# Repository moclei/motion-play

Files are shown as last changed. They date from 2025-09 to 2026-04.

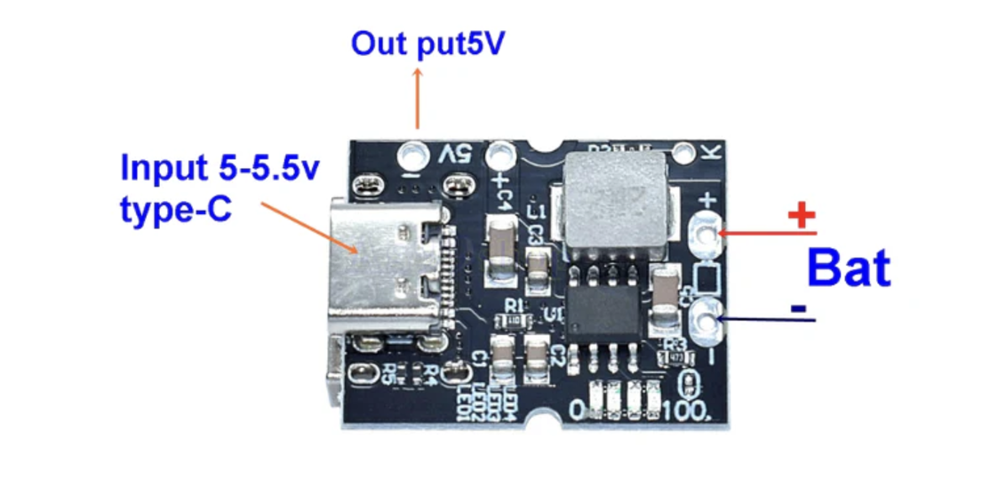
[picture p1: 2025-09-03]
hardware/components/dweii-power/product listing/Screenshot 2024-12-04 at 5.54.18 PM.png

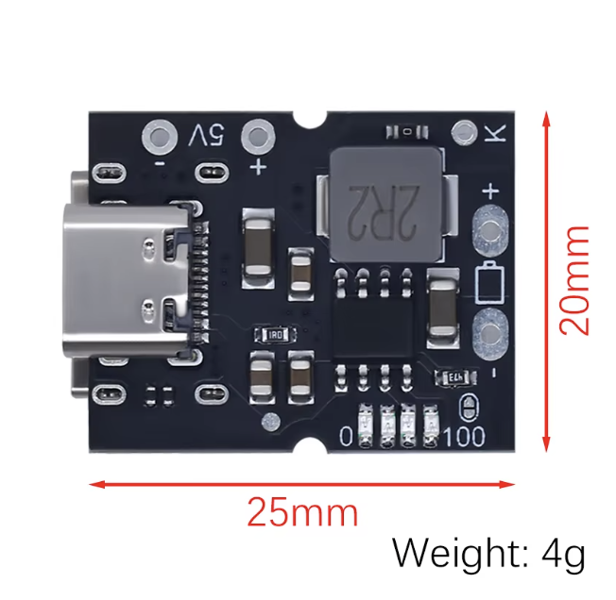
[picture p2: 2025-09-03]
hardware/components/dweii-power/product listing/Screenshot 2024-12-04 at 5.53.51 PM.png

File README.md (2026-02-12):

# Motion Play

ESP32-based sensor system for detecting and tracking fast-moving objects through a detection plane. Designed for games and sports performance training.

## Project Status

**Phase 4 - Integration & Polish** (77% complete)

- ✅ Custom PCBs with dual-MUX sensor architecture
- ✅ 1000 Hz data collection with PSRAM buffering
- ✅ AWS IoT Core + Lambda + DynamoDB backend
- ✅ React web interface with visualization and device control
- 🔄 Testing, optimization, documentation

## Repository Structure

```
motion-play/
├── .context/           # AI context documentation (start here)
│   ├── PROJECT.md      # Comprehensive project context
│   ├── manifest.yaml   # Structured metadata
│   └── IDEAS.md        # Feature backlog
├── firmware/           # ESP32-S3 firmware (PlatformIO/Arduino)
├── frontend/           # React web interface
├── lambda/             # AWS Lambda functions
├── infrastructure/     # AWS setup and deployment
├── hardware/           # KiCad PCB designs
│   ├── pcb-main/       # Main controller board
│   ├── sensor-rigid/   # Sensor rigid base (mux, connectors)
│   └── sensor-flex/    # Sensor flex strip (VCNL4040s)
└── docs/references/    # Hardware datasheets
```

## Quick Start

```bash
# Firmware
cd firmware && pio run -t upload

# Frontend
cd frontend/motion-play-ui && npm install && npm run dev
```

## Documentation

**For AI assistants and detailed context**: See [`.context/PROJECT.md`](.context/PROJECT.md)

**Hardware reference materials**: See [`docs/references/`](docs/references/)

## Hardware

- **MCU**: LilyGO T-Display-S3 (ESP32-S3)
- **Sensors**: 6× VCNL4040 proximity sensors (3 assemblies × 2 sensors)
- **Sensor Design**: Rigid+Flex hybrid PCBs (sensors on flex strip angle outward for better direction detection)
- **Architecture**: TCA9548A → PCA9546A → VCNL4040 (dual I2C multiplexing)

## License

[TBD]

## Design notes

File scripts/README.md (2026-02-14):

# Scripts

Utility scripts for the Motion Play project. Run all scripts from the project root.

## Device Provisioning

### `provision-device.sh`

Automates the full setup process for a new ESP32-S3 device. Walks you through each step interactively.

```bash
./scripts/provision-device.sh
```

**What it does:**
1. Creates an AWS IoT Thing for the device
2. Generates and activates X.509 certificates
3. Attaches the certificate to the Thing and the `MotionPlayDevicePolicy`
4. Downloads the Amazon Root CA (if not already present)
5. Fetches the IoT endpoint and generates `config.json` with your WiFi credentials
6. Backs up all secrets to AWS Secrets Manager
7. Uploads the filesystem (LittleFS) and firmware to the device

**Prerequisites:**
- AWS CLI configured (`aws configure`)
- PlatformIO CLI installed (`pio`)
- Device connected via USB for the flash step (DWEII power disconnected)

### `sync-secrets.sh`

Syncs device config and certificates to/from AWS Secrets Manager. Useful for backing up a new device's secrets or restoring them on a different machine.

```bash
./scripts/sync-secrets.sh up [device-number]     # Upload to Secrets Manager
./scripts/sync-secrets.sh down [device-number]    # Download from Secrets Manager
```

**Examples:**
```bash
./scripts/sync-secrets.sh up           # Back up device-001 (default)
./scripts/sync-secrets.sh up 002       # Back up device-002
./scripts/sync-secrets.sh down 002     # Restore device-002 secrets locally
```

Secrets are stored under the prefix `motion-play/device-{number}/` in AWS Secrets Manager.

## Monitoring & Debugging

### `monitor-mqtt.sh` / `monitor-mqtt.py`

Monitor MQTT messages to/from a device in real time. Useful for verifying device connectivity and inspecting data payloads.

### `add-iot-error-logging.sh`

Adds error logging rules to AWS IoT Core for debugging connection or message delivery issues.

## Data Analysis

### `analyze_session.py` / `analyze-session-data.sh`

Tools for analyzing sensor data from completed collection sessions. Used during development to inspect data quality and sensor behavior.

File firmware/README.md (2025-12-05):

# Motion Play Firmware

ESP32-S3 firmware for high-frequency sensor data collection and cloud transmission.

## Architecture Overview

### Dual-Core Design
- **Core 0:** Sensor data collection (1000 Hz) and buffering
- **Core 1:** MQTT communication, display updates, command processing

### Component Structure
```
firmware/src/
├── main.cpp                          # Application entry point, setup, loop
└── components/
    ├── data/                         # Data collection & transmission
    │   ├── DataTransmitter.h/cpp    # Batch MQTT transmission
    │   └── DataBuffer.h/cpp         # PSRAM-based ring buffer
    ├── sensor/                       # Sensor management
    │   ├── SensorManager.h/cpp      # Multi-sensor coordination
    │   ├── SensorConfiguration.h    # Sensor config structure
    │   └── VCNL4040Sensor.h/cpp     # VCNL4040 driver
    ├── mqtt/                         # Cloud communication
    │   └── MQTTManager.h/cpp        # AWS IoT Core client
    └── display/                      # Visual feedback
        └── DisplayManager.h/cpp     # T-Display-S3 interface
```

## Core Components

### `main.cpp`
**Purpose:** Application initialization and coordination

**Key Responsibilities:**
- WiFi connection setup
- MQTT client initialization
- Sensor manager setup
- Command routing (start_collection, stop_collection, set_mode, configure_sensors)
- Display updates

**Global State:**
- `SensorConfiguration currentConfig` - Current sensor settings
- `DataTransmitter* dataTransmitter` - Transmission handler
- `MQTTManager* mqttManager` - MQTT client
- `SensorManager* sensorManager` - Sensor coordinator

### `SensorManager` (sensor/)
**Purpose:** Coordinate multiple VCNL4040 sensors via dual-MUX architecture

**Architecture:**
```
T-Display-S3
    └── TCA9548A (Primary MUX, 0x70)
        ├── Channel 0 → PCA9546A (Secondary MUX, 0x71)
        │   ├── Channel 0 → VCNL4040 (0x60) - PCB 0, Side 1
        │   ├── Channel 1 → VCNL4040 (0x60) - PCB 1, Side 1
        │   └── Channel 2 → VCNL4040 (0x60) - PCB 2, Side 1
        └── Channel 1 → PCA9546A (Secondary MUX, 0x72)
            ├── Channel 0 → VCNL4040 (0x60) - PCB 0, Side 2
            ├── Channel 1 → VCNL4040 (0x60) - PCB 1, Side 2
            └── Channel 2 → VCNL4040 (0x60) - PCB 2, Side 2
```

**Key Methods:**
- `begin()` - Initialize all sensors
- `readAllSensors()` - Read all active sensors
- `calibrateSensors()` - Run calibration routine

**Data Structure:**
```cpp
struct SensorMetadata {
    uint8_t position;      // Sensor index (0-5)
    uint8_t pcb_id;        // PCB number (0-2)
    uint8_t side;          // Side (1 or 2)
    String name;           // Human-readable name
    bool active;           // Sensor active/present
};
```

### `DataTransmitter` (data/)
**Purpose:** Batch sensor readings and transmit via MQTT

**Key Features:**
- Batch transmission (100 readings per message)
- Session metadata included in first batch
- Sensor configuration tracking
- 16KB MQTT buffer support

**Key Methods:**
- `transmitSession()` - Send complete session with metadata
- `transmitBatch()` - Send batch of readings

**JSON Structure:**
```json
{
  "device_id": "motionplay-device-001",
  "session_id": "device-001_12345",
  "start_timestamp": "2025-11-14T10:30:00Z",
  "mode": "debug",
  "sample_rate": 1000,
  "active_sensors": [...],
  "vcnl4040_config": {
    "sample_rate_hz": 1000,
    "led_current": "200mA",
    "integration_time": "1T",
    "high_resolution": true
  },
  "readings": [...]
}
```

### `DataBuffer` (data/)
**Purpose:** PSRAM-based circular buffer for sensor readings

**Capacity:** 30,000+ samples
**Location:** PSRAM (external RAM on ESP32-S3)

**Key Methods:**
- `addReading()` - Add sensor reading
- `getReadings()` - Retrieve batch of readings
- `clear()` - Reset buffer

### `MQTTManager` (mqtt/)
**Purpose:** AWS IoT Core communication with TLS

**Key Features:**
- Certificate-based authentication
- LittleFS certificate storage
- Automatic reconnection
- Command subscription

**Topics:**
- Publish: `motionplay/data/{device_id}`
- Subscribe: `motionplay/commands/{device_id}`

**Key Methods:**
- `connect()` - Connect to AWS IoT Core
- `publish()` - Send message
- `setCallback()` - Register command handler
- `loop()` - Maintain connection

### `SensorConfiguration` (sensor/)
**Purpose:** Track sensor settings for ML training

**Structure:**
```cpp
struct SensorConfiguration {
    uint16_t sample_rate_hz;      // 100-1000 Hz
    String led_current;           // "50mA", "100mA", "200mA"
    String integration_time;      // "1T", "2T", "4T", "8T"
    bool high_resolution;         // 12-bit vs 16-bit
};
```

**Why This Exists:**
Different sensor configurations produce different data characteristics. For ML training, you need to know which settings were used for each dataset to properly normalize and group training data.

### `DisplayManager` (display/)
**Purpose:** T-Display-S3 TFT screen management

**Key Features:**
- Status display (WiFi, MQTT, collection state)
- Real-time sensor readings
- Mode indication (Debug/Play/Idle)

**Key Methods:**
- `showStatus()` - Display connection status
- `showSensorData()` - Display live readings
- `showMessage()` - Show temporary message

## Data Collection Flow

### Session Lifecycle

1. **Idle State**
   - Device connected to AWS IoT Core
   - Listening for commands
   - Display shows "Ready"

2. **Start Collection**
   - Command received: `start_collection`
   - Generate session ID: `{device_id}_{timestamp}`
   - Clear data buffer
   - Start high-frequency sampling (Core 0)
   - Display shows "Collecting..."

3. **Active Collection**
   - Core 0: Read all sensors at 1000 Hz
   - Store readings in PSRAM buffer
   - Core 1: Update display periodically
   - Continue until buffer full or stop command

4. **Stop Collection**
   - Command received: `stop_collection`
   - Stop sampling
   - Transmit all buffered data in batches
   - Include session metadata + sensor config
   - Clear buffer
   - Return to idle

### Command Processing

Commands are received via MQTT on `motionplay/commands/{device_id}`:

**`start_collection`**
```json
{
  "command": "start_collection"
}
```

**`stop_collection`**
```json
{
  "command": "stop_collection"
}
```

**`set_mode`**
```json
{
  "command": "set_mode",
  "mode": "debug"  // or "play", "idle"
}
```

**`configure_sensors`**
```json
{
  "command": "configure_sensors",
  "sensor_config": {
    "sample_rate_hz": 1000,
    "led_current": "200mA",
    "integration_time": "1T",
    "high_resolution": true
  }
}
```

## Configuration

### PlatformIO Configuration (`platformio.ini`)

```ini
[env:lilygo-t-display-s3]
platform = espressif32
board = lilygo-t-display-s3
framework = arduino

monitor_speed = 115200
upload_speed = 921600

board_build.arduino.memory_type = qio_opi
board_build.partitions = default_16MB.csv

lib_deps = 
    knolleary/PubSubClient @ ^2.8
    bblanchon/ArduinoJson @ ^6.21.3
    adafruit/Adafruit VCNL4040 @ ^2.0.3
```

### WiFi & Certificates

Certificates stored in LittleFS:
- `/ca.crt` - AWS IoT Root CA
- `/cert.crt` - Device certificate
- `/private.key` - Private key

**Note:** Certificates must be obtained from AWS IoT Core and uploaded to the device.

## Development Workflow

### Build & Upload
```bash
cd firmware/
pio run -t upload
```

### Monitor Serial Output
```bash
pio device monitor
```

### Clean Build
```bash
pio run -t clean
pio run -t upload
```

## Memory Management

### PSRAM Usage
- **Data Buffer:** ~30,000 samples in PSRAM
- **Benefit:** Offloads large buffers from internal SRAM
- **Access:** Slightly slower than SRAM but sufficient for buffering

### Task Priorities
- **Sensor Task (Core 0):** Priority 1 (highest)
- **MQTT Task (Core 1):** Priority 0 (normal)

## Adding New Components

### 1. Create Component Files
```bash
firmware/src/components/your_component/
├── YourComponent.h
└── YourComponent.cpp
```

### 2. Add to Build
PlatformIO automatically includes all `.cpp` files in `src/`.

### 3. Include in main.cpp
```cpp
#include "components/your_component/YourComponent.h"
```

### 4. Initialize in setup()
```cpp
void setup() {
    // ... existing setup ...
    yourComponent = new YourComponent();
    yourComponent->begin();
}
```

## Debugging Tips

### Check Serial Output
Most components log to Serial at 115200 baud. Look for:
- `[WiFi]` - Connection status
- `[MQTT]` - Cloud communication
- `[Sensor]` - Sensor readings
- `[Data]` - Transmission status

### Common Issues

**Sensors Not Found:**
- Check I2C connections
- Verify MUX addresses (0x70, 0x71, 0x72)
- Run I2C scanner

**MQTT Not Connecting:**
- Verify WiFi connection
- Check certificates in LittleFS
- Confirm AWS IoT endpoint in code

**Data Not Transmitting:**
- Check MQTT buffer size (16KB)
- Verify topic permissions in AWS IoT policy
- Monitor AWS IoT Core test client

**High Frequency Sampling Issues:**
- Ensure sensors on Core 0
- Check task priorities
- Verify PSRAM availability

## Key Constants

```cpp
#define SAMPLE_RATE_HZ 1000
#define BUFFER_SIZE 30000
#define MQTT_BUFFER_SIZE 16384
#define BATCH_SIZE 100
```

## Device Modes

- **Idle:** Minimal operation, ready for commands
- **Debug:** Full logging, 1000 Hz collection, detailed display
- **Play:** Optimized for game use, minimal logging, LED feedback

## Further Reading

- **Project Context:** [.context/PROJECT.md](../.context/PROJECT.md)
- **AWS Setup:** `infrastructure/aws-setup-guide.md`
- **Sensor Datasheets:** `docs/references/vcnl4040/`

---

*Last Updated: December 5, 2025*

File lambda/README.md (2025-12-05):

# Motion Play Lambda Functions

AWS Lambda functions for the Motion Play data collection system.

> **Project Context:** See [.context/PROJECT.md](../.context/PROJECT.md) for architecture overview.

## Functions Overview

1. **processData** - Process sensor data from ESP32 and store in DynamoDB
2. **processStatus** - Update device status information
3. **sendCommand** - Send commands to devices via IoT Core
4. **getSessions** - Retrieve list of sessions
5. **getSessionData** - Get detailed session data
6. **updateSession** - Update session metadata (labels, notes)
7. **deleteSession** - Delete sessions and associated data
8. **getDeviceConfig** - Get device sensor configuration
9. **updateDeviceConfig** - Update device sensor configuration

## Deployment

Each function should be deployed as a separate Lambda function with appropriate IAM permissions.

### Required IAM Permissions

- DynamoDB: PutItem, GetItem, Query, UpdateItem, DeleteItem
- IoT Core: Publish (for sendCommand function)
- CloudWatch Logs: CreateLogGroup, CreateLogStream, PutLogEvents

### Environment Variables

Each function may require:
- `SESSIONS_TABLE` - MotionPlaySessions table name
- `SENSOR_DATA_TABLE` - MotionPlaySensorData table name
- `DEVICES_TABLE` - MotionPlayDevices table name
- `REGION` - AWS region (e.g., us-west-2)

## Data Storage Architecture

### Composite Timestamp Key ⚠️ CRITICAL

**Problem Solved**: Multiple sensors reading simultaneously create duplicate DynamoDB keys.

**Solution**: Composite numeric key encoding both timestamp and sensor position.

#### Key Schema (MotionPlaySensorData table)
- **Partition Key**: `session_id` (String)
- **Sort Key**: `timestamp_offset` (Number) - **COMPOSITE KEY**

#### Composite Key Formula
```javascript
timestamp_offset = (timestamp_ms * 10) + position
```

**Example**:
- Sensor P1S1 (position=0) at 100ms: `1000` (100 × 10 + 0)
- Sensor P1S2 (position=1) at 100ms: `1001` (100 × 10 + 1)
- Sensor P2S1 (position=2) at 100ms: `1002` (100 × 10 + 2)

#### Decoding
```javascript
timestamp_ms = Math.floor(timestamp_offset / 10)
position = timestamp_offset % 10
```

**Why This Works**:
- All sensors can share the same timestamp (synchronized readings)
- Each reading still has a unique DynamoDB key
- Sort order is preserved (lower timestamps appear first)
- Position values 0-5 fit in the ones digit

**Where Implemented**:
- Encoding: `lambda/processData/index.js` (lines ~107-117)
- Decoding: `lambda/getSessionData/index.js` (lines ~63-78)

**⚠️ IMPORTANT**: If you ever need to query by timestamp, use the `timestamp_ms` attribute, NOT `timestamp_offset`!

## Development

Each function directory contains:
- `index.ts` or `index.js` - Main handler
- `package.json` - Dependencies
- `README.md` - Function-specific documentation

## Deployment Options

1. **Manual** - Zip and upload via AWS Console
2. **AWS CLI** - Use `aws lambda update-function-code`
3. **AWS CDK** - Infrastructure as code (recommended for Phase 2)
4. **Serverless Framework** - Alternative deployment tool

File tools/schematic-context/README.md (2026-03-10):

# Schematic Context Tools

Python scripts that extract circuit data from KiCad schematics and produce AI-optimized `circuit-context.json` files. These replace the old JSON netlist + YAML annotation system.

## Prerequisites

- **Python 3.7+** (tested on 3.7.3)
- **KiCad 9** — `kicad-cli` must be available (macOS default: `/Applications/KiCad/KiCad.app/Contents/MacOS/kicad-cli`)
- **Dependencies:** `pip install -r requirements.txt` (kiutils >= 1.4.8)

Override the kicad-cli path with the `KICAD_CLI` environment variable if needed.

## Scripts

### extract.py

Main extraction pipeline. Combines `kicad-cli` netlist export (for connectivity) with `kiutils` schematic parsing (for component properties and hierarchy) to produce `circuit-context.json`.

```bash
# Basic extraction — outputs circuit-context.json next to the schematic
python tools/schematic-context/extract.py hardware/pcb-main/kicad/motion-play-main.kicad_sch

# Custom output path
python tools/schematic-context/extract.py hardware/pcb-main/kicad/motion-play-main.kicad_sch \
  --output path/to/circuit-context.json

# Re-extract with annotation merge — carries forward net/block annotations from a previous run
python tools/schematic-context/extract.py hardware/pcb-main/kicad/motion-play-main.kicad_sch \
  --previous hardware/pcb-main/kicad/circuit-context.json
```

The `--previous` flag is important: component annotations live in the `.kicad_sch` files (as `ai_` properties) and come through automatically, but net annotations and block definitions only exist in `circuit-context.json`. The merge preserves them across re-extractions.

### annotate.py

Writes `ai_`-prefixed custom properties to component symbols in `.kicad_sch` files via kiutils. Properties are hidden in the schematic editor and survive schematic edits.

```bash
# Annotate a single component
python tools/schematic-context/annotate.py hardware/pcb-main/kicad/motion-play-main.kicad_sch \
  U1 function="3.3V LDO regulator" block=power role=voltage_regulator

# Annotate multiple components with the same properties (use -- separator)
python tools/schematic-context/annotate.py hardware/pcb-main/kicad/motion-play-main.kicad_sch \
  R28 R29 -- role=pull_up block=i2c_mux

# Clear all ai_ properties from a component
python tools/schematic-context/annotate.py hardware/pcb-main/kicad/motion-play-main.kicad_sch \
  C1 --clear
```

Valid annotation fields: `function`, `block`, `role`, `critical_specs`.

The script resolves which `.kicad_sch` file a component lives on (root or child sheet) automatically.

### show.py

Displays annotation coverage across all components. Useful during interactive annotation sessions to track progress.

```bash
# Show all components with annotation status
python tools/schematic-context/show.py hardware/pcb-main/kicad/motion-play-main.kicad_sch

# Show only unannotated components
python tools/schematic-context/show.py hardware/pcb-main/kicad/motion-play-main.kicad_sch --unannotated

# Filter to a specific sheet
python tools/schematic-context/show.py hardware/pcb-main/kicad/motion-play-main.kicad_sch \
  --sheet led_controller
```

## Typical Workflow

1. **Edit schematic** in KiCad
2. **Extract** — run `extract.py` with `--previous` to produce an updated `circuit-context.json`
3. **Check coverage** — run `show.py --unannotated` to find new components needing annotation
4. **Annotate** — interactive session: AI proposes annotations, human confirms, write via `annotate.py`
5. **Re-extract** — run `extract.py --previous` again to merge everything into the final context file

## Output Location

| PCB | Context File |
|-----|---|
| Main PCB | `hardware/pcb-main/kicad/circuit-context.json` |
| Sensor Rigid | `hardware/sensor-rigid/circuit-context.json` |
| Sensor Flex | `hardware/sensor-flex/circuit-context.json` |

## Design Details

See `docs/initiatives/schematic-context/PLAN.md` for the full design rationale, context file schema, and annotation storage decisions.

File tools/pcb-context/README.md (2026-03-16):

# PCB Context Tools

Scripts for extracting structured data from KiCad PCB files and automating component placement. Both tools use [kiutils](https://pypi.org/project/kiutils/) (v1.4.8+) to parse and write `.kicad_pcb` files.

## Workflow

```
User positions anchor components in KiCad, saves
    ↓
python extract.py <pcb> --pads       → pcb-layout-context.json (enriched)
    ↓
python place_power.py <pcb> --dry-run → review proposed positions
    ↓
python place_power.py <pcb>           → writes positions to .kicad_pcb
    ↓
User opens KiCad, reviews placement, runs DRC
```

KiCad must be closed before running `place_power.py` without `--dry-run` — both tools write to the same `.kicad_pcb` file.

## extract.py

Parses a `.kicad_pcb` file and produces `pcb-layout-context.json` — a structured snapshot of board outline, component positions, bounding boxes, and optionally per-component pad data. Used by `place_power.py` and by AI-assisted layout sessions.

```
python extract.py <file.kicad_pcb> [options]
```

| Flag | Description |
|---|---|
| `--pads` | Include per-component pad data: pad number, global x/y, size, net name, shape. Required before running `place_power.py`. |
| `--output PATH`, `-o` | Output path for the JSON file. Default: `pcb-layout-context.json` alongside the PCB. |
| `--schematic-context PATH` | Path to `circuit-context.json` for cross-referencing unplaced components. Auto-detected if present alongside the PCB. |

### Examples

```bash
# Basic extraction
python extract.py hardware/pcb-main/kicad/motion-play-main.kicad_pcb

# With pad data (needed for placement)
python extract.py hardware/pcb-main/kicad/motion-play-main.kicad_pcb --pads

# Custom output path
python extract.py hardware/pcb-main/kicad/motion-play-main.kicad_pcb --pads -o /tmp/context.json
```

### Output format

The JSON includes `board_outline`, `placed_components` (with optional `pads` array), `unplaced_components`, and a `summary` with component counts and board utilization percentage.

## place_power.py

Reads the enriched `pcb-layout-context.json` and `tools/schematic-gen/spec.json`, then computes collision-free positions for power section support components relative to manually-placed anchor ICs (U5, U6, J7, J8, L1, R44).

```
python place_power.py <file.kicad_pcb> [options]
```

| Flag | Description |
|---|---|
| `--dry-run` | Output proposed positions as JSON to stdout without modifying the PCB. Always run this first to review. |
| `--context PATH` | Path to `pcb-layout-context.json`. Default: alongside the PCB file. |
| `--spec PATH` | Path to `spec.json`. Default: `tools/schematic-gen/spec.json`. |

### Examples

```bash
# Preview placement without writing
python place_power.py hardware/pcb-main/kicad/motion-play-main.kicad_pcb --dry-run

# Apply placement (KiCad must be closed)
python place_power.py hardware/pcb-main/kicad/motion-play-main.kicad_pcb

# Custom input paths
python place_power.py hardware/pcb-main/kicad/motion-play-main.kicad_pcb \
    --context /tmp/context.json \
    --spec path/to/spec.json \
    --dry-run
```

### How placement works

**Anchors** (U5, U6, J7, J8, L1, R44) keep their manually-set positions. Everything else in the power section is repositioned.

Components are placed in four tiers based on electrical proximity requirements:

| Tier | Constraint | Purpose | Example components |
|---|---|---|---|
| 1 — Critical | <3mm from pins | Switching loop minimization | L2, C23, C32 |
| 2 — Important | <5–6mm from pins | Bulk decoupling | C20, C21, C34–C36, C25, C26 |
| 3 — Moderate | <10mm from pins | Signal integrity | R39, R40, R43, C24, C27, F2, U7 |
| 4 — Flexible | <15–20mm | Large passives, bias networks | C29, C22, R33, TH1, TP1–TP4 |

For each component, the script finds the target anchor pad via net name matching against `spec.json`, then searches in expanding rings for the closest collision-free position, preferring the direction away from the anchor IC center.

**U6 rotation fix:** U6 is rotated from -90° to +90° so its SW pins face the board interior, making room for L2.

**Test points** (TP1–TP4) are placed along the bottom board edge for probe access.

If a component can't be placed within its tier distance, the constraint is relaxed (doubled distance, full board width). Failures and relaxations are reported as warnings.

### Output

- **`--dry-run`**: prints a JSON report to stdout with `placements` (new and old positions), `warnings`, and `summary`.
- **Normal mode**: writes positions to the `.kicad_pcb` file and saves a `placement-report.json` alongside the PCB.

## Dependencies

- Python 3.7+
- kiutils ≥ 1.4.8 (`pip install kiutils`)

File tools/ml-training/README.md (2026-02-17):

# ML Training Pipeline

Training pipeline for the Motion Play ML-based direction detection model.

## Overview

This pipeline downloads labeled sensor data from the Motion Play cloud, preprocesses it into training tensors, trains a small 1D CNN, quantizes it to int8, and exports it as a C header file for embedding in the ESP32-S3 firmware.

## Setup

```bash
cd tools/ml-training
python -m venv venv
source venv/bin/activate
pip install -r requirements.txt
```

## Pipeline Steps

1. **Download data** — Fetch labeled `live_debug` sessions from the REST API
2. **Preprocess** — Extract fixed-size `(300, 6)` matrices (300ms window, 6 proximity channels), normalize, assign labels
3. **Train** — Train a 1D CNN model using TensorFlow/Keras
4. **Evaluate** — Accuracy, confusion matrix, per-scenario analysis
5. **Export** — Quantize to int8 TFLite, convert to C header for firmware

## Model Architecture

```
Input: (300, 6) — 300 timesteps at 1kHz, 6 sensor channels (proximity only)
  → Conv1D(16, kernel_size=5, ReLU)
  → MaxPool1D(2)
  → Conv1D(32, kernel_size=3, ReLU)
  → MaxPool1D(2)
  → Flatten
  → Dense(32, ReLU)
  → Dense(3, Softmax)   # A_TO_B, B_TO_A, NO_TRANSIT
```

## Output Classes

| Class | Label | Description |
|---|---|---|
| 0 | A_TO_B | Object passed from back to front of hoop |
| 1 | B_TO_A | Object passed from front to back of hoop |
| 2 | NO_TRANSIT | No valid transit (noise, partial, ambient) |

## Data Format

Each training sample is derived from a Live Debug session:
- **Input**: 300×6 matrix of uint16 proximity values, normalized to [0, 1]
- **Label**: Direction from session metadata + user labeling
- **Source**: DynamoDB via REST API (`GET /sessions/{id}/data`)

## Exporting for Firmware

After training and quantization:

```bash
# Convert .tflite to C header
xxd -i model.tflite > model_data.h
```

The header file goes into `firmware/src/components/detection/` and is included by `MLDetector`.

## See Also

- Initiative docs: `docs/initiatives/ml-direction-detection/`
- Current heuristic: `firmware/src/components/detection/DirectionDetector.cpp`
- Sensor data format: `SensorReading` struct in `firmware/src/components/sensor/SensorManager.h`

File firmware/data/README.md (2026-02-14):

# Firmware Data Directory

This directory contains configuration files and certificates for the ESP32-S3 device. These files are uploaded to the device's LittleFS filesystem partition and read by the firmware at runtime.

## Files

### Certificates (Not Committed)

AWS IoT Core certificates for TLS authentication:
- `certs/device-cert.pem` - Device certificate
- `certs/private-key.pem` - Private key
- `certs/root-ca.pem` - Amazon Root CA

### Configuration

- `config.json` - Device configuration (not committed, copy from `config.json.example`)
- `config.json.example` - Template showing the expected structure

## Setup — New Device

**Recommended:** Use the provisioning script, which handles everything automatically (AWS IoT Thing creation, certificates, config, filesystem upload, and firmware upload):

```bash
./scripts/provision-device.sh
```

See [`scripts/README.md`](../../scripts/README.md) for details.

### Manual Setup

If you prefer to set things up manually:

1. Copy `config.json.example` to `config.json`
2. Update `config.json` with your WiFi credentials, device ID, and AWS IoT endpoint
3. Place your AWS IoT certificates in the `certs/` directory
4. Upload filesystem to ESP32 using PlatformIO:
   ```bash
   pio run --target uploadfs
   ```
5. Upload firmware:
   ```bash
   pio run --target upload
   ```

## Restoring Secrets

If you need to restore a device's config and certs from AWS Secrets Manager:

```bash
./scripts/sync-secrets.sh down 002   # Downloads device-002's secrets
```

## Security Note

**NEVER commit certificate files or actual config.json to git!**
These files contain sensitive credentials and are automatically ignored by `.gitignore`.

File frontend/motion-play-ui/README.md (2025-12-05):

# Motion Play Web Interface

React-based web interface for device control, data visualization, and session management.

## Tech Stack

- **Framework:** React 18 with TypeScript
- **Build Tool:** Vite
- **Styling:** Tailwind CSS v3
- **Charts:** Recharts
- **HTTP Client:** Axios
- **Icons:** Lucide React
- **Date Formatting:** date-fns

## Architecture Overview

```
frontend/motion-play-ui/src/
├── App.tsx                    # Main application & routing
├── index.css                  # Global styles (Tailwind)
├── main.tsx                   # Application entry point
├── components/                # React components
│   ├── SessionList.tsx       # Session list with filtering
│   ├── SessionChart.tsx      # Data visualization
│   ├── DeviceControl.tsx     # Start/stop collection
│   ├── LabelEditor.tsx       # Session labels & notes
│   ├── ExportButton.tsx      # JSON/CSV export
│   ├── ModeSelector.tsx      # Device mode selection
│   ├── SensorConfig.tsx      # Live sensor configuration
│   └── SessionConfig.tsx     # Historical config display
└── services/
    └── api.ts                 # API client (Axios)
```

## Components

### Core Components (Phase 3)

#### `App.tsx`
**Purpose:** Main application container and state coordinator

**State Management:**
- `selectedSession` - Currently viewed session
- `sessionData` - Full session data with readings
- `sessionListRef` - Reference to SessionList for refresh

**Key Functions:**
- `handleSessionSelect()` - Load and display session details
- `handleDeleteSession()` - Delete session with confirmation
- `handleCollectionStopped()` - Refresh list after collection

**Layout:**
- Left column: Device control + session list
- Right column: Session detail + chart

#### `SessionList.tsx`
**Purpose:** Display and filter recorded sessions

**Props:**
```typescript
interface SessionListProps {
    onSessionSelect: (session: Session) => void;
    selectedId?: string;
}
```

**Features:**
- Real-time session loading
- Search by session ID, labels, notes
- Filter by mode (all/idle/debug/play)
- Visual selection highlighting
- Results counter
- Exposed `refresh()` method via `useImperativeHandle`

**Display:**
- Session ID (monospace)
- Duration, sample count, sample rate
- Labels (if present)
- Mode badge

#### `SessionChart.tsx`
**Purpose:** Interactive time-series visualization with statistics and data analysis tools

**Props:**
```typescript
interface SessionChartProps {
    readings: Reading[];
}
```

**Features:**
- Multi-sensor line chart with color coding:
  - Side 1: Dark green, Side 2: Dark blue
  - Line styles vary by PCB (solid/dashed/dotted)
- PCB and side filtering (show specific sensors or all)
- **Time window zooming** with interactive brush component
- **Data processing filters** for analysis and ML prep:
  - Moving average smoothing (3-21 sample window)
  - Baseline removal (subtract minimum value)
  - Peak threshold filter (0-20 range)
- Real-time statistics:
  - Average proximity (overall + per side + per sensor)
  - Max/Min proximity
  - Sample counts per side and per sensor
- Handles empty/invalid data gracefully

**Chart Details:**
- X-axis: Time offset (ms)
- Y-axis: Proximity value
- Tooltip: Shows exact values on hover
- Brush timeline: Drag handles to zoom into specific time windows
- `connectNulls` for smooth lines

**Data Analysis:**
The processing filters are designed for:
- Noise reduction (smoothing)
- Normalizing sensors with different baselines (baseline removal)
- Isolating detection events (threshold filter)
- Preparing data for ML model training

#### `DeviceControl.tsx`
**Purpose:** Start/stop data collection

**Props:**
```typescript
interface DeviceControlProps {
    onCollectionStopped?: () => void;
}
```

**Features:**
- Start/stop buttons with loading states
- Visual feedback on success/error
- Calls parent callback when collection stops

**Commands Sent:**
- `start_collection`
- `stop_collection`

### Enhancement Components (Phase 3-B)

#### `LabelEditor.tsx`
**Purpose:** Add labels and notes to sessions

**Props:**
```typescript
interface LabelEditorProps {
    session: Session;
    onUpdate: (session: Session) => void;
}
```

**Features:**
- Add/remove labels (tags)
- Predefined label suggestions:
  - `successful-shot`, `miss`, `practice`
  - `baseline`, `experiment`, `calibration`
  - `fast`, `slow`, `normal`
- Free-text notes field
- Save to backend (PUT request)

**UI Elements:**
- Tag chips with X to remove
- Input field for new labels
- Suggestion buttons
- Notes textarea

#### `ExportButton.tsx`
**Purpose:** Export session data for ML training

**Props:**
```typescript
interface ExportButtonProps {
    sessionData: SessionData;
}
```

**Features:**
- Export as JSON (complete data structure)
- Export as CSV (tabular format)
- Proper filename generation: `session_{id}.json`
- Download triggers automatically

**CSV Format:**
```csv
timestamp_offset,sensor_pcb,sensor_side,proximity,ambient,timestamp
0,0,1,1234,567,2025-11-14T10:30:00Z
1,0,2,1235,568,2025-11-14T10:30:00Z
...
```

#### `ModeSelector.tsx`
**Purpose:** Switch device operating mode

**Props:**
```typescript
interface ModeSelectorProps {
    deviceId?: string;
}
```

**Modes:**
- **Idle:** Minimal operation, ready for commands
- **Debug:** Full logging, detailed display
- **Play:** Game mode, LED feedback

**Features:**
- Visual indication of active mode
- Sends `set_mode` command
- Success/error feedback

#### `SensorConfig.tsx`
**Purpose:** Configure live sensor settings (control panel)

**Props:**
```typescript
interface SensorConfigProps {
    deviceId?: string;
}
```

**Configurable Settings:**
- Sample rate: 100/250/500/1000 Hz
- LED current: 50/75/100/150/200 mA
- Integration time: 1T/2T/4T/8T
- High resolution: true/false (12-bit vs 16-bit)

**Features:**
- Dropdown selectors
- Apply button sends `configure_sensors` command
- Visual feedback on success

**Important:** This configures FUTURE collections. Past sessions retain their original config.

#### `SessionConfig.tsx`
**Purpose:** Display historical sensor configuration (read-only)

**Props:**
```typescript
interface SessionConfigProps {
    sessionData: SessionData;
}
```

**Displays:**
- Sample rate used for this session
- LED current setting
- Integration time
- High resolution mode
- Number of active sensors

**Why This Matters:** For ML training, you need to know what settings were used for each dataset.

## Services

### `api.ts`
**Purpose:** Centralized API client for backend communication

**Base Configuration:**
```typescript
const API_ENDPOINT = import.meta.env.VITE_API_ENDPOINT;
const DEVICE_ID = import.meta.env.VITE_DEVICE_ID;
```

**Methods:**

#### Session Management
```typescript
getSessions(): Promise<Session[]>
getSessionData(sessionId: string): Promise<SessionData>
deleteSession(sessionId: string): Promise<any>
updateSession(sessionId: string, updates: UpdateData): Promise<void>
```

#### Device Control
```typescript
sendCommand(command: string, params?: Record<string, any>): Promise<void>
```

**Commands:**
- `start_collection`
- `stop_collection`
- `set_mode` (with `mode` param)
- `configure_sensors` (with `sensor_config` param)

#### API Endpoints Used:
- `GET /sessions` - List all sessions
- `GET /sessions/{session_id}` - Get session details
- `DELETE /sessions/{session_id}` - Delete session
- `PUT /sessions/{session_id}` - Update labels/notes
- `POST /device/command` - Send device command

## TypeScript Interfaces

### Core Types

```typescript
interface Session {
    session_id: string;
    device_id: string;
    start_timestamp: string;
    duration_ms: number;
    sample_count: number;
    sample_rate: number;
    mode: string;
    labels?: string[];
    notes?: string;
    created_at: number;
    active_sensors?: ActiveSensor[];
    vcnl4040_config?: VCNL4040Config;
}

interface SessionData {
    session: Session;
    readings: Reading[];
}

interface Reading {
    timestamp_offset: number;
    sensor_pcb: number;
    sensor_side: number;
    proximity: number;
    ambient: number;
    timestamp: string;
}

interface VCNL4040Config {
    sample_rate_hz: number;
    led_current: string;
    integration_time: string;
    high_resolution: boolean;
}

interface ActiveSensor {
    pos: number;
    pcb: number;
    side: number;
    name: string;
    active: boolean;
}
```

## Environment Variables

Create `.env` in the project root:

```env
VITE_API_ENDPOINT=https://your-api-gateway-id.execute-api.us-west-2.amazonaws.com/prod
VITE_AWS_REGION=us-west-2
VITE_DEVICE_ID=motionplay-device-001
```

**Access in code:**
```typescript
import.meta.env.VITE_API_ENDPOINT
```

## Development Workflow

### Install Dependencies
```bash
cd frontend/motion-play-ui/
npm install
```

### Start Dev Server
```bash
npm run dev
```
Opens at `http://localhost:5173`

### Build for Production
```bash
npm run build
```
Output in `dist/` directory

### Preview Production Build
```bash
npm run preview
```

### Lint Code
```bash
npm run lint
```

## Project Configuration

### `vite.config.ts`
```typescript
export default defineConfig({
  plugins: [react()],
  server: {
    port: 5173,
    open: true
  }
})
```

### `tailwind.config.js`
```javascript
export default {
  content: [
    "./index.html",
    "./src/**/*.{js,ts,jsx,tsx}",
  ],
  theme: {
    extend: {},
  },
  plugins: [],
}
```

### `tsconfig.json`
Standard React + TypeScript configuration with strict mode enabled.

## Styling Approach

### Tailwind CSS Classes
Most styling uses Tailwind utility classes:

```tsx
<div className="bg-white rounded-lg shadow p-4 mb-4">
  <h3 className="text-lg font-semibold text-gray-800 mb-2">
    Title
  </h3>
</div>
```

### Common Patterns

**Cards:**
```tsx
className="bg-white rounded-lg shadow p-4"
```

**Buttons:**
```tsx
className="bg-blue-500 text-white px-4 py-2 rounded hover:bg-blue-600"
```

**Input Fields:**
```tsx
className="border border-gray-300 rounded px-3 py-2 w-full"
```

**Badges:**
```tsx
className="inline-block bg-blue-100 text-blue-800 text-xs px-2 py-1 rounded"
```

## State Management

### Local State (useState)
Used for component-specific state:
- Form inputs
- Loading states
- Local UI toggles

### Refs (useRef)
Used for:
- Accessing child methods (`sessionListRef.current.refresh()`)
- Avoiding re-renders for non-visual state

### Props
Used for:
- Parent-child communication
- Callback functions
- Data passing

**No global state library** (Redux, Zustand, etc.) - Not needed for current complexity.

## Adding New Components

### 1. Create Component File
```bash
touch src/components/MyComponent.tsx
```

### 2. Component Template
```tsx
import { useState } from 'react';

interface MyComponentProps {
    data: string;
    onAction: () => void;
}

export const MyComponent: React.FC<MyComponentProps> = ({ data, onAction }) => {
    const [localState, setLocalState] = useState('');

    return (
        <div className="bg-white rounded-lg shadow p-4">
            <h3 className="text-lg font-semibold mb-2">My Component</h3>
            {/* Component content */}
        </div>
    );
};
```

### 3. Import in App.tsx
```tsx
import { MyComponent } from './components/MyComponent';
```

### 4. Use in App.tsx
```tsx
<MyComponent data="example" onAction={handleAction} />
```

## Common Tasks

### Refresh Session List After Action
```typescript
// In App.tsx
const sessionListRef = useRef<{ refresh: () => void }>(null);

// Call after action
sessionListRef.current?.refresh();
```

### Add New API Endpoint
```typescript
// In api.ts
async myNewEndpoint(): Promise<ResponseType> {
    const response = await axios.get(`${this.baseUrl}/my-endpoint`);
    return response.data;
}
```

### Handle Loading States
```typescript
const [loading, setLoading] = useState(false);

const handleAction = async () => {
    setLoading(true);
    try {
        await api.someAction();
        alert('Success!');
    } catch (error) {
        console.error('Error:', error);
        alert('Failed!');
    } finally {
        setLoading(false);
    }
};
```

## Debugging Tips

### Check Browser Console
- Network tab: See API requests/responses
- Console tab: See `console.log()` output and errors
- React DevTools: Inspect component state

### Common Issues

**API Requests Failing:**
- Check `.env` file exists and has correct API endpoint
- Verify CORS configuration on API Gateway
- Check browser network tab for exact error

**Environment Variables Not Loading:**
- Restart dev server after changing `.env`
- Variables must start with `VITE_`
- Access via `import.meta.env.VITE_*`

**Tailwind Classes Not Working:**
- Check `tailwind.config.js` includes your file
- Verify `@tailwind` directives in `index.css`
- Restart dev server

**TypeScript Errors:**
- Check interface definitions match API responses
- Use `any` temporarily, then narrow down types
- Run `npm run build` to see all type errors

## Performance Considerations

### Chart Rendering
- `SessionChart` filters data before rendering
- Recharts handles 1000+ points efficiently
- Use `connectNulls` for smoother lines

### Session List
- Only loads metadata initially
- Full readings loaded on-demand
- Filtering happens client-side (fast)

### API Calls
- No caching (always fresh data)
- Consider adding React Query for optimization later

## Testing

Currently no automated tests. For manual testing:

1. **Session List:**
   - Load sessions
   - Filter by mode
   - Search by ID/labels/notes
   - Select session

2. **Session Detail:**
   - View chart
   - Toggle side filtering
   - Check statistics
   - Add labels/notes

3. **Device Control:**
   - Start collection
   - Stop collection
   - Verify list refreshes

4. **Export:**
   - Download JSON
   - Download CSV
   - Verify file contents

5. **Configuration:**
   - Change sensor settings
   - Change mode
   - Verify commands sent

## Further Reading

- **Project Context:** [.context/PROJECT.md](../../../.context/PROJECT.md)
- **Vite Docs:** https://vitejs.dev/
- **React Docs:** https://react.dev/
- **Tailwind Docs:** https://tailwindcss.com/

---

*Last Updated: December 5, 2025*

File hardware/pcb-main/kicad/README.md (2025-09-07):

# motion-play-main
Main PCB for Motion Play project

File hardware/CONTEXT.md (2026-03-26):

# Hardware Context

Custom PCB designs for the Motion Play sensor system. Three PCB types make up the electronics: one main board and a two-part sensor assembly (rigid base + flex strip) replicated three times around the hoop.

## Physical Architecture

- **Hoop diameter:** 500mm (transparent polypropylene tubing, 19mm diameter)
- **Orientation:** Vertical plane (opening faces horizontally)
- **Main enclosure:** 85mm × 45mm × 15mm at 6 o'clock position

### Sensor Placement

3 sensor assemblies positioned at:
- Position 1 (M1): 6 o'clock (bottom, co-located with main enclosure)
- Position 2 (M2): 9 o'clock (left side)
- Position 3 (M3): 3 o'clock (right side)

Each assembly has dual sensors with ~2° angular offset:
- **Side A** (-2°): Faces the back of the hoop
- **Side B** (+2°): Faces the front of the hoop

The angle increases the detection time window for direction discrimination. Object passing through triggers sequential sensor activation — direction is determined by A→B vs B→A trigger sequence. 120° spacing provides full coverage.

See [`docs/detection-algorithm.md`](../docs/detection-algorithm.md) for the full algorithm design and transit scenario catalog.

## Custom PCBs

### 1. Main PCB (`hardware/pcb-main/`)

Houses the system controller and power management:

- **T-Display-S3** (ESP32-S3 development board) — The MCU with a built-in LCD screen. Long-term goal is to incorporate a bare ESP32-S3 directly into the main PCB.
- **TCA9548A** I2C multiplexer — Organizes I2C communication with sensor PCBs. 3 channels used. Speed is critical for high-frequency sensing.
- **AP2112K-3.3** voltage regulator — Provides 3.3V to sensors.
- **DWEII USB-C power module** — Development power module providing 5V @ ~2.4A with battery charging. Will be replaced with a custom solution eventually.
- **SN74AHCT125** logic level shifter — Between MCU (3.3V) and WS2818B LED strip (5V). 72 LEDs, 1.2m strip.
- **3× JST-SH 4-pin connectors** (SM04B-SRSS-TB) — One per sensor PCB (Pin 1 = 3.3V, Pin 2 = GND, Pin 3 = SDA, Pin 4 = SCL)

### 2. Sensor Rigid Base (`hardware/sensor-rigid/`)

The mounting board with local I2C multiplexing:

| Ref | Component | Function |
|-----|---|---|
| U1 | PCA9546A | Local I2C mux (controls two sensors) |
| J1 | JST-SH 4-pin (SM04B-SRSS-TB) | Connector to main board (3.3V, GND, SDA, SCL) |
| FPC1 | C132510 ZIF | Connection to flex sensor strip |
| R1, R2 | 4.7kΩ | Upstream I2C pull-ups |
| R6-R9 | 4.7kΩ | Per-sensor downstream I2C pull-ups |
| R3 | 10kΩ | Reset pull-up (keeps PCA9546A active) |
| R12 | 10kΩ | A2 address pull-up (permanently high) |
| R13, R14 | 10kΩ | A0, A1 address pull-downs (default low) |
| SW1 | EP-02KS DIP switch | I2C address select (A0, A1) |
| D1, R4 | LED + 1kΩ | Power indicator |
| C1, C2 | 2.2µF, 0.1µF | Power bypass caps |
| TP1-TP4 | Test pads | 3.3V, GND, SDA_UP, SCL_UP |

- **PCB Type**: Standard rigid FR4, 4 layers, 1.6mm thickness, HASL or ENIG finish.
- **I2C Addressing (PCA9546A):** A2 permanently high. Address set via SW1 DIP switch:
  - Board 1 (both OFF): 0x74
  - Board 2 (SW2 ON): 0x75
  - Board 3 (SW1 ON): 0x76

### 3. Flex Sensor Strip (`hardware/sensor-flex/`)

Polyimide flex PCB that bends to angle sensors outward:

- **PCB Type**: 2-layer polyimide flex, ~0.11mm core, ENIG finish
- ~25mm × 8mm, sensors 10mm apart center-to-center
- ~5mm center bend zone (unstiffened, flexible)
- **Stiffeners** (all on bottom side):
  - FPC tail: Polyimide (PI), 0.25mm (total ~0.3mm for ZIF connector grip)
  - IC1 area: Stainless Steel (SS), 0.2mm
  - IC2 area: Stainless Steel (SS), 0.2mm

| Ref | Component | Function |
|-----|---|---|
| IC1, IC2 | VCNL4040M3OE | Proximity sensors |
| C4, C8 | 2.2µF | LED anode capacitors |
| C6, C7 | 0.1µF | VDD bypass capacitors |
| R10, R11 | 22Ω | VDD series filter resistors (one per sensor) |
| FPC1 | FPC_Tail_10P | FPC tail connector (mates with ZIF on rigid base) |

Connected to rigid base via ZIF FPC connector (C132510, 1.0mm pitch, top contact, slide lock, 0.3mm FPC):

**ZIF Connector Pinout:**

| Pin | Signal | Purpose |
|-----|---|---|
| 1 | 3.3V | Power |
| 2 | GND | Ground |
| 3 | SCL1 | I2C clock sensor 1 |
| 4 | SDA1 | I2C data sensor 1 |
| 5 | GND | Ground (shield between sensor groups) |
| 6 | SCL2 | I2C clock sensor 2 |
| 7 | SDA2 | I2C data sensor 2 |
| 8 | GND | Ground |
| 9 | GND | Mechanical mounting |
| 10 | GND | Mechanical mounting |

**Why the split design?** The flex PCB allows sensors to be angled ~2° away from each other, increasing the time window between sequential sensor triggers and improving direction discrimination.

### Flex PCB Design Notes
1. Center ~5mm bend zone is unstiffened
2. 0.25mm traces in bend zone (wider than normal), curved paths, no vias
3. Traces perpendicular to bend axis for durability
4. Components only on stiffened areas

See `docs/initiatives/flex-sensor-pcb/DESIGN_PLAN.md` for detailed design rationale.
See `hardware/sensor-flex/FLEX_PCB_SETUP.md` for flex PCB manufacturing notes.

## Component Nicknames

| Component | Part Number | Function | Shorthand |
|---|---|---|---|
| Main Controller | LilyGO T-Display-S3 | ESP32-S3 with built-in display | `tdisplay` |
| I2C Multiplexer | TCA9548A | 8-channel I2C switch (main board) | `tca` |
| Local I2C Multiplexer | PCA9546A | I2C switch (sensor board) | `pca` |
| Sensors | VCNL4040 | Proximity & ambient light sensing | `sensors` |
| Voltage Regulator | AP2112K-3.3 | 3.3V regulator | `apk` |
| Power Module | DWEII USB-C | USB-C power input | `dweii` or `power module` |

## Schematic Context System

Raw KiCad schematic files are difficult for AI assistants to interpret. The **schematic context system** extracts circuit data and combines it with human-confirmed semantic annotations into a single `circuit-context.json` file per PCB project.

**Always use `circuit-context.json`** instead of `.kicad_sch` files when reasoning about hardware designs.

### File Locations

| PCB | Context File | Status |
|-----|---|---|
| Main PCB | `hardware/pcb-main/kicad/circuit-context.json` | Complete — 37 components, 26 nets, 5 functional blocks |
| Sensor Rigid Base | `hardware/sensor-rigid/circuit-context.json` | Complete — 22 components, 13 nets, 5 functional blocks |
| Sensor Flex Strip | `hardware/sensor-flex/circuit-context.json` | Complete — 9 components, 10 nets, 4 functional blocks |
| Power Supply | `hardware/pcb-power-supply/kicad/circuit-context.json` | Complete — 50 components, 29 nets, 4 functional blocks |

### What's in circuit-context.json

- **Components** — every part with value, footprint, LCSC number, pin-level connectivity, and AI annotations (function, block membership, role, critical specs)
- **Nets** — all named nets with type (power/signal/clock), protocol, direction, and description
- **Functional blocks** — logical groupings (power, mcu, i2c_mux, sensor_connectors, led_controller) with descriptions and design intent notes
- **Sheet interfaces** — hierarchical pin mappings showing signal flow between parent and child schematics
- **Source metadata** — schema version, source hash, and extraction timestamp for staleness detection

### Tooling

Scripts live in `tools/schematic-context/` (see that folder's README for full usage):

| Script | Purpose |
|---|---|
| `extract.py` | Runs kicad-cli + kiutils to produce `circuit-context.json` from a root `.kicad_sch` |
| `annotate.py` | Writes `ai_` properties to components in `.kicad_sch` files via kiutils |
| `show.py` | Displays annotation coverage — useful during interactive annotation sessions |

### Workflow

1. Edit schematic in KiCad
2. Run `extract.py` on the root `.kicad_sch` — uses `--previous` to merge forward existing net/block annotations
3. If new components appeared, run an interactive annotation session with AI (propose annotations → confirm → write via `annotate.py`)
4. Re-extract to produce the final context file with all annotations merged

Component annotations (`ai_function`, `ai_block`, `ai_role`, `ai_critical_specs`) are stored as custom properties in the `.kicad_sch` file — they survive schematic edits. Net and block annotations are stored in `circuit-context.json` and carried forward via the `--previous` merge.

### Deprecated: Old Netlist + Annotation System

The previous system used `convert_netlist_to_json.py` to produce JSON netlists with separate YAML annotation files. This has been fully replaced by the schematic context system. Old files in `hardware/pcb-main/kicad/netlists/` and `hardware/pcb-sensor/kicad/netlist/` are retained for reference but should not be used.

## VCNL4040 Sensor Capabilities

- **Proximity Detection**: IR LED emission and reflection measurement
- **Ambient Light Sensing**: Human eye response approximation
- **Programmable**: Integration time, interrupt thresholds, LED current control
- **Communication**: I2C up to 400kHz
- **Reference docs**: `docs/references/vcnl4040/`

## I2C Multiplexing Architecture

```
T-Display-S3
    └── TCA9548A (Primary MUX, 0x70)
        ├── Channel 0 → PCA9546A (0x74) → 2× VCNL4040 (Module 1)
        ├── Channel 1 → PCA9546A (0x75) → 2× VCNL4040 (Module 2)
        └── Channel 2 → PCA9546A (0x76) → 2× VCNL4040 (Module 3)
```

All VCNL4040 sensors share address 0x60. The TCA→PCA dual-MUX chain provides individual addressability.

---

*Last Updated: March 25, 2026*

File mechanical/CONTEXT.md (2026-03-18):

# Mechanical — Motion Play

Context for the `mechanical/` directory: 3D-printed parts designed with build123d and viewed in OCP CAD Viewer.

## What This Is

This folder contains parametric 3D models for the Motion Play project and related experiments. The primary focus is sensor enclosures for the hoop assembly, but the same tooling supports any 3D-printable part — replacement components, fixtures, test jigs, etc.

All parts are designed in Python using build123d (parametric B-rep CAD on OpenCASCADE) and viewed in OCP CAD Viewer.

## Structure

```
mechanical/
├── CONTEXT.md                 # This file
├── FDM_DESIGN_RULES.md        # 3D printing design standards and tolerances
├── specs/                     # Problem definition and constraints
│   └── assembly-v0.1.yaml    # Hoop assembly dimensions and requirements
├── models/                    # CAD models, one folder per project
│   ├── enclosures/            # Sensor enclosure designs (option-a, interior-channel, etc.)
│   │   └── option-X/          # Each option explores a different solution
│   │       ├── *.py           # build123d scripts (self-documenting)
│   │       ├── *.step         # Exported STEP files
│   │       └── *.stl          # Exported STL files (for slicing/printing)
│   └── door-latch-spring/     # Replacement spring for a mortise latch (experiment)
├── view.sh                    # Interactive launcher: model selector + OCP viewer auto-start
└── .venv/                     # Python venv (build123d, ocp_vscode)
```

## Design Process

1. **Spec first**: For project-related parts, `specs/assembly-v0.1.yaml` defines the physical constraints. For standalone p1s, the script docstring describes the problem and measurements.
2. **Explore options**: `docs/explorations/sensor-enclosure.md` evaluates design approaches before committing to CAD work (for enclosures specifically).
3. **Parametric CAD**: Each project folder contains build123d Python scripts. Dimensions trace back to the spec file or to `FDM_DESIGN_RULES.md`. Scripts are self-documenting — the docstring at the top of each `.py` file explains what the part is, how it prints, and its coordinate system.
4. **Visual evaluation**: Run `./mechanical/view.sh` to select a project and model, then view in OCP CAD Viewer. The launcher auto-starts the viewer if it isn't running.
5. **Print and test**: Export STL, slice in PrusaSlicer, print on Prusa Core One. PLA for test-fitting, PETG for final parts.

## Coordinate Conventions

Enclosure scripts use consistent axis definitions (see individual script docstrings for project-specific conventions):

- **X** = across bar width (25.25mm)
- **Y** = along hoop circumference
- **Z** = radial — meaning depends on which face:
  - Outer shell: +Z = away from bar (outward from hoop)
  - Inner shell: +Z = into hoop interior (away from bar)
- **Origin** = center of the part's bar-contact surface

The outer and inner shells have opposite Z directions because they sit on opposite faces of the bar. Assembly scripts handle the 180° rotation around X.

## Tooling

- **CAD**: build123d — Python parametric B-rep modeling on OpenCASCADE
- **Viewer**: OCP CAD Viewer standalone server, port 3939
- **Launcher**: `./mechanical/view.sh` from project root (auto-starts viewer if needed)
- **Environment**: Python 3.13 venv at `mechanical/.venv`
- **Printer**: Prusa Core One, PrusaSlicer
- **Materials**: PLA (test fitting), PETG (final parts)

## Related

- **PCB dimensions**: `hardware/sensor-rigid/`, `hardware/sensor-flex/`
- **Flex PCB rationale**: `docs/initiatives/flex-sensor-pcb/DESIGN_PLAN.md`
- **Design exploration**: `docs/explorations/sensor-enclosure.md`
- **Project overview**: `.context/PROJECT.md`

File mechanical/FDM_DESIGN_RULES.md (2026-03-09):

# FDM 3D Printing Design Rules

Standard minimums and tolerances for FDM-printed parts in this project. Referenced by build123d scripts when setting wall thicknesses, clearances, boss sizes, and other print-sensitive dimensions.

**Printer:** Prusa Core One (0.4mm nozzle)
**Build plate:** 250 × 220mm
**Slicer:** PrusaSlicer
**Materials:** PLA (prototyping), PETG (final)

## Wall Thickness

| Rule | Minimum | Preferred |
|---|---|---|
| Perimeter wall | 1.2mm (3 perimeters) | 1.6mm (4 perimeters) |
| Structural wall (load-bearing) | 1.6mm | 2.0mm |
| Thin feature / rib | 0.8mm (2 perimeters) | 1.2mm |

## Hole and Boss Design

| Rule | Value | Notes |
|---|---|---|
| Hole-to-edge minimum | 2.0mm | Material between hole wall and nearest edge |
| Screw boss OD | ≥ 2× insert hole diameter | e.g., M2.5 insert (3.6mm hole) → boss ≥ 7.2mm |
| Heat-set insert hole depth | insert length + 0.5mm | Extra depth for melt overflow |
| Vertical holes | print 0.1–0.2mm undersized | Drill or ream to final size if needed |

## Clearances and Tolerances

| Fit Type | Clearance per side | Use case |
|---|---|---|
| Press fit | 0.05–0.10mm | Inserts, pins |
| Snug / sliding fit | 0.15–0.25mm | Lids, mating shells |
| Loose / assembly fit | 0.30–0.50mm | Parts that need to slide freely |

## Overhangs and Bridging

| Rule | Limit | Notes |
|---|---|---|
| Unsupported overhang angle | ≤ 45° from vertical | Beyond 45° needs support |
| Unsupported bridge span | ≤ 10mm | Beyond 10mm may sag |
| Bridging for screw holes | Support or print vertically | Horizontal holes > 3mm need support |

## Layer and Feature Limits

| Rule | Value |
|---|---|
| Minimum Z-axis feature | 0.2mm (1 layer at standard height) |
| Minimum XY feature | 0.4mm (nozzle diameter) |
| Minimum slot width | 0.5mm |
| Minimum emboss/deboss depth | 0.4mm |

## Fastener Reference

| Screw | Clearance Hole | Heat-Set Insert Hole | Boss OD (min) |
|---|---|---|---|
| M2 | 2.4mm | 3.2mm | 6.4mm |
| M2.5 | 2.9mm | 3.6mm | 7.2mm |
| M3 | 3.4mm | 4.0mm | 8.0mm |

## General Principles

- **Weakest axis is Z**: Layer adhesion is the weakest direction. Orient parts so critical loads are in-plane (XY), not across layers.
- **Fillets at stress points**: ≥ 0.5mm radius at inside corners to reduce delamination risk.
- **Round external corners**: Reduces stress concentration and improves print quality.
- **Hole compensation**: FDM holes print ~0.1–0.2mm undersized. Add compensation in the model or plan to drill.
- **Test fit with PLA first**: Cheap and fast iteration before committing to PETG.

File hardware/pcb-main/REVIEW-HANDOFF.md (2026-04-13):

I need a thorough final review of my main PCB design before sending it to JLCPCB for manufacture and assembly. The goal is to catch any errors that would result in a non-functional board, wasted money, or a board that needs rework.

### Context

Read these files first (in this order):

1. `/Users/marcocleirigh/Workspace/motion-play/.context/PROJECT.md` — project overview
2. `/Users/marcocleirigh/Workspace/motion-play/hardware/CONTEXT.md` — hardware architecture
3. `/Users/marcocleirigh/Workspace/motion-play/hardware/pcb-main/kicad/circuit-context.json` — freshly extracted schematic data (all components, nets, pins, functional blocks)
4. `/Users/marcocleirigh/Workspace/motion-play/hardware/pcb-main/kicad/pcb-layout-context.json` — freshly extracted PCB layout data (component positions, board outline, pad locations)

### Recent changes since last preflight review (2026-03-16)

These changes have NOT been reviewed yet:

1. **Removed T-Display-S3 dev board**, replaced with custom ESP32-S3-WROOM-1 implementation (U3) on a new `esp32_s3.kicad_sch` sub-sheet. Includes boot/reset buttons (SW2, SW3), USB data resistors (R52, R53), EN pull-up (R50), bootstrap cap/decoupling (C50-C55), status LED (D5 WS2812B-MINI), and GPIO strapping.
2. **Removed DWEII USB-C power module**, replaced with custom power circuitry: BQ24195 battery charger/PMIC (U5), TPS61088 5V boost converter (U6), INA219 current monitor (U7), and supporting components.
3. **Reverse polarity protection fix**: R34 was rewired from BAT_RAW to GND. Previously R33 (VBAT→GATE) and R34 (GATE→BAT_RAW) formed a non-functional divider. Now R34 (GATE→GND) creates a proper divider giving Vgs ≈ -VBAT/2.
4. **Added power indicator LED**: D1 (green LED) + R1 (1kΩ) on the 3.3V rail.
5. **Replaced JST-PH battery connector (J8) with Keystone 1042 battery holder (BT1)**: SMD 18650 holder on the back of the PCB. Footprint modified — one NPTH mechanical hole deleted (conflicted with front-side power components), another deleted (couldn't relocate). Two solder pads + one remaining peg retained.
6. **Added AMS1117-3.3 LDO (U8)**: Additional 3.3V regulator (check if this is redundant with AP2112K).
7. **Added USBLC6-2SC6 (U9)**: USB ESD protection.
8. **Added power switch SW1** (SS-12D10L5): Physical on/off switch.
9. **Board width changed**: Was 88mm, narrowed, then re-widened to ~88mm to fit the battery holder.

### What to review

#### 1. Schematic correctness (use circuit-context.json)
- Verify all power rails connect correctly: VBUS_RAW → protected VBUS → BQ24195 → VSYS → TPS61088 → +5V; VSYS → AP2112K/AMS1117 → +3.3V
- Check the reverse polarity protection circuit: Q2 (PMOS), R33 (VBAT→GATE), R34 (GATE→GND). Verify this topology is correct for a high-side PMOS reverse polarity protection.
- Check for redundant voltage regulators (AP2112K + AMS1117 both outputting 3.3V?)
- Verify BQ24195 support components match the datasheet (ILIM, NTC, BTST cap, REGN cap, PMID caps, inductor)
- Verify TPS61088 support components
- Verify ESP32-S3 WROOM connections: power, EN, boot strapping (GPIO0), USB D+/D-, I2C, GPIOs
- Check all I2C buses: upstream (MCU → TCA9548A), downstream (TCA channels to JST-SH connectors)
- Verify LED strip path: data line through SN74AHCT125 level shifter, power through fuse + current sense
- Check for missing pull-ups/pull-downs on critical signals
- Verify no floating inputs on ICs
- Check decoupling capacitors on all ICs

#### 2. ERC analysis (use reports/ERC.json)
- 60 violations (all warnings, 0 errors)
- Previous review found 30 warnings, all benign. 30 new warnings appeared — likely from the new ESP32 and power components. Categorize each and determine if any indicate real issues.
- 2 `lib_symbol_issues` (known: USB-C and BQ24195 imported symbol libraries not in config)
- 58 `pin_to_pin` warnings — the previous review found these were mostly from EasyEDA-imported symbols with "Unspecified" pin types. Verify the new ones follow the same pattern.
- This ERC.json file is generated by our 'kiutils' script. There is also a ERC.rpt which I generate through the Kicad PCB editor UI, which sometimes contains different information and is worth checking also. See it here: "hardware/pcb-main/kicad/ERC.rpt"

#### 3. DRC analysis (use reports/DRC.json)
- 36 violations (29 errors, 7 warnings), 0 unconnected nets
- Previous review had 33 violations, all within JLCPCB manufacturing tolerances. Categorize the current 36:
  - 25 clearance violations — determine if these are within JLCPCB capabilities (min 0.09mm clearance, 0.127mm trace, 0.2mm drill)
  - 3 silk overlap — cosmetic only
  - 2 annular width — likely from component footprints (known for TPS61088 thermal vias and USB-C)
  - 2 hole clearance — likely USB-C mounting holes (known)
  - 2 padstack — investigate, these may be new
  - 1 track_dangling — investigate, may indicate a leftover trace from J8 removal
  - 1 connection_width — investigate
- The modified Keystone 1042 footprint (2 NPTH holes deleted) should be checked for any DRC issues
- This DRC.json file is generated by our 'kiutils' script. There is also a DRC.rpt which I generate through the Kicad PCB editor UI, which sometimes contains different information and is worth checking also. See it here: "hardware/pcb-main/kicad/DRC.rpt"

#### 4. BOM / assembly readiness
- Read `hardware/pcb-main/kicad/production/bom.csv` and verify all LCSC part numbers are present
- BT1 (Keystone 1042) is NOT on LCSC — must be hand-soldered. Verify it's excluded from or marked in the JLCPCB BOM.
- D1, R1 (new power LED) need LCSC part numbers
- All new ESP32 sub-sheet components need LCSC part numbers
- Check the previous preflight review (`hardware/pcb-main/kicad/reports/preflight-review.md`) for any substitutions that were made — verify those are still in the schematic

#### 5. PCB layout checks (use pcb-layout-context.json)
- Verify the Keystone 1042 (BT1) is on the back side and within board outline
- Check that BT1 pads don't overlap with any through-hole pads on B.Cu (especially USB-C J7 mounting pins)
- Verify ESP32 antenna keepout zone (X: 121-140.5, Y: 100.9-107.6) has no copper on any layer
- Verify the 18650 cell body (65mm × 18.3mm diameter) won't physically overlap the antenna area in 3D
- Check that all 92 components are placed (extract reported 92 placed, 0 unplaced)
- Look for any components placed outside the board outline

#### 6. New components annotation
22 components lack AI annotations (run `python3 tools/schematic-context/show.py hardware/pcb-main/kicad/motion-play-main.kicad_sch --unannotated` to see the list). These should be annotated for future sessions. The unannotated components are:
- BT1, D1, R1, SW1, U8, U9 (power management sheet — new)
- U3, C50-C55, D5, R50-R53, SW2, SW3 (ESP32 sheet — all new)

DO NOT Use `tools/schematic-context/annotate.py` to write annotations after reviewing. Using that script causes issues with the kicad files, creating a headache for me, so we want to be careful about using it. Propose annotations, but do not try to annotate. Do not edit any of the kicad files directly either. 

### Output format

Produce a structured report similar to `hardware/pcb-main/kicad/reports/preflight-review.md` with:
- Overall verdict (PASS / CONDITIONAL PASS / FAIL)
- Section-by-section findings with severity (blocker / warning / advisory / info)
- Specific action items for anything that needs fixing before ordering
- A clear list of what's safe to ignore vs. what must be fixed

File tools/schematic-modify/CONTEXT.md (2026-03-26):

# Schematic Modify Toolkit Context

Programmatic helpers for editing existing KiCad schematics in place.

## Purpose

`schematic-modify` fills the gap between:

- `tools/schematic-gen/` (generates full new sheets from a structured spec)
- `tools/schematic-context/` (extracts + annotates context data from schematic files)

Use `schematic-modify` when you need to append/remove components or sheet links in an existing `.kicad_sch` without rewriting the whole file.

## Relationship to Other Tools

- **`schematic-gen`** is source-of-truth for generated sheets.
- **`schematic-modify`** performs surgical updates on existing sheets.
- **`schematic-context/annotate.py`** remains the single place that writes `ai_*` properties.

Design rule: this toolkit sets electrical properties (nets, footprint, LCSC fields) and delegates annotation to `annotate.py` after placement.

## Current Files

- `modify.py`: reusable helpers (`add_component`, `remove_component`, `add_hierarchical_label`, `add_sheet_reference`, `annotate_components`)
- `esp32_integration.py`: initiative-specific modifications for ESP32-S3 direct integration

## Typical Workflow

1. Run `esp32_integration.py --apply` (or custom script using `modify.py`) to place components/sheet refs off to one side.
2. Script calls `tools/schematic-context/annotate.py` for `ai_*` properties.
3. Open KiCad and do manual placement/wiring cleanup.
4. Run `tools/schematic-context/extract.py --previous` to refresh `circuit-context.json`.

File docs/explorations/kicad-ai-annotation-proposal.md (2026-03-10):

# Proposal: AI-Assisted Schematic Annotation for KiCad

**Decision: Decided** — Proceeding as initiative `docs/initiatives/schematic-context/`. Approach validated via spike test (kiutils 1.4.8 + kicad-cli). Key refinements from spike: kiutils handles property read/write but not connectivity; kicad-cli fills the gap with authoritative netlist export. Net annotations stored in output file (not schematic) since kiutils labels lack property support.

## Background

This project uses KiCad 9 for PCB design, JLCPCB for fabrication and assembly, and LCSC for component sourcing. An existing KiCad plugin exports a JSON netlist to provide AI assistants with schematic context.

The current export is limited — it captures topology (what connects to what) but loses semantic information (what things *mean*). This causes AI to miss things that are obvious when reading the schematic visually: signal direction, functional groupings, power topology, design intent.

## Problem Statement

AI-assisted schematic reasoning is only as good as the data it receives. Structured netlist data has several known blind spots:

- **Auto-named nets** (`Net-(U1-Pin7)`) are opaque — no signal type, protocol, or direction is implied
- **Pin names are dropped** — knowing U1 pin 7 is `GPIO21/SDA` is far more useful than just the pin number
- **Pin electrical types are lost** — whether a pin is input, output, bidirectional, or passive is key to reasoning about signal flow
- **Passive component roles are ambiguous** — a resistor between a signal and a power rail could be a pull-up, current limiter, or something else entirely
- **Functional groupings are absent** — nothing marks a cluster of components as "the power supply block" or "the I2C interface"
- **Design intent is invisible** — structured data can represent what a circuit *is*, but not what the designer *meant*

Schematic files can also be large (114kb+ observed), making it impractical to read the raw file into an AI context window directly.

## Proposed Solution

An interactive AI-assisted annotation workflow, run via Claude Code, that:

1. Uses a small set of Python tool scripts (built on `kiutils`) to read and write `.kicad_sch` files
2. Extracts a compact JSON summary of components, nets, and existing properties — not the raw schematic
3. Interviews the designer via natural language chat to capture semantic context
4. Writes annotations back into the schematic as KiCad custom properties, in-session
5. Produces richer AI context automatically on all subsequent exports, with no further manual input

The schematic file itself is the only state. No session persistence is needed — if a session is interrupted, the next session picks up from whatever has already been annotated.

## Key Design Principles

- **Propose, don't ask open questions** — Claude should offer candidate answers ("is this your 3.3V regulator?") rather than asking "what does this do?"
- **Batch related questions** — group questions by apparent functional block, not component-by-component
- **Light-touch inference** — use footprint data, existing values, and net name patterns to form candidate answers, but always ask for confirmation. No complex inference rules; the annotation session is a one-time effort and the overhead of just answering questions is low.
- **Non-destructive** — annotations are additive custom properties; no existing KiCad data is modified or removed
- **Git-friendly** — each annotation session produces a clean diff; the history is auditable

## Technical Approach

### Why Not the KiCad Python API?

KiCad has two Python surfaces. `pcbnew` (layout) can be imported as a standalone library. The schematic module (`eeschema`) cannot — it is only accessible from inside KiCad's scripting console. A command-line script cannot call it.

### `kiutils` as the Foundation

[`kiutils`](https://github.com/mvnmgrx/kiutils) is a pure Python library that parses and writes KiCad 6–9 file formats, including `.kicad_sch`, with no KiCad installation required. It provides a full object model for symbols, properties, pins, and net labels, and supports round-trip write-back.

```python
from kiutils.schematic import Schematic

sch = Schematic.from_file("project.kicad_sch")

for symbol in sch.schematicSymbols:
    print(symbol.libraryNickname, symbol.entryName)
    for prop in symbol.properties:
        print(f"  {prop.key}: {prop.value}")
    for pin in symbol.pins:
        print(f"  pin {pin.number} ({pin.name}) → net: {pin.netName}")
```

Writing a custom property back:

```python
from kiutils.items.common import Property

new_prop = Property(key="ai_function", value="power_supply")
symbol.properties.append(new_prop)
sch.to_file()
```

This solves the context window problem: the script extracts only what is needed (refs, values, footprints, pin names, net names, existing properties) and produces a compact JSON payload — typically a few kilobytes regardless of schematic size.

### Net Label Annotations

In KiCad 7+ (including KiCad 9), net labels support custom properties. `kiutils` exposes these. Net-level metadata (signal type, protocol, direction) can therefore be stored directly on net labels in the schematic — no sidecar file needed.

### Tool Scripts

The workflow is implemented as a small set of Python scripts that Claude Code calls as tools:

| Script | Purpose |
|---|---|
| `read_schematic.py` | Parses schematic, returns compact JSON summary of all components and nets |
| `get_component.py <ref>` | Returns full detail for a single component including all pins and existing properties |
| `list_unannotated.py` | Returns components and nets that have no `ai_` properties yet |
| `annotate_component.py <ref> <key=value ...>` | Writes one or more custom properties to a component in-file |
| `annotate_net.py <net_name> <key=value ...>` | Writes one or more custom properties to a net label in-file |

All scripts operate directly on the `.kicad_sch` file. The schematic is modified in place; KiCad will reformat on next open, which is expected and fine.

### Integration Model

The designer opens a Claude Code session and converses naturally. Claude calls the tool scripts to read context, reason about what it sees, ask batched confirmatory questions, and write annotations as answers are confirmed. No special invocation is needed beyond starting the session.

Example exchange:

```
You: Let's annotate the schematic

Claude: [calls list_unannotated, read_schematic]
        Found 14 components without annotations. Starting with what looks
        like a power block — U1 (AMS1117-3.3), C3 (100µF), C4 (100nF).

        Is U1 your 3.3V linear regulator? Proposing:
          U1 → ai_function=power_supply, ai_input_rail=5V, ai_output_rail=3V3
          C3, C4 → ai_function=decoupling, ai_block=power_supply

You: Yes, but use 3V3 as the rail name not 3V3_OUT

Claude: [calls annotate_component for U1, C3, C4]
        Done. I can also see Net-(U1-Pin2) and Net-(U1-Pin3) —
        proposing to rename those to 5V and 3V3 and tag them as power rails. OK?

You: Yes
...
```

## Annotation Schema

Custom properties written to components:

| Property | Example values |
|---|---|
| `ai_function` | `power_supply`, `decoupling`, `pull_up`, `current_limit`, `mcu`, `sensor`, `connector` |
| `ai_description` | Free text, designer-confirmed |
| `ai_block` | Functional group label, e.g. `power_supply`, `sensor_interface`, `usb` |
| `ai_input_rail` | e.g. `5V` — for power components |
| `ai_output_rail` | e.g. `3V3` — for power components |

Custom properties written to net labels:

| Property | Example values |
|---|---|
| `ai_signal_type` | `power`, `signal`, `analog` |
| `ai_protocol` | `I2C`, `SPI`, `UART`, `USB` |
| `ai_direction` | `input`, `output`, `bidirectional` |

The schema is intentionally minimal. New keys can be added ad hoc during annotation sessions — the export plugin reads all `ai_` prefixed properties dynamically.

## Export Plugin Update

The existing JSON export plugin is updated to include all `ai_` prefixed properties in its output for both components and nets. The plugin interface (how it's invoked, what files it produces) does not change — only the richness of the data it emits.

The annotation tooling and export plugin can be developed independently once the property schema is agreed.

## Open Questions

- [ ] **Hierarchical schematics** — if the project uses multiple `.kicad_sch` files (sheets), do the tool scripts need to handle cross-sheet net resolution, or is annotating each sheet independently sufficient?
- [ ] **Footprint-to-function inference** — agree on a short list of footprint/value patterns worth auto-detecting (e.g. C in decoupling position, R between signal and power net). Keep this list small and confirmed by testing.
- [ ] **Export plugin changes** — review the existing plugin to confirm it reads component properties from the parsed schematic (not a compiled netlist), so `ai_` properties will be picked up without further changes.

## Next Steps

- [ ] Install `kiutils`, confirm it reads a sample `.kicad_sch` cleanly and can write a custom property back without corrupting the file
- [ ] Write and test the five tool scripts against a real schematic
- [ ] Run a first annotation session end-to-end on a small schematic
- [ ] Update the export plugin to include `ai_` properties in its JSON output
- [ ] Document the schema in the repo for future reference

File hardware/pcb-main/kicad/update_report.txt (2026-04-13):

Info: Total warnings: 12, errors: 0.
Info: Processing symbol 'C7:Capacitor_SMD:C_0603_1608Metric'.
Info: Processing symbol 'TPIO44:TestPoint:TestPoint_Pad_D2.0mm'.
Info: Processing symbol 'C9:Capacitor_SMD:C_0603_1608Metric'.
Info: Processing symbol 'C10:Capacitor_SMD:C_0603_1608Metric'.
Info: Processing symbol 'C20:Capacitor_SMD:C_0603_1608Metric'.
Info: Processing symbol 'C21:Capacitor_SMD:C_0603_1608Metric'.
Info: Processing symbol 'C22:Capacitor_SMD:C_Elec_6.3x5.4'.
Info: Processing symbol 'C23:Capacitor_SMD:C_0603_1608Metric'.
Info: Processing symbol 'C24:Capacitor_SMD:C_0603_1608Metric'.
Info: Processing symbol 'C25:Capacitor_SMD:C_0603_1608Metric'.
Info: Processing symbol 'C26:Capacitor_SMD:C_0603_1608Metric'.
Info: Processing symbol 'C27:Capacitor_SMD:C_0603_1608Metric'.
Info: Processing symbol 'C28:Capacitor_SMD:C_0603_1608Metric'.
Info: Processing symbol 'C29:Capacitor_SMD:CP_Elec_6.3x7.7'.
Info: Processing symbol 'C30:Capacitor_SMD:C_Elec_6.3x5.4'.
Info: Processing symbol 'C31:Capacitor_SMD:C_0603_1608Metric'.
Info: Processing symbol 'C32:Capacitor_SMD:C_0603_1608Metric'.
Info: Processing symbol 'C33:Capacitor_SMD:C_0603_1608Metric'.
Info: Processing symbol 'C34:Capacitor_SMD:C_0805_2012Metric'.
Info: Processing symbol 'C35:Capacitor_SMD:C_0805_2012Metric'.
Info: Processing symbol 'C36:Capacitor_SMD:C_0805_2012Metric'.
Info: Processing symbol 'C37:Capacitor_SMD:C_0603_1608Metric'.
Info: Processing symbol 'C38:Capacitor_SMD:C_0603_1608Metric'.
Info: Processing symbol 'C39:Capacitor_SMD:C_0603_1608Metric'.
Info: Processing symbol 'C40:Capacitor_SMD:C_0603_1608Metric'.
Info: Processing symbol 'C41:Capacitor_SMD:C_0805_2012Metric'.
Info: Processing symbol 'C42:JLC-MCP:C0805'.
Info: Processing symbol 'C43:JLC-MCP:CASE-A_3216'.
Info: Processing symbol 'C50:Capacitor_SMD:C_0603_1608Metric'.
Info: Processing symbol 'C51:Capacitor_SMD:C_0603_1608Metric'.
Info: Processing symbol 'C52:Capacitor_SMD:C_0603_1608Metric'.
Info: Processing symbol 'C53:Capacitor_SMD:C_0603_1608Metric'.
Info: Processing symbol 'C54:Capacitor_SMD:C_0603_1608Metric'.
Info: Processing symbol 'C55:Capacitor_SMD:C_0603_1608Metric'.
Info: Processing symbol 'D1:LED_SMD:LED_0603_1608Metric'.
Info: Processing symbol 'D5:JLC-MCP:LED-SMD_4P-L3.5-W3.5-TL_WS2812B-1'.
Info: Processing symbol 'F1:Fuse:Fuse_1206_3216Metric'.
Info: Processing symbol 'F2:Fuse:Fuse_1206_3216Metric'.
Info: Processing symbol 'IC1:motion-play-footprints:SOP65P640X120-14N'.
Info: Processing symbol 'J3:Connector_JST:JST_PH_S3B-PH-SM4-TB_1x03-1MP_P2.00mm_Horizontal'.
Info: Processing symbol 'J4:Connector_JST:JST_SH_SM04B-SRSS-TB_1x04-1MP_P1.00mm_Horizontal'.
Info: Processing symbol 'J5:Connector_JST:JST_SH_SM04B-SRSS-TB_1x04-1MP_P1.00mm_Horizontal'.
Info: Processing symbol 'J6:Connector_JST:JST_SH_SM04B-SRSS-TB_1x04-1MP_P1.00mm_Horizontal'.
Info: Processing symbol 'J7:TYPE-C-31-M-12:USB-C_SMD-TYPE-C-31-M-12_1'.
Info: Processing symbol 'BT1:Battery:BatteryHolder_Keystone_1042_1x18650'.
Info: Processing symbol 'L1:Inductor_SMD:L_Changjiang_FNR6028S'.
Info: Processing symbol 'L2:FXL0630-2R2-M:IND-SMD_L7.0-W6.6'.
Info: Processing symbol 'Q2:Package_TO_SOT_SMD:SOT-23'.
Info: Processing symbol 'R1:Resistor_SMD:R_0603_1608Metric'.
Info: Processing symbol 'R6:Resistor_SMD:R_0603_1608Metric'.
Info: Processing symbol 'R27:Resistor_SMD:R_2512_6332Metric'.
Info: Processing symbol 'C8:Capacitor_SMD:C_0603_1608Metric'.
Info: Processing symbol 'U9:JLC-MCP:SOT-23-6_L2.9-W1.6-P0.95-LS2.8-BL'.
Info: Processing symbol 'U8:JLC-MCP:SOT-223-3_L6.5-W3.4-P2.30-LS7.0-BR'.
Info: Processing symbol 'U7:INA219AIDCNR:SOT-23-8_L3.0-W1.7-P0.65-LS2.8-BR'.
Info: Processing symbol 'U6:TPS61088RHLR:VQFN-20_L4.6-W3.6-P0.50-BL'.
Info: Processing symbol 'U5:BQ24195RGET:VQFN-24_L4.0-W4.0-P0.50-TL-EP2.8'.
Info: Processing symbol 'U4:motion-play-footprints:SOP65P640X120-24N'.
Info: Processing symbol 'U3:JLC-MCP:WIRELM-SMD_ESP32-S3-WROOM-1'.
Info: Processing symbol 'R28:Resistor_SMD:R_0603_1608Metric'.
Info: Processing symbol 'R29:Resistor_SMD:R_0603_1608Metric'.
Info: Processing symbol 'R30:Resistor_SMD:R_0603_1608Metric'.
Info: Processing symbol 'R31:Resistor_SMD:R_0603_1608Metric'.
Info: Processing symbol 'R32:Resistor_SMD:R_0603_1608Metric'.
Info: Processing symbol 'R33:Resistor_SMD:R_0603_1608Metric'.
Info: Processing symbol 'R34:Resistor_SMD:R_0603_1608Metric'.
Info: Processing symbol 'R35:Resistor_SMD:R_0603_1608Metric'.
Info: Processing symbol 'R36:Resistor_SMD:R_0603_1608Metric'.
Info: Processing symbol 'R37:Resistor_SMD:R_0603_1608Metric'.
Info: Processing symbol 'R38:Resistor_SMD:R_0603_1608Metric'.
Info: Processing symbol 'R39:Resistor_SMD:R_0603_1608Metric'.
Info: Processing symbol 'R40:Resistor_SMD:R_0603_1608Metric'.
Info: Processing symbol 'R41:Resistor_SMD:R_0603_1608Metric'.
Info: Processing symbol 'R42:Resistor_SMD:R_0603_1608Metric'.
Info: Processing symbol 'R43:Resistor_SMD:R_0603_1608Metric'.
Info: Processing symbol 'R44:Resistor_SMD:R_2512_6332Metric'.
Info: Processing symbol 'R50:Resistor_SMD:R_0603_1608Metric'.
Info: Processing symbol 'R51:Resistor_SMD:R_0603_1608Metric'.
Info: Processing symbol 'R52:Resistor_SMD:R_0603_1608Metric'.
Info: Processing symbol 'R53:Resistor_SMD:R_0603_1608Metric'.
Info: Processing symbol 'SW1:JLC-MCP:SW-TH_SS-12D10L5'.
Info: Processing symbol 'SW2:JLC-MCP:KEY-SMD_L4.0-W3.0-LS4.9-1'.
Info: Processing symbol 'SW3:JLC-MCP:KEY-SMD_L4.0-W3.0-LS4.9-1'.
Info: Processing symbol 'TH1:Resistor_SMD:R_0603_1608Metric'.
Info: Processing symbol 'TP1:TestPoint:TestPoint_Pad_D1.5mm'.
Info: Processing symbol 'TP2:TestPoint:TestPoint_Pad_D1.5mm'.
Info: Processing symbol 'TP3:TestPoint:TestPoint_Pad_D1.5mm'.
Info: Processing symbol 'TP4:TestPoint:TestPoint_Pad_D1.5mm'.
Info: Processing symbol 'TPIO10:TestPoint:TestPoint_Pad_D2.0mm'.
Info: Processing symbol 'TPIO16:TestPoint:TestPoint_Pad_D2.0mm'.
Info: Processing symbol 'TPIO21:TestPoint:TestPoint_Pad_D2.0mm'.
Info: Processing symbol 'TPIO43:TestPoint:TestPoint_Pad_D2.0mm'.
Update D1 fields.

Reconnect U9 pin 5 from GND to /Power Management/Protected_VBUS.
Update TP2 fields.
Warning: No net found for component J4 pad MP (no pin MP in symbol).
Warning: No net found for component J7 pad 4 (no pin 4 in symbol).
Warning: No net found for component J7 pad 1 (no pin 1 in symbol).
Warning: No net found for component J7 pad 3 (no pin 3 in symbol).
Warning: No net found for component J6 pad MP (no pin MP in symbol).
Warning: No net found for component J6 pad MP (no pin MP in symbol).
Warning: No net found for component J5 pad MP (no pin MP in symbol).
Warning: No net found for component J5 pad MP (no pin MP in symbol).
Warning: No net found for component J4 pad MP (no pin MP in symbol).
Warning: No net found for component J3 pad MP (no pin MP in symbol).
Warning: No net found for component J3 pad MP (no pin MP in symbol).
Warning: No net found for component J7 pad 2 (no pin 2 in symbol).

Info: Total warnings: 12, errors: 0.

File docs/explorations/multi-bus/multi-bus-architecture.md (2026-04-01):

 # Multi-Bus I2C Architecture — Exploration

**Date:** March 22, 2026
**Status:** Decided
**Branch:** `esp32-integration-schematic`
**Decision:** Option A (Dual I2C Bus, No TCA) selected. See [`docs/initiatives/dual-bus-i2c/`](../../initiatives/dual-bus-i2c/BRIEF.md) for implementation.

---

## Problem Statement

The current single-bus I2C architecture polls 6 VCNL4040 sensors through a TCA9548A → PCA9546A mux chain at a measured 357 Hz. With the sensor configured at 2T/x8/1/40 (100Hz measurement rate), only ~75 of ~268 polls per sensor per 0.75s window contain unique data. We want to explore whether splitting the I2C traffic across multiple buses can improve timing precision, reduce poll cycle time, and prepare for future sensor upgrades — without adding complexity.

## Constraints

- ESP32-S3 MCU (2 hardware I2C controllers, GPIO-flexible)
- Sensor pairs required for directionality (Side A / Side B per module)
- Sensor angular offset limited to ~3-4° max (further tilt compromises center-of-hoop detection range)
- Willing to redesign PCBs and rewrite firmware
- INT lines abandoned (simplifies JST-SH from 5-pin to 4-pin, removes D2/D3/R5 from rigid board)
- Three sensor modules at 120° positions: M1 (6 o'clock, ~305mm cable), M2 (9 o'clock, ~305mm), M3 (3 o'clock, ~825mm)

## Current Architecture (Baseline)

```
ESP32-S3 I2C0 (GPIO43 SDA, GPIO44 SCL, 400kHz)
  ├── BQ24195 (0x6B) — charger PMIC
  ├── INA219 (0x40) — power monitor
  └── TCA9548A (0x70) — 8-ch I2C switch
       ├── Ch 0 → [305mm cable] → PCA9546A #1 (addr set by JP3/JP4) → 2× VCNL4040
       ├── Ch 1 → [305mm cable] → PCA9546A #2 (addr set by JP3/JP4) → 2× VCNL4040
       └── Ch 2 → [825mm cable] → PCA9546A #3 (addr set by JP3/JP4) → 2× VCNL4040
```

### Measured Performance

| Metric | Value | Source |
|---|---|---|
| Sensor config | 2T, x8 multi-pulse, 1/40 duty | Tested, landed config |
| Sensor measurement rate | ~100 Hz (unique readings) | Calculated from 2T/1/40 |
| Total polls in 0.75s session | 1,608 (all 6 sensors) | Measured from session data |
| Polls per sensor per session | 268 | 1608 / 6 |
| Poll rate | **357 Hz** | 268 / 0.75s |
| Unique readings per sensor per session | **~75** | 100Hz × 0.75s |
| Stale read ratio | ~72% | (268-75)/268 |
| Theoretical poll rate (prox only) | 549 Hz | From timing analysis |
| Poll rate gap | 357 vs 549 Hz | Likely: ALS reads, BQ/INA I2C, firmware overhead |

### Transit Detection at 30mph (13.4 m/s)

Ball: 190mm (size 3). Hoop: 500mm. Detection window: ~30-40ms.

| At 2T/x8/1/40 (100Hz) | Per sensor | All 6 sensors |
|---|---|---|
| Unique readings during transit | **3-4** | **18-24** |
| Poll samples during transit | ~11-14 | ~66-84 |

3-4 unique readings per sensor is tight for wave characterization and direction detection.

### Key Insight: TCA9548A Is Redundant

The three PCA9546A boards have **unique I2C addresses** (configured via solder jumper bridges JP3/JP4 on each rigid board). The PCA9546A isolates its downstream VCNL4040s when no channel is selected — this is its core function. With unique addresses, the ESP32 can address each PCA directly and only enable one channel at a time, ensuring only one VCNL4040 (0x60) is ever visible on the bus.

The TCA9548A provided an extra layer of isolation, but with addressable PCAs it is electrically unnecessary. Removing it saves:
- One TSSOP-24 IC (U4), two decoupling caps (C9, C10), one pull-up (R6)
- 3 TCA mux-select I2C transactions per read cycle (~150μs)
- The entire cleanup phase (~650μs): TCA channel selects, PCA disable sweeps, stabilization delays

**What we lose:** fault isolation (a bus-locked sensor board can't be isolated by software) and per-channel capacitance isolation (all cables load the bus simultaneously). Neither is a blocking concern at 400kHz with these cable lengths.

---

## Option A: Dual I2C Bus, No TCA (Recommended)

### Architecture

```
ESP32-S3 I2C0 (GPIO43 SDA, GPIO44 SCL, 400kHz)
  ├── BQ24195 (0x6B) — charger PMIC
  ├── INA219 (0x40) — power monitor
  ├── [305mm cable] → PCA9546A #1 (unique addr) → 2× VCNL4040 (M1)
  └── [305mm cable] → PCA9546A #2 (unique addr) → 2× VCNL4040 (M2)

ESP32-S3 I2C1 (GPIOxx SDA, GPIOyy SCL, 400kHz)
  └── [825mm cable] → PCA9546A #3 (unique addr) → 2× VCNL4040 (M3)
```

JST-SH connectors reduced to 4-pin: 3.3V, GND, SDA, SCL (INT removed).

### Bus Timing

**Bus 0 (M1 + M2, 4 sensors):**

| Operation | Time |
|---|---|
| PCA#2 select ch1 (sensor 3) | ~50 μs |
| Read 0x60 PS_DATA | ~120 μs |
| PCA#2 select ch0 (sensor 2) | ~50 μs |
| Read 0x60 PS_DATA | ~120 μs |
| PCA#2 disable | ~50 μs |
| PCA#1 select ch1 (sensor 1) | ~50 μs |
| Read 0x60 PS_DATA | ~120 μs |
| PCA#1 select ch0 (sensor 0) | ~50 μs |
| Read 0x60 PS_DATA | ~120 μs |
| PCA#1 disable | ~50 μs |
| **Subtotal (sensors)** | **~780 μs** |
| BQ24195/INA219 reads (estimate) | ~200-400 μs |
| **Total** | **~980-1,180 μs** |

**Bus 1 (M3, 2 sensors):**

| Operation | Time |
|---|---|
| PCA#3 select ch1 (sensor 5) | ~50 μs |
| Read 0x60 PS_DATA | ~120 μs |
| PCA#3 select ch0 (sensor 4) | ~50 μs |
| Read 0x60 PS_DATA | ~120 μs |
| PCA#3 disable | ~50 μs |
| **Total** | **~390 μs** |

**Synchronous mode:** Both buses start simultaneously. All 6 readings get the same cycle timestamp. Cycle time = slower bus.

### Projected Performance

| Metric | Current | Option A (sync) |
|---|---|---|
| Cycle time (sensor reads only) | ~2,800 μs (measured) | ~980 μs |
| Cycle time (with BQ/INA) | ~2,800 μs | ~1,180 μs |
| Poll rate | 357 Hz | ~850-1,020 Hz |
| Oversampling (at 100Hz sensor) | 3.6× | 8.5-10.2× |
| Max timestamp jitter | 2.8 ms | ~1.0-1.2 ms |
| All sensors symmetric? | Yes | Yes |
| Unique reads per transit (30mph) | 3-4 | 3-4 (unchanged) |
| Firmware changes | — | Moderate (2nd I2C init, remove TCA driver, adjust read loop) |
| Hardware changes | — | Remove TCA + passives, assign 2 GPIOs for I2C1, route to J6 |

**Note:** Unique reads per transit don't change because the VCNL4040 sensor measurement rate (100Hz at 2T/1/40) is the bottleneck, not the bus. The improvement is in timing precision and headroom.

### Signal Integrity (825mm on Bus 1)

- Cable capacitance: ~62 pF
- Plus IC pins, connectors, traces: ~90-120 pF total
- Pull-ups: R28/R29 = 2.2kΩ on main board (or new dedicated pull-ups for Bus 1)
- Rise time: τ = 2.2kΩ × 120pF = 264ns → 20-80% rise ≈ 191ns
- I2C 400kHz spec: <300ns → **passes with ~100ns margin**

### Signal Integrity (Bus 0 with 2 cables)

- M1 cable (~23 pF) + M2 cable (~23 pF) + IC pins + traces: ~100-130 pF
- Pull-ups: R28 (2.2kΩ) || M1 R1 (4.7kΩ) || M2 R1 (4.7kΩ) ≈ 1.1kΩ effective
- Rise time: τ = 1.1kΩ × 130pF = 143ns → 20-80% ≈ 103ns → **well within spec**
- Sink current at logic low: 3.3V / 1.1kΩ = 3.0mA → within PCA9546A's 6mA capability
- Consideration: could depopulate R1/R2 on sensor boards if pull-up is too strong

---

## Option B: Triple I2C Bus (2 Native + 1 Additional)

### Architecture

```
ESP32-S3 I2C0 (400kHz)
  ├── BQ24195, INA219
  └── [305mm] → PCA#1 → 2× VCNL4040 (M1)

ESP32-S3 I2C1 (400kHz)
  └── [305mm] → PCA#2 → 2× VCNL4040 (M2)

3rd Bus (see variants below)
  └── [825mm] → PCA#3 → 2× VCNL4040 (M3)
```

### 3rd Bus Variants

| Variant | Method | Speed | Cycle time (M3) | Extra components | Reliability |
|---|---|---|---|---|---|
| B1 | SPI-to-I2C bridge (e.g., SC18IS600) | 400kHz on I2C side | ~530 μs | 1 IC + passives | High |
| B2 | Software bitbang at 100kHz | 100kHz | ~1,560 μs | None | Medium |
| B3 | Software bitbang at 200kHz | 200kHz | ~780 μs | None | Medium-Low |

### Projected Performance (Synchronous)

| Metric | B1 (SPI bridge) | B2 (bitbang 100k) | B3 (bitbang 200k) |
|---|---|---|---|
| Cycle time (sync, slowest bus) | ~530 μs | ~1,560 μs | ~780 μs |
| Poll rate | ~1,890 Hz | ~640 Hz | ~1,280 Hz |
| Oversampling (at 100Hz) | 18.9× | 6.4× | 12.8× |
| All sensors symmetric? | Yes | Yes | Yes |
| Extra hardware? | Bridge IC | None | None |
| Firmware complexity | High (SPI-I2C driver) | Medium (bitbang lib) | Medium-High |
| Risk | Low | Low | Medium (timing jitter) |

### Trade-offs vs Option A

Each module gets its own dedicated bus — true 3-way symmetry, maximum fault isolation. But:

- BQ24195 and INA219 share Bus 0 with M1, adding ~200-400μs of non-sensor I2C traffic to that bus. In sync mode, this becomes the bottleneck unless those reads are moved out of the sensor cycle (e.g., read power devices less frequently or on a separate timer).
- The 3rd bus introduces either a new IC (bridge) or firmware fragility (bitbang).
- At 100Hz sensor rate, 10-19× oversampling provides diminishing returns over Option A's 8.5-10×.

---

## Comparison Summary

| | Current | Option A (2 bus, no TCA) | Option B1 (3 bus, bridge) |
|---|---|---|---|
| Components | TCA + 3 PCA | **3 PCA only** | Bridge + 3 PCA |
| Net component change | — | **-1 IC, -3 passives** | +1 IC (swap TCA for bridge) |
| Poll rate | 357 Hz | **850-1,020 Hz** | ~1,890 Hz |
| Oversampling (100Hz) | 3.6× | **8.5-10.2×** | 18.9× |
| Timestamp jitter | 2.8 ms | **~1.0-1.2 ms** | ~0.5 ms |
| Symmetric? | Yes | **Yes (sync)** | Yes (sync) |
| Fault isolation | Best (TCA) | Partial (per-bus) | Best (per-bus) |
| Firmware effort | Baseline | **Moderate** | High |
| Unique transit reads (30mph) | 3-4/sensor | 3-4/sensor | 3-4/sensor |

**The unique reading count is identical across all options** because the VCNL4040 sensor rate (100Hz at 2T/1/40) is the bottleneck. Bus speed improvements increase timestamp precision and oversampling ratio, not unique data density.

---

## Understanding Poll Rate vs Sensor Rate

These two rates are independent processes. Confusing them is easy, so this section clarifies.

### Process 1: Sensor Measurement (autonomous, parallel)

Each VCNL4040 has an internal clock. At 2T/1/40, it fires an IR pulse, measures the reflection, and writes the result to its `PS_DATA` register every ~10ms (100Hz). Then it does it again, forever, **independently of the I2C bus**. All 6 sensors do this **simultaneously in parallel** — no bus involvement.

### Process 2: ESP32 Polling (sequential, over I2C)

The ESP32 walks through each sensor one at a time: select PCA channel → read `PS_DATA` register → next sensor → ... → done → repeat. Each complete walk = one "poll cycle." The cycle time determines the poll rate.

### These Processes Are Decoupled

Reading a sensor's register is like glancing at a clock on a wall. Looking at it doesn't slow it down. Looking at it twice between ticks just shows the same time. The sensor updates its register at its own rate; the ESP32 reads it at a different rate.

### Timeline Visualization

A ~20ms window for one sensor. Sensor measurement ticks every 10ms. Poll ticks every 2.8ms (current) or ~1.0ms (dual bus):

**Current (single bus, 357 Hz poll rate):**

```
Time (ms):   0     2.8    5.6    8.4    10     12.8   15.6   18.4   20
Sensor:      ■──────────────────────────■──────────────────────────■───
             V1 (new measurement)       V2 (new measurement)       V3

ESP32 poll:  ●      ●      ●      ●      ●      ●      ●      ●
Value read:  V1     V1     V1     V1     V2     V2     V2     V2
             new!   stale  stale  stale  new!   stale  stale  stale
             └─── caught within 2.8ms ──┘
```

**Dual bus (no TCA, ~1,000 Hz poll rate):**

```
Time (ms):   0  1  2  3  4  5  6  7  8  9  10 11 12 13 14 15 16 17 18 19 20
Sensor:      ■─────────────────────────────■──────────────────────────────■
             V1                            V2                             V3

ESP32 poll:  ●  ●  ●  ●  ●  ●  ●  ●  ●  ●  ●  ●  ●  ●  ●  ●  ●  ●  ●  ●
Value read:  V1 V1 V1 V1 V1 V1 V1 V1 V1 V1 V2 V2 V2 V2 V2 V2 V2 V2 V2 V2
             new!                          new!
             └─── caught within 1.0ms ─────┘
```

**Same 2 unique readings (V1, V2) in both cases.** But the dual bus catches each one within ~1ms of it appearing, vs ~2.8ms. More polls = more stale reads, but each new reading is timestamped more precisely.

### What Each Rate Controls

| | Sensor rate (100Hz) | Poll rate (357→1000 Hz) |
|---|---|---|
| Determined by | VCNL4040 internal config (IT, duty cycle) | I2C bus speed, mux overhead, firmware |
| Controls | How many **unique** readings per second | How **quickly** each new reading is captured |
| For a 30mph transit | 3-4 unique data points per sensor | Doesn't change data point count |
| Improvement lever | Change sensor IC, or switch 2T→1T | Add I2C buses, remove TCA, optimize firmware |
| Analogy | How fast the clock ticks | How often you glance at the clock |

### Why the Dual Bus Still Matters

Even though it doesn't increase unique readings, faster polling improves:

1. **Timestamp precision**: Each unique reading is captured within ~1ms of its actual measurement, vs ~2.8ms. For direction detection (A vs B peak timing), this 3× improvement directly helps.
2. **Zero missed readings**: At 10× oversampling, it's impossible to miss a sensor update. At 3.6× oversampling, unlucky clock alignment could occasionally skip one.
3. **Firmware headroom**: Shorter cycles mean more CPU time for processing, ML inference, or future sensor upgrades with higher measurement rates.

---

## The Sensor Rate Bottleneck

This is the fundamental limit. Some paths to more unique readings per transit:

| Approach | Unique reads/sensor at 30mph | Effort | Notes |
|---|---|---|---|
| Current (2T/x8/1/40, 100Hz) | 3-4 | — | Baseline |
| Switch to 1T/x8/1/40 (200Hz) | 6-7 | Firmware config | Trades signal strength for rate; needs testing |
| Sub-sample interpolation | 3-4 raw, but ~0.5ms peak timing | Firmware algorithm | "Free" timing improvement on existing data |
| Different sensor IC (>200Hz) | Depends on sensor | New sensor boards | No I2C prox sensor >200Hz found on market |
| Analog IR sensing (LED+photodiode) | 50+ (at 1-5kHz ADC) | Major sensor redesign | Eliminates I2C bottleneck entirely |
| Local MCU per sensor board | 50+ (at kHz local ADC) | Major redesign | "Dream" architecture, digital over cables |

### 1T vs 2T Trade-off (Needs Investigation)

At 2T/x8/1/40 the sensor produces ~100Hz unique data. At 1T/x8/1/40 it would produce ~200Hz, doubling transit samples from 3-4 to 6-7. The user observed "1T→2T didn't affect sample rate" — this is the poll rate staying constant, not the unique data rate. The unique data rate did halve, but without deduplication in the firmware the change is invisible in raw counts.

**Question to test:** At 1T/x8/1/40, does the reduced signal strength (half of 2T) still provide adequate detection range at the hoop center (~250mm)? If yes, 1T doubles effective transit samples. The x8 multi-pulse provides 8× signal boost which may compensate for the shorter integration time.

---

## Other Changes Bundled with This Architecture Shift

### JST-SH 5-pin → 4-pin

With INT lines abandoned, connector becomes: 1=3.3V, 2=GND, 3=SDA, 4=SCL. Saves one wire per cable, removes D2/D3/R5 from rigid board, frees up 3 ESP32 GPIO pins (INT1/INT2/INT3).

### PCA Address Selection on Rigid Board

Current: solder bridge jumper pads (JP3/JP4). User wants a small switch for easier reconfiguration. Options:
- 2-position DIP switch (e.g., CTS 219-2): ~2.5mm height, LCSC available
- SMD slide switch per address bit: more board area but lower profile
- Keep solder jumpers but add silkscreen truth table for clarity

With the TCA removed, correct PCA addressing becomes critical (shared bus = address collision = bus failure). A switch makes field changes safer than jumper bridges.

---

## Open Questions

1. **What causes the 357 Hz vs 549 Hz poll rate gap?** Profile the firmware sensor loop to identify: ALS reads? BQ24195/INA219 reads? Task switching overhead? This affects projected performance of all options.
2. **Can BQ24195/INA219 be read outside the sensor loop?** Moving them to a separate, slower timer (e.g., 10Hz) would free ~200-400μs from the sensor cycle.
3. **1T vs 2T at center-of-hoop distance?** Test 1T/x8/1/40 for center detection range. If adequate, 2× improvement in unique transit samples.
4. **GPIO availability for I2C1?** Need to identify 2 free GPIOs for the second I2C bus that don't conflict with existing assignments (USB, boot strapping, etc.).
5. **PCA9546A address truth table?** Confirm the actual 7-bit addresses for each JP3/JP4 configuration to verify no conflicts with BQ24195 (0x6B) or INA219 (0x40) on Bus 0.

## Recommendation

**Option A (Dual I2C, No TCA)** is the clear winner for the next board revision:

- Removes a component instead of adding one
- 2.4-2.9× faster poll rate with better timestamp precision
- Zero sensor asymmetry in synchronous mode
- Moderate firmware effort (well-understood I2C APIs)
- Leaves the door open for a 3rd bus later if needed

Option B (Triple Bus) is a reasonable future step but offers diminishing returns at the current 100Hz sensor rate. Worth revisiting if sensor technology changes.

---

*Last Updated: March 22, 2026*

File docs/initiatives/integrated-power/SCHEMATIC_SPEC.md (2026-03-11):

# Integrated Power Management — Schematic Change Specification (Phase 2)

This document specifies every component, pin connection, net, and value needed to implement the integrated power management system on the main PCB. Implement in KiCad by following each section in order.

**Conventions:**
- All resistors are 0603 unless noted otherwise
- All ceramic capacitors are 0603 unless noted otherwise
- All capacitor voltage ratings ≥2× operating voltage unless noted
- Net names in `monospace` are exact KiCad net labels
- Pin numbers match datasheet/LCSC footprint conventions
- "→" denotes a direct electrical connection (same net)

---

## 1. Root Sheet Changes
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

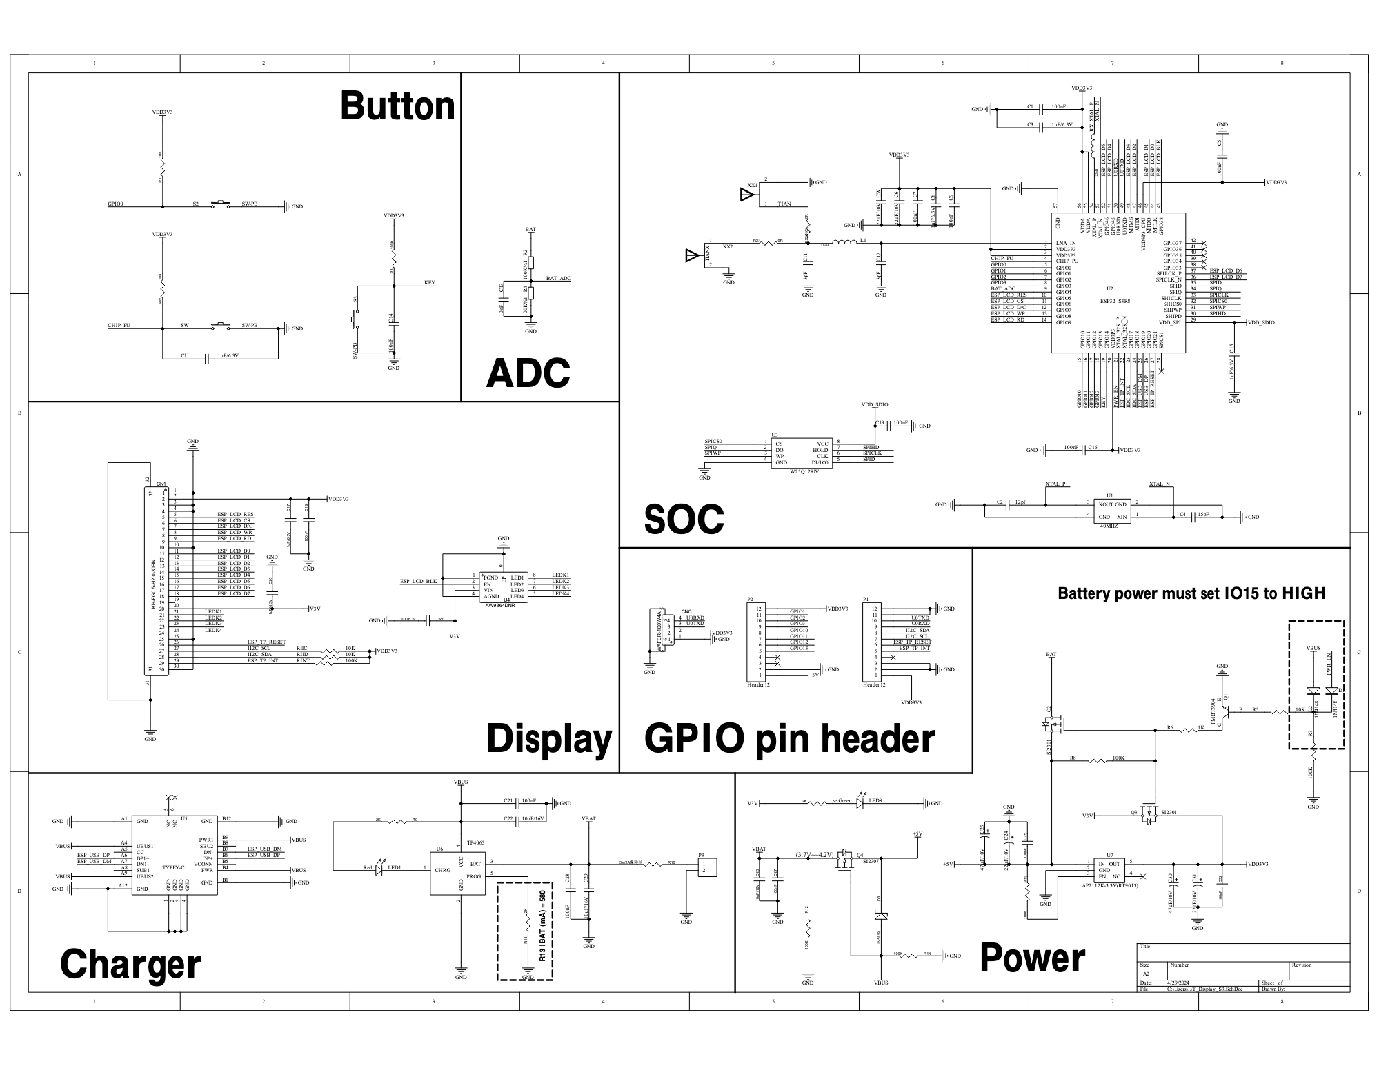
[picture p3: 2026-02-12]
hardware/sensor-alt-pt/components/t-display/t-display-s3-schematic.png

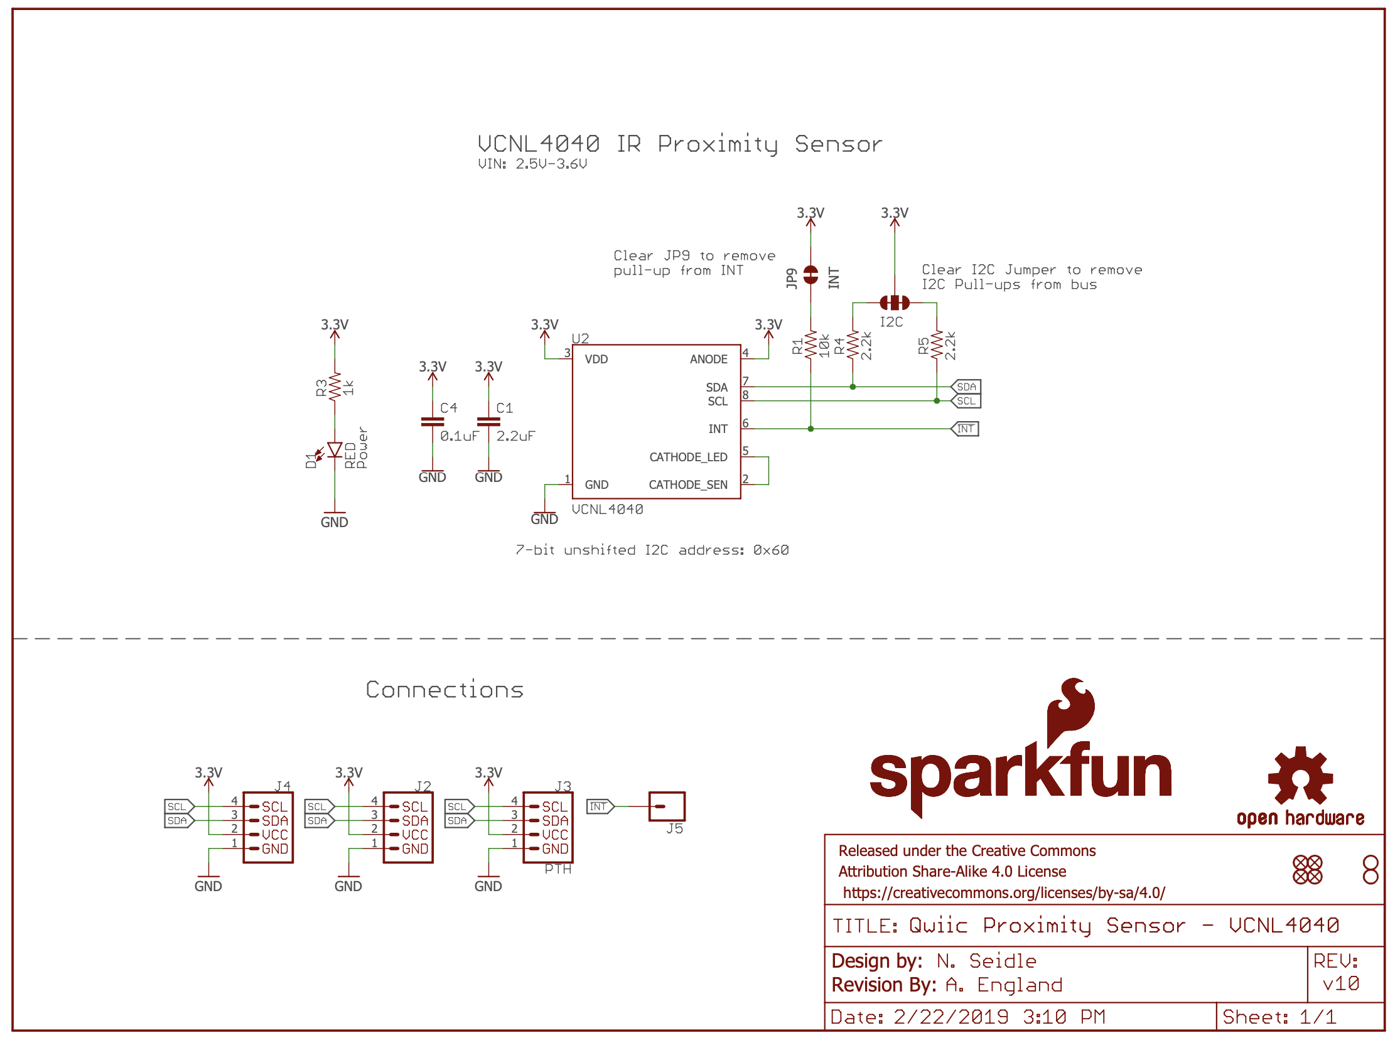
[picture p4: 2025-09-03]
hardware/components/vcnl4040/reference schematic/sparkfun/VCNL4040 Sparkfun reference schematic.png

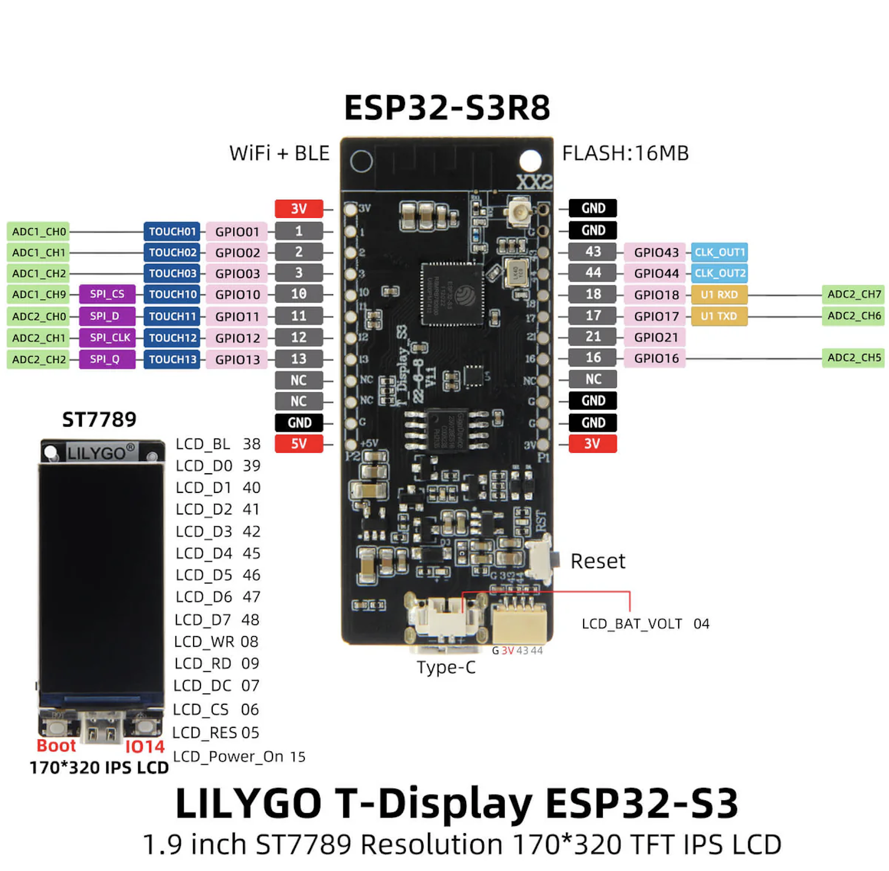
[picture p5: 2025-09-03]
hardware/components/t-display-s3/t-display-s3-pinout.png

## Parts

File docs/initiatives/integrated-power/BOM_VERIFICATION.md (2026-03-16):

# Integrated Power Management — BOM Verification & Assembly Review (Phase 5)

> Generated from `spec.json` and verified against LCSC/JLCPCB on March 11, 2026

## Summary

- **47 physical components** across 4 functional blocks + 4 test points (bare pads)
- **30 unique LCSC part numbers** (after deduplication)
- **3 BOM issues found** — all resolved with drop-in swaps (see §1)
- **5 cost optimization swaps** — extended → basic parts, saves ~$15 per assembly order
- **13 extended parts, 17 basic parts** after optimization
- **Estimated power section component cost:** ~$7.50 per board (at qty 5)

---

## 1. Critical Issues & Required Changes

### 1.1 ⚠️ PMOS Q2: Out of Stock — SWAP REQUIRED

| | Original | Replacement |
|---|---|---|
| **Ref** | Q2 | Q2 |
| **LCSC** | C3040193 (VBZ3401) | **C15127 (AO3401A)** |
| **Stock** | **3** (effectively OOS) | **904,777** |
| **Price** | $0.11 | $0.057 |
| **Library** | Extended | **Basic** (saves $3) |
| **Package** | SOT-23 | SOT-23 (drop-in) |
| **Specs** | 30V, 5.6A, 46mΩ | 30V, 4A, 47mΩ |

**Impact:** AO3401A has 4A continuous drain vs 5.6A for VBZ3401. This PMOS carries battery charge current (max configurable 4.5A on BQ24195, but we'll set 2-3A for Samsung 30Q). 4A rating is adequate for our use case. The lower RDS(on) difference is negligible (47mΩ vs 46mΩ).

### 1.2 ⚠️ 22µF Output Caps C34-C36: Footprint Mismatch — SWAP REQUIRED

| | Original | Replacement |
|---|---|---|
| **LCSC** | C59461 (CL10A226MQ8NRNC) | **C45783 (CL21A226MAQNNNE)** |
| **Package** | **0603** (mismatch with 0805 footprint!) | **0805** (correct) |
| **Voltage** | 6.3V | **25V** (5x improvement) |
| **Stock** | 19.7M | **4.4M** |
| **Price** | $0.0095 | $0.031 |
| **Library** | Basic | **Basic** |

**Impact:** The original C59461 is physically a 0603 cap but `spec.json` specifies `C_0805_2012Metric` footprint — these are incompatible sizes. C45783 is a proper 0805 part. The 25V rating (vs 6.3V) also provides much better voltage margin for the 5V boost output and improves capacitance stability under DC bias.

### 1.3 ⚠️ BQ24195RGER C90862: Low Stock Warning

| Detail | Value |
|---|---|
| **Current stock** | **24 units** |
| **Needed per board** | 1 |
| **For 5-board order** | 5 units (OK, but tight) |

Stock is sufficient for a small order but leaves no margin for reorders. The fallback part BQ25896RTWR (C181475, 113 units, $1.71) is pin-incompatible and would require schematic changes. **Recommendation:** Order promptly. If stock drops to zero, the RGET variant or a different lot may restock.

---

## 2. Cost Optimization — Extended → Basic Swaps

These swaps maintain identical electrical specs while saving $3/each in JLCPCB extended part surcharges:

| Refs | Value | Original LCSC | → Optimized LCSC | Savings |
|---|---|---|---|---|
| R33, R34, R41, R42 | 100kΩ 0603 | C14675 (extended) | **C25803** (basic) | $3 |
| C23, C37 | 47nF 0603 | C107093 (extended) | **C1622** (basic) | $3 |
| C38 | 4.7nF 0603 | C1621 (extended) | **C53987** (basic) | $3 |
| C34, C35, C36 | 22µF 0805 | C59461 (wrong pkg) | **C45783** (basic) | $3 |
| Q2 | PMOS SOT-23 | C3040193 (extended) | **C15127** (basic) | $3 |

**Total extended part surcharge savings: ~$15 per order**

---

## 3. Complete BOM — Power Management Section

### 3.1 ICs (3 unique parts — all Extended)

| Ref | Value | LCSC | Package | Stock | Price | Type |
|-----|---|---|---|---|---|---|
| U5 | BQ24195RGER | C90862 | VQFN-24-EP (4×4mm) | 24 | $2.31 | Extended |
| U6 | TPS61088RHLR | C87357 | VQFN-20-EP (3.6×4.6mm) | 4,959 | $1.08 | Extended |
| U7 | INA219AIDCNR | C87469 | SOT-23-8 | 7,253 | $0.58 | Extended |

### 3.2 Discrete Semiconductor (1 unique part — Basic)

| Ref | Value | LCSC | Package | Stock | Price | Type |
|-----|---|---|---|---|---|---|
| Q2 | AO3401A PMOS | **C15127** | SOT-23 | 904,777 | $0.057 | Basic |

### 3.3 Connectors (2 unique parts — Extended)

| Ref | Value | LCSC | Package | Stock | Price | Type |
|-----|---|---|---|---|---|---|
| J7 | TYPE-C-31-M-12 | C165948 | SMD 16P | 191,906 | $0.18 | Extended |
| J8 | JST PH 2-pin | C18221575 | SMD P=2mm | 830 | $0.03 | Extended |

### 3.4 Inductors (2 unique parts — Extended)

| Ref | Value | LCSC | Package | Stock | Price | Type |
|-----|---|---|---|---|---|---|
| L1 | 2.2µH (BQ24195 switching) | C266426 | SMD 6×6mm | 737 | $0.09 | Extended |
| L2 | 2.2µH 10A (TPS61088 boost) | C167218 | SMD 7×6.6mm | 109,622 | $0.10 | Extended |

### 3.5 Resistors (11 unique values, 15 instances)

| Ref(s) | Value | LCSC | Qty | Stock | Price | Type |
|---|---|---|-----|---|---|---|
| R30, R31 | 5.1kΩ | C23186 | 2 | 4.1M | $0.0014 | Basic |
| R32 | 330Ω | C23138 | 1 | 2.4M | $0.0015 | Basic |
| R33, R34, R41, R42 | 100kΩ | **C25803** | 4 | 5.1M | $0.0014 | Basic |
| R35, R38 | 10kΩ | C25804 | 2 | 29.4M | $0.0013 | Basic |
| R36 | 5.6kΩ | C23189 | 1 | 1.2M | $0.0012 | Basic |
| R37 | 30kΩ | C22984 | 1 | 721K | $0.0014 | Basic |
| R39 | 180kΩ | C22827 | 1 | 96K | $0.0015 | Extended |
| R40 | 56kΩ | C23206 | 1 | 1.3M | $0.0013 | Basic |
| R43 | 22kΩ | C31850 | 1 | 1.6M | $0.0016 | Basic |
| R44 | 10mΩ 2512 | C1322424 | 1 | 4,470 | $0.078 | Extended |
| TH1 | 10kΩ NTC | C13564 | 1 | 466K | $0.038 | Extended |

### 3.6 Capacitors (10 unique values, 21 instances)

| Ref(s) | Value | LCSC | Qty | Pkg | Stock | Price | Type |
|---|---|---|-----|-----|---|---|---|
| C20 | 1µF | C15849 | 1 | 0603 | 7.5M | $0.0072 | Basic |
| C21, C24 | 4.7µF | C19666 | 2 | 0603 | 6.6M | $0.010 | Basic |
| C25, C26, C27, C28 | 10µF 25V | C96446 | 4 | 0603 | 13.8M | $0.018 | Basic |
| C31, C32, C40 | 100nF | C14663 | 3 | 0603 | 47.1M | $0.0027 | Basic |
| C33 | 2.2µF | C23630 | 1 | 0603 | 5.9M | $0.0062 | Basic |
| C23, C37 | 47nF | **C1622** | 2 | 0603 | 2.6M | $0.0053 | Basic |
| C38 | 4.7nF | **C53987** | 1 | 0603 | 276K | $0.0034 | Basic |
| C39 | 100pF | C14858 | 1 | 0603 | 7.3M | $0.0041 | Basic |
| C34, C35, C36 | 22µF 25V | **C45783** | 3 | 0805 | 4.4M | $0.031 | Basic |
| C41 | 10µF 25V | C15850 | 1 | 0805 | 3.9M | $0.020 | Basic |

### 3.7 Electrolytic Capacitors (2 unique parts — Extended)

| Ref(s) | Value | LCSC | Qty | Package | Stock | Price | Type |
|---|---|---|-----|---|---|---|---|
| C22, C30 | 47µF 35V | C2836440 | 2 | D6.3×L5.4mm | 209K | $0.032 | Extended |
| C29 | 220µF 16V | C3342 | 1 | D6.3×L7.7mm | 87K | $0.035 | Extended |

### 3.8 Fuse (1 unique part — Extended)

| Ref | Value | LCSC | Package | Stock | Price | Type |
|-----|---|---|---|---|---|---|
| F2 | 3A PTC | C2897466 | 1206 | 20K | $0.088 | Extended |

### 3.9 Test Points (not assembled — bare copper pads)

| Ref | Net | Footprint |
|-----|-----|---|
| TP1 | VSYS | TestPoint_Pad_D1.5mm |
| TP2 | VBAT | TestPoint_Pad_D1.5mm |
| TP3 | Protected_VBUS | TestPoint_Pad_D1.5mm |
| TP4 | GND | TestPoint_Pad_D1.5mm |

### 3.10 Non-physical (ERC only — not in BOM)

#FLG05, #FLG06, #FLG07, #FLG08 — PWR_FLAG symbols (no footprint, schematic-only)

---

## 4. JLCPCB Assembly Capability Review

### 4.1 Package Compatibility

All packages are standard SMT that JLCPCB assembles routinely:

| Package | Components | JLCPCB Status |
|---|---|---|
| VQFN-24-EP (4×4mm, 0.5mm pitch) | U5 (BQ24195) | ✅ Standard — requires paste stencil for exposed pad |
| VQFN-20-EP (3.6×4.6mm, 0.5mm pitch) | U6 (TPS61088) | ✅ Standard — requires paste stencil for exposed pad |
| SOT-23-8 | U7 (INA219) | ✅ Standard |
| SOT-23 | Q2 (PMOS) | ✅ Standard |
| 0603 passives | 28 components | ✅ Standard |
| 0805 passives | 4 components | ✅ Standard |
| 2512 resistor | R44 (shunt) | ✅ Standard |
| 1206 fuse | F2 | ✅ Standard |
| SMD electrolytic (6.3mm dia) | C22, C29, C30 | ✅ Standard |
| SMD inductor (6×6mm) | L1 | ✅ Standard |
| SMD inductor (7×6.6mm) | L2 | ✅ Standard |
| USB-C SMD connector | J7 | ✅ Standard (16-pin, may need manual orientation check) |
| JST PH SMD | J8 | ✅ Standard |

**No BGA, through-hole, or fine-pitch (<0.4mm) packages.** All components are single-side SMT compatible.

### 4.2 Extended vs Basic Part Count

| Category | Count | Surcharge |
|---|---|---|
| Basic parts | 17 unique | $0 |
| Extended parts | 13 unique | $3 × 13 = **$39** |
| **Total unique LCSC parts** | **30** | **$39 extended surcharge** |

**Extended parts breakdown:**
1. C90862 — BQ24195RGER (IC)
2. C87357 — TPS61088RHLR (IC)
3. C87469 — INA219AIDCNR (IC)
4. C165948 — USB-C connector
5. C18221575 — JST PH connector
6. C266426 — 2.2µH inductor (BQ24195)
7. C167218 — 2.2µH 10A inductor (TPS61088)
8. C2836440 — 47µF electrolytic
9. C3342 — 220µF electrolytic
10. C1322424 — 10mΩ shunt resistor
11. C13564 — 10kΩ NTC thermistor
12. C22827 — 180kΩ resistor (FB divider)
13. C2897466 — 3A resettable fuse

### 4.3 Thermal Pad Notes

U5 (BQ24195) and U6 (TPS61088) have exposed thermal pads (EP). JLCPCB handles these via solder paste stencil openings. Ensure the KiCad footprint has proper paste mask definition for the EP. The easyeda2kicad-installed footprints should include this.

---

## 5. Estimated Per-Board Cost (Power Section Only)

| Line Item | Cost |
|---|---|
| ICs (U5 + U6 + U7) | $3.97 |
| PMOS (Q2) | $0.06 |
| Connectors (J7 + J8) | $0.21 |
| Inductors (L1 + L2) | $0.19 |
| Resistors (15 pcs) | $0.11 |
| Capacitors (21 pcs ceramic) | $0.30 |
| Electrolytic caps (3 pcs) | $0.10 |
| Fuse (F2) | $0.09 |
| **Component total** | **~$5.03** |
| Extended part surcharge (13 × $3, amortized over 5 boards) | ~$7.80 |
| **Per-board total (components + surcharge)** | **~$12.83** |

*Assembly labor, PCB fabrication, and shipping are additional.*

---

## 6. Changes Required in spec.json

Before generating the final assembly BOM, update these LCSC numbers in `spec.json`:

| Ref(s) | Field | Old Value | New Value | Reason |
|---|---|---|---|---|
| Q2 | lcsc | C3040193 | **C15127** | OOS → AO3401A (basic, in stock) |
| C34, C35, C36 | lcsc | C59461 | **C45783** | Footprint mismatch fix (0603→0805) |
| R33, R34, R41, R42 | lcsc | C14675 | **C25803** | Extended → basic optimization |
| C23, C37 | lcsc | C107093 | **C1622** | Extended → basic optimization |
| C38 | lcsc | C1621 | **C53987** | Extended → basic optimization |

---

## 7. Pre-Order Checklist

- [ ] Apply spec.json LCSC changes from §6
- [ ] Regenerate `power_management.kicad_sch` (if LCSC field is embedded in schematic)
- [ ] Complete PCB layout (boost converter proximity, thermal pours, trace widths)
- [ ] Export Gerbers + drill files from KiCad
- [ ] Export BOM CSV (Ref, Value, Footprint, LCSC) and CPL (component placement) from KiCad
- [ ] Upload to JLCPCB: Gerbers → BOM → CPL
- [ ] Verify component orientation in JLCPCB preview (especially J7 USB-C, U5, U6)
- [ ] Confirm BQ24195 (C90862) is still in stock at order time
- [ ] Select assembly options: single-side SMT, economic assembly
- [ ] Order qty 5 (minimum for JLCPCB SMT assembly)

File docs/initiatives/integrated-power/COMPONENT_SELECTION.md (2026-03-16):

# Integrated Power Management — Component Selection (Phase 1)

## Active ICs — Confirmed via JLCPCB MCP

| Component | Part Number | LCSC | Stock | Price | Package | Library |
|---|---|---|---|---|---|---|
| Boost Converter | TPS61088RHLR | C87357 | 4,972 | $1.08 | VQFN-20-EP (3.6×4.6mm) | Extended |
| Battery Charger | BQ24195RGER | C90862 | 24 | $2.30 | VQFN-24-EP (4×4mm) | Extended |
| Power Monitor | INA219AIDCNR | C87469 | 7,586 | $0.58 | SOT-23-8 | Extended |

**Fallback charger:** BQ25896RTWR (C181475) — 113 units, $1.71, QFN-24-EP (4×4mm). Pin-incompatible with BQ24195 but similar I2C register set. Only needed if BQ24195RGER stock drops to zero.

**Note on BQ24195 variants:** The RGET variant (C2876710) used in the reference power PCB is out of stock (0 units). RGER is identical silicon, different packaging tape — no design changes needed.

## Critical Design Finding: Boot-Time Input Current Limit

The PLAN.md assumed ~1-1.5A boot-time input current from the 2.7kΩ ILIM resistor. **This is incorrect.** Datasheet analysis reveals:

1. **ILIM with 2.7kΩ:** Formula gives ~180mA, clamped at internal 500mA floor
2. **D+/D- grounded + OTG LOW:** Detects as USB SDP → I2C default = 100mA
3. **Effective boot limit = min(ILIM, I2C) = 100mA** — far too low for system boot

At 100mA from VBUS, available power at the +5V rail is ~400mW (after BQ24195 and boost losses). The ESP32-S3 alone needs ~600mW+ to boot. **The system cannot boot on USB-only with these settings.**

### Resolution

Change two components from the reference design:

| Change | Reference Design | New Design | Rationale |
|---|---|---|---|
| **ILIM resistor** | 2.7kΩ (R6) | **330Ω** | Sets hardware ceiling at ~1.5A (KILIM/RILIM = 485/330 = 1.47A) |
| **OTG pin** | Tied to GND | **Tied to VCC (3.3V) via 10kΩ** | SDP detection with OTG HIGH → 500mA boot current |

Post-fix boot sequence:
- Boot: 500mA from VBUS (~2.1W at +5V rail) — sufficient for ESP32 + boost converter startup
- Firmware writes REG00[2:0] = 101 (1.5A) → clamped by ILIM hardware limit at 1.5A
- Full system operational on USB-only at 1.5A input (7.5W available at VBUS)

**Safety note:** OTG HIGH in default charge mode (CHG_CONFIG=01) only affects SDP current selection. It does NOT enable boost output — that requires CHG_CONFIG=10, which is never set in our firmware.

## Boost Converter: TPS61088 — Passive Values

### Feedback Divider (sets VOUT = 5.07V)

| Ref | Value | LCSC | Stock | Price | Part | Notes |
|-----|---|---|---|---|---|---|
| R_FB_TOP | 180kΩ 1% 0603 | C22827 | 114,474 | $0.002 | 0603WAF1803T5E | Extended |
| R_FB_BOT | 56kΩ 1% 0603 | C23206 | 1,263,866 | $0.001 | 0603WAF5602T5E | Basic |

Formula: VOUT = VREF × (1 + R_TOP/R_BOT) = 1.204 × (1 + 180/56) = 1.204 × 4.214 = **5.07V**

Acceptable — 1.4% above nominal 5.0V. Within WS2812B operating range (4.5-5.5V) and AP2112K input range.

### Inductor

| Ref | Value | LCSC | Stock | Price | Part | Package |
|-----|---|---|---|---|---|---|
| L_BOOST | 2.2µH, 10A Isat, 15mΩ DCR | C167218 | 110,139 | $0.10 | FXL0630-2R2-M | 7.0×6.6mm |

Peak inductor current at worst case (VIN=3.0V, VOUT=5V, IOUT=3A, η=85%): ~5.9A DC + ~0.25A ripple = **6.15A peak**. The 10A Isat provides 63% margin. The TPS61088 datasheet recommends ≥12A for the 9V/3A reference design, but for 5V/3A the input current is 40% lower — 10A Isat is adequate.

### Capacitors

| Ref | Value | LCSC | Notes |
|-----|---|---|---|
| C_VIN | 10µF ceramic 0805 X5R 10V | C15850 | Input power stage decoupling (from reference BQ24195 circuitry) |
| C_VIN_BYP | 0.1µF ceramic 0603 X7R | C14663 | VIN pin bypass, close to IC |
| C_BOOT | 0.1µF ceramic 0603 X7R | C14663 | BOOT to SW bootstrap |
| C_VCC | 2.2µF ceramic 0603 X5R | C23630 | Internal LDO decoupling |
| C_OUT (×3) | 22µF ceramic 0805 X5R 10V | C59461 | Output filtering (66µF total nominal) |
| C_SS | 47nF ceramic 0603 | — | Soft-start (~11ms ramp) |

### Other Passives

| Ref | Value | LCSC | Notes |
|-----|---|---|---|
| R_FREQ | 100kΩ 1% 0603 | C14675 | FSW→SW, sets ~2.2MHz switching frequency |
| R_ILIM_BOOST | 100kΩ 1% 0603 | C14675 | ILIM→AGND, sets 11.9A peak current limit |
| R_COMP | TBD | — | Loop compensation — value depends on load; use TPS61088 EVM values initially |
| C_COMP1 | TBD | — | Loop compensation |
| C_COMP2 | TBD | — | Loop compensation |

**Note:** Compensation network values (R_COMP, C_COMP1, C_COMP2) will be taken from the TPS61088 EVM reference design for 5V output during Phase 2 schematic spec. The TI WEBENCH tool can also calculate these.

## Battery Charger: BQ24195 — Passive Values

Carried forward from the reference power supply PCB (`hardware/pcb-power-supply/kicad/circuit-context.json`) with one change (ILIM resistor).

| Ref | Value | LCSC | Function | Changed? |
|-----|---|---|---|---|
| C_BTST | 47nF (0.047µF) | — | Bootstrap cap, BTST→SW | Same (was 100nF in ref — datasheet says 47nF) |
| C_REGN | 4.7µF ceramic 0603 | C19666 | REGN internal LDO bypass | Same |
| C_PMID | 10µF ceramic 0603 | C96446 | PMID bypass (min 20µF recommended — may need 2×) | Review |
| C_VSYS (×2) | 10µF ceramic 0603 | C96446 | VSYS output decoupling | Same |
| C_VSYS_BULK | 220µF electrolytic | C3342 | VSYS bulk output | Same |
| C_VBUS | 1µF ceramic 0603 | C15849 | VBUS input bypass | Same |
| C_BAT | 47µF electrolytic | C2836440 | Battery terminal bulk | Same |
| L_BQ | 2.2µH (FNR6028S) | C266426 | BQ24195 switching inductor | Same |
| **R_ILIM** | **330Ω 1% 0603** | **C23138** | **ILIM resistor (~1.5A)** | **CHANGED from 2.7kΩ** |
| R_PMOS1 | 100kΩ 0603 | C14675 | PMOS gate bias (VBAT side) | Same |
| R_PMOS2 | 100kΩ 0603 | C14675 | PMOS gate bias (raw battery side) | Same |
| Q_PMOS | AO3401A SOT-23 PMOS | **C15127** | Battery reverse polarity protection | **CHANGED — C3040193 OOS (3 units), swapped to AO3401A (904K stock, basic)** |
| TH_NTC | 10kΩ NTC 0603 | C13564 | Battery temperature monitoring | Same |

### Bootstrap Cap Discrepancy

The reference design uses 100nF for C_BTST (C3 in circuit-context.json: "100nF"). The BQ24195 datasheet specifies **47nF**. The reference design value works (larger bootstrap cap is generally fine), but we should use the datasheet-recommended 47nF for the new design.

### PMID Capacitance

The reference design has only one 10µF on PMID (C4). The BQ24195 datasheet recommends **20µF minimum** (60µF for full load support). We should increase to 2× 10µF (20µF total) or add a 22µF ceramic.

## Power Monitor: INA219 — Passive Values

| Ref | Value | LCSC | Function |
|-----|---|---|---|
| R_SHUNT | 10mΩ 1% 2512 1W | C1322424 | Current sense resistor on VSYS rail |
| C_VS | 0.1µF ceramic 0603 | C14663 | VS power supply bypass |

**Shunt resistor selection:** FH MFJ12HR010FT (C1322424) — 10mΩ, 1W, ±1%, ±50ppm/°C, 2512 package. 6,477 in stock at $0.08.

- PGA setting: /2 (±80mV range)
- Max measurable current: 80mV / 10mΩ = 8A (33% headroom over 6A max)
- Power dissipation at 6A: 0.36W (within 1W rating)
- Voltage drop at 6A: 60mV (2% of 3.0V minimum VSYS)
- Current resolution: 1 mA/LSB
- Calibration register: 0x1000 (4096)
- I2C address: 0x40 (A0=GND, A1=GND — no conflicts with TCA9548A at 0x70 or BQ24195 at 0x6B)

## USB-C Input — Passive Values

Carried from reference design, minus STUSB4500 and USBLC6-2SC6.

| Ref | Value | LCSC | Function |
|-----|---|---|---|
| USBC1 | TYPE-C-31-M-12 | C165948 | USB-C connector |
| F_VBUS | 3A 1206 fuse | C2897466 | VBUS overcurrent protection |
| R_CC1 | 5.1kΩ 0603 | C23186 | CC1 pull-down (UFP sink) |
| R_CC2 | 5.1kΩ 0603 | C23186 | CC2 pull-down (UFP sink) |
| C_PVBUS_CERAMIC | 4.7µF ceramic 0603 | C19666 | Protected_VBUS decoupling |
| C_PVBUS_BULK | 47µF electrolytic 6.3×5.4 | C2836440 | Protected_VBUS bulk decoupling |

## Board Area Estimate

### New Components (not on current main PCB)

| Block | Components | Footprint Area | Notes |
|---|---|---|---|
| USB-C connector | 1 IC | ~9.0 × 7.3mm = 65mm² | TYPE-C-31-M-12 |
| BQ24195 + support | 1 IC + ~15 passives | ~4×4mm IC + ~25mm² passives = 41mm² | Includes inductor, caps, NTC, PMOS, resistors |
| BQ24195 inductor | L_BQ (FNR6028S) | 6.4 × 2.8mm = 18mm² | Separate from IC area |
| TPS61088 + support | 1 IC + ~12 passives | ~4.5×3.5mm IC + ~20mm² passives = 36mm² | Includes comp network |
| Boost inductor | L_BOOST (FXL0630) | 7.0 × 6.6mm = 46mm² | Largest single component |
| Boost output caps (×3) | 3× 22µF 0805 | 3 × 3.2mm² = 10mm² | |
| INA219 + shunt | 1 IC + 2 passives | SOT-23-8 + 2512 = 20mm² | |
| VSYS bulk cap | 220µF electrolytic | 6.3 × 7.7mm = 49mm² | Tallest component |
| Battery connector | JST PH 2-pin | ~7 × 5mm = 35mm² | |
| Test points (×4-6) | 1.5mm pads | ~12mm² | VSYS, VBAT, VBUS, GND |
| **Total new footprint area** | | **~332mm²** | |

### Clearance and Routing Overhead

Component-only area: ~332mm². With clearance, routing channels, and thermal copper pours, multiply by ~2.5×:

**Estimated power block area: ~830mm² ≈ 8.3cm²**

### Current Main PCB

Board size: 85mm × 45mm = 3,825mm² total. Usable area (after edge clearance): ~3,400mm². Current component density leaves approximately 30-40% open area for routing/expansion.

**Available area for power block: ~1,000-1,400mm²**

The estimated 830mm² power block fits within available area, but it will be tight — the power block consumes roughly 60-80% of the available expansion space. The DWEII module removal (~12×12mm = 144mm²) and Schottky D1 removal (~5mm²) free about 150mm² additional space.

**Verdict: The power block fits on the current 85mm × 45mm board**, but leaves minimal room for future expansion. If layout proves too cramped (especially for thermal copper pours under the boost converter and BQ24195), consider growing the board to **90mm × 50mm** (4,500mm²), which would provide comfortable margins. Flag this during Phase 3 layout.

## GPIO Allocation: BQ24195 INT

### Available GPIOs on T-Display-S3 (from main PCB circuit-context)

| GPIO | Current Assignment | Net Name | Test Point |
|---|---|---|---|
| 1 | Unused breakout | Net-(U2-1) | TPIO1 |
| 2 | Unused breakout | Net-(U2-2) | TPIO2 |
| 3 | Unused breakout | Net-(U2-3) | TPIO3 |
| 17 | Unused breakout | Net-(U2-17) | TPIO17 |
| 18 | Unused breakout | Net-(U2-18) | TPIO18 |
| 21 | Unused breakout | Net-(U2-21) | TPIO21 |

### Selection Criteria

- BQ24195 INT is active-low, open-drain, 256µs pulse on status/fault events
- Needs internal pull-up or external pull-up to 3.3V
- Should support GPIO interrupt (falling edge) on ESP32-S3
- No conflict with existing signals
- Physical proximity on T-Display-S3 header to the power block area of the PCB

### Recommendation: **GPIO 21**

- Pin 19 on T-Display-S3 header (close to other I2C pins 43/44 at pins 15/16)
- No known ESP32-S3 special functions on GPIO 21 that would conflict
- All candidate GPIOs support edge interrupts, so any would work electrically
- GPIO 21 is at the end of the header, adjacent to GPIO 16 (LED data) — routing to the power block (near the USB-C end of the board) should be straightforward
- Preserves GPIO 1-3 as a contiguous group for future use (e.g., SPI, UART, or additional sensors)
- Preserves GPIO 17-18 as a pair for future use

**Allocated: GPIO 21 → BQ24195 INT (active-low, 10kΩ pull-up to 3.3V)**

## Battery-Absent Operation — Datasheet Validation

### BQ24195 Behavior Without Battery

The BQ24195 **explicitly supports battery-absent operation** ("Instant-on Works with No Battery or Deeply Discharged Battery"):

1. **VSYS regulation:** VSYS is regulated from VBUS at VSYS_MIN + 150mV. With default VSYS_MIN = 3.5V → **VSYS ≈ 3.65V** (range 3.55–3.65V).

2. **Load current capability:** Limited by the input current limit (min of ILIM hardware and I2C register). With our revised ILIM (330Ω → 1.5A) and OTG HIGH (500mA SDP boot), the system gets:
   - Boot: 500mA input → ~2.1W at +5V (after losses) → sufficient for ESP32 startup
   - Post-firmware: 1.5A input → ~6.3W at +5V → sufficient for full operation minus LEDs at high brightness

3. **Recommended firmware configuration:** Set REG07[5] = 1 (BATFET_Disable) when no battery is detected. This prevents the charger from trying to charge a non-existent battery.

4. **Startup sequence:** During initial startup (VSYS < 2.2V), input current is forced to 100mA regardless of ILIM/register settings. Once VSYS rises above 2.2V, the configured limit applies. This 100mA phase is brief (~ms) as VSYS capacitors charge.

5. **VSYS_STAT bit:** REG08[0] goes high when the system is in minimum system voltage regulation (battery-absent or deeply depleted) — firmware can detect this.

### Current Budget on USB-Only (Battery-Absent)

| Parameter | Value |
|---|---|
| VBUS input | 5V |
| Input current limit (after firmware config) | 1.5A |
| Input power | 7.5W |
| BQ24195 efficiency (buck to VSYS) | ~92% |
| VSYS power | ~6.9W |
| Boost efficiency (VSYS → +5V) | ~90% |
| Available at +5V | ~6.2W = **1.24A at 5V** |

| Load | Current at 5V |
|---|---|
| ESP32-S3 + LCD (active WiFi) | ~200mA |
| 3.3V rail (sensors, muxes) | ~5mA |
| LEDs (moderate, 30% duty) | ~500mA |
| Level shifter | ~1mA |
| **Total** | **~706mA** |

**1.24A available > 706mA required → USB-only operation is viable** with moderate LED brightness. Full LED brightness (1.8A) would exceed the budget — firmware should limit LED duty when on USB-only power.

### Validation Result

**Battery-absent operation is confirmed viable.** The BQ24195 natively supports it, VSYS stays regulated, and our revised ILIM/OTG configuration provides sufficient input current for the system to boot and operate at moderate loads. Firmware must:
1. Detect battery-absent via REG08[0] (VSYS_STAT)
2. Set BATFET_Disable (REG07[5] = 1)
3. Limit LED brightness to stay within input current budget

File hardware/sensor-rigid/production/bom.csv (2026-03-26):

Designator | Footprint | Quantity | Value | LCSC Part #
C1 | 0603 | 1 | 2.2µF | C23630
C2 | 0603 | 1 | 0.1µF | C14663
D1 | 0603 | 1 | LED | C19171301
FPC1 | FPC-SMD_8P-P1.00_FPC1.0-8P-SJ | 1 | FPC1.0-8P | C132510
J1 | JST_SH_SM04B-SRSS-TB_1x04-1MP_P1.00mm_Horizontal | 1 | Conn_01x04 | C160404
R1, R2, R6, R7, R8, R9 | 0603 | 6 | 4.7kΩ | C99782
R12, R13, R14, R3 | 0603 | 4 | 10kΩ | C25804
R4 | 0603 | 1 | 1kΩ | C22548
SW1 | SW-SMD_EP-02KS | 1 | EP-02KS | C129087
TP1 | TestPoint_Pad_D1.5mm | 1 | 3V3
TP2 | TestPoint_Pad_D1.5mm | 1 | GND
TP3 | TestPoint_Pad_D1.5mm | 1 | SDA_UP
TP4 | TestPoint_Pad_D1.5mm | 1 | SCL_UP
U1 | SOP65P640X120-16N | 1 | PCA9546APWR | C400705

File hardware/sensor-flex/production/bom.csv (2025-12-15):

Designator | Footprint | Quantity | Value | LCSC Part #
C4, C8 | 0603 | 2 | 2.2µF | C23630
C6, C7 | 0603 | 2 | 0.1µF | C14663
IC1, IC2 | VCNL4040M3OE | 2 | VCNL4040M3OE | C142526
R10, R11 | 0603 | 2 | 22Ω | C23345

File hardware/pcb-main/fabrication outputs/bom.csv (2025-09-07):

Designator | Footprint | Quantity | Value | LCSC Part #
1, 10, 11, 12, 13, 16, 17, 18, 2, 21, 3, 43, 44, SCL, SDA | TestPoint_Pad_D2.0mm | 15 | TestPoint
C1 | 603 | 1 | 10µF | C76614
C2 | 603 | 1 | 22µF | C22367828
C3, C4 | 603 | 2 | 0.1µF | C14663
D1 | D_SMA | 1 | D_Schottky | C2480
J10 | JST_SH_SM02B-SRSS-TB_1x02-1MP_P1.00mm_Horizontal | 1 | Conn_01x02 | C160402
J2 | USBC_Power_Module | 1 | ~
J3 | JST_PH_S3B-PH-SM4-TB_1x03-1MP_P2.00mm_Horizontal | 1 | LED_Strip | C265101
J4, J5, J6, J7, J8, J9 | JST_SH_SM03B-SRSS-TB_1x03-1MP_P1.00mm_Horizontal | 6 | Conn_01x03 | C2845362
R10, R11, R12, R13, R14, R15, R16, R17, R18, R19, R20, R21 | 603 | 12 | 100Ω | C105588
R3, R4, R5, R7, R8, R9 | 603 | 6 | 10kΩ | C25804
R6 | 603 | 1 | 10kΩ
U3 | SOP65P640X120-24N | 1 | TCA9548APWR | C130026
U4 | SOT229P700X180-4N | 1 | AMS1117-3.3 | C6186

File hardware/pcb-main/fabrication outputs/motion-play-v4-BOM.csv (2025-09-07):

motion-play-v3-BOM
Comment | Designator | Footprint | LCSC Part Number
10µF Unpolarized capacitor | C1 | C_0603_1608Metric | C76614
22µF Unpolarized capacitor | C2 | C_0603_1608Metric | C22367828
0.1µF Unpolarized capacitor | C3,C4 | C_0603_1608Metric | C14663
D_Schottky Schottky diode | D1 | D_SMA | C2480
PH 2mm 3-pin connector horizontal | J3 | JST_PH_S3B-PH-SM4-TB_1x03-1MP_P2.00mm_Horizontal | C265101
SH 1mm 3-pin connector horizontal | J4,J5,J6,J7,J8,J9 | JST_SH_SM03B-SRSS-TB_1x03-1MP_P1.00mm_Horizontal | C160403
SH 1mm 2-pin connector horizontal | J10 | JST_SH_SM02B-SRSS-TB_1x02-1MP_P1.00mm_Horizontal | C2845362
4.7kΩ Resistor | R1,R2 | R_0603_1608Metric | C23162
10kΩ Resistor | R3,R4,R5,R6,R7,R8,R9 | R_0603_1608Metric | C25804
100Ω Resistor | R10,R11,R12,R13,R14,R15,R16,R17,R18,R19,R20,R21 | R_0603_1608Metric | C22775
TCA9548APWR | U3 | SOP65P640X120-24N | C130026
AMS1117-3.3 | U4 | SOT229P700X180-4N | C6186

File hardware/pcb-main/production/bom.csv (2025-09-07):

Designator | Footprint | Quantity | Value | LCSC Part #
C1 | C_0805_2012Metric | 1 | 22µF 25V ceramic | C45783
C1A | C_0603_1608Metric | 1 | 0.1µF ceramic | C14663
C2, C2A, C2B | C_0805_2012Metric | 3 | 22µF 10V ceramic | C159204
C3 | C_0603_1608Metric | 1 | 1µF ceramic | C15849
C4 | C_0603_1608Metric | 1 | 6.8nF ceramic | C1631
C5 | C_0603_1608Metric | 1 | 10pF ceramic | C32949
C6 | C_0603_1608Metric | 1 | 1nF ceramic | C1588
D1 | D_SMA | 1 | D_Schottky | C2480
J10 | JST_SH_SM02B-SRSS-TB_1x02-1MP_P1.00mm_Horizontal | 1 | Conn_01x02 | C160402
J3 | JST_PH_S3B-PH-SM4-TB_1x03-1MP_P2.00mm_Horizontal | 1 | LED_Strip | C265101
J4, J5, J6, J7, J8, J9 | JST_SH_SM03B-SRSS-TB_1x03-1MP_P1.00mm_Horizontal | 6 | Conn_01x03 | C2845362
R10, R11, R12, R13, R14, R15, R16, R17, R18, R19, R20, R21 | C_0603_1608Metric | 12 | 100Ω | C105588
R3, R4, R5, R7, R8, R9 | C_0603_1608Metric | 6 | 10kΩ | C25804
R6 | C_0603_1608Metric | 1 | 10kΩ | C98220
R22 | R_0603_1608Metric | 1 | 40.2kΩ 1% | C23046
R23 | R_0603_1608Metric | 1 | 13kΩ 1% | C23073
R24 | R_0603_1608Metric | 1 | 20kΩ | C4184
R25 | R_0603_1608Metric | 1 | 20Ω | C4189
R26 | R_0603_1608Metric | 1 | 604kΩ | C23207
U3 | SOP65P640X120-24N | 1 | TCA9548APWR | C130026
U4 | SOT583 | 1 | MP2393 Synchronous Buck | C2827643
L1 | IND_5040 | 1 | 3.3µH Power Inductor | C2043119

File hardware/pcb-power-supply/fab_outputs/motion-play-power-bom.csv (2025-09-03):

Comment | Designator | Footprint | LCSC Part Number
100nF Unpolarized capacitor | C1, C3 | C_0603_1608Metric | C14663
10µF Unpolarized capacitor | C4,C6,C7 | C_0603_1608Metric | C96446
4.7µF Unpolarized capacitor | C2, C5 | C_0603_1608Metric | C19666
220µF Unpolarized capacitor | C8 | CP_Elec_6.3x7.7 | C3342
22µF Unpolarized capacitor | C9,C10 | C_0603_1608Metric | C59461
2.2µF Unpolarized capacitor | C11,C12 | C_0603_1608Metric | C23630
47µF Polarized Capacitor | C13,C14 | C_Elec_6.3x5.4 | C2836440
40V Independent Type 550mV@5A 5A SMA(DO-214AC) Schottky Diodes ROHS Diode, small symbol | D1 | D_SMA | C22452
Fuse Fuse | F1 | Fuse_1206_3216Metric | C2897466
X3025WRS-03D-LPSW | CN1 | CONN-SMD_3P-H-P3.00-R_X3025WRS-03D-LPSW | C405941
PH 2mm 2-pin connector horizontal | J1 | JST_PH_S2B-PH-SM4-TB_1x02-1MP_P2.00mm_Horizontal | C18221575
SH 1mm 2-pin connector horizontal | J3 | JST_SH_SM02B-SRSS-TB_1x02-1MP_P1.00mm_Horizontal | C160402
SH 1mm 5-pin connector horizontal | J4 | JST_SH_SM05B-SRSS-TB_1x05-1MP_P1.00mm_Horizontal | C136657
2.2uH Inductor | L1 | L_Changjiang_FNR6028S | C266426
4.7uH Inductor | L2 | L_Changjiang_FNR6028S | C307880
PMOS P-MOSFET transistor, drain/source/gate | Q1 | SOT-23 | C3040193
5.1kΩ Resistor | R1,R2 | R_0603_1608Metric | C23186
10kΩ Resistor | R3,R4,R5,R9,R11 | R_0603_1608Metric | C25804
2.7k Resistor | R6 | R_0603_1608Metric | C13167
100kΩ Resistor | R7,R8 | R_0603_1608Metric | C14675
47kΩ Resistor | R10 | R_0603_1608Metric | C25819
Thermistor_NTC Temperature dependent resistor, negative temperature coefficient | TH1 | R_0603_1608Metric | C13564
STUSB4500LQTR | U1 | QFN50P400X400X100-25N | C506650
USBLC6-2SC6 Very low capacitance ESD protection diode, 2 data-line, SOT-23-6 | U2 | SOT-23-6 | C7519
BQ24195RGET | U3 | QFN50P400X400X100-25N | C2876710
MT3608 | U4 | SOT95P280X145-6N | C84817
LR1801G-33-SH2-R | U5 | HSOP-8_L5.0-W4.0-P1.27-LS6.2-BL-EP | C410479
TYPE-C-31-M-12 | USBC1 | USB-C_SMD-TYPE-C-31-M-12 | C165948

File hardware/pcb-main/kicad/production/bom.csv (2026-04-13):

Designator | Footprint | Quantity | Value | LCSC Part #
C10, C8 | 0603 | 2 | 10uF | C19702
C20, C50, C55 | 0603 | 3 | 1µF | C15849
C21, C24 | 0603 | 2 | 4.7µF | C19666
C22 | C_Elec_6.3x5.4 | 1 | 47µF 16V | C7469958
C23, C37 | 0603 | 2 | 47nF | C107093
C25, C26, C27, C28, C51 | 0603 | 5 | 10µF | C96446
C29 | CP_Elec_6.3x7.7 | 1 | 220µF 10V | C3342
C30 | C_Elec_6.3x5.4 | 1 | 47µF 10V | C7469958
C31, C32, C40 | 0603 | 3 | 0.1µF | C14663
C33 | 0603 | 1 | 2.2µF | C23630
C34, C35, C36 | 0805 | 3 | 22µF | C109314
C38 | 0603 | 1 | 4.7nF | C1621
C39 | 0603 | 1 | 100pF | C14858
C41 | 0805 | 1 | 10µF | C15850
C42 | C0805 | 1 | 22uF | C109314
C43 | CASE-A_3216 | 1 | 22uF 6.3V Tant | C129288
C52, C53, C54, C7, C9 | 0603 | 5 | 100nF | C14663
D1 | 0603 | 1 | LED | C19171301
D5 | LED-SMD_4P-L3.5-W3.5-TL_WS2812B-1 | 1 | WS2812B-MINI | C4154873
F1 | 1206 | 1 | 3A | C354897
F2 | 1206 | 1 | 3A | C2897466
IC1 | SOP65P640X120-14N | 1 | SN74AHCT125PWR | C36365
J3 | JST_PH_S3B-PH-SM4-TB_1x03-1MP_P2.00mm_Horizontal | 1 | LED_Strip | C265101
J4, J5, J6 | JST_SH_SM04B-SRSS-TB_1x04-1MP_P1.00mm_Horizontal | 3 | Conn_01x04 | C160404
J7 | USB-C_SMD-TYPE-C-31-M-12_1 | 1 | TYPE-C-31-M-12 | C165948
L1 | L_Changjiang_FNR6028S | 1 | 2.2µH | C266426
L2 | IND-SMD_L7.0-W6.6 | 1 | 2.2µH 10A | C167218
Q2 | SOT-23 | 1 | PMOS | C15127
R1 | 0603 | 1 | 1kΩ | C22548
R2, R33, R34, R41, R42 | 0603 | 5 | 100kΩ | C14675
R27 | 2512 | 1 | 0.1R | C2903476
R28, R29 | 0603 | 2 | 2.2kΩ | C114662
R30, R31 | 0603 | 2 | 5.1kΩ | C23186
R32 | 0603 | 1 | 330Ω | C23138
R35, R38, R50, R51, R6 | 0603 | 5 | 10kΩ | C25804
R36 | 0603 | 1 | 5.6kΩ | C23189
R37 | 0603 | 1 | 30kΩ | C22984
R39 | 0603 | 1 | 180kΩ | C22827
R40 | 0603 | 1 | 56kΩ | C23206
R43 | 0603 | 1 | 22kΩ | C31850
R44 | 2512 | 1 | 10mΩ | C1322424
R52, R53 | 0603 | 2 | 22Ω | C23345
SW1 | MK-12C02-G020_GSW | 1 | SW_SPDT | C431540
SW2 | KEY-SMD_L4.0-W3.0-LS4.9-1 | 1 | RESET | C49234124
SW3 | KEY-SMD_L4.0-W3.0-LS4.9-1 | 1 | BOOT | C49234124
TH1 | 0603 | 1 | 10kΩ NTC | C13564
TP1 | TestPoint_Pad_D1.5mm | 1 | VSYS
TP2 | TestPoint_Pad_D1.5mm | 1 | VBAT
TP3 | TestPoint_Pad_D1.5mm | 1 | PVBUS
TP4 | TestPoint_Pad_D1.5mm | 1 | PGND
TPIO10, TPIO16, TPIO21, TPIO43, TPIO44 | TestPoint_Pad_D2.0mm | 5 | TestPoint
U3 | WIRELM-SMD_ESP32-S3-WROOM-1 | 1 | ESP32-S3-WROOM-1-N16R8 | C2913202
U4 | SOP65P640X120-24N | 1 | TCA9548APWR | C130026
U5 | VQFN-24_L4.0-W4.0-P0.50-TL-EP2.8 | 1 | BQ24195RGER | C90862
U6 | VQFN-20_L4.6-W3.6-P0.50-BL | 1 | TPS61088RHLR | C87357
U7 | SOT-23-8_L3.0-W1.7-P0.65-LS2.8-BR | 1 | INA219AIDCNR | C87469
U8 | SOT-223-3_L6.5-W3.4-P2.30-LS7.0-BR | 1 | AMS1117-3.3 | C6186
U9 | SOT-23-6_L2.9-W1.6-P0.95-LS2.8-BL | 1 | USBLC6-2SC6 | C7519

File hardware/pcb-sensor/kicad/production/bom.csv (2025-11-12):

Designator | Footprint | Quantity | Value | LCSC Part #
C1, C4, C8 | 0603 | 3 | 2.2µF | C23630
C2, C6, C7 | 0603 | 3 | 0.1µF | C14663
D1 | 0603 | 1 | LED | C19171301
D2, D3 | SOT-23 | 2 | BAT54S | C727126
IC1, IC2 | VCNL4040M3OE | 2 | VCNL4040M3OE | C142526
J1 | JST_SH_SM05B-SRSS-TB_1x05-1MP_P1.00mm_Horizontal | 1 | Conn_01x05 | C136657
R1, R2, R6, R7, R8, R9 | 0603 | 6 | 4.7kΩ | C99782
R10, R11 | 0603 | 2 | 22Ω | C23345
R12, R13, R14, R3 | 0603 | 4 | 10kΩ | C25804
R4 | 0603 | 1 | 1kΩ | C22548
R5 | 0603 | 1 | 8.2kΩ | C25981
TP1, TP2, TP3, TP4, TP5 | TestPoint_Pad_D1.5mm | 5 | TestPoint_Small
U1 | SOP65P640X120-16N | 1 | PCA9546APWR | C400705

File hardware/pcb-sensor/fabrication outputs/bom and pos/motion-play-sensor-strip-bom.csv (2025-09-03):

Comment | Designator | Footprint | JLCPCB Part #
100nF Unpolarized capacitor | C1 | C_0603_1608Metric | C1590
2.2μF Unpolarized capacitor | C2 | C_0603_1608Metric | C1607
Power connector | J1 | JST_SH_SM02B-SRSS-TB_1x02-1MP_P1.00mm_Horizontal | C18337480
Power connector | J2 | JST_SH_SM02B-SRSS-TB_1x02-1MP_P1.00mm_Horizontal | C18337480
Comm connector | J3 | JST_SH_SM03B-SRSS-TB_1x03-1MP_P1.00mm_Horizontal | C160403
2.2kΩ Resistor | R1,R2 | R_0603_1608Metric | C4190
8.2kΩ Resistor | R3 | R_0603_1608Metric | C25981
VCNL4040M3OE-H3 | U1 | VISHAY_VCNL4040 | C142526

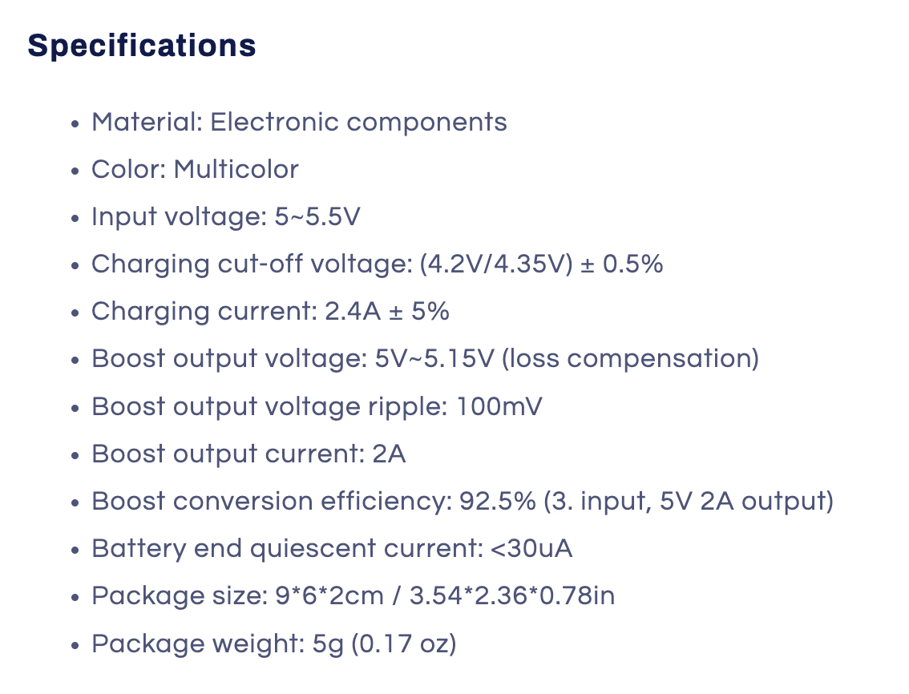
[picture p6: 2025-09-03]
hardware/components/dweii-power/product listing/Screenshot 2024-12-04 at 5.54.33 PM.png

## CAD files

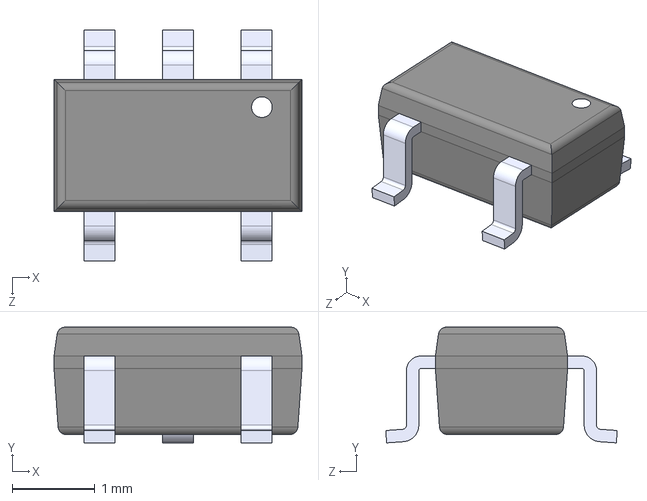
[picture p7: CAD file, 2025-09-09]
hardware/components/AP2112-3-3/AP2112K-3.3TRG1.step
3.00 x 1.40 x 2.80 mm

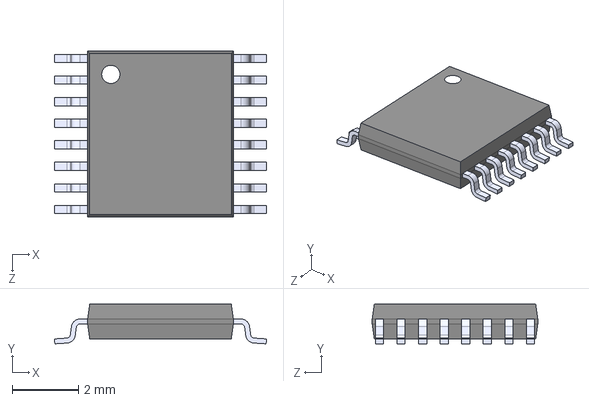
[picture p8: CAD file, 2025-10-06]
hardware/components/PCA9546A/PCA9546APWR.step
6.40 x 1.20 x 5.00 mm

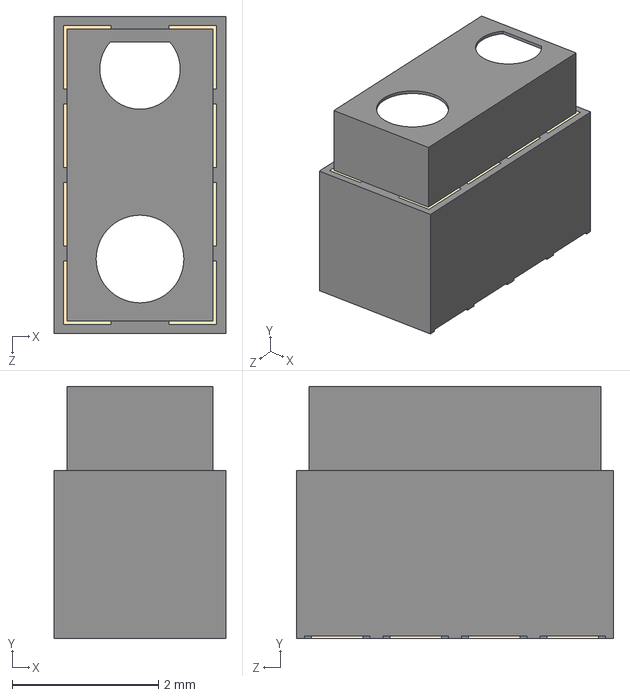
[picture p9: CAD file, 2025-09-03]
hardware/components/vcnl4040/model/VCNL4040M3OE-H3.step
2.35 x 3.45 x 4.34 mm

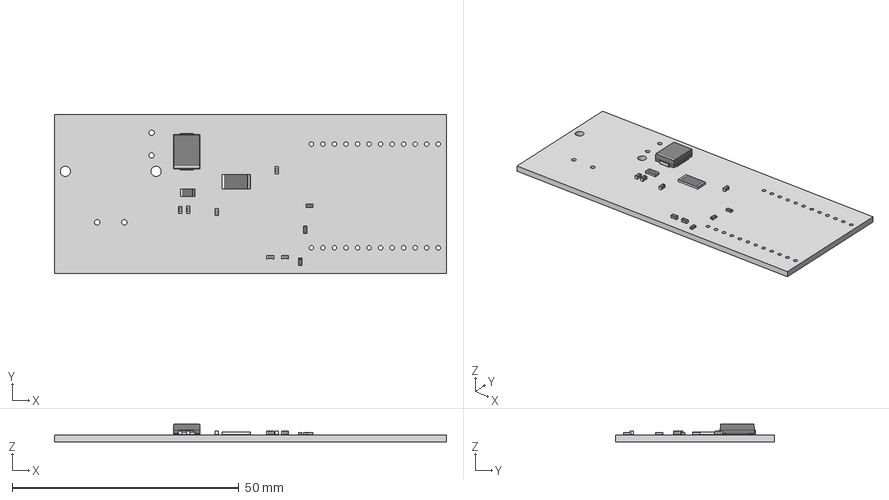
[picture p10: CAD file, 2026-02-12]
hardware/pcb-main/kicad/motion-play-v3.step
86.4 x 35.0 x 3.91 mm
R_0603_1608Metric x 3
C_0603_1608Metric x 6
D_SMC
Fuse_1206_3216Metric
R_2512_6332Metric
motion-play-main_PCB

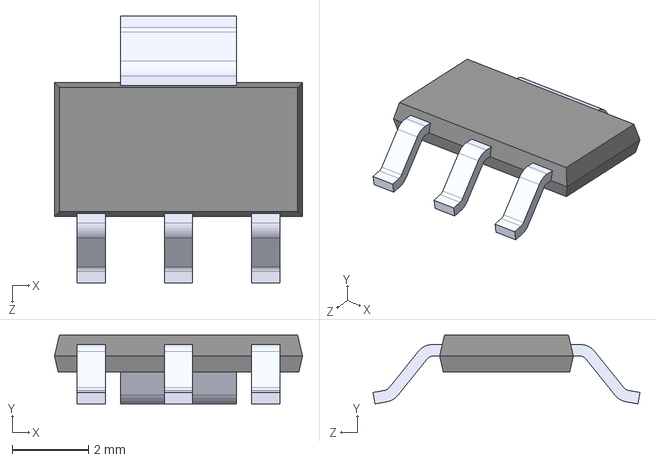
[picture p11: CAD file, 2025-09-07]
hardware/pcb-main/resources/AMS1117-3.3/AMS1117-3.3.step
6.50 x 1.80 x 7.00 mm

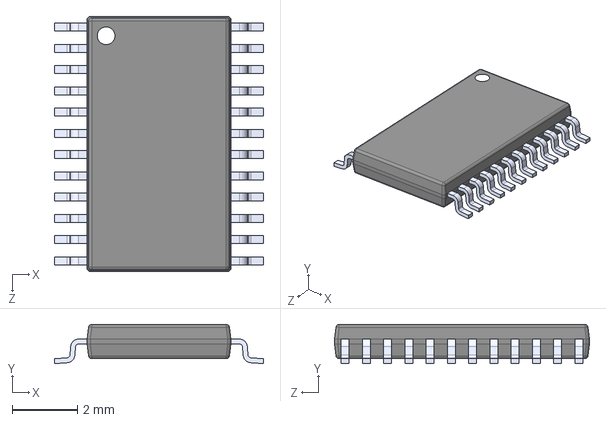
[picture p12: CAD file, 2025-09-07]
hardware/pcb-main/resources/TCA9548APWR/TCA9548APWR.step
6.40 x 1.20 x 7.80 mm

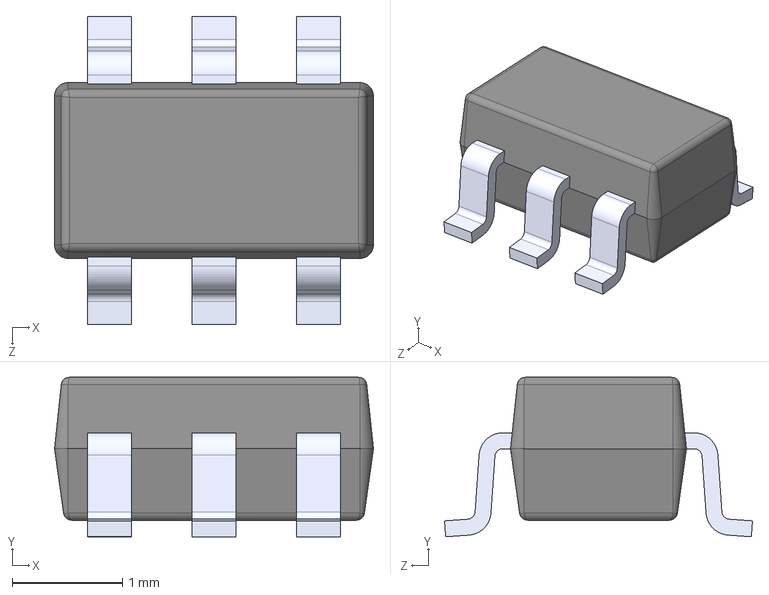
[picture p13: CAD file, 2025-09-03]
hardware/pcb-power-supply/resources/MT3608/MT3608.step
2.90 x 1.45 x 2.80 mm

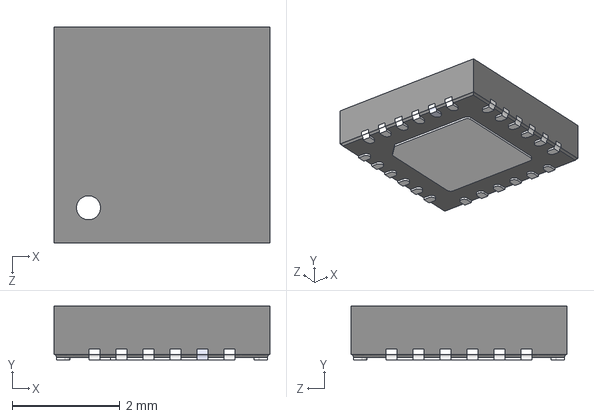
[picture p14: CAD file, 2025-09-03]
hardware/pcb-power-supply/resources/STUSB4500LQTR/STUSB4500LQTR.step
4.00 x 1 x 4.00 mm

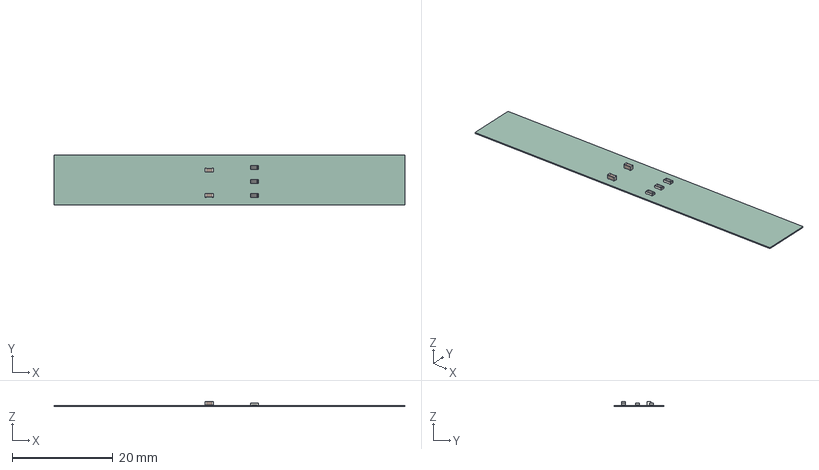
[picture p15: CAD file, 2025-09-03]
hardware/pcb-sensor/kicad/motion-play-sensor-strip.step
69.8 x 10.0 x 1.07 mm
R_0603_1608Metric x 3
C_0603_1608Metric x 2
motion-play-sensor-strip_PCB

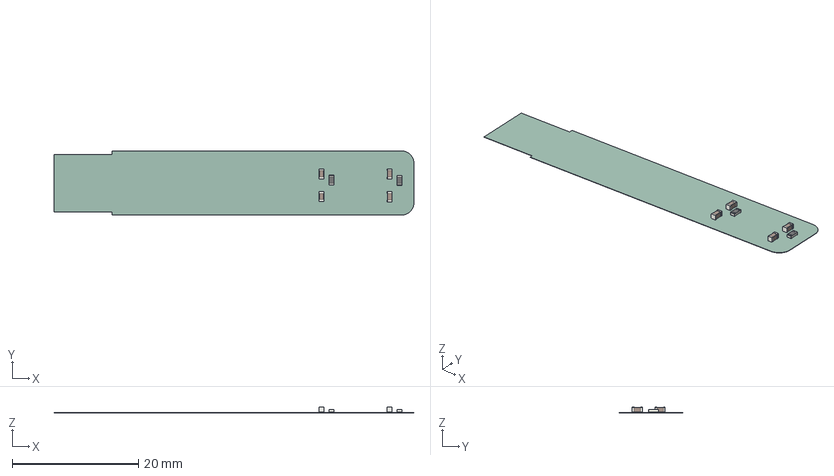
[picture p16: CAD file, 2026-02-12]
hardware/sensor-flex/sensor-flex.step
57.1 x 10.2 x 0.917 mm
R_0603_1608Metric x 2
C_0603_1608Metric x 4
sensor-flex_PCB

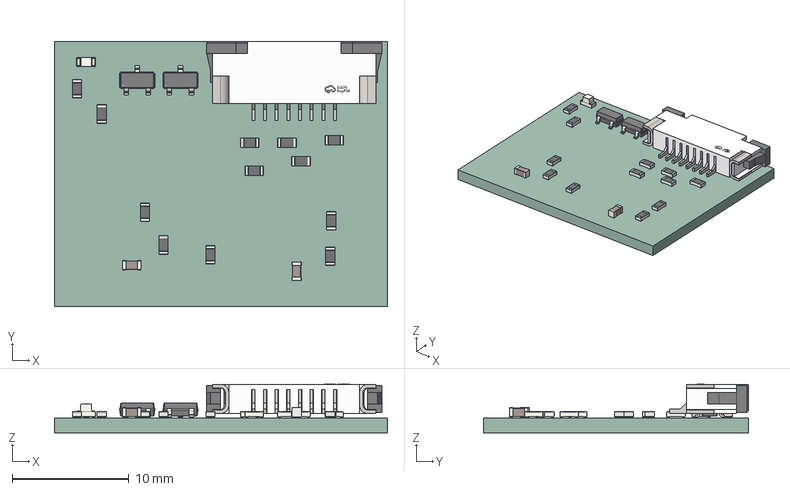
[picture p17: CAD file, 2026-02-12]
hardware/sensor-rigid/sensor-rigid.step
28.5 x 22.7 x 4.17 mm
C_0603_1608Metric x 2
R_0603_1608Metric x 12
SOT-23 x 2
FPC-SMD_8P-P1.00_FPC1.0-8P-SJ
LED_0603_1608Metric
sensor-rigid_PCB

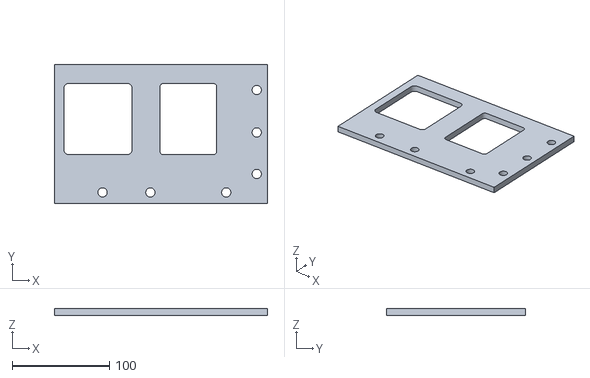
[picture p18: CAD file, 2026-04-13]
mechanical/models/projector-box-templates/pb4 side1.dxf
219.0 x 143.4 x 6.98

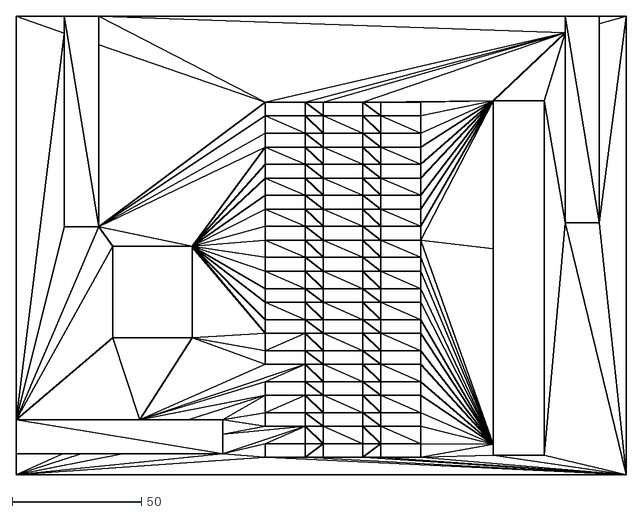
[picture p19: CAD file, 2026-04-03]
mechanical/models/router-template/pb_back_router_template.dxf
235.8 x 177.1

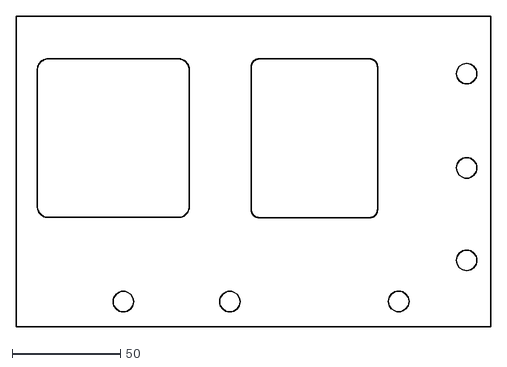
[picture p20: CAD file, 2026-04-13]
mechanical/models/projector-box-templates/pb4_side1_clean.dxf
219.0 x 143.4

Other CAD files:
mechanical/models/router-template/pb_back_router_template_clean.dxf
hardware/components/TPS54331/TPS54331DR.step
hardware/pcb-power-supply/resources/BQ24195RGET/BQ24195RGET.step

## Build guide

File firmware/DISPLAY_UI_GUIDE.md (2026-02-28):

# T-Display S3 UI Guide

## Overview

The Motion Play device now features a professional, two-stage UI with clear visual feedback for initialization and session recording.

## Display Modes

### 1. Initialization Screen

**Layout:**
```
┌──────────────────────────────────────────────────┐
│ MOTION PLAY                                      │
│                                                  │
│ ┌────┬────┬────┬────┬────┐                     │
│ │BOOT│WIFI│MQTT│SENS│DONE│  ← Progress Bar     │
│ │ ✓  │ ✓  │ ✓  │ ✓  │ ✓  │                     │
│ └────┴────┴────┴────┴────┘                     │
│                                                  │
│ Connecting to AWS IoT...   ← Status Message     │
│                                                  │
└──────────────────────────────────────────────────┘
```

**Progress Stages:**
1. **BOOT** (Green) - System booting up
2. **WIFI** (Yellow → Green) - Connecting to WiFi → Connected
3. **MQTT** (Yellow → Green) - Connecting to AWS IoT → Connected  
4. **SENS** (Yellow → Green) - Initializing sensors
5. **DONE** (Green) - Ready!

**Colors:**
- Gray: Not started
- Yellow: In progress
- Green: Complete with checkmark ✓
- Red: Error state

**Duration:** ~5-10 seconds (auto-progresses)

---

### 2. Session Screen

**Layout:**
```
┌──────────────────────────────────────────────────┐
│ MOTION PLAY                                      │
│ Status:                                          │
│                                                  │
│              ┌───────┐                           │
│              │       │                           │
│              │  REC  │  ← Status Indicator       │
│              │       │                           │
│              └───────┘                           │
│                                                  │
│            2500 samples  ← Sample Counter        │
│                                                  │
│ Recording in progress...  ← Message Area         │
└──────────────────────────────────────────────────┘
```

**Session States:**

#### STATE_IDLE (Gray Circle)
- **Display:** "IDLE" in gray circle
- **Message:** "Ready to record"
- **Meaning:** Device ready, waiting for start command

#### STATE_RECORDING (Red Circle, Filled)
- **Display:** "REC" in red filled circle
- **Message:** "Recording in progress..."
- **Live Counter:** Shows sample count (updates every second)
- **Meaning:** Actively collecting sensor data

#### STATE_UPLOADING (Yellow Circle)
- **Display:** "UP" in yellow circle  
- **Message:** "Uploading to cloud..."
- **Meaning:** Transmitting data to AWS

#### STATE_SUCCESS (Green Circle with Checkmark)
- **Display:** "OK" in green circle with ✓
- **Message:** "Upload complete!"
- **Duration:** Shows for 3 seconds, then returns to IDLE
- **Meaning:** Data successfully uploaded

#### STATE_ERROR (Red Circle)
- **Display:** "ERR" in red circle
- **Message:** Error description
- **Duration:** Shows for 3 seconds, then returns to IDLE
- **Meaning:** Operation failed

---

## Auto-Initialization

**Boot Sequence:**
1. Power on device
2. Serial + display initialize
3. WiFi → MQTT → cloud config fetch
4. Sensors initialize (once, with cloud config)
5. Progress bar fills as each stage completes
6. Switches to Session Screen when complete

**No More Button Press Required!**
- System automatically initializes on boot
- Right button (GPIO 14) can restart device anytime
- Left button (GPIO 0 / BOOT) is unused in normal operation

---

## User Experience Flow

### Recording a Session

**From Web UI:**
1. Click "Start Collection" → Device shows `STATE_RECORDING`
2. Red filled circle appears with "REC"
3. Sample count updates every second
4. Click "Stop Collection" → Device shows `STATE_UPLOADING`
5. Yellow "UP" indicator while transmitting
6. Green "OK" with checkmark → `STATE_SUCCESS`
7. After 3 seconds → Returns to `STATE_IDLE`

**Visual Timeline:**
```
IDLE (gray) 
   ↓ start_collection
RECORDING (red, filled) → [live sample count]
   ↓ stop_collection
UPLOADING (yellow) → [transmitting batches]
   ↓ success
SUCCESS (green, ✓) → [3 second pause]
   ↓
IDLE (gray)
```

---

## Benefits

### For Users
- **Clear status** - Always know what the device is doing
- **No confusion** - Visual states match system behavior
- **Professional look** - Progress bars, indicators, clean layout
- **No button hassle** - Auto-starts on power-up

### For Development
- **No text overlap** - Proper screen clearing and layout management
- **State-driven** - DisplayManager tracks current state
- **Easy updates** - Call `setSessionState()` to change display
- **Consistent** - All status changes go through display methods

---

## Implementation Details

### Display Manager Methods

**Initialization:**
```cpp
display.showInitScreen();                     // Show progress bar
display.updateInitStage(INIT_WIFI_CONNECTING, "Connecting..."); 
display.updateInitStage(INIT_WIFI_CONNECTED, "WiFi OK");
display.setInitError("Connection failed!");   // Show error
```

**Session:**
```cpp
display.showSessionScreen();           // Switch to session mode
display.setSessionState(STATE_IDLE);   // Ready
display.setSessionState(STATE_RECORDING); // Start recording
display.updateSampleCount(1500);       // Update counter
display.setSessionState(STATE_UPLOADING); // Uploading
display.setSessionState(STATE_SUCCESS);   // Done!
display.showMessage("Custom message", TFT_YELLOW); // Temp message
```

### Screen Layout Constants

```cpp
SCREEN_WIDTH = 320
SCREEN_HEIGHT = 170
PROGRESS_BAR_Y = 20
PROGRESS_BAR_HEIGHT = 40
STATUS_INDICATOR_Y = 80
STATUS_INDICATOR_SIZE = 60
MESSAGE_Y = 150
```

---

## Testing the New UI

### 1. Upload Firmware
```bash
cd firmware
pio run --target upload
pio device monitor
```

### 2. Observe Boot Sequence
- Device powers on
- "MOTION PLAY" appears
- Progress bar segments fill: BOOT → WIFI → MQTT → SENS → DONE
- Each segment turns green with checkmark as it completes
- Status messages appear below progress bar
- After DONE, switches to Session Screen

### 3. Test Recording
From web UI:
- Start collection → Watch red "REC" appear
- Sample count updates every second
- Stop collection → "UP" (yellow) → "OK" (green with ✓)
- Returns to gray "IDLE" after 3 seconds

### 4. Test Error Handling
- Disconnect WiFi during initialization → See error screen
- Start collection twice → See STATE_ERROR

---

## Troubleshooting

**Display stays black:**
- Check PIN_POWER_ON and PIN_LCD_BL are HIGH
- Verify TFT_eSPI library is installed
- Check User_Setup.h in `include/` directory

**Text overlaps:**
- Should be fixed! Each state clears its area before drawing
- If persists, check `tft.fillRect()` calls in DisplayManager.cpp

**Wrong colors:**
- Check TFT_eSPI color constants (TFT_RED, TFT_GREEN, etc.)
- Verify color definitions in DisplayManager.cpp

**Progress bar doesn't update:**
- Check `display.updateInitStage()` is called in sequence
- Verify stages are in order (BOOT → WIFI → MQTT → SENS → COMPLETE)

---

## Future Enhancements

### Possible Additions:
1. **WiFi signal strength indicator** - Show bars in corner
2. **Battery level indicator** - If using battery power
3. **Sensor status indicators** - Show which sensors are active
4. **QR code for web UI** - Display URL to connect
5. **Touchscreen support** - If upgrading to touch display
6. **Animated transitions** - Smooth state changes
7. **Color themes** - Dark/light mode toggle

### Display Upgrade Path:
Current: T-Display S3 (320x170 LCD)
→ T-Display S3 Touch (same size, capacitive touch)
→ T-Display AMOLED (240x536, vibrant colors)

---

## Technical Notes

- **Frame rate:** Updates as needed (event-driven)
- **Memory:** ~2KB for display buffer
- **Processor:** Runs on Core 1 (same as networking)
- **Render time:** <10ms per full screen update
- **Text rendering:** TFT_eSPI built-in fonts
- **Graphics:** Lines, circles, rectangles (no complex shapes)

---

## Change Summary

### Before (Old UI)
- ❌ Text overlapped and scrolled off screen
- ❌ No clear initialization feedback
- ❌ Required button press to start
- ❌ Unclear session state
- ❌ Status messages got buried

### After (New UI)
- ✅ Clean, segmented progress bar
- ✅ Clear visual state indicators
- ✅ Auto-initialization on boot
- ✅ Professional status displays
- ✅ No text overlap
- ✅ Live sample counter during recording
- ✅ Color-coded states (red=recording, yellow=uploading, green=success)

---

*Last Updated: November 14, 2025*

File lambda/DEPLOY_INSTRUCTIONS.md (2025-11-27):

# Lambda Deployment Instructions
## Deploying Duty Cycle Updates

**Date:** November 26, 2025  
**Changes:** Added `duty_cycle` field support to all Lambda functions

---

## What Changed

### Lambda Functions Updated
1. **getDeviceConfig** - Returns duty_cycle in default config
2. **updateDeviceConfig** - Validates and stores duty_cycle, sends to device via MQTT
3. **processData** - Stores duty_cycle in session metadata

---

## Prerequisites

Before deploying, ensure you have:
- ✅ AWS CLI configured with appropriate credentials
- ✅ Permissions to update Lambda functions in your AWS account
- ✅ Node.js installed (for dependency bundling)

Check your AWS configuration:
```bash
aws sts get-caller-identity
```

---

## Deployment Steps

### Option 1: Use Deployment Script (Recommended)

The deployment script handles both Lambda functions and API Gateway routes:

```bash
cd lambda
chmod +x deploy-config-endpoints.sh
./deploy-config-endpoints.sh
```

This script will:
1. Package the Lambda functions with dependencies
2. Create/update Lambda functions in AWS
3. Configure API Gateway routes
4. Set up environment variables
5. Display test endpoints

### Option 2: Manual Deployment

If you prefer manual control:

#### 1. Package Lambda Functions

For each Lambda function:

```bash
# getDeviceConfig
cd lambda/getDeviceConfig
npm install
zip -r ../getDeviceConfig.zip index.js node_modules/

# updateDeviceConfig
cd ../updateDeviceConfig
npm install
zip -r ../updateDeviceConfig.zip index.js node_modules/

# processData
cd ../processData
npm install
zip -r ../processData.zip index.js node_modules/

cd ..
```

#### 2. Update Lambda Functions

```bash
# Update getDeviceConfig
aws lambda update-function-code \
  --function-name getDeviceConfig \
  --zip-file fileb://getDeviceConfig.zip \
  --region us-west-2

# Update updateDeviceConfig
aws lambda update-function-code \
  --function-name updateDeviceConfig \
  --zip-file fileb://updateDeviceConfig.zip \
  --region us-west-2

# Update processData
aws lambda update-function-code \
  --function-name processData \
  --zip-file fileb://processData.zip \
  --region us-west-2
```

#### 3. Wait for Deployment

Lambda updates take a few seconds:

```bash
aws lambda wait function-updated \
  --function-name getDeviceConfig \
  --region us-west-2

aws lambda wait function-updated \
  --function-name updateDeviceConfig \
  --region us-west-2

aws lambda wait function-updated \
  --function-name processData \
  --region us-west-2
```

---

## Verify Deployment

### 1. Check Lambda Function Status

```bash
aws lambda get-function \
  --function-name updateDeviceConfig \
  --region us-west-2 \
  --query 'Configuration.[FunctionName,LastModified,State]'
```

Expected output shows recent `LastModified` timestamp and `State: Active`

### 2. Test getDeviceConfig

Get your API Gateway endpoint:
```bash
export API_ENDPOINT=$(aws apigatewayv2 get-apis \
  --region us-west-2 \
  --query 'Items[?Name==`MotionPlayAPI`].ApiEndpoint' \
  --output text)

echo $API_ENDPOINT
```

Test getting config:
```bash
curl ${API_ENDPOINT}/device/motionplay-device-001/config | jq
```

Expected response should include `duty_cycle`:
```json
{
  "device_id": "motionplay-device-001",
  "sensor_config": {
    "sample_rate_hz": 1000,
    "led_current": "200mA",
    "integration_time": "2T",
    "duty_cycle": "1/40",
    "high_resolution": true,
    "read_ambient": true,
    "i2c_clock_khz": 400
  },
  "config_updated_at": null
}
```

### 3. Test updateDeviceConfig

```bash
curl -X PUT \
  ${API_ENDPOINT}/device/motionplay-device-001/config \
  -H 'Content-Type: application/json' \
  -d '{
    "sensor_config": {
      "sample_rate_hz": 1000,
      "led_current": "200mA",
      "integration_time": "2T",
      "duty_cycle": "1/40",
      "high_resolution": true,
      "read_ambient": true,
      "i2c_clock_khz": 400
    }
  }' | jq
```

Expected response:
```json
{
  "device_id": "motionplay-device-001",
  "sensor_config": {
    "sample_rate_hz": 1000,
    "led_current": "200mA",
    "integration_time": "2T",
    "duty_cycle": "1/40",
    "high_resolution": true,
    "read_ambient": true,
    "i2c_clock_khz": 400
  },
  "config_updated_at": 1732635600000,
  "message": "Config updated and command sent to device"
}
```

### 4. Check CloudWatch Logs

View recent Lambda executions:

```bash
# updateDeviceConfig logs
aws logs tail /aws/lambda/updateDeviceConfig \
  --region us-west-2 \
  --follow

# Look for: "New config:" with duty_cycle included
```

---

## Test MQTT Command Delivery

If you have a device connected:

1. **Deploy the Lambda updates** (above)
2. **Monitor device serial output**
3. **Send config update from frontend** (or curl command above)
4. **Check device logs** for:
   ```
   Received MQTT command: configure_sensors
   sensor_config: { ..., "duty_cycle": "1/40" }
   Applying duty cycle: 1/40
   ```

---

## Rollback (If Needed)

If something goes wrong, you can rollback to a previous version:

```bash
# List function versions
aws lambda list-versions-by-function \
  --function-name updateDeviceConfig \
  --region us-west-2

# Rollback to specific version (replace VERSION_NUMBER)
aws lambda update-function-configuration \
  --function-name updateDeviceConfig \
  --region us-west-2 \
  --publish \
  --revision-id VERSION_NUMBER
```

Or redeploy from a previous commit:
```bash
git checkout <previous-commit>
cd lambda
./deploy-config-endpoints.sh
```

---

## Common Issues

### Issue: "Function not found"
**Solution:** Ensure Lambda functions exist. Run deployment script with `--create` flag if needed.

### Issue: "Permission denied"
**Solution:** Check IAM permissions. Your user needs:
- `lambda:UpdateFunctionCode`
- `lambda:UpdateFunctionConfiguration`
- `lambda:GetFunction`

### Issue: "Package size too large"
**Solution:** Ensure you're only including necessary node_modules:
```bash
npm install --production
```

### Issue: Config update doesn't reach device
**Solution:** 
1. Check device is connected to MQTT (check CloudWatch IoT logs)
2. Verify MQTT topic is correct: `motionplay/{device_id}/commands`
3. Check device subscription in firmware

---

## Post-Deployment Testing

After deploying, test the full flow:

1. **Frontend → Lambda → DynamoDB:**
   - Open frontend settings
   - Change duty cycle to "1/40"
   - Click "Apply Configuration"
   - Verify no errors

2. **Lambda → MQTT → Device:**
   - Monitor device serial output
   - Should see: "Received MQTT command"
   - Should see: "Applied config: ... Duty=1/40"

3. **Device → Data Collection → Lambda → DynamoDB:**
   - Start a data collection session
   - Stop collection
   - Check frontend session list
   - View session details
   - Verify `duty_cycle` appears in configuration

4. **DynamoDB → Frontend:**
   - Load session data
   - Check SessionConfig component shows duty cycle

---

## Monitoring

After deployment, monitor for issues:

```bash
# Watch Lambda errors
aws cloudwatch get-metric-statistics \
  --namespace AWS/Lambda \
  --metric-name Errors \
  --dimensions Name=FunctionName,Value=updateDeviceConfig \
  --start-time $(date -u -d '1 hour ago' +%Y-%m-%dT%H:%M:%S) \
  --end-time $(date -u +%Y-%m-%dT%H:%M:%S) \
  --period 300 \
  --statistics Sum \
  --region us-west-2

# Watch Lambda duration
aws cloudwatch get-metric-statistics \
  --namespace AWS/Lambda \
  --metric-name Duration \
  --dimensions Name=FunctionName,Value=updateDeviceConfig \
  --start-time $(date -u -d '1 hour ago' +%Y-%m-%dT%H:%M:%S) \
  --end-time $(date -u +%Y-%m-%dT%H:%M:%S) \
  --period 300 \
  --statistics Average \
  --region us-west-2
```

---

## Summary

✅ Updated 3 Lambda functions to support duty_cycle  
✅ Deployment script ready  
✅ Testing procedures documented  
✅ Rollback procedure available  

**Next:** Deploy and test!

---

*See also: `docs/references/vcnl4040/DUTY_CYCLE_IMPLEMENTATION.md` for the full implementation details*

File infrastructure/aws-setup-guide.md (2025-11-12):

# AWS Setup Guide for Motion Play

This guide walks you through setting up the AWS infrastructure manually.

## Prerequisites

- AWS Account
- AWS CLI configured (`aws configure`)
- Appropriate IAM permissions

## Step 1: Configure AWS CLI

```bash
aws configure
# Enter AWS Access Key ID
# Enter AWS Secret Access Key
# Enter region: us-west-2
# Enter output format: json
```

Test configuration:
```bash
aws sts get-caller-identity
```

## Step 2: Set Up Billing Alert

1. Go to AWS Console → Billing → Budgets
2. Click "Create budget"
3. Choose "Cost budget"
4. Set amount: $20
5. Configure email alert
6. Create budget

## Step 3: Create DynamoDB Tables

### MotionPlaySessions Table

```bash
aws dynamodb create-table \
    --table-name MotionPlaySessions \
    --attribute-definitions \
        AttributeName=session_id,AttributeType=S \
        AttributeName=device_id,AttributeType=S \
        AttributeName=start_timestamp,AttributeType=S \
    --key-schema \
        AttributeName=session_id,KeyType=HASH \
    --billing-mode PAY_PER_REQUEST \
    --global-secondary-indexes \
        "IndexName=DeviceTimeIndex,KeySchema=[{AttributeName=device_id,KeyType=HASH},{AttributeName=start_timestamp,KeyType=RANGE}],Projection={ProjectionType=ALL}"
```

### MotionPlaySensorData Table

```bash
aws dynamodb create-table \
    --table-name MotionPlaySensorData \
    --attribute-definitions \
        AttributeName=session_id,AttributeType=S \
        AttributeName=timestamp_offset,AttributeType=N \
    --key-schema \
        AttributeName=session_id,KeyType=HASH \
        AttributeName=timestamp_offset,KeyType=RANGE \
    --billing-mode PAY_PER_REQUEST
```

### MotionPlayDevices Table

```bash
aws dynamodb create-table \
    --table-name MotionPlayDevices \
    --attribute-definitions \
        AttributeName=device_id,AttributeType=S \
    --key-schema \
        AttributeName=device_id,KeyType=HASH \
    --billing-mode PAY_PER_REQUEST
```

## Step 4: Create IoT Thing

```bash
# Create thing
aws iot create-thing --thing-name motionplay-device-001

# Create certificates
aws iot create-keys-and-certificate \
    --set-as-active \
    --certificate-pem-outfile device-cert.pem \
    --public-key-outfile public-key.pem \
    --private-key-outfile private-key.pem \
    > certificate-output.json

# Extract certificate ARN
CERT_ARN=$(cat certificate-output.json | jq -r '.certificateArn')

# Attach certificate to thing
aws iot attach-thing-principal \
    --thing-name motionplay-device-001 \
    --principal $CERT_ARN
```

## Step 5: Create IoT Policy

Save this as `iot-policy.json`:

```json
{
  "Version": "2012-10-17",
  "Statement": [
    {
      "Effect": "Allow",
      "Action": "iot:Connect",
      "Resource": "arn:aws:iot:REGION:ACCOUNT:client/motionplay-*"
    },
    {
      "Effect": "Allow",
      "Action": "iot:Publish",
      "Resource": [
        "arn:aws:iot:REGION:ACCOUNT:topic/motionplay/*/data",
        "arn:aws:iot:REGION:ACCOUNT:topic/motionplay/*/status"
      ]
    },
    {
      "Effect": "Allow",
      "Action": "iot:Subscribe",
      "Resource": "arn:aws:iot:REGION:ACCOUNT:topicfilter/motionplay/*/commands"
    },
    {
      "Effect": "Allow",
      "Action": "iot:Receive",
      "Resource": "arn:aws:iot:REGION:ACCOUNT:topic/motionplay/*/commands"
    }
  ]
}
```

Replace REGION and ACCOUNT with your values, then:

```bash
# Get your account ID
ACCOUNT_ID=$(aws sts get-caller-identity --query Account --output text)
REGION="us-west-2"

# Update policy file with account ID and region
sed -i '' "s/REGION/$REGION/g" iot-policy.json
sed -i '' "s/ACCOUNT/$ACCOUNT_ID/g" iot-policy.json

# Create policy
aws iot create-policy \
    --policy-name MotionPlayDevicePolicy \
    --policy-document file://iot-policy.json

# Attach policy to certificate
aws iot attach-policy \
    --policy-name MotionPlayDevicePolicy \
    --target $CERT_ARN
```

## Step 6: Get IoT Endpoint

```bash
aws iot describe-endpoint --endpoint-type iot:Data-ATS
```

Save this endpoint URL - you'll need it for the ESP32 configuration.

## Step 7: Download Root CA Certificate

```bash
curl -o root-ca.pem https://www.amazontrust.com/repository/AmazonRootCA1.pem
```

## Step 8: Move Certificates to ESP32 Project

```bash
# Copy certificates to firmware data directory
cp device-cert.pem ../firmware/data/certs/
cp private-key.pem ../firmware/data/certs/
cp root-ca.pem ../firmware/data/certs/

# Remove from current directory for security
rm device-cert.pem private-key.pem public-key.pem root-ca.pem certificate-output.json
```

## Step 9: Create config.json for ESP32

In `firmware/data/config.json`:

```json
{
  "device_id": "motionplay-device-001",
  "wifi": {
    "ssid": "YOUR_WIFI_SSID",
    "password": "YOUR_WIFI_PASSWORD"
  },
  "mqtt": {
    "broker": "YOUR_IOT_ENDPOINT.iot.us-west-2.amazonaws.com",
    "port": 8883,
    "client_id": "motionplay-device-001"
  },
  "sampling": {
    "rate_hz": 1000,
    "max_duration_seconds": 30
  }
}
```

## Verification

### Test DynamoDB Tables

```bash
aws dynamodb list-tables
```

You should see:
- MotionPlaySessions
- MotionPlaySensorData
- MotionPlayDevices

### Test IoT Thing

```bash
aws iot describe-thing --thing-name motionplay-device-001
```

### Test MQTT Connection (from AWS Console)

1. Go to AWS IoT Core → Test
2. Subscribe to topic: `motionplay/+/status`
3. You'll test publishing from ESP32 later

## Next Steps

1. Complete Phase 1: ESP32 WiFi and MQTT implementation
2. Create Lambda functions for data processing
3. Set up API Gateway for web interface

## Troubleshooting

**Certificate Issues:**
- Ensure certificate is activated
- Verify policy is attached
- Check policy permissions match topic structure

**DynamoDB Issues:**
- Verify tables are created in correct region
- Check billing mode is set correctly

**IoT Core Issues:**
- Ensure endpoint is correct (use iot:Data-ATS type)
- Verify thing name matches exactly

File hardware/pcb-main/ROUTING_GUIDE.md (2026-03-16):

# PCB Routing Guide — Power Section + Full Board

Ephemeral reference doc. Delete after use.

> **L2 bbox fix (re-placement run):** L2's bounding box was corrected from 8.4×3.2mm
> (pad-only) to 8.4×6.6mm (body size from footprint name). This pushed C32, R41,
> R42, R43, and TP4 out of L2's footprint. R41/R42/R43 are now 9-11mm from U6
> (were ~2-3mm). C32 moved above L2 to ~(72.6, 131.9). See `placement-report.json`
> for all current positions.

---

## Step 0: Before You Start Routing

1. **Fill all zones** (`B`). This shows GND planes on In1.Cu/B.Cu and +5V/3.3V zones on In2.Cu.
2. **Turn on ratsnest** — the thin lines are your to-do list.
3. **Lock anchor components.** Right-click U5, U6, J7, J8, L1, L2, R44 → Properties → "Locked". Prevents accidental nudging.

---

## Step 1: Thermal Via Arrays Under U5 and U6

### U5 (BQ24195) — exposed pad 25 at (82.75, 122.25), 2.8×2.8mm, GND

Place a 3×2 grid of vias (0.6mm dia / 0.3mm drill) centered on the pad:
- x = {81.85, 82.75, 83.65}
- y = {121.65, 122.85}

These connect the exposed pad to the In1.Cu GND plane for heat dissipation.

### U6 (TPS61088) — exposed pad at (69.77, 135.95), GND

The footprint has 8 built-in thermal vias (0.4mm circles, no net assigned). Options:
- If they already connect to GND on inner layers → you're set
- If not → add a small GND copper pour on F.Cu over the exposed pad area, which will connect through the existing vias
- Or place your own 0.6mm/0.3mm vias on GND net in the same area

**Verify:** refill zones (`B`), check ratsnest confirms U5 pad 25 and U6 pad 21 are connected to GND.

---

## Step 2: TPS61088 Boost Switching Loop (HIGHEST PRIORITY)

The most EMI-sensitive loop. Switching current at 2.2MHz flows:

```
VSYS_SENSE → L2 pad 2 → L2 pad 1 → BOOST_SW → U6 pins 4-7 → GND (plane return)
```

### 2a. BOOST_SW: U6 pins 4-7 → L2 pad 1

| From | To | Distance |
|---|----|---|
| U6 pins 4-7 at x=71.5, y=135.2–136.7 | L2 pad 1 at (73.474, 136.456) | ~2mm |

**Use a copper pour, not a trace.** Draw a small filled zone on F.Cu assigned to BOOST_SW that covers U6 SW pins and extends to L2 pad 1. Keep it compact — only the area between U6 right side and L2 left pad. ~2-3mm wide.

### 2b. BOOST_BOOT: U6 pin 8 → C32

| From | To | Width |
|---|----|---|
| U6 pin 8 at (71.5, 134.7) | C32 pad 1 (BOOST_BOOT) at ~(72.6, 131.9) | 0.25mm (Default) |

Low-current bootstrap charge. ~3mm trace from U6 pin 8 to C32 (moved above L2 due to bbox fix).

Then connect **C32 pad 2 (BOOST_SW)** to the BOOST_SW pour — extend the pour or run a short 1.0mm trace.

### 2c. VSYS_SENSE: L2 pad 2 → U6 pins 2/9

| From | To | Width |
|---|----|---|
| L2 pad 2 at (79.474, 136.456) | U6 pin 2 at (71.5, 137.7) and pin 9 at (71.5, 134.2) | 1.0mm (Power_Med) |

Carries full boost input current (~3A). Route from L2 pad 2 leftward to U6 pin 2, then down to pin 9 along U6's right edge.

**Input caps C31 and C41** must tap off this trace close to U6 — not at the far end of a long stub.

### 2d. GND return

No explicit trace — In1.Cu GND plane handles this. **Verify** the plane is unbroken under U6 and L2 (no signal traces cutting through on In1.Cu).

---

## Step 3: BQ24195 Switching Loop (SECOND PRIORITY)

Switching path:

```
Protected_VBUS → U5 pins 1/24 → BQ_SW pins 19-20 → L1 pad 1 → (L1) → VSYS
                                       ↑
                         C23 bridges BTST (pin 21) to SW
```

### 3a. BQ_SW: U5 pins 19-20 → L1 pad 1

| From | To | Width |
|---|----|---|
| U5 pins 19-20 at (83.5, 120.2) and (84.0, 120.2) | L1 pad 1 (BQ_SW) at (83.1, 116.6) | 1.0mm (Power_Med) |

~3.6mm vertical. Route straight up from pins 19-20 to L1 pad 1. Keep as short and direct as possible.

### 3b. BQ_BTST: U5 pin 21 → C23 → BQ_SW

| From | To | Width |
|---|----|---|
| U5 pin 21 (BTST) at (83.0, 120.2) | C23 pad 1 (BTST) at ~(86.4, 118.7) | 0.25mm (Default) |
| C23 pad 2 (BQ_SW) at ~(84.8, 118.7) | BQ_SW trace above | 0.25mm (Default) |

Bootstrap charging current — not high power. Connect C23 pad 2 to the BQ_SW trace between U5 and L1.

### 3c. VSYS: L1 pad 2 → R44 pad 1

| From | To | Width |
|---|----|---|
| L1 pad 2 (VSYS) at (83.1, 112.1) | R44 pad 1 (VSYS) at (78.775, 130.9) | 1.0mm (Power_Med) |

Main VSYS power path, ~3A, ~19mm route. Go from L1 pad 2 downward, around the left side of U5, then down to R44. Stay in the power section (x < 90).

**C27/C28/C29 (VSYS bulk caps)** should tap off this trace near U5 VSYS pins (15-16, at x=84.79) — not at the far end.

---

## Step 4: INA219 Kelvin Sense Traces

**Precision measurement — routing accuracy matters here.**

R44 at (81.737, 130.9):
- Pad 1 (VSYS) at (78.775, 130.9)
- Pad 2 (VSYS_SENSE) at (84.7, 130.9)

U7 (INA219) at (88.2, 130.9):
- Pin 1 (VIN+ = VSYS) at (86.97, 129.92)
- Pin 2 (VIN- = VSYS_SENSE) at (86.97, 130.57)

### Rules:
1. Run a **thin 0.25mm dedicated trace** from R44 pad 1 → U7 pin 1
2. Run a **thin 0.25mm dedicated trace** from R44 pad 2 → U7 pin 2
3. These traces **must NOT merge with or tap off the fat power traces**
4. They connect **directly and only** to R44 pads and U7 pins
5. The fat 1.0mm VSYS and VSYS_SENSE power traces also connect to R44 pads — but separately, carrying load current to the rest of the power path

---

## Step 5: Protected_VBUS Path (USB-C → BQ24195)

```
J7 (USB-C) → VBUS_RAW → F2 → Protected_VBUS → C20/C21/C22 → U5 pins 1/24
```

### 5a. VBUS_RAW: J7 → F2 pad 1

| Width | Notes |
|---|---|
| 1.0mm (Power_Med) | Short run from USB-C connector to fuse |

### 5b. Protected_VBUS: F2 pad 2 → U5 pins 1/24

| From | To | Width |
|---|----|---|
| F2 pad 2 at (83.807, 110.859) | U5 pin 1 at (80.71, 121.0) and pin 24 at (81.5, 120.2) | 1.0mm (Power_Med) |

Route southward from F2 to U5. Connect C20 and C21 (input decoupling, near U5 at ~x=78) with short stubs off this trace. C22 (47µF at ~x=91-93) gets a longer stub — fine for bulk cap.

### 5c. CC1/CC2: J7 → R30/R31

0.25mm (Default). USB-C sink pull-downs to GND. Short, non-critical.

---

## Step 6: Battery Path

```
J8 pin 1 (BAT_RAW) → Q2 drain (pin 1) → Q2 source (pin 3, VBAT) → U5 pins 13-14
```

| Segment | Width |
|---|---|
| BAT_RAW (J8 → Q2) | 0.75mm (Power_Low) |
| VBAT (Q2 → U5 pins 13-14) | 0.75mm (Power_Low) |

Key positions:
- J8 pad 1 (BAT_RAW) at (70.0, 118.0)
- Q2 at (74.7, 114.3): pin 1 = BAT_RAW, pin 3 = VBAT
- U5 pins 13-14 (VBAT) at (84.79, 123.0/123.5)

R33 (VBAT → PMOS_GATE) and R34 (PMOS_GATE → BAT_RAW): 0.25mm signal traces, close to Q2.

C30 (47µF BAT_RAW bulk cap at ~68.7, 109.6): connects to BAT_RAW trace near J8.

---

## Step 7: +5V Output Distribution

U6 outputs +5V on pins 14-16 (left side, x=68.04, y=135.2–136.2).

### Output caps (C34/C35/C36)

Clustered at ~x=65. Connect with 1.5mm traces or a small +5V copper pour on F.Cu covering U6 output pins and the three caps.

**Each cap's GND pad needs a 0.6mm/0.3mm via to In1.Cu GND plane within 0.5mm of the pad.**

### +5V to the rest of the board

From the output cap cluster, reach:
- U1 (AP2112K) pins 1/3 (+5V) at ~(105, 124-126)
- F1 (LED fuse) pad 1 (+5V) at (105.55, 118.25)

**Use the In2.Cu +5V zone for long runs.** Drop a via from F.Cu to In2.Cu near U6's output, and a via from In2.Cu back to F.Cu near U1/F1. Avoids routing fat traces across the top layer.

---

## Step 8: VSYS_SENSE → U6 Input

| From | To | Width |
|---|----|---|
| R44 pad 2 (VSYS_SENSE) at (84.7, 130.9) | L2 pad 2 at (79.474, 136.456) and U6 pins 2/9 | 1.0mm (Power_Med) |

Full boost input current (~3A). Route from R44 pad 2 leftward and downward toward L2/U6. C31 and C41 (input caps) should connect to this trace close to U6.

---

## Step 9: U5 Support Passives

All 0.25mm (Default) traces unless noted. Short connections from U5 pins to nearby 0603 components.

| Net | U5 Pin(s) | Pin Location | Connect To |
|-----|---|---|---|
| BQ_REGN | 22 | (82.5, 120.2) | C24 |
| BQ_PMID | 23 | (82.0, 120.2) | C25, C26 |
| BQ_ILIM | 10 | (83.0, 124.3) | R32 |
| BQ_TS | 11-12 | (83.5–84.0, 124.3) | R36, R37, TH1 |
| CHRG_INT | 7 | (81.5, 124.3) | R38 (pull-up), also routes to sheet connector |
| OTG_BIAS | 8 | (82.0, 124.3) | R35 (pull-up to 3.3V) |
| I2C_SCL | 5 | (80.71, 123.0) | I2C bus — keep away from SW traces |
| I2C_SDA | 6 | (80.71, 123.5) | I2C bus — keep away from SW traces |

**Every cap's GND pad: drop a 0.6mm/0.3mm via to In1.Cu GND plane within 0.5mm of the pad.**

---

## Step 10: U6 Support Passives

| Net | U6 Pin | Pin Location | Connect To | Width |
|-----|---|---|---|---|
| BOOST_VCC | 1 | (70.52, 138.13) | C33 | 0.25mm |
| BOOST_SS | 10 | (70.52, 133.77) | C37 | 0.25mm |
| BOOST_FSW | 3 | (71.5, 137.2) | R41 | 0.25mm |
| BOOST_ILIM | 19 | (68.04, 137.7) | R42 | 0.25mm |
| **BOOST_FB** | **17** | **(68.04, 136.7)** | **R39 → R40 divider** | **0.2mm (Sensitive)** |
| **BOOST_COMP** | **18** | **(68.04, 137.2)** | **R43 → C38/C39** | **0.2mm (Sensitive)** |

### CRITICAL: FB and COMP routing

- Route on U6's **LEFT** side (toward board edge)
- SW and L2 are on U6's **RIGHT** side
- **Never cross FB/COMP traces with SW traces or route them near the inductor**
- Keep FB and COMP traces short and direct

---

## Step 11: Right-Side Connections (Existing Board)

The sensor connectors (J3-J6), TCA9548A, level shifter, and T-Display-S3 had some traces deleted during board resize. Re-route:

| Connection | Width | Notes |
|---|---|---|
| TCA I2C channels (CH0-CH2 SCL/SDA) → sensor connectors | 0.25mm | Signal traces |
| Main I2C bus (SCL/SDA): T-Display → TCA → U5 → U7 | 0.25mm | Keep away from power section SW nodes |
| LED data: DATA_IN → IC1 → DATA_TO_LEDS → J3 | 0.25mm | Signal |
| LED power: +5V → F1 → R27 → +5V_TO_LEDS | 1.0mm | Use Power_Med or +5V zone on In2.Cu for input side |
| INT lines (INT1-INT3) | 0.25mm | Signal |

---

## Step 12: Copper Pours and Zone Fills

After all traces are routed:

### 12a. Fill all zones (`B`) and verify:

- [ ] In1.Cu GND plane is continuous under U5, U6, L1, L2 (no trace cuts)
- [ ] In2.Cu +5V zone covers U6 output area through to U1/F1 area
- [ ] In2.Cu 3.3V zone covers right-side logic area
- [ ] B.Cu GND fill is solid

### 12b. Local GND pours on F.Cu

If there's unused space around U5 and U6, draw small copper zones on F.Cu assigned to GND extending ~5mm beyond each IC footprint. These improve thermal performance by connecting to GND plane through thermal vias.

### 12c. GND stitching vias

Place 0.6mm/0.3mm vias on GND every ~5-10mm:
- Around the board perimeter
- In any open areas between component clusters
- These tie top and bottom GND pours together and reduce EMI

---

## Step 13: Final DRC and Check

1. Run DRC (Inspect → Design Rules Check)
2. Target: zero clearance violations, zero unconnected items
3. **Expected remaining violations** (not routing issues):
   - J7 footprint-level: annular width, padstack, hole clearance (easyeda2kicad import)
   - Silkscreen overlaps (cosmetic)
4. Check 3D viewer (View → 3D Viewer) for physical sanity

---

## General Tips

- **`W` while routing** — cycle through pre-defined track widths
- **`V` while routing** — drop a via and switch layers
- **Route from the IC outward** to passives, not the other way around. Control the critical end of the trace.
- **Don't route signal traces under L1 or L2** on any layer. Inductor magnetic field couples into traces underneath.
- **When you hit a dead end** — note it, finish other traces, then revisit placement. This is normal.
- **Check ratsnest often** — hidden unconnected nets are easy to miss on a busy board.
- **Save frequently.** KiCad doesn't auto-save during routing.

---

## Quick Net Reference

| Net Class | Width | Clearance | Nets |
|---|---|---|---|
| **Power_5V** | 1.5mm | 0.3mm | `+5V`, `BOOST_SW` |
| **Power_Med** | 1.0mm | 0.3mm | `VSYS`, `VSYS_SENSE`, `Protected_VBUS`, `VBUS_RAW`, `BQ_SW`, `BQ_PMID`, `+5V_TO_LEDS`, `Net-(C7-Pad2)` |
| **Power_Low** | 0.75mm | 0.25mm | `VBAT`, `BAT_RAW`, `BQ_REGN` |
| **Power_3V3** | 0.5mm | 0.2mm | `+3.3V` |
| **Sensitive** | 0.2mm | 0.25mm | `BOOST_FB`, `BOOST_COMP`, `COMP_MID` |
| **Default** | 0.25mm | 0.2mm | Everything else |

## Component Position Reference

| Ref | Part | Position (x, y) | Key Pins |
|-----|---|---|---|
| U5 | BQ24195 | (82.75, 122.25) | Top: SW/BTST/REGN/PMID/PVBUS. Left: PVBUS/GND/I2C. Bottom: INT/OTG/ILIM/TS. Right: VBAT/VSYS/GND |
| U6 | TPS61088 | (69.77, 135.95) rot 90° | Right: VSYS_SENSE/FSW/SW×4/BOOT/VSYS_SENSE. Left: GND/MODE/+5V×3/FB/COMP/ILIM. Top: VCC/GND. Bottom: SS/GND |
| L1 | 2.2µH | (83.1, 114.35) rot 90° | Pad 1 (BQ_SW) at y=116.6, Pad 2 (VSYS) at y=112.1 |
| L2 | 2.2µH 10A | (76.474, 136.456) | Pad 1 (BOOST_SW) at x=73.5, Pad 2 (VSYS_SENSE) at x=79.5 |
| R44 | 10mΩ | (81.737, 130.9) | Pad 1 (VSYS) at x=78.8, Pad 2 (VSYS_SENSE) at x=84.7 |
| U7 | INA219 | (88.2, 130.9) rot 180° | Pin 1 (VSYS) at (87.0, 129.9), Pin 2 (VSYS_SENSE) at (87.0, 130.6) |
| J7 | USB-C | (80.67, 106.17) | VBUS pads at y≈108-109 area |
| J8 | JST PH | (67.15, 119) rot -90° | Pad 1 (BAT_RAW) at (70, 118), Pad 2 (GND) at (70, 120) |
| U1 | AP2112K | (106.535, 125.55) | Pin 1/3 (+5V input), Pin 5 (+3.3V output) |
| F1 | 3A fuse | (106.95, 118.25) | Pad 1 (+5V), Pad 2 (to R27) |
| F2 | 3A fuse | (82.407, 110.859) | Pad 1 (VBUS_RAW), Pad 2 (Protected_VBUS) |

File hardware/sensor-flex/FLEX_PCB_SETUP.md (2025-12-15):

# Flex PCB Setup Guide for sensor-flex

This guide covers setting up the sensor-flex PCB in KiCad for JLCPCB flex manufacturing.

## 1. Layer Stackup Configuration

### JLCPCB 2-Layer Flex PCB Standard Stackup

### With Stiffener (for 0.3mm FPC connector)

The C132510 ZIF connector requires 0.3mm FPC thickness. JLCPCB adds polyimide stiffener to achieve this:

- Flex core: ~0.11mm

- PI Stiffener: ~0.19mm

- **Total with stiffener: 0.3mm**

### KiCad Board Setup (File → Board Setup → Board Stackup)

- **Set Layer Count**: Click "Layer" on the left, set to **2 layers**

- **Edit Stackup**: Click "Physical Stackup" and configure:

```
Layers:
- F.SilkS: Top Silk Screen
- F.Paste: Top Solder Paste  
- F.Mask: Top Solder Mask (thickness: 0)  ← No coverlay opening in KiCad, handled by manufacturer
- F.Cu: copper (thickness: 0.012mm)
- dielectric 1: core
    - Material: Polyimide
    - Thickness: 0.05mm (accounts for PI + adhesive layers)
    - Epsilon_r: 3.4
    - Loss tangent: 0.002
- B.Cu: copper (thickness: 0.012mm)
- B.Mask: Bottom Solder Mask (thickness: 0)
- B.Paste: Bottom Solder Paste
- B.SilkS: Bottom Silk Screen

Board thickness: 0.11mm (KiCad calculates automatically)
Copper finish: ENIG (recommended for connector pads)
```

**Important**: The "User.1" layer is already renamed to "Stiffener" - use this for stiffener outlines.

---

## 2. Design Rules for Flex PCB

### Minimum Specifications (JLCPCB Flex Capabilities)

### Bend Zone Rules (Critical!)

- **Trace width in bend zone**: Increase to **0.2-0.3mm** (wider = more durable)

- **Trace angles**: Use **curved traces** (no 90° angles in bend area)

- **No vias in bend zone**: Vias are stress concentration points

- **Trace orientation**: Route traces **perpendicular** to bend axis

- **Component clearance**: Keep components **1.5mm minimum** from bend line

### KiCad Design Rules Setup

Go to **File → Board Setup → Design Rules**:

```
Constraints:
- Minimum clearance: 0.15mm
- Minimum track width: 0.15mm
- Minimum via diameter: 0.4mm (but avoid using vias)
- Minimum via drill: 0.2mm
- Minimum hole diameter: 0.2mm
- Minimum annular ring: 0.15mm

Pre-defined Sizes:
- Track widths: 0.15, 0.2, 0.25, 0.3mm
- Via size: 0.4/0.2mm (diameter/drill)

Net Classes:
- Default: 0.15mm track, 0.15mm clearance
- Power: 0.25mm track, 0.15mm clearance
- BendZone: 0.25mm track, 0.2mm clearance (custom class for bend area traces)
```

---

## 3. Stiffener Zones

### Purpose of Stiffeners

- **Connector tail**: Makes flex rigid enough to insert into ZIF connector (required for 0.3mm thickness)

- **Sensor areas**: Keeps VCNL4040 sensors flat and stable (component mounting)

- **Leave center flexible**: The bend zone (~5mm) remains unstiffened

### Stiffener Layout

```
┌─────────────────────────────────────────────────────────────┐
│                        FLEX PCB TOP VIEW                     │
│                                                               │
│  ┌─────────┐    ┌──────────────────┐    ┌─────────┐         │
│  │ SENSOR  │    │                  │    │ SENSOR  │         │
│  │  AREA   │    │    BEND ZONE     │    │  AREA   │         │
│  │ (stiff) │    │  (NO STIFFENER)  │    │ (stiff) │         │
│  │         │    │      ~5mm        │    │         │         │
│  │  IC1    │    │                  │    │  IC2    │         │
│  │  C4,C6  │    │    ↑ traces ↓    │    │  C8,C7  │         │
│  └─────────┘    └──────────────────┘    └─────────┘         │
│                                                               │
│  ┌───────────────────────────────────────────────────────┐  │
│  │              CONNECTOR TAIL AREA (stiff)               │  │
│  │   [10] [9] [8] [7] [6] [5] [4] [3] [2] [1]           │  │
│  │   GND GND SCL2 SDA2 INT2 GND SCL1 SDA1 INT1 3.3V     │  │
│  └───────────────────────────────────────────────────────┘  │
│                           ↓ BOARD EDGE                       │
└─────────────────────────────────────────────────────────────┘
```

### Drawing Stiffener Zones in KiCad

- Select the **"Stiffener" (User.1)** layer

- Use **Draw Rectangle** or **Draw Polygon** tools

- Draw closed shapes around:

- **Sensor area 1**: Around IC1 and its capacitors (C4, C6)

- **Sensor area 2**: Around IC2 and its capacitors (C8, C7)

- **Connector tail**: The entire FPC tail section (~4mm deep)

### Stiffener Dimensions

**Note**: When ordering, specify stiffener zones in the order notes or use a separate gerber layer.

---

## 4. Connector Tail Footprint

The custom footprint `FPC_Tail_10P_1.0mm_TopContact` is located at:

```
hardware/libraries/motion-play-footprints.pretty/FPC_Tail_10P_1.0mm_TopContact.kicad_mod
```

### Footprint Details

- **10 pads** (8 signal + 2 mechanical)

- **1.0mm pitch** for signal pads

- **Pads on TOP copper layer** (top-contact connector)

- **Signal pads**: 0.5mm × 2.5mm

- **Mechanical pads**: 1.5mm × 2.5mm

- **Board edge**: At Y=0 (pads extend from edge into board)

- **Stiffener zone indicator** on User.1 layer

### Pin Assignment

---

## 5. Routing Guidelines

### General Flex Routing

- **Minimize layer changes**: Use single-layer routing where possible

- **Curve all corners**: Use 45° or arc traces, never 90° angles

- **Match I2C lengths**: Keep SDA and SCL traces within 2mm of each other

- **Ground pour**: Add copper pour on unused areas (helps EMI and mechanical strength)

### Bend Zone Routing

```
GOOD (perpendicular to bend):        BAD (parallel to bend):
     
     ↓ bend axis                          ↓ bend axis
━━━━━━━━━━━━━━━━━━━━                 │ │ │ │ │ │ │ │
     │ │ │ │ │ │                     │ │ │ │ │ │ │ │
     │ │ │ │ │ │                     ↓ ↓ ↓ ↓ ↓ ↓ ↓ ↓
━━━━━━━━━━━━━━━━━━━━                 
```

### Trace Width Transitions

When transitioning from normal area to bend zone:

- Use **gradual taper** (45° angle)

- Don't create stress concentration points

```
Normal area → [taper] → Bend zone → [taper] → Normal area
   0.15mm      45°       0.25mm      45°       0.15mm
```

---

## 6. JLCPCB Ordering Specifications

### Flex PCB Order Parameters

### Order Notes to Include

When placing the order, add these notes:

```
FLEX PCB ORDER NOTES:
1. 2-layer polyimide flex PCB
2. Stiffener zones marked on User.1 layer (Stiffener layer in gerber)
3. Connector tail area requires 0.2mm PI stiffener (total 0.3mm for FPC connector)
4. Sensor areas require 0.1mm PI stiffener
5. Center bend zone (~5mm) - NO STIFFENER
6. ENIG finish on connector tail pads
7. FPC connector mating part: C132510 (1.0mm pitch, 8-pin, top contact)
```

### Gerber Files to Export

- F.Cu (Top copper)

- B.Cu (Bottom copper) - if used

- F.Mask (Top solder mask openings)

- B.Mask (Bottom solder mask openings)

- F.Paste (Top paste stencil)

- Edge.Cuts (Board outline)

- **User.1 / Stiffener** (Stiffener zones - export as separate layer)

- F.SilkS (Optional silkscreen)

### Cost Estimate

For a small flex PCB (~25mm × 15mm), qty 5:

- Base flex PCB: $15-25

- Stiffener: +$5-10

- ENIG: Included in flex pricing

- Setup fee (first order): ~$20

Total first prototype run: ~$40-60 for 5 pcs

---

## 7. Assembly Notes

### Component Placement

- **VCNL4040 sensors** (IC1, IC2):

- Place on stiffened areas only

- Position at least 1.5mm from bend line

- Ensure IR LED/sensor window faces outward (away from PCB center)

- **Bypass capacitors** (C4, C6, C7, C8):

- Place as close to sensor VDD pins as possible

- All on stiffened areas

- C4, C8: 2.2µF (LED anode capacitors)

- C6, C7: 0.1µF (VDD bypass)

### Hand Assembly

Flex PCBs require careful handling:

- Support the flex during soldering (use a flat surface)

- Lower soldering iron temperature if possible (~300°C)

- Avoid excessive force on components

- Don't bend the PCB until fully assembled and inspected

### Testing Before Bending

- Check continuity of all traces

- Verify I2C communication with both sensors (flat configuration)

- Check for shorts (especially on FPC connector pads)

- Then carefully bend to final angle

---

## 8. Checklist Before Manufacturing

- Layer count set to 2

- Stackup configured for polyimide

- Board thickness ~0.11mm

- Design rules set for flex (0.15mm min trace/space)

- No vias in bend zone

- Wider traces (0.25mm) in bend zone

- Curved traces only (no 90° angles)

- Components placed on stiffened areas only

- Stiffener zones drawn on User.1 layer

- FPC tail footprint at board edge

- Pads on correct layer (TOP for top-contact connector)

- ENIG surface finish specified

- Ground pour added (optional but recommended)

- DRC passes with no errors

---

*Last updated: December 11, 2025*

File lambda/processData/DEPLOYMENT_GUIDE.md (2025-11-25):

# processData Lambda Deployment Guide

## Bug Fix: Session Overwrite Issue

**Date**: November 21, 2025  
**Issue**: Sessions were losing labels, notes, and sample counts  
**Root Cause**: `PutCommand` was overwriting entire session when receiving duplicate `batch_offset=0` events

---

## The Problem

When the device sent data with `batch_offset=0` multiple times (due to retries, reconnections, or firmware bugs), the Lambda used `PutCommand` which **completely overwrites** the session record in DynamoDB, causing:

- ✗ User-added labels to disappear
- ✗ User-added notes to disappear  
- ✗ Sample count to reset to the new batch size (often "66")
- ✗ `created_at` timestamp to update, causing session list re-ordering

---

## The Fix

The updated `processData` Lambda now:

1. ✓ **Checks if session exists** before attempting to create it
2. ✓ **Uses UpdateCommand** (not PutCommand) when session exists
3. ✓ **Preserves user-editable fields**: `labels`, `notes`, `created_at`
4. ✓ **Updates system fields only**: `duration_ms`, `sample_count`, `end_timestamp`

### Code Changes

```javascript
// BEFORE (Buggy)
if (data.batch_offset === 0) {
    await docClient.send(new PutCommand({  // Overwrites everything!
        TableName: SESSIONS_TABLE,
        Item: sessionItem
    }));
}

// AFTER (Fixed)
if (data.batch_offset === 0) {
    const existing = await docClient.send(new GetCommand({
        TableName: SESSIONS_TABLE,
        Key: { session_id: data.session_id }
    }));
    
    if (existing.Item) {
        // Session exists - update only, preserve labels/notes
        await docClient.send(new UpdateCommand({
            TableName: SESSIONS_TABLE,
            Key: { session_id: data.session_id },
            UpdateExpression: 'SET #duration = :duration, #count = :count, ...',
            // ... (excludes labels, notes, created_at)
        }));
    } else {
        // Session doesn't exist - create new
        await docClient.send(new PutCommand({ ... }));
    }
}
```

---

## Deployment Steps

### 1. Test Locally

```bash
cd /Users/marcocleirigh/Workspace/motion-play/lambda
node test-fix-verification.js
```

Expected output:
```
🎉 SUCCESS! The fix works - user data is preserved!
```

### 2. Package the Lambda

```bash
cd processData
zip -r function.zip index.js package.json node_modules/
```

### 3. Deploy via AWS Console

1. Go to AWS Lambda Console
2. Select `motionplay-processData` function
3. Click "Upload from" → ".zip file"
4. Upload `function.zip`
5. Click "Save"

### 4. Deploy via AWS CLI

```bash
aws lambda update-function-code \
    --function-name motionplay-processData \
    --zip-file fileb://function.zip \
    --region us-east-1
```

### 5. Verify Deployment

Check CloudWatch Logs for:
```
Session already exists, updating (preserving labels/notes): device-001_XXXXX
```

---

## Testing in Production

### Scenario 1: New Session (Expected Behavior)
1. Device sends new session data with `batch_offset=0`
2. Lambda creates session with `PutCommand`
3. Session appears in UI with correct sample count

**Log Output**:
```
Creating new session: device-001_12345678
New session metadata stored
```

### Scenario 2: Duplicate batch_offset=0 (Bug Fix)
1. Device sends data with `batch_offset=0`
2. User adds labels/notes in UI
3. Device sends same session with `batch_offset=0` again (retry/bug)
4. Lambda detects existing session
5. Lambda updates using `UpdateCommand`
6. **Labels and notes are preserved!**

**Log Output**:
```
Session already exists, updating (preserving labels/notes): device-001_12345678
Session metadata updated (labels/notes preserved)
```

### Scenario 3: Subsequent Batch (Normal Operation)
1. Device sends data with `batch_offset=1`
2. Lambda increments `sample_count`
3. Labels/notes remain unchanged

**Log Output**:
```
Updated sample count for batch 1 (+50 readings)
```

---

## Rollback Plan

If the fix causes issues:

1. **Quick Rollback** (AWS Console):
   - Go to Lambda → Versions
   - Select previous version
   - Create alias pointing to old version

2. **CLI Rollback**:
```bash
aws lambda update-function-code \
    --function-name motionplay-processData \
    --zip-file fileb://function-backup.zip \
    --region us-east-1
```

3. **Re-deploy from git**:
```bash
git checkout <previous-commit>
cd lambda/processData
zip -r function.zip index.js package.json node_modules/
# Deploy as above
```

---

## Monitoring

### CloudWatch Metrics to Watch

1. **Lambda Duration**: Should increase slightly due to GetCommand check
   - **Before**: ~50ms average
   - **After**: ~75ms average (acceptable)

2. **Error Rate**: Should remain at 0%

3. **Invocation Count**: Should remain unchanged

### CloudWatch Logs - Important Patterns

**Good Signs** ✓:
```
Creating new session: device-001_XXXXX
Session already exists, updating (preserving labels/notes): device-001_XXXXX
```

**Red Flags** ✗:
```
Error retrieving session
ConditionalCheckFailedException
```

### CloudWatch Log Insights Query

To find sessions that were updated (not created):

```sql
fields @timestamp, @message
| filter @message like /Session already exists/
| stats count() by bin(5m)
```

To find potential duplicate batch_offset=0 events:

```sql
fields @timestamp, session_id
| filter @message like /batch_offset/ and batch_offset = 0
| stats count() by session_id
| filter count > 1
```

---

## Performance Impact

- **Additional DynamoDB Read**: +1 GetCommand per session
- **Cost Impact**: Negligible (~$0.0000025 per read)
- **Latency Impact**: +5-10ms per invocation
- **Benefit**: Prevents data loss and user frustration

---

## Future Improvements

1. **Add idempotency tokens** to device messages
2. **Track batch_offset sequence** to detect missing batches
3. **Add DynamoDB condition expressions** to prevent race conditions
4. **Implement batch deduplication** at IoT Rule level

---

## Questions?

- Check CloudWatch Logs: `/aws/lambda/motionplay-processData`
- Review test scripts: `test-overwrite-bug.js` and `test-fix-verification.js`
- See database schema: `infrastructure/DATABASE_SCHEMA.md`

---

**Last Updated**: November 21, 2025  
**Author**: Marc  
**Tested**: ✓ Local simulation passed

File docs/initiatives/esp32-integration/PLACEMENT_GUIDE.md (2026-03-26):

# ESP32 Integration — PCB Placement Guide

Component placement guide for the 20 new ESP32 integration components. Organized as a staged placement process — each stage is a logical group. Higher stages depend on lower ones being positioned first.

## Current Board Layout Reference

Board outline: 88mm × 40mm (x: 76–164, y: 101–141, Y-down)

Key anchors already positioned:
- **J7** (USB-C): (80.8, 119.6) rot -90° — left edge, data pads at x≈83.3
- **U5** (BQ24195): (96.9, 117.6) — power section
- **U4** (TCA9548A): (151.9, 114.0) — right half
- **J4/J5/J6** (sensor connectors): x≈161.3 — right edge
- **IC1** (level shifter): (148.8, 135.5)

## U3 Pin Map (at rotation 0°)

Understanding which pins are on which side is critical for support component placement.

```
                    ┌─────── ANTENNA (top, ~y=105) ───────┐
                    │         no pads, keepout zone        │
    LEFT (x≈120.8)  │                                      │  RIGHT (x≈138.3)
    ────────────────│──────────────────────────────────────│────────────────
    Pin 1   GND     │                                      │  Pin 40  GND
    Pin 2   +3.3V ★ │          GND pad (pin 41)            │  Pin 39  IO1
    Pin 3   EN ★    │          3×3 via array               │  Pin 38  IO2
    Pin 4   IO4     │          center of module             │  Pin 37  I2C_SDA ★
    Pin 5   IO5     │                                      │  Pin 36  I2C_SCL ★
    Pin 6   IO6     │                                      │  Pin 35  IO42
    Pin 7   IO7     │                                      │  Pin 34  IO41
    Pin 8   IO15    │                                      │  Pin 33  IO40
    Pin 9   LED_DATA★│                                      │  Pin 32  IO39
    Pin 10  IO17    │                                      │  Pin 31  IO38
    Pin 11  IO18    │                                      │  Pin 30  IO37
    Pin 12  IO8     │                                      │  Pin 29  IO36
    Pin 13  USB_DN ★│                                      │  Pin 28  IO35
    Pin 14  USB_DP ★│                                      │  Pin 27  GPIO0_BOOT ★
    ────────────────│──────────────────────────────────────│────────────────
                    │               BOTTOM (y≈127.4)       │
                    │  15  16  17  18  19  20  21  22  23  24  25  26
                    │  IO3 IO46 IO9 TCA INT3 INT2 INT1 IO14 CHRG IO47 IO48 IO45
                    │              RST★  (NC) (NC) (NC)     INT★
                    └──────────────────────────────────────┘
```

★ = active signal requiring a trace or support component nearby.

**Key takeaway:** Power/USB/LED signals exit the **left side**. I2C/boot exit the **right side**. TCA_RESET and CHRG_INT exit the **bottom**.

---

## Stage 1: U3 — WROOM-1 Module

**Priority: Highest — everything else positions relative to U3.**

### Constraints
1. **Antenna at board edge.** The antenna is the top of the module (at rot 0°). Position U3 so the antenna end is flush with or protruding past a board edge. The top edge (y=101) works well with the current rotation.
2. **Antenna keepout zone.** No copper pour, no traces, no ground plane, and no components in the antenna region. This covers the top ~5–8mm of the module body (roughly y < 110 at current position) plus 10–15mm past the antenna tip. If the antenna is at the board edge, the keepout extends into air — ideal.
3. **Ground plane under module body.** Solid unbroken ground plane under everything *except* the antenna section. Critical for RF performance.
4. **GND pad (pin 41) vias.** The center ground pad needs multiple vias (at least 9, matching the 3×3 sub-pad grid) connecting to the ground plane on the back layer. This is the primary thermal and electrical ground return.
5. **No high-frequency digital traces** routed under or near the antenna section.

### Position Recommendation

At the current position (129.6, 118.5) rot 0°, the antenna top is at approximately y≈105.2 — about 4mm inside the top edge. **Moving U3 up ~4mm** (to roughly y≈114.5) would put the antenna flush with the top edge, pushing the entire keepout zone off-board. This is the cleanest approach.

Alternatively, keep the current position and define an on-board keepout rectangle from x=120 to x=139, y=101 to y=110 (no fill, no traces).

### Orientation Check

At rot 0°:
- Left side → faces power section / J7 → good (USB, power, LED signals)
- Right side → faces U4 / sensor connectors → good (I2C, boot)
- Bottom → faces power switch area → acceptable (TCA_RESET, CHRG_INT)
- Top → antenna toward board edge → correct

This orientation routes signals toward their destinations with minimal crossing. No rotation change needed.

---

## Stage 2: U8 — AMS1117-3.3 + Caps

**Priority: High — thermal and power integrity.**

### Components
| Ref | Value | Net connections | Placement rule |
|-----|---|---|---|
| U8 | AMS1117-3.3 | VIN=+5V, VOUT=+3.3V, GND | Needs thermal copper pour on tab |
| C42 | 22µF ceramic (0805) | +5V → GND | Within 3mm of U8 pin 3 (VIN) |
| C43 | 22µF tantalum (Case-A) | +3.3V → GND | Within 3mm of U8 pin 2/4 (VOUT) |

### U8 Pad Map (at rot 0°)
```
    Pin 4 (VOUT/tab)          Pin 3 (VIN, +5V)     ← x≈116.7, y≈103.0
    large heatsink pad        Pin 2 (VOUT, +3.3V)   ← y≈105.3
    at x≈110.8                Pin 1 (GND)            ← y≈107.6
```

### Constraints
1. **Heatsink tab (pin 4):** Connect to +3.3V copper pour — this is the primary heat dissipation path. The bigger the pour, the better. The AMS1117 dissipates ~(5V−3.3V) × I_load as heat. At 500mA that's 850mW.
2. **C42 (input cap):** Place between pin 3 (+5V) and pin 1 (GND). As close as possible — this cap provides the instantaneous current during load transients.
3. **C43 (output cap, tantalum):** Place between pin 2/4 (+3.3V) and pin 1 (GND). This cap is **critical for AMS1117 stability** — the AMS1117 requires output capacitance with ESR in a specific range. Tantalum provides this. Keep the loop area small.
4. **Thermal vias** under the tab pad connecting to inner/back copper ground or power pour.

### Position Note
Current position (113.8, 105.3) places U8 between the power section and U3. The +5V rail (from TPS61088 output) and +3.3V rail (to U3 and the rest of the board) both route through this area — good location.

---

## Stage 3: U9 — USBLC6-2SC6 (USB ESD)

**Priority: High — must be the first thing USB data hits after J7.**

### Constraints
1. **As close to J7 as possible.** ESD protection effectiveness degrades with distance from the connector. Target: within 5mm of J7's D+/D- pads.
2. **Signal path order:** J7 → U9 → R52/R53 → U3. Never put the series resistors between J7 and U9.
3. J7's D+/D- pads are at (83.3, 119–120). U9 should go at approximately (86–90, 119–120) — just to the right of J7.

### U9 Pad Map (SOT-23-6)
```
Pin 1 (USB_DP)   Pin 6 (USB_DP)
Pin 2 (GND)      Pin 5 (GND)  
Pin 3 (USB_DN)   Pin 4 (USB_DN)
```
Symmetric — D+ goes in one side, out the other. Same for D−. Place it inline with the USB data path from J7.

---

## Stage 4: R52 + R53 — USB Series Resistors

**Priority: High — USB signal integrity.**

| Ref | Value | Net (pin 1 → pin 2) |
|-----|---|---|
| R52 | 22Ω | /USB_DN → /ESP32_S3/USB_DN_MCU |
| R53 | 22Ω | /USB_DP → /ESP32_S3/USB_DP_MCU |

### Constraints
1. **Between U9 and U3** in the signal path. Closer to U3 is preferred per Espressif guidelines.
2. **Maintain differential pair spacing.** Keep R52 and R53 at the same distance from U3's USB pins (13, 14 on the left side at x≈120.8, y≈124–126).
3. These are small 0603 parts — easy to tuck near U3's left side.

---

## Stage 5: ESP32 Decoupling + Pull-ups

**Priority: Medium — close to U3 but exact position is flexible.**

### Left Side Group (near pins 2, 3)
| Ref | Value | Purpose | Target pin |
|-----|---|---|---|
| C51 | 10µF | Bulk bypass | Pin 2 (+3.3V), x≈120.8, y≈110.8 |
| C52 | 100nF | CPU bypass | Pin 2 |
| C53 | 100nF | RTC bypass | Pin 2 |
| C54 | 100nF | SPI bypass | Pin 2 |
| C55 | 1µF | VDD_SPI bypass | Pin 2 |
| R50 | 10kΩ | EN pull-up | Pin 3 (EN), x≈120.8, y≈112.1 |
| C50 | 1µF | EN reset cap | Pin 3 (EN) |

**Placement:** Cluster these to the left of U3, just outside the pin row. All connect to +3.3V and GND, so they share power rails. Place C51 (largest value) closest to pin 2, then the 100nF caps in a row. R50 and C50 should be near pin 3 (EN).

### Right Side (near pin 27)
| Ref | Value | Purpose | Target pin |
|-----|---|---|---|
| R51 | 10kΩ | BOOT pull-up | Pin 27 (GPIO0), x≈138.3, y≈126.1 |

**Placement:** To the right of U3, near pin 27. Connects between +3.3V and GPIO0.

### Constraint
All bypass caps: keep within 5mm of the 3V3 pin (pin 2). Shorter traces = lower inductance = better high-frequency decoupling.

---

## Stage 6: SW2 + SW3 — Reset and Boot Buttons

**Priority: Medium — functional requirement, position is flexible.**

| Ref | Function | Connects to | U3 pin side |
|-----|---|---|---|
| SW2 | RESET | EN → GND | Left (pin 3) |
| SW3 | BOOT | GPIO0 → GND | Right (pin 27) |

### Constraints
1. **Accessible from board edge or enclosure.** These are user-facing buttons (first flash requires manual boot+reset sequence).
2. **Short traces to U3** — especially SW2 to EN, since long EN traces can pick up noise and cause resets.
3. SW2 naturally goes near the left/bottom of U3 (near pin 3). SW3 near the right/bottom (near pin 27).
4. Consider placing both along the same board edge for ergonomics.

---

## Stage 7: D5 — WS2812B Status LED

**Priority: Low — placement is flexible.**

| Net | Pin |
|-----|-----|
| LED_DATA (DIN) | Pin 1 |
| +5V (VDD) | Pin 2 |
| GND | Pin 4 |
| DOUT — NC | Pin 3 |

### Constraints
1. **Visible from outside the enclosure.** Top edge or near an enclosure opening.
2. Powered from +5V, data from LED_DATA (U3 pin 9, left side at x≈120.8, y≈119.7).
3. Keep the data line reasonably short (WS2812B protocol is timing-sensitive).
4. No strict electrical proximity requirement — it's a single addressable LED.

---

## Stage 8: SW1 — Power Slide Switch

**Priority: Low — already roughly positioned.**

Current position: (122.8, 133.4) near the bottom edge. Through-hole, 13.2mm wide.

### Constraints
1. **Board edge, accessible from enclosure.** Slider must protrude past the enclosure wall.
2. In the VSYS power path — connects VSYS to VSYS_SW. Trace width should handle system current (1A+). Use wide traces or copper pour.
3. No strict electrical proximity to other components — it's just a switch in a DC power path.

---

## Stage 9: TPIO21 — Test Point

**Priority: Lowest.** Place wherever convenient and accessible for probing. Connects to /CHRG_INT.

---

## USB D+/D- Routing Notes

After placement, the USB data path needs controlled-impedance routing:

1. **Differential impedance target: 90Ω.** Check your stackup — for standard JLCPCB 4-layer 1.6mm, typical differential pair geometry is ~0.2mm trace width with ~0.15mm gap on an outer layer over a ground plane.
2. **Route as a differential pair** from J7 → U9 → R52/R53 → U3 pins 13/14.
3. **Match trace lengths** within the pair — keep the length difference under 0.5mm.
4. **Avoid vias** in the USB data path if possible. If a via is unavoidable, use matched vias (both lines via together).
5. **Keep away from high-speed switching signals** (boost converter area, clock lines).
6. The series resistors (R52/R53) break the differential pair — route as a pair on both sides of the resistors.

## Antenna Keepout Zone

After U3 is in its final position, create a keepout zone in KiCad:

1. **Place → Keepout Area** (or draw a Rule Area on the copper layers).
2. Cover the antenna section of the module: the top ~8mm of the footprint body.
3. Extend the keepout 10–15mm past the antenna tip (if this is on-board; if antenna is at the board edge, it extends into air and no on-board keepout is needed past the edge).
4. The keepout should prohibit: copper fill, tracks, and vias.
5. Ground plane is fine *under the module body* but must stop before the antenna section begins.

---

*Generated from pcb-layout-context.json extracted on the current board state.*

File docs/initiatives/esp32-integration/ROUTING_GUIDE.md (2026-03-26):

# ESP32 Integration — Routing Priority Guide

Route in this order. Higher priority nets have stricter constraints.

## Priority 1 — USB Differential Pair

Route first — needs clear space and impedance control.

**Signal path:** J7 → U9 → R52/R53 → U3

| Segment | From | To | Net |
|---|---|----|-----|
| 1a | J7 pad A6/B6 | U9 pin 1/6 | /USB_DP |
| 1b | J7 pad A7/B7 | U9 pin 3/4 | /USB_DN |
| 2a | U9 pin 6 | R53 pin 1 | /USB_DP |
| 2b | U9 pin 4 | R52 pin 1 | /USB_DN |
| 3a | R53 pin 2 | U3 pin 14 (122.0, 125.4) | /USB_DP_MCU |
| 3b | R52 pin 2 | U3 pin 13 (122.0, 124.1) | /USB_DN_MCU |

**Rules:**
- Route as a differential pair — maintain consistent spacing between the two traces
- 90Ω differential impedance target (check trace geometry against your stackup)
- Match trace lengths within 0.5mm (D+ and D- should be the same length)
- Avoid vias; if unavoidable, via both traces together at the same point
- Keep clear of boost converter area (U6/L2 switching noise)
- Segments 1a/1b route south through J7's footprint area to U9
- Segments 2a/2b route east across the board to R52/R53
- Segments 3a/3b are short, R52/R53 to U3 left side

## Priority 2 — Power Rails

Wide traces for current handling. Use 0.5mm minimum width, wider where space allows.

| From | To | Net | Notes |
|---|----|-----|---|
| +5V rail (from TPS61088 output area) | U8 pin 3 (111.0, 105.8) | +5V | Short, direct |
| U8 pin 2/4 pour | U3 pin 2 (122.0, 110.2) | +3.3V | Via the +3.3V copper pour |
| U8 pin 2/4 pour | Existing +3.3V distribution | +3.3V | To caps, U4, sensors |
| VSYS source | SW1 pin 1 (101.4, 139.2) | VSYS | Carries full system current |
| SW1 pin 2 (96.7, 139.2) | R44, U7 | VSYS_SW | Wide trace or pour |
| +5V | D5 pin 2 (VDD) | +5V | 0.25mm OK |
| GND | All new component GND pins | GND | Via to ground plane |

## Priority 3 — ESP32 Support Circuits

Standard signal traces, 0.2–0.25mm width.

| From | To | Net | Notes |
|---|----|-----|---|
| +3.3V | R50 pin 1 | +3.3V | Short, near U3 |
| R50 pin 2 | U3 pin 3 (EN) | /ESP32_S3/EN | Keep short |
| C50 pin 1 | U3 pin 3 (EN) | /ESP32_S3/EN | Keep short |
| C50 pin 2 | GND | GND | Via nearby |
| SW2 pin 1 | U3 pin 3 (EN) | /ESP32_S3/EN | 19mm trace OK (R50+C50 filter noise) |
| SW2 pin 2 | GND | GND | Via nearby |
| +3.3V | R51 pin 1 | +3.3V | Short, near U3 |
| R51 pin 2 | U3 pin 27 (GPIO0) | /ESP32_S3/GPIO0_BOOT | Keep short |
| SW3 pin 1 | U3 pin 27 (GPIO0) | /ESP32_S3/GPIO0_BOOT | Short |
| SW3 pin 2 | GND | GND | Via nearby |
| C51–C55 | Between +3.3V and GND | +3.3V / GND | As short as possible to pin 2 |

## Priority 4 — Board Signal Connections

Connect U3 to existing board circuitry. Standard trace width.

| From | To | Net | Notes |
|---|----|-----|---|
| U3 pin 37 (139.5, 112.7) | U4 (TCA9548A) | /I2C_SDA | Route right from U3 |
| U3 pin 36 (139.5, 114.0) | U4 | /I2C_SCL | Keep near SDA |
| U3 pin 18 (127.6, 126.7) | U4 pin 3, R6 | /TCA_RESET | Bottom of U3 toward right |
| U3 pin 9 (122.0, 119.1) | D5 pin 1, IC1 | /LED_DATA | Left side of U3 |
| U3 pin 23 (133.9, 126.7) | R38, U5 pin 7 | /CHRG_INT | Bottom of U3 toward left |

## Priority 5 — Finishing

| Item | Notes |
|---|---|
| TPIO21 | Connect to /CHRG_INT net |
| Other test points | Verify existing connections still valid |
| U3 GND pad | Place 9 vias in the 3×3 sub-pad grid |
| U8 thermal vias | Place 4–6 vias in the +3.3V pour |
| Ground pour | Fill on all open areas after routing complete |

## Copper Pour Summary

| Component | Net | Purpose | Minimum size |
|---|-----|---|---|
| U8 heatsink tab | +3.3V | Thermal dissipation | Cover pins 2+4 area (~8×6mm) |
| U3 module body | GND | RF ground plane + thermal | Continuous under body, stop at antenna keepout |

## Trace Width Reference

| Category | Width | Where |
|---|---|---|
| USB differential pair | Per impedance calc | J7 → U9 → R52/R53 → U3 |
| Power rails (+5V, +3.3V, VSYS) | 0.5mm+ | All power connections |
| Standard signals | 0.2–0.25mm | I2C, LED_DATA, EN, BOOT, CHRG_INT |
| GND connections | Via to plane | Don't route GND as traces; use vias to ground pour |

---

*Reference: pad positions from pcb-layout-context.json extracted at current board state.*

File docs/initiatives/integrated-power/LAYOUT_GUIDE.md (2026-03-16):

# Integrated Power Management — PCB Layout Guide (Phase 5)

This document captures layout constraints, trace sizing, thermal management, and placement priorities for the power management section of the main PCB. Use when placing components in KiCad PCB editor.

---

## 1. Board Area & Placement Strategy

### Current Board: 85mm × 45mm

Power block estimated at ~830mm² (components + clearance + routing). This fits within the ~1,000-1,400mm² of available area, but is tight. Removing the DWEII module (J2) and Schottky (D1) frees ~150mm² additional space.

**Decision point:** If component placement or thermal pour requirements feel cramped, grow board to **90mm × 50mm**. This adds ~675mm² of usable area — a comfortable buffer.

### Placement Zones

Organize the power section into 4 zones, placed in rough order from USB-C input to output:

```
                    ┌─────────────────────────────────────────┐
                    │           EXISTING COMPONENTS            │
                    │  T-Display-S3, TCA9548A, AP2112K, etc.  │
                    │                                          │
                    ├─────────────────────────────────────────┤
                    │                                          │
  ┌──────────┐      │  ┌────────────┐   ┌────────────┐        │
  │  USB-C   │      │  │  BQ24195   │   │  TPS61088  │        │
  │  + Fuse  │──────│──│  + L1, Q2  │──→│  + L2      │──→ +5V │
  │  J7, F2  │      │  │  + caps    │   │  + caps    │        │
  └──────────┘      │  └────────────┘   └────────────┘        │
   CC pulldowns,    │                                          │
   decoupling       │  ┌─────────┐  ┌────────────┐            │
                    │  │  J8 BAT │  │  INA219    │            │
                    │  │  + Q2   │  │  + R_SHUNT │            │
                    │  └─────────┘  └────────────┘            │
                    │  Test Points: TP1-TP4 along board edge   │
                    └─────────────────────────────────────────┘
```

**USB-C connector (J7):** Place at board edge. The connector has a fixed orientation — the receptacle opening must face outward.

**Battery connector (J8):** Place at board edge, accessible for JST PH plug.

---

## 2. Critical Placement Rules

### 2.1 TPS61088 Boost Converter — Tightest Layout

The TPS61088 is a 2.2MHz switching converter. Loop inductance is the primary layout concern.

1. **L2 (2.2µH 10A inductor) must be as close as possible to U6 pins 4-7 (SW)**. Minimize the trace length between L2 pad 1 and U6 SW pins. Ideally <5mm trace length, <3mm preferred.

2. **Output caps (C34, C35, C36 — 22µF 0805) must be close to U6 pins 14-16 (+5V)**. Place within 5mm of the IC output pins.

3. **Input cap (C41 — 10µF 0805, C31 — 100nF) must be close to U6 pins 2/9 (VIN/EN)**. The 100nF cap (C31) should be the closest to the IC pins.

4. **Bootstrap cap (C32 — 100nF) connects BOOT (pin 8) to SW (pins 4-7)**. Keep this trace short and direct.

5. **Feedback divider (R39/R40):** Place close to U6 pin 17 (FB). Route the FB trace away from the SW node and inductor. Keep FB trace short and away from noisy nodes.

6. **Compensation network (R43, C38, C39):** Place close to U6 pin 18 (COMP). These are small-signal — keep away from power traces.

### 2.2 BQ24195 — Moderate Layout Sensitivity

1. **L1 (2.2µH) connects to U5 pins 19-20 (SW) and feeds VSYS**. Place L1 close to the BQ24195.

2. **Bootstrap cap (C23 — 47nF) connects BTST (pin 21) to SW (pins 19-20)**. Short trace.

3. **PMID caps (C25, C26 — 10µF each) connect to pin 23**. Place close.

4. **VSYS bulk capacitors (C27, C28 — 10µF, C29 — 220µF):** Place near U5 pins 15-16 (VSYS). The electrolytic (C29) can be slightly further away but should still be within 10-15mm.

5. **Input caps on Protected_VBUS (C20, C21, C22):** Place between the fuse (F2) and U5 pins 1/24 (IN).

### 2.3 INA219 + Shunt Resistor

1. **R44 (10mΩ 2512) is in-line on the VSYS rail**. The current path from BQ24195 VSYS output to TPS61088 VIN flows through this shunt.

2. **U7 Kelvin connections:** INA219 pins 1 (VIN+) and 2 (VIN-) should connect to opposite sides of R44 with separate traces (4-wire Kelvin sense). Do NOT tap the sense lines from the main current path — run dedicated thin traces from the R44 pads directly to U7 pins 1 and 2.

3. **C40 (100nF) bypass:** Place on U7 pin 4 (VS), close to IC.

### 2.4 PMOS Reverse Polarity Protection (Q2)

Place Q2 near J8 (battery connector). R33 and R34 (gate bias) should be close to Q2.

---

## 3. Trace Width Calculations

For 1 oz copper (35µm thickness), outer layer, 10°C temperature rise:

| Current | Min Width (1oz) | Recommended | Traces |
|---|---|---|---|
| 3A | 0.76mm | **≥1.0mm** | +5V output, VSYS power, Protected_VBUS |
| 2A | 0.45mm | **≥0.75mm** | VBAT, BAT_RAW |
| 1.5A | 0.30mm | **≥0.5mm** | VBUS_RAW (USB input to fuse) |
| <0.5A | 0.15mm | **≥0.25mm** | I2C_SDA, I2C_SCL, CHRG_INT, all signal traces |

### Specific Trace Recommendations

| Net | Expected Current | Width | Notes |
|-----|---|---|---|
| **+5V** (boost output to rest of board) | up to 3A+ | **1.5mm** or polygon fill | Main power distribution — widest trace on the board |
| **VSYS** (BQ24195 to shunt to TPS61088) | up to 3A | **1.0-1.5mm** | Carries full system current |
| **VSYS_SENSE** (post-shunt to TPS61088 VIN) | up to 3A | **1.0-1.5mm** | Same current as VSYS |
| **Protected_VBUS** (fuse to BQ24195 IN) | up to 3A | **1.0mm** | USB input current |
| **VBUS_RAW** (USB-C to fuse) | up to 3A | **1.0mm** | Short run from connector |
| **BQ_SW** (switching node) | pulsed 4.5A | **1.0mm** | Keep short, minimize loop area |
| **BOOST_SW** (TPS61088 switching node) | pulsed 6A+ | **1.5mm** | CRITICAL: keep short, minimize loop area with GND return |
| **VBAT / BAT_RAW** | up to 2A charge | **0.75mm** | Battery charge current |
| **GND** | — | **Ground plane** | Unbroken ground plane under entire power section |

### Switching Node Traces (BQ_SW, BOOST_SW)

These carry high-frequency pulsed current. Rules:
- Keep as short as possible (minimize loop area)
- Route on the same layer as the IC and inductor (avoid vias in the power path)
- The GND return path should be directly underneath on the adjacent layer (ground plane)
- Do NOT route sensitive signal traces (FB, COMP, I2C) near switching nodes

---

## 4. Thermal Management

### 4.1 TPS61088 Thermal Pad

The TPS61088 (VQFN-20-EP) has an exposed thermal pad on the bottom. At 3A output from ~3.5V VSYS:
- **Estimated dissipation:** ~1.5W (at ~85% efficiency)
- **RθJA with good layout:** 29.7°C/W → Tj = Tambient + 44.5°C → ~85°C at 40°C ambient

**Requirements:**
- Connect exposed pad to GND plane via **multiple thermal vias** (array of 4-6 vias, 0.3mm drill, within the EP footprint)
- **Copper pour on top layer** under U6 connected to GND — at least 5mm beyond IC footprint in all directions
- Bottom layer GND plane should be solid under U6

### 4.2 BQ24195 Thermal Pad

The BQ24195 (VQFN-24-EP) also has an exposed thermal pad. Dissipation depends on operating mode:
- **Charging at 2A:** ~1-2W typical
- **Buck mode (VBUS→VSYS):** ~0.5W
- **Supplementing mode (VBUS + BAT → VSYS):** ~0.3W

**Requirements:**
- Connect exposed pad to GND plane via **multiple thermal vias** (array of 4-6 vias, 0.3mm drill)
- **Copper pour on top layer** under U5 connected to GND — at least 3-5mm beyond IC footprint
- Bottom layer GND plane should be solid under U5

### 4.3 Shunt Resistor (R44)

10mΩ 2512 dissipates up to 0.36W at 6A. The 2512 package (6.3×3.2mm) handles this easily. No special thermal relief needed, but ensure adequate copper on both pads for current carrying capacity.

### 4.4 Inductor Thermal

L2 (FXL0630-2R2-M, 7×6.6mm) dissipates ~0.5W at 3A DC (15mΩ DCR × 3A²). Acceptable without additional thermal relief.

L1 (SMNR6028-2R2MT, 6×6mm) dissipates ~0.1W at 2A DC (26mΩ DCR). Negligible.

---

## 5. Ground Plane Strategy

**An unbroken ground plane is the single most important layout decision for this power section.**

1. **Dedicate one full inner layer (or the bottom layer on a 2-layer board) as ground.** No signal routing should split the ground plane under the power section.

2. **Ground vias near every bypass cap:** Every decoupling cap GND pad should have a via to the ground plane within 0.5mm.

3. **Star grounding is NOT needed** for this design — a solid ground plane with short return paths is sufficient.

4. **High-current ground return:** The boost converter and BQ24195 switching currents return through the ground plane. Ensure the ground plane copper under L2 and U6 is continuous and not interrupted by signal traces.

---

## 6. Specific Component Footprint Notes

| Component | Footprint | Special Notes |
|---|---|---|
| U5 BQ24195 | VQFN-24-EP (4×4mm, 0.5mm pitch) | Exposed pad → GND, thermal vias required |
| U6 TPS61088 | VQFN-20-EP (3.6×4.6mm, 0.5mm pitch) | Exposed pad → GND, thermal vias required |
| U7 INA219 | SOT-23-8 | No exposed pad, standard SOT-23-8 |
| L2 boost inductor | IND-SMD_L7.0-W6.6 | Largest component, 7×6.6mm footprint |
| C29 220µF electrolytic | CP_Elec_6.3x7.7 | Tallest component (~7.7mm), check enclosure clearance |
| R44 10mΩ shunt | R_2512_6332Metric | 6.3×3.2mm, needs wide traces to pads |
| J7 USB-C | USB-C_SMD-TYPE-C-31-M-12 | Board edge placement, mechanical anchoring tabs |

---

## 7. DRC Settings for Power Section

Suggested KiCad DRC overrides for power nets:

| Parameter | Default | Power Nets |
|---|---|---|
| Min trace width | 0.2mm | 1.0mm for +5V, VSYS, VSYS_SENSE, Protected_VBUS |
| Min clearance | 0.2mm | 0.3mm (higher voltage switching nodes) |
| Min via drill | 0.3mm | 0.3mm (standard for thermal vias) |
| Via annular ring | 0.15mm | 0.15mm |

---

## 8. Board Stackup Recommendation

For the power section, **2-layer is possible but 4-layer is strongly recommended:**

| Option | Pros | Cons |
|---|---|---|
| **2-layer** | Cheaper ($2-5 at JLCPCB qty 5) | Ground plane interrupted by signal routing; harder to achieve good thermal performance |
| **4-layer** (recommended) | Dedicated inner GND plane, better thermal vias, cleaner signal routing | ~$8-15 more at JLCPCB qty 5 |

If staying with 2-layer, maximize the bottom-layer ground pour and avoid routing signals through the power section ground plane area.

---

## 9. Pre-Layout Checklist

- [ ] Confirm board dimensions (85×45mm or expand to 90×50mm)
- [ ] Place USB-C connector at board edge
- [ ] Place battery connector at board edge
- [ ] Place TPS61088 + L2 close together (SW trace <5mm)
- [ ] Place BQ24195 + L1 close together
- [ ] Place INA219 + R44 in-line on VSYS path (Kelvin sense)
- [ ] Add thermal via arrays under U5 and U6 exposed pads
- [ ] Create copper pour zones for U5 and U6 thermal relief
- [ ] Set trace widths per §3 table
- [ ] Verify ground plane continuity under power section
- [ ] Check C29 (220µF, 7.7mm tall) fits within enclosure height
- [ ] Place test points (TP1-TP4) at board edge for probe access
- [ ] Run DRC with power net width constraints

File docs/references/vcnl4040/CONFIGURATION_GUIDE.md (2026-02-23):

# VCNL4040 Configuration Guide
## Understanding the Settings for Optimal Performance

Based on analysis of the Vishay VCNL4040 design guide, datasheet, and testing with Motion Play hardware.

---

## TL;DR - Quick Reference

**For Motion Play (fast sample rate + good detection):**
```cpp
Integration Time: 2T           // Good signal, 100 Hz at 1/40 duty
Duty Cycle: 1/40               // Maximum measurement rate
Multi-Pulse: x4                // 4× signal boost, no rate penalty
LED Current: 200mA             // Maximum detection range
High Resolution: true          // 16-bit for better precision
```

---

## The Three Controls That Matter

### 1. Integration Time (PS_IT) — Controls PULSE LENGTH, SENSITIVITY, AND RATE

Each measurement fires an IR pulse of this duration. Longer pulses collect more photons (stronger signal) but take longer, directly reducing the measurement rate.

| Setting | Pulse Width | Rate @ 1/40 duty | Signal Strength |
|---|---|---|---|
| 1T | 125 μs | **200 Hz** | Baseline |
| 1.5T | 187.5 μs | **133 Hz** | 1.5× |
| 2T | 250 μs | **100 Hz** | 2× |
| 2.5T | 312.5 μs | **80 Hz** | 2.5× |
| 3T | 375 μs | **67 Hz** | 3× |
| 3.5T | 437.5 μs | **57 Hz** | 3.5× |
| 4T | 500 μs | **50 Hz** | 4× |
| 8T | 1000 μs | **25 Hz** | 8× |

> **Note on pulse width:** Some Vishay documentation says "about 100 μs" for 1T. The actual value measured on oscilloscope is 125 μs (see designingvcnl4040.txt lines 438, 461). All calculations use 125 μs.

### 2. Duty Cycle (PS_Duty) — Controls MEASUREMENT PERIOD

The duty cycle denominator multiplies the pulse width to set the total measurement period:

```
Measurement Period ≈ Pulse Width × Duty Denominator
Measurement Rate ≈ 1 / Period
```

| Duty Cycle | Multiplier | Period @ 1T | Rate @ 1T | Period @ 2T | Rate @ 2T |
|---|---|---|---|---|---|
| 1/40 | ×40 | ~5 ms | ~200 Hz | ~10 ms | ~100 Hz |
| 1/80 | ×80 | ~10 ms | ~100 Hz | ~20 ms | ~50 Hz |
| 1/160 | ×160 | ~20 ms | ~50 Hz | ~40 ms | ~25 Hz |
| 1/320 | ×320 | ~40 ms | ~25 Hz | ~80 ms | ~12.5 Hz |

> **Confidence: Medium.** This formula is derived from the Vishay design guide, not explicitly stated. The design guide says 1T/1/40 yields measurements "every 4.85 ms" (line 430), while our formula gives 5.0 ms. It also confirms proportionality: "These pulse lengths are always doubled... but the repetition time is also doubled" (lines 439-441). The formula is a close approximation (~3% error at 1T/1/40) but may not be exact.

**Both IT and duty cycle directly determine the measurement rate.** There is no way around this — longer integration time = slower rate at the same duty cycle.

### 3. Multi-Pulse (PS_MPS) — SIGNAL BOOST (LIKELY NO RATE PENALTY)

Multi-pulse fires 1/2/4/8 consecutive IR pulses per measurement and accumulates the result. This boosts signal strength and is believed to not affect the measurement rate because all pulses fit within the measurement period.

| Setting | Pulses | Signal Boost | Rate Impact |
|---|---|---|---|
| x1 | 1 | 1× | None (believed) |
| x2 | 2 | ~2× | None (believed) |
| x4 | 4 | ~4× | None (believed) |
| x8 | 8 | ~8× | None (believed) |

> **Confidence: Medium.** The Vishay datasheet and design guide say nothing about how PS_MPS affects measurement timing. The best evidence comes from the Linux kernel IIO driver (Astrid Rost, Axis Communications, 2023): *"Instead of one single pulse per every defined time frame, one can program 2, 4, or even 8 pulses."* The phrase "per every defined time frame" implies the period is fixed and multi-pulse fires within it. However, this is a third-party interpretation, not a Vishay specification. Empirical testing on our hardware is recommended to confirm.

---

## Full Rate Table (at 1/40 duty)

| IT | x1 Rate | x1 Signal | x4 Rate | x4 Signal | x8 Rate | x8 Signal |
|----|---|---|---|---|---|---|
| 1T | 200 Hz | 1× | 200 Hz | ~4× | 200 Hz | ~8× |
| 2T | 100 Hz | 2× | 100 Hz | ~8× | 100 Hz | ~16× |
| 4T | 50 Hz | 4× | 50 Hz | ~16× | 50 Hz | ~32× |
| 8T | 25 Hz | 8× | 25 Hz | ~32× | 25 Hz | ~64× |

**Key insight (if multi-pulse is rate-free as believed):** Multi-pulse gives you the signal boost of a higher IT without the rate penalty. `1T/x8` would give ~8× signal at 200 Hz, while `8T/x1` also gives ~8× signal but at only 25 Hz.

---

## From the Vishay Design Guide

### Integration Time (Lines 537-543)
> "If higher detection distances and / or objects with very low reflectivity should be detected, there is the option to extend these proximity pulses up to about 1000 μs for 8T. This results in higher counts"

- 8T can achieve 10,000+ counts vs 1,000 counts with 1T (see Fig 14 vs Fig 15)
- Better SNR because more photons are collected per pulse

### Duty Cycle (Lines 515-520, 564-569)
> "With defining the duty time (PS_Duty), the repetition rate = the number of proximity measurements per second (speed of proximity measurements) is defined. This is possible between 5 ms (about 200 measurements/s) by programming PS_Duty with 1/40 and 40 ms (about 25 measurements/s) with programming PS_Duty with 1/320."

Note: The "5 ms → 200 Hz" figure is for 1T integration time. With longer IT, the period increases proportionally. Also note the design guide says "4.85 ms" for 1T/1/40 (line 430), not exactly 5 ms.

---

## Configuration Strategy for Motion Play

### The Trade-off

You need **enough samples per transit** to form a clear detection wave. For a ball traveling at up to 13.4 m/s (30 mph) through a 450mm hoop with a size 3 ball (190mm), the transit takes ~14 ms. At that speed:

| Config | Rate | Samples per transit | Verdict |
|---|---|---|---|
| 1T/x4 @ 1/40 | 200 Hz | 2.8 | Marginal |
| 2T/x4 @ 1/40 | 100 Hz | 1.4 | Likely missed |
| 1T/x8 @ 1/40 | 200 Hz | 2.8 | Marginal (best signal) |

For typical throws (5-8 m/s), transit takes ~24-38 ms:

| Config | Rate | Samples @ 8 m/s | Samples @ 5 m/s |
|---|---|---|---|
| 1T/x4 @ 1/40 | 200 Hz | 4.8 | 7.6 |
| 2T/x4 @ 1/40 | 100 Hz | 2.4 | 3.8 |
| 1T/x8 @ 1/40 | 200 Hz | 4.8 | 7.6 |

### Recommended Configurations

**Best for fast objects (speed priority):**
```
Integration Time: 1T
Multi-Pulse: x8            // Compensate with multi-pulse for signal
Duty Cycle: 1/40
LED Current: 200mA
→ 200 Hz, ~8× signal
```

**Best balance (recommended starting point):**
```
Integration Time: 2T
Multi-Pulse: x4
Duty Cycle: 1/40
LED Current: 200mA
→ 100 Hz, ~8× signal
```

**Best for slow/weak objects (sensitivity priority):**
```
Integration Time: 4T
Multi-Pulse: x4
Duty Cycle: 1/40
LED Current: 200mA
→ 50 Hz, ~16× signal
```

Use `python3 tools/transit-calculator.py` to model samples-per-transit for your specific setup.

---

## Power Consumption

For Motion Play (USB-powered), power is not a concern. Use 1/40 duty cycle.

For reference, at 200mA LED current:
- **1/40 duty**: Avg LED current = 200mA / 40 = **5.0 mA**
- **1/320 duty**: Avg LED current = 200mA / 320 = **0.625 mA**

---

## I2C Pipeline

The firmware reads all 6 sensors sequentially through a TCA9548A → PCA9546A mux chain at 400 kHz I2C. A complete read cycle takes ~1.8 ms (~549 polls/sec), which is faster than the sensor's measurement rate at all practical settings.

**The sensor's internal measurement rate is always the bottleneck, not the I2C pipeline.**

See `SENSOR_READING_PIPELINE.md` for the complete timing analysis with sequence diagrams.

---

## Current Configuration Status

- ✅ Integration Time: Exposed in cloud config
- ✅ LED Current: Exposed in cloud config
- ✅ Duty Cycle: Exposed in cloud config (default: 1/40)
- ✅ Multi-Pulse: Exposed in cloud config
- ✅ High Resolution: Exposed in cloud config

---

## Evidence & References

### Primary Sources (Vishay)
- **Design Guide** (`designingvcnl4040.txt`) — Contains oscilloscope measurements (1T = 125 μs), duty cycle timing data (1T/1/40 = 4.85 ms), and the proportionality statement for IT vs repetition time. Does NOT mention PS_MPS at all.
- **Datasheet** (`vcnl4040_datasheet_text.txt`) — Register definitions only. PS_MPS described as "Proximity multi pulse numbers: 1, 2, 4, 8 multi pulses" with no timing information.

### Third-Party Sources
- **Linux kernel IIO driver** — [Patch series by Astrid Rost (Axis Communications, May 2023)](https://patchew.org/linux/20230517151406.368219-1-astrid.rost@axis.com/). Treats PS_MPS as "oversampling_ratio" and describes it as firing multiple pulses "per every defined time frame." Treats IT, duty cycle, and multi-pulse as independent parameters.

### Project Tools
- Sensor Reading Pipeline (`SENSOR_READING_PIPELINE.md`)
- Transit Calculator (`tools/transit-calculator.py`)

---

*Last Updated: February 2026*

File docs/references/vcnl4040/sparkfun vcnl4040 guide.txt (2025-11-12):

Introduction
The Qwiic Proximity Sensor is a simple IR presence and ambient light sensor utilizing the VCNL4040. This sensor is excellent for detecting if something has appeared in front of the sensor; detecting objects qualitatively up to 20cm away. This means you can detect if something is there, and if it is closer or further away since the last reading, but it’s difficult to say it is 7.2cm away. If you need quantitative distance readings for exact distances, check out the SparkFun 2 meter and 4 meter Time of Flight (ToF) sensors with mm accuracy.

SparkFun Proximity Sensor Breakout - 20cm, VCNL4040 (Qwiic)
SparkFun Proximity Sensor Breakout - 20cm, VCNL4040 (Qwiic)
SEN-15177
$8.50
We often see this type of sensor on automatic towel dispensers, automatic faucets, etc. However, the VCNL4040 has no dead zone and can read all the way up to the face of the sensor. The SparkFun Proximity VCNL4040 sensor is a great digital alternative to the popular analog PIR sensors. The Qwiic Proximity Sensor also has an ambient light sensor built it which is excellent if you need a digital light sensor for your next glitter cannon.

This board is one of our many Qwiic compatible boards! Simply plug and go. No soldering, no figuring out which is SDA or SCL, and no voltage regulation or translation required!

Required Materials
The Qwiic Proximity Sensor does need a few additional items for you to get started. You may already have a few of these items, so feel free to modify your cart as necessary.

SparkFun Qwiic Cable Kit
SparkFun Qwiic Cable Kit
KIT-15081
$12.95
SparkFun RedBoard Qwiic
SparkFun RedBoard Qwiic
DEV-15123
$21.95
Suggested Reading
If you're unfamiliar with jumper pads or I2C be sure to checkout some of these foundational tutorials.

Logic Levels
Learn the difference between 3.3V and 5V devices and logic levels.
I2C
An introduction to I2C, one of the main embedded communications protocols in use today.
How to Work with Jumper Pads and PCB Traces
Handling PCB jumper pads and traces is an essential skill. Learn how to cut a PCB trace, add a solder jumper between pads to reroute connections, and repair a trace with the green wire method if a trace is damaged.

Qwiic Connect System
The Qwiic Proximity Sensor utilizes the Qwiic connect system. We recommend familiarizing yourself with the Logic Levels and I2C tutorials (above) before using it. Click on the banner above to learn more about our Qwiic products.

Hardware Overview
Note: If you want to do anything outside of what is covered in this tutorial or the example code, please refer to the VCNL4040 datasheet for exact details on the sensor functionality.
Power LED
There is a power status LED to help make sure that your Qwiic Joystick is getting power. You can power the board either through the polarized Qwiic connector system or the breakout pins (PWR and GND) provided. This Qwiic system is meant to use 3.3V, be sure that you are NOT using another voltage when using the Qwiic system.

Power LED
VCNL4040 Sensor
The VCNL4040 is a proximity sensor (PS), ambient light sensor (ALS), and a high power IR emitter (IRED) integrated into a single package. The ambient light sensor and proximity sensor operate in a parallel structure. The combination of the two sensors along with the IR emitter form the proximity detector.

VCNL4040 Sensor
The sensor has an operating voltage range from 2.5V to 3.6V. It is recommended that you use this board with the intended 3.3V of the Qwiic connect system. The VCNL4040 also includes excellent temperature compensation. For any details not covered in this guide, please refer to the datasheet.

Note: This sensor is excellent for detecting qualitative changes (if an object is there or moved since the last reading). If you need quantitative distance readings, like exact distances, check out the SparkFun 2 meter and 4 meter Time of Flight (ToF) sensors with mm accuracy.
IR Emitter
The IR emmiter is immune to red glow with a 940 nm wavelength (for those discrete applications) and the sink current is programmable (200 mA default). For more details on the IR emitter, please refer to the datasheet.

Ambient Light Sensor (ALS)
The VCNL4040 offers a 16-bit high resolution ALS with ±10 % accuracy and is immune to fluorescent light flicker. With an ambient light sensing capability down to 0.01 lux/step, the VCNL4040 works well under a low transmittance lens design (dark lens). In addition, the patented FiltronTM technology offers great background light cancellation capability (including sunlight) without utilizing microcontroller resources.

Proximity Sensor (PS)
The proximity sensor features smart persistence, which prevents the misjudgment of proximity sensing but also keeps a fast response time. In active force mode, a single measurement can be requested for more design flexibility and/or power saving.

Qwiic or I2C
I2C Address
The sensor has a single slave address 0x60 (HEX) of 7-bit addressing, following I2C protocol.

Connections
The simplest way to use the Qwiic Proximity Sensor is through the Qwiic connect system. The connectors are polarized for the I2C connection and power. (*They are tied to their corresponding breakout pins.)

Qwiic Connectors
However, the board also provides five labeled breakout pins. You can connect these lines to the I2C bus of your microcontroller and power pins (3.3V and GND), if it doesn't have a Qwiic connector. The interrupt pin is broken out to use for triggered events.

Breakout Pins
Interrupt Pin
High and low interrupt thresholds can be programmed for both the ambient light sensor and proximity sensor, allowing the component to use a minimal amount of the microcontrollers resources. Adjustable persistence sets up the amount of consecutive hits required before an interrupt event occurs, to prevent false triggers.

The VCNL4040 also supports an easy to use proximity detection logic mode, that triggers when the PS high threshold is exceeded and automatically resets the interrupt pin when the proximity reading falls beneath the PS low threshold.

An interrupt can be cleared by reading data out from the INT_Flag register (resetting it to "0") and the INT pin is then reset to high. For more details on the interrupt, please refer to the datasheet.
Interrupt Jumper
Cutting the INT jumper will remove the 10 kΩ pull-up resistor from the INT pin.
Interrupt Jumper
I2C Pull-up Jumper
Cutting the I2C jumper will remove the 2.2 kΩ pull-up resistors from the I2C bus. If you have many devices on your I2C bus you may want to remove these jumpers. Not sure how to cut a jumper? Read here!

Pull-up Jumper
Hardware Assembly
With the Qwiic connector system, assembling the hardware is simple. All you need to do is connect your Qwiic Proximity Senor to the RedBoard Qwiic with a Qwiic cable. Otherwise, you can use the I2C pins, if you don't have a Qwiic connector on your microcontroller board. Just be aware of your input voltage and any logic level shifting you may need to do.

Hardware connection
Arduino Library
Note: This example assumes you are using the latest version of the Arduino IDE on your desktop. If this is your first time using Arduino, please review our tutorial on installing the Arduino IDE. If you have not previously installed an Arduino library, please check out our installation guide.
We’ve written an Arduino library to flex every feature of this sensor. You can grab it from the Arduino Library Manager by searching for 'SparkFun VCNL4040'. Otherwise you can get it from the GitHub repository or use the download button below.

Library Functions
The Arduino library is commented and the functions should be self-explanatory. However, below is a detailed list of the available library functions.

Note: It is recommended that users begin with the examples in the following section before diving head first into the library functions. The library examples demonstrate how to setup the more basic features of the VCNL4040 without having to dig through the datasheet. Once users have become familiar with the basic setups and have gone through the datasheet thoroughly, it should be easier to follow the library functions below.
.begin - Check communication with sensor and set it to default I2C Wire library settings

.isConnected - Checks connection

.setLEDCurrent - Sets the IR LED sink current to one of 8 settings (75, 100, 120, 140, 160, 180, and 200 mA).

.setIRDutyCycle - Sets duty cycle of the IR LED (40 max.)

.setProxInterruptPersistance - Sets the Prox interrupt persistance value.
The PS persistence function (PS_PERS, 1, 2, 3, 4) helps to avoid false trigger of the PS INT. It defines the amount of consecutive hits needed in order for a PS interrupt event to be triggered.
.setAmbientInterruptPersistance - Sets the Ambient interrupt persistance value
The ALS persistence function (ALS_PERS, 1, 2, 4, 8) helps to avoid false trigger of the ALS INT. It defines the amount of consecutive hits needed in order for a ALS interrupt event to be triggered.

.setProxIntegrationTime - Sets the integration time for the proximity sensor
.setAmbientIntegrationTime - Sets the integration time for the ambient light sensor

.powerOnProximity - Power on the prox sensing portion of the device
.powerOffProximity - Power off the prox sensing portion of the device

.powerOnAmbient - Power on the ALS sensing portion of the device
.powerOffAmbient - Power off the ALS sensing portion of the device

.setProxResolution - Sets the proximity resolution to 12 or 16 bit

.enableAmbientInterrupts - Enables ALS interrupt
.disableAmbientInterrupts - Disables ALS interrupt

.enableSmartPersistance - Turn on smart presistance
.disableSmartPersistance - Turn off smart presistance
To accelerate the PS response time, smart persistence prevents the misjudgment of proximity sensing, but also keeps a fast response time.

.enableActiveForceMode - Enables active force mode
.disableActiveForceMode - Disable active force mode
An extreme power saving way to use PS is to apply PS active force mode. Anytime host would like to request one proximity measurement, enable the active force mode. This triggers a single PS measurement, which can be read from the PS result registers. VCNL4040 stays in standby mode constantly.

.takeSingleProxMeasurement - Sets trigger bit so sensor takes a force mode measurement and returns to standby.

.enableWhiteChannel - Enables the white measurement channel
.disableWhiteChannel - Disables the white measurement channel

.enableProxLogicMode - Enables the proximity detection logic output mode
.disableProxLogicMode - Disables the proximity detection logic output mode
When this mode is selected, the INT pin is pulled low when an object is close to the sensor (value is above high threshold) and is reset to high when the object moves away (value is below low threshold). Register: PS_THDH / PS_THDL define where these threshold levels are set.

.setProxCancellation - Sets the proximity sensing cancellation value - helps reduce cross talk with ambient light

.setALSHighThreshold - Value that ALS must go above to trigger an interrupt
.setALSLowThreshold - Value that ALS must go below to trigger an interrupt

.setProxHighThreshold - Value that Proximity Sensing must go above to trigger an interrupt
.setProxLowThreshold - Value that Proximity Sensing must go below to trigger an interrupt

.getProximity - Read the Proximity value
.getAmbient - Read the Ambient light value
.getWhite - Read the White light value
.getID - Read the sensors ID

.setProxInterruptType - Enable four proximity interrupt types
.isClose - Interrupt flag: True if prox value greater than high threshold
.isAway - Interrupt flag: True if prox value lower than low threshold
.isLight - Interrupt flag: True if ALS value higher than high threshold
.isDark - Interrupt flag: True if ALS value lower than low threshold

.readCommand - Reads two consecutive bytes from a given 'command code' location
.writeCommand - Write two bytes to a given command code location (8 bits)

Arduino Examples
Note: This section is an example of using the Qwiic Proximity Sensor and the RedBoard Qwiic with the Arduino IDE. It is not intended to be a guide for using I2C devices with the Arduino IDE.

Please use the following links and the internet for a better understanding of I2C and how it works in the Arduino IDE:
A tutorial on I2C.
An in-depth overview of the Wire (I2C) library.
Example 1: Proximity Readings
This example outputs the IR Proximity Value from the VCNL4040 sensor in the Serial Monitor.

Serial output of proximity values
Despite being a qualitative sensor, you will notice that the output does vary with the distance of the object, surface color, and reflectivity. You can also use this setting to estimate the field of view of the sensor. The maximum output value is 65535, closest to the sensor, and the minimum (0-1) being the furthest the sensor can read.

Example 2: Is Something There
This example takes an initial reading at power on. If the reading changes by a significant amount the sensor prints that something is present in the Serial Monitor.

Serial output of proximity detection
This example also allows the proximity sensor to work as a dual purpose photogate.

Hot wheels car triggering proximity sensor
A Hot WheelsTM car triggering proximity sensor.
(*The speed of the Gif is slowed down for you to see the output in the Serial Monitor.)
There is a slight delay in the serial output from the microcontroller (few frames); however, this is exaggerated due to how the image is slowed down.

Example 3: Ambient Light
This example outputs ambient light readings to the terminal.

Serial output of ambient light values
Again the sensor is qualitative, but you can test how the angle of incident from the light source affects the sensor readings.

Example 4: All Readings
This example outputs IR, ambient and white light readings to the terminal. Along with proximity and ambient light sensing the VCNL4040 has a 'white light' sensor as well.

Serial output of all values
Example 5: Advanced Settings
This example shows how to use different Wire ports, fast I2C, and various advanced settings that are supported by the library. Please, refer to the datasheet and library functions listed above for more details.

Resources and Going Further
For more information, check out the resources below:

GitHub Product Repo
Schematic (PDF)
Eagle Files (ZIP)
VCNL4040 Datasheet
SparkFun VCNL4040 Arduino Library GitHub Repository
SparkFun VCNL4040 Python Package GitHub Repository
SFE Product Showcase
Need help getting started with Arduino and I2C? Check out these resources here:

Arduino I2C Scanner Example
Arduino Wire Library Reference Page
Arduino Wire Library (In-Depth) Reference
Need some inspiration for your next project? Check out some of these other Qwiic product tutorials:

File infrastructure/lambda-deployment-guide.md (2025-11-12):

# Lambda Deployment Guide for Motion Play

This guide walks you through deploying the Lambda functions and connecting them to IoT Core.

## Prerequisites

- ✅ AWS CLI configured
- ✅ DynamoDB tables created
- ✅ IoT Thing and certificates created
- ✅ IoT Policy attached

## Working Directory

**IMPORTANT:** Run all commands from the project root directory:

```bash
cd /Users/marcocleirigh/Workspace/motion-play
```

This ensures:

- Lambda function paths are correct (`lambda/functionName`)
- Temporary files (policies, zips) are created in the root and cleaned up
- Relative paths work correctly

## Overview

We'll deploy 7 Lambda functions:

1. **processData** - Stores sensor data from MQTT to DynamoDB
2. **processStatus** - Updates device status in DynamoDB
3. **sendCommand** - Sends commands to devices via MQTT
4. **getSessions** - Lists recording sessions
5. **getSessionData** - Retrieves session details and sensor data
6. **updateSession** - Updates session metadata
7. **deleteSession** - Deletes sessions and associated data

## Step 1: Create IAM Role for Lambda

First, create a trust policy file:

```bash
cat > lambda-trust-policy.json << 'EOF'
{
  "Version": "2012-10-17",
  "Statement": [
    {
      "Effect": "Allow",
      "Principal": {
        "Service": "lambda.amazonaws.com"
      },
      "Action": "sts:AssumeRole"
    }
  ]
}
EOF
```

Create the IAM role:

```bash
aws iam create-role \
    --role-name MotionPlayLambdaRole \
    --assume-role-policy-document file://lambda-trust-policy.json
```

Create the permissions policy:

```bash
cat > lambda-permissions-policy.json << 'EOF'
{
  "Version": "2012-10-17",
  "Statement": [
    {
      "Effect": "Allow",
      "Action": [
        "logs:CreateLogGroup",
        "logs:CreateLogStream",
        "logs:PutLogEvents"
      ],
      "Resource": "arn:aws:logs:us-west-2:*:*"
    },
    {
      "Effect": "Allow",
      "Action": [
        "dynamodb:PutItem",
        "dynamodb:GetItem",
        "dynamodb:UpdateItem",
        "dynamodb:DeleteItem",
        "dynamodb:Query",
        "dynamodb:Scan",
        "dynamodb:BatchWriteItem"
      ],
      "Resource": [
        "arn:aws:dynamodb:us-west-2:*:table/MotionPlaySessions",
        "arn:aws:dynamodb:us-west-2:*:table/MotionPlaySessions/*",
        "arn:aws:dynamodb:us-west-2:*:table/MotionPlaySensorData",
        "arn:aws:dynamodb:us-west-2:*:table/MotionPlayDevices"
      ]
    },
    {
      "Effect": "Allow",
      "Action": [
        "iot:Publish"
      ],
      "Resource": "arn:aws:iot:us-west-2:*:topic/motionplay/*/commands"
    }
  ]
}
EOF
```

Attach the policy to the role:

```bash
aws iam put-role-policy \
    --role-name MotionPlayLambdaRole \
    --policy-name MotionPlayLambdaPolicy \
    --policy-document file://lambda-permissions-policy.json
```

Get the role ARN (save this for next steps):

```bash
aws iam get-role --role-name MotionPlayLambdaRole --query 'Role.Arn' --output text
```

Clean up policy files:

```bash
rm lambda-trust-policy.json lambda-permissions-policy.json
```

## Step 2: Deploy Lambda Functions

Deploy each function one by one:

### 2.1 Deploy processData Function

```bash
cd lambda/processData
npm install
zip -r function.zip .

aws lambda create-function \
    --function-name motionplay-processData \
    --runtime nodejs20.x \
    --role arn:aws:iam::861647825061:role/MotionPlayLambdaRole \
    --handler index.handler \
    --zip-file fileb://function.zip \
    --timeout 30 \
    --memory-size 256

rm function.zip
cd ../..
```

### 2.2 Deploy processStatus Function

```bash
cd lambda/processStatus
npm install
zip -r function.zip .

aws lambda create-function \
    --function-name motionplay-processStatus \
    --runtime nodejs20.x \
    --role arn:aws:iam::861647825061:role/MotionPlayLambdaRole \
    --handler index.handler \
    --zip-file fileb://function.zip \
    --timeout 15 \
    --memory-size 128

rm function.zip
cd ../..
```

### 2.3 Deploy sendCommand Function

```bash
cd lambda/sendCommand
npm install
zip -r function.zip .

aws lambda create-function \
    --function-name motionplay-sendCommand \
    --runtime nodejs20.x \
    --role arn:aws:iam::861647825061:role/MotionPlayLambdaRole \
    --handler index.handler \
    --zip-file fileb://function.zip \
    --timeout 15 \
    --memory-size 128

rm function.zip
cd ../..
```

### 2.4 Deploy getSessions Function

```bash
cd lambda/getSessions
npm install
zip -r function.zip .

aws lambda create-function \
    --function-name motionplay-getSessions \
    --runtime nodejs20.x \
    --role arn:aws:iam::861647825061:role/MotionPlayLambdaRole \
    --handler index.handler \
    --zip-file fileb://function.zip \
    --timeout 15 \
    --memory-size 128

rm function.zip
cd ../..
```

### 2.5 Deploy getSessionData Function

```bash
cd lambda/getSessionData
npm install
zip -r function.zip .

aws lambda create-function \
    --function-name motionplay-getSessionData \
    --runtime nodejs20.x \
    --role arn:aws:iam::861647825061:role/MotionPlayLambdaRole \
    --handler index.handler \
    --zip-file fileb://function.zip \
    --timeout 30 \
    --memory-size 256

rm function.zip
cd ../..
```

### 2.6 Deploy updateSession Function

```bash
cd lambda/updateSession
npm install
zip -r function.zip .

aws lambda create-function \
    --function-name motionplay-updateSession \
    --runtime nodejs20.x \
    --role arn:aws:iam::861647825061:role/MotionPlayLambdaRole \
    --handler index.handler \
    --zip-file fileb://function.zip \
    --timeout 15 \
    --memory-size 128

rm function.zip
cd ../..
```

### 2.7 Deploy deleteSession Function

```bash
cd lambda/deleteSession
npm install
zip -r function.zip .

aws lambda create-function \
    --function-name motionplay-deleteSession \
    --runtime nodejs20.x \
    --role arn:aws:iam::861647825061:role/MotionPlayLambdaRole \
    --handler index.handler \
    --zip-file fileb://function.zip \
    --timeout 30 \
    --memory-size 128

rm function.zip
cd ../..
```

## Step 3: Create IoT Rules for MQTT Integration

### 3.1 Create Rule for Sensor Data

Create the rule to process sensor data:

```bash
aws iot create-topic-rule --rule-name ProcessMotionPlayData --topic-rule-payload '{
  "sql": "SELECT * FROM '\''motionplay/+/data'\''",
  "description": "Route sensor data to Lambda for processing",
  "actions": [
    {
      "lambda": {
        "functionArn": "arn:aws:lambda:us-west-2:861647825061:function:motionplay-processData"
      }
    }
  ]
}'
```

Grant IoT permission to invoke the Lambda:

```bash
aws lambda add-permission \
    --function-name motionplay-processData \
    --statement-id IoTInvokeProcessData \
    --action lambda:InvokeFunction \
    --principal iot.amazonaws.com \
    --source-arn arn:aws:iot:us-west-2:861647825061:rule/ProcessMotionPlayData
```

### 3.2 Create Rule for Status Updates

Create the rule to process status updates:

```bash
aws iot create-topic-rule --rule-name ProcessMotionPlayStatus --topic-rule-payload '{
  "sql": "SELECT * FROM '\''motionplay/+/status'\''",
  "description": "Route device status to Lambda for processing",
  "actions": [
    {
      "lambda": {
        "functionArn": "arn:aws:lambda:us-west-2:861647825061:function:motionplay-processStatus"
      }
    }
  ]
}'
```

Grant IoT permission to invoke the Lambda:

```bash
aws lambda add-permission \
    --function-name motionplay-processStatus \
    --statement-id IoTInvokeProcessStatus \
    --action lambda:InvokeFunction \
    --principal iot.amazonaws.com \
    --source-arn arn:aws:iot:us-west-2:861647825061:rule/ProcessMotionPlayStatus
```

## Step 4: Test the Functions

### 4.1 Test processData Function

First create a test payload file:

```bash
cat > test-processData.json << 'EOF'
{
  "topic": "motionplay/device-001/data",
  "device_id": "device-001",
  "session_id": "test-session-001",
  "start_timestamp": "2024-01-01T00:00:00.000Z",
  "mode": "test",
  "sample_rate": 1000,
  "readings": [
    {"t": 0, "p": 1, "s": 0, "prox": 100, "amb": 50},
    {"t": 100, "p": 2, "s": 0, "prox": 110, "amb": 55}
  ]
}
EOF
```

Invoke the function:

```bash
aws lambda invoke \
    --function-name motionplay-processData \
    --cli-binary-format raw-in-base64-out \
    --payload file://test-processData.json \
    response.json

cat response.json
rm test-processData.json
```

### 4.2 Test processStatus Function

Create test payload:

```bash
cat > test-processStatus.json << 'EOF'
{
  "topic": "motionplay/device-001/status",
  "device_id": "device-001",
  "status": "online",
  "current_mode": "test",
  "wifi_rssi": -45,
  "free_heap": 120000,
  "uptime_ms": 60000
}
EOF
```

Invoke the function:

```bash
aws lambda invoke \
    --function-name motionplay-processStatus \
    --cli-binary-format raw-in-base64-out \
    --payload file://test-processStatus.json \
    response.json

cat response.json
rm test-processStatus.json
```

### 4.3 Test getSessions Function

```bash
# Test without filters (gets all sessions)
aws lambda invoke \
    --function-name motionplay-getSessions \
    --cli-binary-format raw-in-base64-out \
    --payload '{}' \
    response.json

cat response.json

# Test with device filter (simulating API Gateway query params)
aws lambda invoke \
    --function-name motionplay-getSessions \
    --cli-binary-format raw-in-base64-out \
    --payload '{"queryStringParameters": {"device_id": "device-001", "limit": "10"}}' \
    response.json

cat response.json
```

### 4.4 Test other Lambda Functions

The remaining functions (getSessionData, updateSession, deleteSession, sendCommand) are designed for API Gateway integration. For now, you can skip testing these individually as they require specific path parameters and request formats that will be set up with API Gateway.

To verify all functions are deployed:

```bash
aws lambda list-functions --query "Functions[?starts_with(FunctionName, 'motionplay')].[FunctionName, Runtime, State]" --output table
```

## Step 5: Verify Deployment

### Check Lambda Functions

```bash
aws lambda list-functions --query "Functions[?starts_with(FunctionName, 'motionplay')].[FunctionName, Runtime, State]" --output table
```

### Check IoT Rules

```bash
aws iot list-topic-rules | grep motionplay
```

### Check DynamoDB for Test Data

```bash
aws dynamodb scan --table-name MotionPlaySessions --max-items 5
```

## Troubleshooting

**Function creation fails:**

- Verify IAM role was created successfully
- Check account ID in ARN is correct
- Ensure you're in the correct region

**IoT Rules don't trigger:**

- Check rule SQL syntax
- Verify Lambda permissions
- Test with IoT Core test client

**Lambda execution fails:**

- Check CloudWatch logs: `aws logs tail /aws/lambda/motionplay-processData`
- Verify DynamoDB table names
- Check IAM permissions

## Next Steps

1. **API Gateway Setup** (for web interface)

   - Create REST API
   - Connect to Lambda functions
   - Enable CORS

2. **CloudWatch Monitoring**

   - Set up log groups
   - Create alarms for errors
   - Monitor Lambda costs

3. **Begin Phase 1**
   - Implement ESP32 firmware
   - Test MQTT publishing
   - Verify data flow

## Clean Up Commands (if needed)

To remove all Lambda functions:

```bash
for func in processData processStatus sendCommand getSessions getSessionData updateSession deleteSession; do
    aws lambda delete-function --function-name motionplay-$func
done
```

To remove IoT Rules:

```bash
aws iot delete-topic-rule --rule-name ProcessMotionPlayData
aws iot delete-topic-rule --rule-name ProcessMotionPlayStatus
```

## Cost Considerations

- Lambda: First 1M requests/month free
- DynamoDB: 25GB storage + 25 RCU/WCU free
- IoT Core: 250k messages/month free
- Estimated monthly cost for development: < $1

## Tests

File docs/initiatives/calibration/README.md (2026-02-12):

# Calibration System Initiative

> **Status:** Phase 1, 2 & 3 Complete ✅  
> **Created:** 2025-12-29  
> **Last Updated:** 2025-12-30

## Implementation Status

| Phase | Status | Notes |
|---|---|---|
| Phase 1: Core Infrastructure | ✅ Complete | Firmware compiles and works |
| Phase 2: Frontend Integration | ✅ Complete | Calibration button added to ModeSelector |
| Phase 3: Detection Integration | ✅ Complete | DirectionDetector & InterruptManager use calibrated thresholds |
| Phase 4: Persistence | 🔲 Not Started | Data only in RAM currently |

## Overview

The calibration system provides a guided wizard for characterizing sensor behavior in their installed environment. It captures both the noise floor (baseline) and expected signal range (from user-initiated waves), enabling more accurate and reliable detection thresholds.

## Problem Statement

Current detection issues with multi-pulse mode:
- Baseline calibration (50 readings, ~150ms) doesn't capture full noise variation
- No reference for what a "real" detection looks like for this specific sensor/environment
- Per-sensor noise characteristics vary significantly but thresholds are calculated uniformly
- False triggers occur when noise spikes exceed calculated thresholds

## Goals

1. **Capture both noise floor AND signal ceiling** per sensor/PCB
2. **Per-sensor characterization** to account for hardware variance
3. **Environment-specific tuning** at installation time
4. **Data persistence** for consistent behavior across sessions
5. **Future ML pipeline** - calibration sessions become labeled training data

---

## Original Intent

The original discussion identified that:

1. Multi-pulse mode (2x pulses) increases noise amplitude variability
2. The baseline calibration period was too short to capture full noise range
3. Each sensor has different noise profiles that need individual thresholds
4. Real detections show peaks of 44-101 while false triggers max at ~20
5. There's no mechanism to know what a "real" signal looks like for validation

The calibration wizard addresses all of these by having the user perform known actions (waving through the hoop) while the system measures the expected signal ranges.

---

## Possible Directions

### Direction A: Per-PCB Calibration with Approach Motion (Recommended for MVP)
- Calibrate 3 PCBs sequentially
- User moves hand TOWARD sensor and HOLDS (not wave-through)
- Captures sustained "object present" readings
- Simpler detection: just need elevated readings, not wave pattern
- Aggregate both sensors on each PCB

### Direction B: Per-Sensor Calibration
- Calibrate all 6 sensors individually
- Most granular, best accuracy
- More complex UI, longer process
- Better for debugging sensor issues

### Direction C: Single-Pass Calibration
- User waves through entire hoop once
- System detects which sensors fired and captures all data
- Fastest UX, but less controlled
- May miss sensors if wave path isn't optimal

### Direction D: Automatic Calibration (Future)
- Device learns from first N real detections
- No user interaction required
- Requires initial rough thresholds to work
- Best UX but needs ML/heuristics

**Decision:** Start with **Direction A (Per-PCB with Approach)** for MVP. This separates "baseline" (nothing present) from "signal" (object close) without requiring direction detection to work.

### Why "Approach and Hold" Instead of "Wave Through"

A wave-through motion:
- Object enters → peaks briefly → exits
- Gives transient signal with brief peak
- Good for direction detection timing calibration

An approach-and-hold motion:
- Object approaches → stays close → retreats
- Gives sustained high readings
- Captures full range of "object present" values
- Better for simple proximity threshold calibration

**For establishing proximity thresholds, we need to know:**
1. What readings look like with NOTHING present (baseline)
2. What readings look like with SOMETHING present (signal)

The approach-and-hold motion cleanly separates these two states.

---

## Current Plan: MVP Specification

### What Gets Calibrated

For each PCB (1-3), capture:

| Metric | How Captured | Purpose |
|---|---|---|
| `baseline_min` | Min reading during quiet period | Noise floor |
| `baseline_max` | Max reading during quiet period | Noise ceiling |
| `baseline_mean` | Average during quiet period | Central tendency |
| `baseline_stddev` | Std deviation during quiet | Noise variability |
| `signal_min` | Min peak during wave | Weakest valid detection |
| `signal_max` | Max peak during wave | Strongest detection |
| `signal_mean` | Average peak across waves | Expected detection level |

Derived thresholds:
```
threshold = baseline_max + ((signal_min - baseline_max) / 2)
// Halfway between noise ceiling and weakest real signal
```

### Calibration Triggers

**MVP triggers (in priority order):**

1. **Frontend Mode Selection**
   - Add `CALIBRATE` to device modes (alongside IDLE/DEBUG/PLAY)
   - User clicks mode selector → device enters calibration wizard
   - On completion, device returns to IDLE mode

2. **Physical Button Hold**
   - Hold Button 1 on T-Display for 3 seconds
   - Device enters calibration mode
   - Works offline (no WiFi needed)

**Future triggers (post-MVP):**

3. **Auto-prompt on first session**
   - When entering DEBUG/PLAY mode with no calibration data
   - Prompt: "Device not calibrated. Calibrate now? [Yes] [Skip]"
   - Skip uses fallback thresholds

4. **Session config option**
   - Checkbox: "Recalibrate before session"
   - Useful when environment has changed

### Calibration Flow

```
┌─────────────────────────────────────────────────────────────┐
│                    CALIBRATION WIZARD                        │
├─────────────────────────────────────────────────────────────┤
│                                                              │
│  State Machine:                                              │
│                                                              │
│  IDLE ──(trigger)──► INTRO ──(2s)──► BASELINE_PCB1          │
│                                              │               │
│                                              ▼               │
│                                        APPROACH_PCB1         │
│                                              │               │
│                                              ▼               │
│                                        BASELINE_PCB2         │
│                                              │               │
│                                              ▼               │
│                                        APPROACH_PCB2         │
│                                              │               │
│                                              ▼               │
│                                        BASELINE_PCB3         │
│                                              │               │
│                                              ▼               │
│                                        APPROACH_PCB3         │
│                                              │               │
│                                              ▼               │
│                                        SUMMARY               │
│                                              │               │
│                                              ▼               │
│                                          COMPLETE ──► IDLE   │
│                                                              │
│  Any state can transition to:                                │
│    - CANCELLED (button press)                                │
│    - FAILED (timeout or hardware issue) ──► abort all        │
│                                                              │
└─────────────────────────────────────────────────────────────┘
```

### Timing

| Phase | Duration | Completion |
|---|---|---|
| INTRO | 2 seconds | Fixed |
| BASELINE_PCBx | 600ms | Fixed (need consistent data) |
| APPROACH_PCBx | Up to 10s | **Early complete** if 500ms of sustained elevated readings |
| Per-PCB total | ~3-5 seconds typical | |
| **Full calibration** | **~15-25 seconds** | Depending on user speed |

### UI Screens (T-Display)

```
INTRO (2 seconds):
┌─────────────────────────────────────────┐
│         CALIBRATION MODE                │
│                                         │
│   This wizard will calibrate your       │
│   sensors for optimal detection.        │
│                                         │
│   For each PCB, you'll:                 │
│   1. Keep area clear (baseline)         │
│   2. Move hand close and HOLD           │
│                                         │
│   Starting in 3...                      │
└─────────────────────────────────────────┘

BASELINE_PCBx (600ms):
┌─────────────────────────────────────────┐
│         CALIBRATION MODE                │
│                                         │
│   Step x of 3: PCB x                    │
│                                         │
│   ⏳ Measuring baseline...              │
│   [████████░░] 80%                      │
│                                         │
│   🚫 Keep area CLEAR!                   │
│                                         │
│   [Press BTN2 to cancel]                │
└─────────────────────────────────────────┘

APPROACH_PCBx:
┌─────────────────────────────────────────┐
│         CALIBRATION MODE                │
│                                         │
│   Step x of 3: PCB x                    │
│                                         │
│   ✓ Baseline: 12                        │
│                                         │
│   🖐️ Move hand CLOSE to PCB x          │
│      and HOLD for a moment              │
│                                         │
│   Waiting... (10s timeout)              │
└─────────────────────────────────────────┘

APPROACH_PCBx (detecting):
┌─────────────────────────────────────────┐
│         CALIBRATION MODE                │
│                                         │
│   Step x of 3: PCB x                    │
│                                         │
│   ✓ Baseline: 12                        │
│                                         │
│   📡 Detecting! Hold steady...          │
│   Current: 78                           │
│   [██████░░░░] 60%                      │
│                                         │
└─────────────────────────────────────────┘

APPROACH_PCBx (success):
┌─────────────────────────────────────────┐
│         CALIBRATION MODE                │
│                                         │
│   Step x of 3: PCB x                    │
│                                         │
│   ✅ Captured!                          │
│                                         │
│   Baseline: 12                          │
│   Signal:   65 - 92 (peak)              │
│   Threshold: 38                         │
│                                         │
│   [Continuing in 1s...]                 │
└─────────────────────────────────────────┘

FAILED:
┌─────────────────────────────────────────┐
│       CALIBRATION FAILED ❌             │
│                                         │
│   PCB x did not respond.                │
│                                         │
│   Possible causes:                      │
│   - Sensor not connected                │
│   - I2C communication error             │
│   - Hand not close enough               │
│                                         │
│   Calibration aborted.                  │
│   [Press any button to exit]            │
└─────────────────────────────────────────┘

SUMMARY:
┌─────────────────────────────────────────┐
│       CALIBRATION COMPLETE! ✅          │
│                                         │
│   PCB1: Base=8,  Signal=92,  T=50      │
│   PCB2: Base=12, Signal=105, T=58      │
│   PCB3: Base=15, Signal=88,  T=51      │
│                                         │
│   Calibration saved to memory.          │
│                                         │
│   [Press any button to continue]        │
└─────────────────────────────────────────┘
```

### Data Structures

```cpp
// Single PCB calibration data
struct PCBCalibration {
    uint8_t pcb_id;               // 1-3
    
    // Baseline stats (noise floor)
    uint16_t baseline_min;
    uint16_t baseline_max;
    uint16_t baseline_mean;
    uint16_t baseline_stddev;
    
    // Signal stats (during wave detection)
    uint16_t signal_peak;         // Maximum reading during wave
    uint16_t signal_min_peak;     // For multi-wave: minimum of peaks
    
    // Derived threshold
    uint16_t threshold;           // Calculated optimal threshold
    
    // Validity
    bool valid;
};

// Complete device calibration
struct DeviceCalibration {
    uint32_t magic;               // 0xCA11B123 - validity marker
    uint32_t version;             // Schema version
    uint32_t timestamp;           // When calibration was performed
    
    // Sensor config at calibration time (for reference)
    uint8_t multi_pulse;
    uint8_t integration_time;
    uint8_t led_current;
    
    // Per-PCB data
    PCBCalibration pcbs[3];
    
    // Overall validity
    bool isValid() const { 
        return magic == 0xCA11B123 && 
               pcbs[0].valid && pcbs[1].valid && pcbs[2].valid; 
    }
};
```

### Storage Strategy

| Phase | Storage | Behavior |
|---|---|---|
| MVP | RAM only | Lost on reboot, must recalibrate |
| v1.1 | + LittleFS | Persists across reboots |
| v1.2 | + Cloud sync | Upload to DynamoDB, downloadable for analysis |

### Integration with Detection

```cpp
// In DirectionDetector or InterruptManager:
void calculateThresholds() {
    if (calibration.isValid()) {
        // Use calibrated thresholds
        for (int i = 0; i < 3; i++) {
            pcbThreshold[i] = calibration.pcbs[i].threshold;
        }
    } else {
        // Fallback to current behavior
        threshold = baseline_max + minRise;
    }
}
```

---

## Implementation Plan

### Phase 1: Core Infrastructure (MVP) ✅ COMPLETE

- [x] **1.1** Create `CalibrationManager` component
  - [x] 1.1.1 Define `CalibrationState` enum (IDLE, INTRO, BASELINE_PCB1, APPROACH_PCB1, etc.)
  - [x] 1.1.2 Create `CalibrationManager` class with state machine
  - [x] 1.1.3 Implement `begin()`, `update()`, `isActive()` methods
  - [x] 1.1.4 Timer management for phase transitions
  - [x] 1.1.5 Sensor reading aggregation per PCB

- [x] **1.2** Create `CalibrationData` structures
  - [x] 1.2.1 Define `PCBCalibration` struct
  - [x] 1.2.2 Define `DeviceCalibration` struct with validity checking
  - [x] 1.2.3 Create global/singleton storage instance (`deviceCalibration`)
  - [x] 1.2.4 Implement threshold calculation method

- [x] **1.3** Implement approach detection for calibration
  - [x] 1.3.1 Detect when readings exceed 2× baseline (elevated)
  - [x] 1.3.2 Track sustained elevated readings (target: 500ms)
  - [x] 1.3.3 Early completion when sufficient data captured
  - [x] 1.3.4 Timeout handling (10 seconds max)
  - [x] 1.3.5 Calculate min/max/mean of signal readings (via `StatsAccumulator`)

- [x] **1.4** Add T-Display UI screens
  - [x] 1.4.1 Intro screen (3 second countdown)
  - [x] 1.4.2 Baseline measurement screen (with progress bar)
  - [x] 1.4.3 Approach prompt screen
  - [x] 1.4.4 "Detecting" screen (shows live readings + hold progress)
  - [x] 1.4.5 Success screen (shows green checkmark)
  - [x] 1.4.6 Failure screen (abort message with reason)
  - [x] 1.4.7 Summary screen (all PCB thresholds)

- [x] **1.5** Add physical button trigger
  - [x] 1.5.1 Detect Button 1 (GPIO 14) hold for 3 seconds
  - [x] 1.5.2 Enter calibration mode on trigger
  - [x] 1.5.3 Button 2 (BOOT) to cancel during calibration
  - [x] 1.5.4 Any button to dismiss summary screen

**Files created:**
- `firmware/src/components/calibration/CalibrationData.h`
- `firmware/src/components/calibration/CalibrationManager.h`
- `firmware/src/components/calibration/CalibrationManager.cpp`

**Files modified:**
- `firmware/src/components/display/DisplayManager.h` - Added 8 calibration UI methods
- `firmware/src/components/display/DisplayManager.cpp` - Implemented calibration screens
- `firmware/src/main.cpp` - Integrated CalibrationManager, button trigger, MQTT handler

### Phase 2: Frontend Integration ✅ COMPLETE

- [x] **2.1** Add CALIBRATE mode to device modes
  - [x] 2.1.1 Calibration handled as action (not persistent mode like IDLE/DEBUG/PLAY)
  - [x] 2.1.2 Handle `SET_MODE` command with `mode: "calibrate"`
  - [x] 2.1.3 Device returns to previous display after calibration completes

- [x] **2.2** Update frontend mode selector
  - [x] 2.2.1 Add "Start Calibration" button below mode selector
  - [x] 2.2.2 Show calibration-in-progress indicator (purple theme)
  - [x] 2.2.3 Disable calibration when not in IDLE mode (must stop collection first)

- [~] **2.3** Display calibration status in frontend (DEFERRED)
  - [ ] 2.3.1 Show "Calibrated" / "Not Calibrated" badge
  - [ ] 2.3.2 Show calibration timestamp if available
  - [ ] 2.3.3 Show per-PCB threshold values
  - *Note: Deferred to Phase 3 - requires MQTT status publishing from device*

**Files modified:**
- `frontend/motion-play-ui/src/components/ModeSelector.tsx` - Added calibration section with button

### Phase 3: Detection Integration ✅ COMPLETE

- [x] **3.1** Integrate calibration data into DirectionDetector
  - [x] 3.1.1 Add `setCalibration(const DeviceCalibration*)` method
  - [x] 3.1.2 Use calibrated thresholds in `calculateThresholds()`
  - [x] 3.1.3 Fallback to current behavior when uncalibrated
  - [x] 3.1.4 Added `isUsingCalibration()` method for status checking

- [x] **3.2** Update InterruptManager thresholds
  - [x] 3.2.1 Add `setCalibration(const DeviceCalibration*)` method
  - [x] 3.2.2 Apply per-PCB thresholds (halved for per-sensor) from calibration
  - [x] 3.2.3 Log threshold source (CALIBRATED vs FALLBACK)
  - [x] 3.2.4 Added `isUsingCalibration()` method

- [x] **3.3** Add calibration metadata to sessions
  - [x] 3.3.1 Include `calibration.valid` flag in session data
  - [x] 3.3.2 Include per-PCB threshold values in session metadata
  - [x] 3.3.3 Include calibration timestamp, multi_pulse, and integration_time
  - [x] 3.3.4 Works for both proximity and interrupt session types

**Files modified:**
- `firmware/src/components/detection/DirectionDetector.h` - Added calibration fields and methods
- `firmware/src/components/detection/DirectionDetector.cpp` - Integrated calibrated thresholds
- `firmware/src/components/interrupt/InterruptManager.h` - Added calibration fields and methods
- `firmware/src/components/interrupt/InterruptManager.cpp` - Integrated calibrated thresholds
- `firmware/src/components/data/DataTransmitter.cpp` - Added calibration metadata to sessions
- `firmware/src/main.cpp` - Pass calibration to detectors when entering play/interrupt mode

### Phase 4: Persistence (Post-MVP)

- [ ] **4.1** Implement LittleFS storage
  - [ ] 4.1.1 Save calibration to `/calibration.bin` on completion
  - [ ] 4.1.2 Load calibration on boot if file exists
  - [ ] 4.1.3 Validate loaded data (magic number, version)
  - [ ] 4.1.4 Handle corruption gracefully (delete and recalibrate)

- [ ] **4.2** Cloud sync (optional)
  - [ ] 4.2.1 Add "Upload Calibration" MQTT command
  - [ ] 4.2.2 Create Lambda to store calibration in DynamoDB
  - [ ] 4.2.3 Add "Download Calibration" option in frontend
  - [ ] 4.2.4 API endpoint for calibration data retrieval

---

## Success Criteria

### MVP Complete When:
1. ✅ User can trigger calibration from device button
2. ✅ Wizard guides through all 3 PCBs
3. ✅ Approach detection works reliably (sustained elevated readings)
4. ✅ Thresholds are calculated and stored in RAM (`deviceCalibration`)
5. ✅ DirectionDetector uses calibrated thresholds

### Full Feature Complete When:
1. ✅ Frontend can trigger calibration
2. 🔲 Calibration survives reboot (LittleFS)
3. 🔲 Calibration data viewable in frontend
4. 🔲 Cloud sync operational
5. 🔲 False trigger rate reduced by >80%

---

## Decisions Made

| Question | Decision | Rationale |
|---|---|---|
| Wave vs approach | **Approach and hold** | Simpler, separates baseline from signal cleanly |
| Timeout | **10 seconds** | But complete early if 500ms sustained readings |
| Failure handling | **Abort entire calibration** | Treat as hardware issue to investigate |
| PCB naming | **PCB1, PCB2, PCB3** | No position assumptions (hardware varies) |
| Multiple samples | **Single approach per PCB** | 500ms of sustained data is sufficient |

## Open Questions (Future)

1. **Should calibration expire?** (e.g., re-prompt after 30 days or sensor config change)
2. **Should we detect sensor config changes?** (If multi-pulse changes from 2x to 4x, old calibration may be invalid)
3. **Cloud sync priority?** (v1.2 or defer further?)

---

## References

- Original discussion: Analysis of false triggers with 2-pulse mode
- Related: `docs/initiatives/interrupt-detection/` - interrupt-based detection
- Sensor config: `docs/references/vcnl4040/CONFIGURATION_GUIDE.md`

---

## Changelog

| Date | Change |
|---|---|
| 2025-12-30 | Phase 3 implemented - DirectionDetector, InterruptManager, session metadata |
| 2025-12-30 | Phase 1 & 2 implemented - firmware and frontend complete |
| 2025-12-29 | Initial planning document created |

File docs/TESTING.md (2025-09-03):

# Testing Guide

This project now includes two test programs:

## 1. Full System Test (`main.cpp`)
Tests the complete system with TCA9548A multiplexer and sensor PCBs.

**To build and upload:**
```bash
pio run -e lilygo-t-display-s3 -t upload
```

## 2. Direct Sensor Test (`sensor_direct_test.cpp`)
Tests a single sensor PCB directly connected to T-Display-S3, bypassing the multiplexer.

**To build and upload:**
```bash
pio run -e sensor-direct-test -t upload
```

## Direct Sensor Test Wiring

Connect your T-Display-S3 to the sensor PCB using jumper wires:

| T-Display-S3 Pin | Sensor PCB Connector | Signal |
|---|---|---|
| Pin 43 (SDA) | J3 Pin 2 | SDA |
| Pin 44 (SCL) | J3 Pin 1 | SCL |
| 3.3V | J1 Pin 1 | 3.3V |
| GND | J1 Pin 2 | GND |

**Notes:**
- J1 is the power connector (3.3V + GND)
- J3 is the communication connector (SDA + SCL + INT)
- INT pin is not needed for this test
- Use a breadboard to make connections easier

## What the Direct Test Does

1. **I2C Bus Test**: Scans for devices at different speeds (100kHz, 400kHz)
2. **Communication Test**: Verifies the sensor responds at address 0x60
3. **Device ID Check**: Reads the VCNL4040 device ID register (should be 0x0186)
4. **Register Configuration**: Sets up proximity and ambient light sensors
5. **Register Dump**: Shows all register values for debugging
6. **Live Readings**: Displays real-time sensor data

## Controls

- **Button 1 (UP)**: Short press = scroll up one line, Long press = jump to top
- **Button 2 (DOWN)**: Short press = scroll down one line, Long press = jump to bottom  
- **Both Buttons**: Hold for 2 seconds to reset device

## Troubleshooting

If the direct test fails:

1. **Check Power**: Verify 3.3V and GND connections with multimeter
2. **Check Data Lines**: Verify SDA/SCL continuity
3. **Check Soldering**: Ensure sensor PCB connections are solid
4. **Try Different Speeds**: The test tries both 100kHz and 400kHz I2C
5. **Check Pull-ups**: Ensure I2C pull-up resistors are present

## Expected Results

**Working sensor should show:**
- Device found at 0x60 in I2C scan
- Communication test: OK
- Device ID: 0x0186
- All register writes: OK
- Live readings with changing proximity values

**Common failures:**
- No device at 0x60 = power or connection issue
- Device ID 0x0000 or 0xFFFF = power or timing issue
- Communication test failed = wiring or I2C issue

## Switching Between Tests

The project is set up so you can easily switch between the full system test and direct sensor test without losing either version of the code.

- Use `pio run -e lilygo-t-display-s3 -t upload` for full system
- Use `pio run -e sensor-direct-test -t upload` for direct sensor test

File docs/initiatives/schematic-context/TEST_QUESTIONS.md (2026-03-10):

# Schematic Context System — Verification Test Questions

These questions should be answerable by an AI given only `circuit-context.json` and `hardware/CONTEXT.md`. Defined during Phase 3a, tested during Phase 3c.

## Signal Tracing

1. **Trace the I2C path from the ESP32 to a sensor connector.** What components and nets are involved between the MCU's I2C pins and the JST-SH connector for sensor module 1 (J4)?

2. **How does the LED data signal get from the MCU to the LED strip connector (J3)?** What level-shifting or buffering occurs along the way?

## Component Roles

3. **What is the purpose of D1 (Schottky diode) in the power path?** What nets does it sit between, and why is it there?

4. **What do R28 and R29 do, and why are they 2.2kΩ?** What bus are they associated with?

## Power Architecture

5. **How is the 3.3V rail generated?** Trace the power path from USB-C input to the +3.3V rail, identifying every component in the chain.

6. **How is the LED strip power protected?** What components sit between the +5V rail and the actual LED strip power pin on J3?

## Functional Grouping

7. **Which components belong to the TCA9548A I2C mux subsystem?** List them and describe each one's role.

8. **How many GPIO pins on the T-Display-S3 are broken out to test points but not connected to any functional circuit?** Which pins are they?

## Design Modification

9. **If you wanted to add a fourth sensor module, what changes would be needed on the main PCB?** Consider connectors, I2C mux channels, and interrupt lines.

10. **What would need to change if the DWEII power module were replaced with a direct USB-C connector and buck regulator?** Which components in the power path would be affected?

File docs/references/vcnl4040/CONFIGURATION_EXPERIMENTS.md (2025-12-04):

# VCNL4040 Configuration Experiments

**Purpose**: Systematically test different sensor configurations to find optimal settings for direction detection.

## Experiment Log Template

Copy this template for each experiment:

```
### Experiment [NUMBER]
**Date**: [YYYY-MM-DD HH:MM]
**Session ID**: [from web UI]

#### Configuration
- LED Current: [50/75/100/120/140/160/180/200] mA
- Integration Time: [1T/1.5T/2T/2.5T/3T/3.5T/4T/8T]
- Duty Cycle: [1/40 / 1/80 / 1/160 / 1/320]
- High Resolution: [On/Off]
- Ambient Light: [On/Off]

#### Test Conditions
- Object: [description - e.g., "tennis ball, yellow"]
- Speed: [slow/medium/fast]
- Direction: [A→B / B→A]
- Trajectory: [center/edge]

#### Results
- Calculated Sample Rate: [X] Hz
- Peak Proximity Value: [X] counts
- Baseline Proximity: [X] counts
- Signal-to-Noise Ratio: [peak / baseline]
- Direction Detection: [clear/marginal/failed]
- Notes: [any observations]
```

---

## Baseline Experiment (Current Settings)

### Experiment 1 - Baseline
**Date**: [Your date]
**Session ID**: device-001_49191 (from short_sample_4T.csv)

#### Configuration
- LED Current: 200mA
- Integration Time: 4T
- Duty Cycle: 1/40
- High Resolution: On
- Ambient Light: Off

#### Calculated Metrics
- Time span: 829ms
- Complete cycles: 381
- **Firmware read rate: ~460 Hz**
- **Actual sensor update rate: ~50 Hz** (4T × 1/40 = 20ms period)
- You're reading the same value ~9 times before it changes

#### Observations
- Direction detection works but is "very close"
- Multiple redundant readings between actual sensor updates

---

## Recommended Experiments

### Experiment 2 - Speed Priority (1T)
**Goal**: Maximize sample rate

#### Configuration
- LED Current: 200mA (keep max power to compensate)
- Integration Time: **1T** (fastest)
- Duty Cycle: 1/40
- High Resolution: On
- Ambient Light: Off

#### Expected
- Actual sensor rate: ~200 Hz (4× improvement!)
- Trade-off: Lower signal per reading

---

### Experiment 3 - Balanced (2T)
**Goal**: Good speed + decent signal

#### Configuration
- LED Current: 200mA
- Integration Time: **2T**
- Duty Cycle: 1/40
- High Resolution: On
- Ambient Light: Off

#### Expected
- Actual sensor rate: ~100 Hz (2× improvement)
- Better signal than 1T

---

### Experiment 4 - Resolution Impact
**Goal**: Check if 12-bit vs 16-bit affects timing

#### Configuration A (12-bit)
- High Resolution: **Off**
- Other settings: same as Experiment 2

#### Configuration B (16-bit)
- High Resolution: **On**
- Other settings: same as Experiment 2

**Note**: Resolution shouldn't affect sample rate (it's just a mode bit), but worth verifying.

---

### Experiment 5 - Ambient Light Impact
**Goal**: Check if reading ambient slows things down

#### Configuration
- Ambient Light: **On**
- Other settings: same as Experiment 2

**Expected**: Each I2C cycle takes slightly longer (extra register read), but shouldn't significantly impact rate since I2C isn't your bottleneck.

---

## Analysis Script

Save this Python script to analyze your exported CSV files:

```python
#!/usr/bin/env python3
"""Analyze Motion Play session data for configuration comparison."""

import pandas as pd
import sys
from pathlib import Path

def analyze_session(csv_path: str):
    """Analyze a session CSV file."""
    df = pd.read_csv(csv_path)
    
    # Calculate metrics
    timestamps = df['timestamp_offset'].unique()
    time_span_ms = timestamps[-1] - timestamps[0]
    num_cycles = len(timestamps)
    firmware_rate = (num_cycles / time_span_ms) * 1000
    
    # Per-sensor stats
    print(f"\n=== Session Analysis: {Path(csv_path).name} ===")
    print(f"Time span: {time_span_ms} ms")
    print(f"Complete cycles: {num_cycles}")
    print(f"Firmware read rate: {firmware_rate:.1f} Hz")
    
    # Calculate gaps between timestamps
    gaps = pd.Series(timestamps).diff().dropna()
    print(f"Average gap between reads: {gaps.mean():.2f} ms")
    print(f"Min/Max gap: {gaps.min():.0f} / {gaps.max():.0f} ms")
    
    # Per-sensor proximity stats
    print(f"\n--- Proximity Statistics ---")
    for (pcb, side), group in df.groupby(['pcb_id', 'side']):
        prox = group['proximity']
        print(f"P{pcb}S{side}: baseline={prox.median():.0f}, peak={prox.max()}, range={prox.max()-prox.min()}")
    
    # Calculate effective sensor update rate
    # Look for actual value changes in proximity readings
    print(f"\n--- Effective Sensor Update Analysis ---")
    for (pcb, side), group in df.groupby(['pcb_id', 'side']):
        values = group['proximity'].values
        changes = sum(1 for i in range(1, len(values)) if values[i] != values[i-1])
        effective_rate = (changes / time_span_ms) * 1000
        redundancy = len(values) / max(changes, 1)
        print(f"P{pcb}S{side}: {changes} unique values in {len(values)} reads ({redundancy:.1f}x redundancy)")
    
    return df

if __name__ == "__main__":
    if len(sys.argv) < 2:
        print("Usage: python analyze_session.py <session.csv>")
        sys.exit(1)
    
    analyze_session(sys.argv[1])
```

---

## Quick Reference: Expected Sensor Rates

| Integration Time | Duty 1/40 | Duty 1/80 | Duty 1/160 | Duty 1/320 |
|---|---|---|---|---|
| 1T (125μs) | **200 Hz**| 100 Hz | 50 Hz | 25 Hz |
| 2T (250μs) | 100 Hz | 50 Hz | 25 Hz | 12.5 Hz |
| 4T (500μs) | 50 Hz | 25 Hz | 12.5 Hz | 6.25 Hz |
| 8T (1000μs) | 25 Hz | 12.5 Hz | 6.25 Hz | 3.125 Hz |

Formula: `Rate = 1000 / (pulse_μs × duty_denominator / 1000)`

---

*Last Updated: [Date]*

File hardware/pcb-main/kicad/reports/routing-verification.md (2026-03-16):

# PCB Routing Verification Report

**Source:** `motion-play-main.kicad_pcb`  
**SHA-256:** `94f079cce6bba778...`  
**Generated:** 2026-03-16 03:03 UTC  
**Board:** 83 footprints, 650 segments, 156 vias, 7 zones, 85 nets

## Summary: 19 PASS, 0 FAIL, 1 WARNING, 0 SKIP

| Check | Status | Detail |
|---|---|---|
| Trace Width Compliance | WARN | 111 power-net width deviations across 5 net classes (review recommended) |
| Zone: BOOST_SW on F.Cu | PASS | Switching loop copper pour — zone exists and has fill |
| Zone: +5V on F.Cu | PASS | Output cap cluster pour — zone exists and has fill |
| Zone: +5V on In2.Cu | PASS | +5V distribution plane — zone exists and has fill |
| Zone: GND on In1.Cu | PASS | Primary ground return plane — zone exists and has fill |
| Zone: GND on B.Cu | PASS | Bottom ground fill — zone exists and has fill |
| Zone: +3.3V on In2.Cu | PASS | Logic area 3.3V zone — zone exists and has fill |
| Path: BOOST_SW loop (U6 SW → L2 pad 1) | PASS | Connected via zone fill: U6.4 → L2.1 |
| Path: BQ_SW (U5 pins 19-20 → L1 pad 1) | PASS | Connected via traces/vias: U5.19 → L1.1 |
| Path: VSYS power (L1 pad 2 → R44 pad 1) | PASS | Connected via traces/vias: L1.2 → R44.1 |
| Path: VSYS_SENSE (R44 pad 2 → L2 pad 2) | PASS | Connected via traces/vias: R44.2 → L2.2 |
| Path: Protected_VBUS (F2 pad 2 → U5 pin 1) | PASS | Connected via traces/vias: F2.2 → U5.1 |
| I2C length match: Main trunk | PASS | SDA=82.0mm, SCL=86.6mm, diff=4.5mm |
| I2C length match: CH0 | PASS | SDA=13.8mm, SCL=13.3mm, diff=0.5mm |
| I2C length match: CH1 | PASS | SDA=8.4mm, SCL=8.3mm, diff=0.1mm |
| I2C length match: CH2 | PASS | SDA=10.8mm, SCL=10.9mm, diff=0.1mm |
| I2C isolation from switching nodes | PASS | All 102 I2C segments clear of 4 exclusion zones |
| Kelvin: VSYS sense (R44.1 → U7.1) | PASS | Dedicated thin path (0.25mm/0.3mm) exists, separate from 1.0mm power traces (17 sense segments) |
| Kelvin: VSYS_SENSE sense (R44.2 → U7.2) | PASS | Dedicated thin path (0.25mm/0.3mm) exists, separate from 1.0mm power traces (11 sense segments) |
| FB/COMP routing side | PASS | All FB/COMP traces stay left of U6 center (x < 83.6) |

## Details: trace_widths

### Trace Width Compliance — WARNING

```
  /Power Management/CC2 on F.Cu: expected 0.25mm, got 0.15mm at (92.5, 108.61)→(92.51, 108.62)
  /Power Management/CC2 on F.Cu: expected 0.25mm, got 0.15mm at (92.5, 107.68)→(92.5, 108.61)
  /Power Management/BOOST_FSW on F.Cu: expected 0.25mm, got 0.15mm at (84.55, 128.7)→(84.55, 128.38)
  /Power Management/BOOST_FSW on F.Cu: expected 0.25mm, got 0.15mm at (84.55, 128.38)→(85.22, 127.7)
  /Power Management/BOOST_FSW on B.Cu: expected 0.25mm, got 0.2mm at (85.33, 134.65)→(85.33, 132.23)
  ... and 2 more in Default
  +3.3V on F.Cu: expected 0.5mm, got 0.25mm at (135.28, 122.78)→(135.3, 122.8)
  +3.3V on F.Cu: expected 0.5mm, got 0.25mm at (151.5, 134)→(151.5, 133.5)
  +3.3V on F.Cu: expected 0.5mm, got 0.25mm at (123.7, 123.4)→(123.7, 122.86)
  +3.3V on F.Cu: expected 0.5mm, got 0.25mm at (122.8, 124.1)→(123, 124.1)
  +3.3V on F.Cu: expected 0.5mm, got 0.25mm at (151.5, 134)→(153.1, 134)
  ... and 13 more in Power_3V3
  +5V on F.Cu: expected 1.5mm, got 0.75mm at (115.4, 124.2)→(114.8, 123.6)
  /Power Management/BQ_REGN on F.Cu: expected 0.75mm, got 0.25mm at (102.13, 118.78)→(102.62, 118.78)
  /Power Management/BQ_REGN on F.Cu: expected 0.75mm, got 0.25mm at (103.4, 118.0)→(103.4, 115.08)
  /Power Management/BQ_REGN on F.Cu: expected 0.75mm, got 0.25mm at (96.09, 119.19)→(96.09, 120.18)
  /Power Management/BQ_REGN on F.Cu: expected 0.75mm, got 0.25mm at (96.07, 119.17)→(96.09, 119.19)
  /Power Management/BQ_REGN on F.Cu: expected 0.75mm, got 0.25mm at (96.07, 118.8)→(96.07, 119.17)
  ... and 6 more in Power_Low
  /Power Management/Protected_VBUS on F.Cu: expected 1.0mm, got 0.75mm at (93.03, 121.34)→(94.2, 120.16)
  /Power Management/Protected_VBUS on F.Cu: expected 1.0mm, got 1.5mm at (103.76, 110.28)→(104.7, 109.34)
  /Power Management/Protected_VBUS on F.Cu: expected 1.0mm, got 1.5mm at (104.7, 109)→(109.9, 103.8)
  /Power Management/Protected_VBUS on F.Cu: expected 1.0mm, got 0.75mm at (99.17, 110.61)→(93.59, 110.61)
  /Power Management/Protected_VBUS on F.Cu: expected 1.0mm, got 0.75mm at (92.4, 119.78)→(93.82, 119.78)
  ... and 69 more in Power_Med
```

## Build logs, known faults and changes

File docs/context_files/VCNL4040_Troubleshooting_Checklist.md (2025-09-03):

# VCNL4040 Sensor Troubleshooting Checklist

**Project:** Motion Play v3  
**Issue:** No I2C devices detected on any TCA9548A channel  
**Date:** _______________  
**Technician:** _______________

---

## 📋 Diagnostic Summary
- ✅ TCA9548A responds at 0x70 (multiplexer working)
- ✅ All 8 channels selectable
- ❌ **Zero devices found on any channel**
- ❌ No VCNL4040 sensors responding

---

## 🔧 Phase 1: Power Supply Verification
**Priority: HIGH** - Most likely cause

### 1.1 Main PCB Power Input
- [ ] **USB-C Power Module Status**
  - [ ] LED indicators ON? ____________
  - [ ] Output voltage: _____ V (expect ~5V)
  - [ ] Current draw: _____ mA

- [ ] **DWEII Power Module Check**
  - [ ] Module LED status: ____________
  - [ ] Input voltage stable: _____ V
  - [ ] Output current capability verified

### 1.2 Voltage Regulator (AMS1117-3.3V)
- [ ] **Input measurements:**
  - [ ] VIN: _____ V (should be ~5V)
  - [ ] GND continuity verified
  
- [ ] **Output measurements:**
  - [ ] VOUT: _____ V (should be 3.3V ±0.1V)
  - [ ] Load test with 100Ω resistor: _____ V
  - [ ] Ripple/noise acceptable

### 1.3 Main PCB 3.3V Distribution
- [ ] **TCA9548A Power:**
  - [ ] VCC pin: _____ V
  - [ ] GND connection verified
  - [ ] Decoupling capacitors present

- [ ] **Sensor PCB connectors (measure all 6):**
  - [ ] Ch0 VCC: _____ V
  - [ ] Ch1 VCC: _____ V  
  - [ ] Ch2 VCC: _____ V
  - [ ] Ch3 VCC: _____ V
  - [ ] Ch4 VCC: _____ V
  - [ ] Ch5 VCC: _____ V

**✋ STOP: If any voltage is wrong, fix power before continuing**

---

## 🔌 Phase 2: I2C Bus Integrity
**Complete only if Phase 1 passes**

### 2.1 Main I2C Bus (T-Display ↔ TCA9548A)
- [ ] **T-Display connections:**
  - [ ] Pin 43 (SDA) to TCA9548A SDA: _____ Ω
  - [ ] Pin 44 (SCL) to TCA9548A SCL: _____ Ω
  - [ ] No shorts to GND or VCC

- [ ] **Pull-up Resistors:**
  - [ ] SDA pull-up resistance: _____ kΩ (expect ~4.7kΩ)
  - [ ] SCL pull-up resistance: _____ kΩ (expect ~4.7kΩ)
  - [ ] Pull-ups to correct voltage (3.3V)

### 2.2 TCA9548A Channel Outputs
**Test each channel that should have sensors**

- [ ] **Channel 0 (if used):**
  - [ ] SDA continuity to connector: _____ Ω
  - [ ] SCL continuity to connector: _____ Ω
  - [ ] No cross-channel shorts

- [ ] **Channel 1 (if used):**
  - [ ] SDA continuity to connector: _____ Ω
  - [ ] SCL continuity to connector: _____ Ω
  - [ ] No cross-channel shorts

- [ ] **Channels 2-5 (if used):**
  - [ ] Ch2: SDA _____ Ω, SCL _____ Ω
  - [ ] Ch3: SDA _____ Ω, SCL _____ Ω  
  - [ ] Ch4: SDA _____ Ω, SCL _____ Ω
  - [ ] Ch5: SDA _____ Ω, SCL _____ Ω

---

## 🔗 Phase 3: Cable & Connector Verification
**Complete only if Phase 2 passes**

### 3.1 Cable Continuity Tests
**Test each sensor cable (main PCB to sensor PCB)**

- [ ] **Sensor Cable 1:**
  - [ ] VCC: _____ Ω (should be <1Ω)
  - [ ] GND: _____ Ω (should be <1Ω)
  - [ ] SDA: _____ Ω (should be <1Ω)
  - [ ] SCL: _____ Ω (should be <1Ω)

- [ ] **Sensor Cable 2:**
  - [ ] VCC: _____ Ω, GND: _____ Ω
  - [ ] SDA: _____ Ω, SCL: _____ Ω

- [ ] **Sensor Cables 3-6 (if connected):**
  - [ ] Cable 3: All connections <1Ω? ______
  - [ ] Cable 4: All connections <1Ω? ______
  - [ ] Cable 5: All connections <1Ω? ______
  - [ ] Cable 6: All connections <1Ω? ______

### 3.2 Connector Integrity
- [ ] **Main PCB connectors:**
  - [ ] All pins making contact
  - [ ] No bent or damaged pins
  - [ ] Proper insertion depth

- [ ] **Sensor PCB connectors:**
  - [ ] Proper seating verified
  - [ ] No mechanical damage
  - [ ] Retention clips engaged

---

## 🔬 Phase 4: Sensor PCB Analysis
**Complete only if Phase 3 passes**

### 4.1 Power Reaching VCNL4040 Chips
**Measure at each sensor PCB**

- [ ] **Sensor PCB 1:**
  - [ ] VCNL4040 VDD pin: _____ V (expect 3.3V)
  - [ ] VCNL4040 GND connection verified
  - [ ] No shorts between power rails

- [ ] **Sensor PCB 2:**
  - [ ] VCNL4040 VDD: _____ V
  - [ ] GND verified: ______

- [ ] **Additional sensor PCBs:**
  - [ ] PCB 3 power: _____ V
  - [ ] PCB 4 power: _____ V
  - [ ] PCB 5 power: _____ V
  - [ ] PCB 6 power: _____ V

### 4.2 VCNL4040 I2C Connections
- [ ] **Sensor PCB 1:**
  - [ ] SDA to VCNL4040 pin: _____ Ω
  - [ ] SCL to VCNL4040 pin: _____ Ω
  - [ ] No shorts to power/ground

- [ ] **Check for cold solder joints:**
  - [ ] VCNL4040 pin soldering looks good
  - [ ] Connector soldering verified
  - [ ] No obvious bridging

### 4.3 Daisy-Chain Power Distribution
**If using daisy-chain power connections**

- [ ] **Power forwarding connections:**
  - [ ] PCB 1 → PCB 2: _____ V
  - [ ] PCB 2 → PCB 3: _____ V
  - [ ] Each link <0.1V drop

---

## 🧪 Phase 5: Isolation Testing
**If systematic issues found**

### 5.1 Single Sensor Test
- [ ] **Disconnect all but one sensor PCB**
  - [ ] Selected sensor PCB: ______
  - [ ] Connected to channel: ______

- [ ] **Test with shortest possible cable**
  - [ ] Cable length: _____ cm
  - [ ] Direct connection (no daisy-chain)

- [ ] **Re-run diagnostic code:**
  - [ ] Device detected? ______
  - [ ] I2C address found: ______
  - [ ] Device ID response: ______

### 5.2 Known Good Component Test
- [ ] **If available, test with:**
  - [ ] VCNL4040 breakout board
  - [ ] Simple I2C device (e.g., EEPROM)
  - [ ] Different sensor PCB

---

## 📊 Results Summary

### Measurements Record
| Component | Expected | Measured | Status |
|---|---|---|---|
| DWEII Power Module | ~5V | 5.2V | ✅ GOOD |
| J3 LED Power Strip | ~5V | 5.2V | ✅ GOOD |
| After Schottky Diode | ~5V | ~5V | ✅ GOOD |
| After 0.1μF Capacitor | ~5V | <5V | ⚠️ SLIGHT DROP |
| **After 10μF Capacitor** | **~5V** | **0.1-0.3V** | **❌ CRITICAL FAILURE** |
| AMS1117 Input | ~5V | _____ V | _____ |
| AMS1117 Output | 3.3V | _____ V | _____ |
| TCA9548A VCC | 3.3V | _____ V | _____ |

### Likely Root Cause
Based on test results:
- [ ] Power supply issue
- [ ] I2C pull-up problem  
- [ ] Cable/connector failure
- [ ] VCNL4040 chip failure
- [ ] PCB manufacturing defect

### Notes & Observations
```
_________________________________________________
_________________________________________________
_________________________________________________
_________________________________________________
_________________________________________________
```

---

## 🛠️ Required Tools
- [ ] Digital multimeter
- [ ] Oscilloscope (optional, for signal integrity)
- [ ] Magnifying glass/microscope
- [ ] Fine-tip probes
- [ ] Jumper wires for testing
- [ ] Known good VCNL4040 breakout (if available)

---

## ⚠️ Safety Notes
- [ ] Power off before making connections
- [ ] Check polarity before applying power
- [ ] Use ESD protection when handling PCBs
- [ ] Double-check measurements before concluding

---

**Completion Date:** _______________  
**Final Status:** _______________  
**Next Steps:** _______________

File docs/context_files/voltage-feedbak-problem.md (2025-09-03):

Problem & Solution Summary
The Problem

Symptoms: Inconsistent VCNL4040 sensor detection, random voltage readings (1.4V, 3.3V, high voltages), "things change all the time"
Root Cause: Dual 3.3V regulators connected to same output rail

Technical Details
T-Display-S3 Architecture:

Pin 1 ("3v"): OUTPUT from internal AP2112K-3.3V regulator
Pin 12 ("5V"): INPUT power to T-Display

The Conflict:

Your main PCB connected T-Display Pin 1 → Main board 3.3V net
Your main PCB connected AMS1117 output → Same main board 3.3V net
Result: Two active 3.3V regulators fighting each other on same rail

Power Flow Problems:
T-Display USB Scenario:
USB 5V → T-Display → 3.3V out Pin 1 → Main 3.3V net ← AMS1117 ← T-Display Pin 12 ← USB 5V

DWEII Scenario:  
DWEII 5V → AMS1117 → 3.3V AND DWEII 5V → T-Display Pin 12 → T-Display 3.3V → Same net
The Solution
Immediate Fix (What You Did):

Disconnected T-Display 3.3V pins (Pin 1 + other 3V pins) from main board
Kept 5V pin connected so T-Display can still run code and control TCA
Result: Eliminated regulator conflict, stabilized power supply

Why This Works:

T-Display gets power via 5V pin (can run code)
T-Display 3.3V outputs isolated (no regulator fighting)
AMS1117 has sole control of main board 3.3V rail
GPIO signals (SDA/SCL) still work at compatible 3.3V levels

Long-term PCB Redesign Solution

MCU gets power from AMS1117, not the other way around
MCU USB isolated for programming only
Single clean power domain eliminates conflicts
Add comprehensive debugging features (test points, LEDs, etc.)

Key Lesson
The problem wasn't simultaneous power sources - it was architectural: connecting two voltage regulator outputs to the same net, causing them to fight each other regardless of timing.

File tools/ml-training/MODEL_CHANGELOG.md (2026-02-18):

# Model Changelog

Tracks each trained model version with its parameters, dataset, and metrics.

## Versions

### v1.0 (initial, pre-versioning)

- **Date:** ~2026-02-15
- **Dataset:** 46 sessions (15 a_to_b, 19 b_to_a, 12 no_transit)
- **Architecture:** 1D CNN — Conv1D(16,5) → MaxPool → Conv1D(32,3) → MaxPool → Dense(32) → Dropout(0.3) → Dense(3)
- **Window:** 300ms, centered on peak
- **Normalization:** Per-dataset max (~490.0)
- **Quantization:** Float32 (no quantization)
- **Model size:** 321,132 bytes
- **Validation accuracy:** ~90%
- **On-device detection rate:** ~57% of triggers produce detections
- **Inference time:** ~140ms (float32, PSRAM arena)
- **Notes:** First working model. Normalization used per-dataset max (mismatched with firmware's fixed 490.0 constant). Window centered on peak (mismatched with firmware's trigger-end-aligned extraction). These pipeline mismatches likely explain the gap between 90% validation accuracy and ~57% on-device detection rate.

---

*Template for new versions:*

```
### vYYYYMMDD-Nsess-alignment-normN

- **Date:** YYYY-MM-DD
- **Dataset:** N sessions (X a_to_b, Y b_to_a, Z no_transit)
- **Architecture:** (describe any changes)
- **Window:** 300ms, trigger-aligned (or centered)
- **Normalization:** Fixed constant = N (matching firmware)
- **Quantization:** Float32 / Int8
- **Model size:** N bytes
- **Validation accuracy:** N%
- **On-device detection rate:** N%
- **Inference time:** Nms
- **Notes:** What changed and why
```

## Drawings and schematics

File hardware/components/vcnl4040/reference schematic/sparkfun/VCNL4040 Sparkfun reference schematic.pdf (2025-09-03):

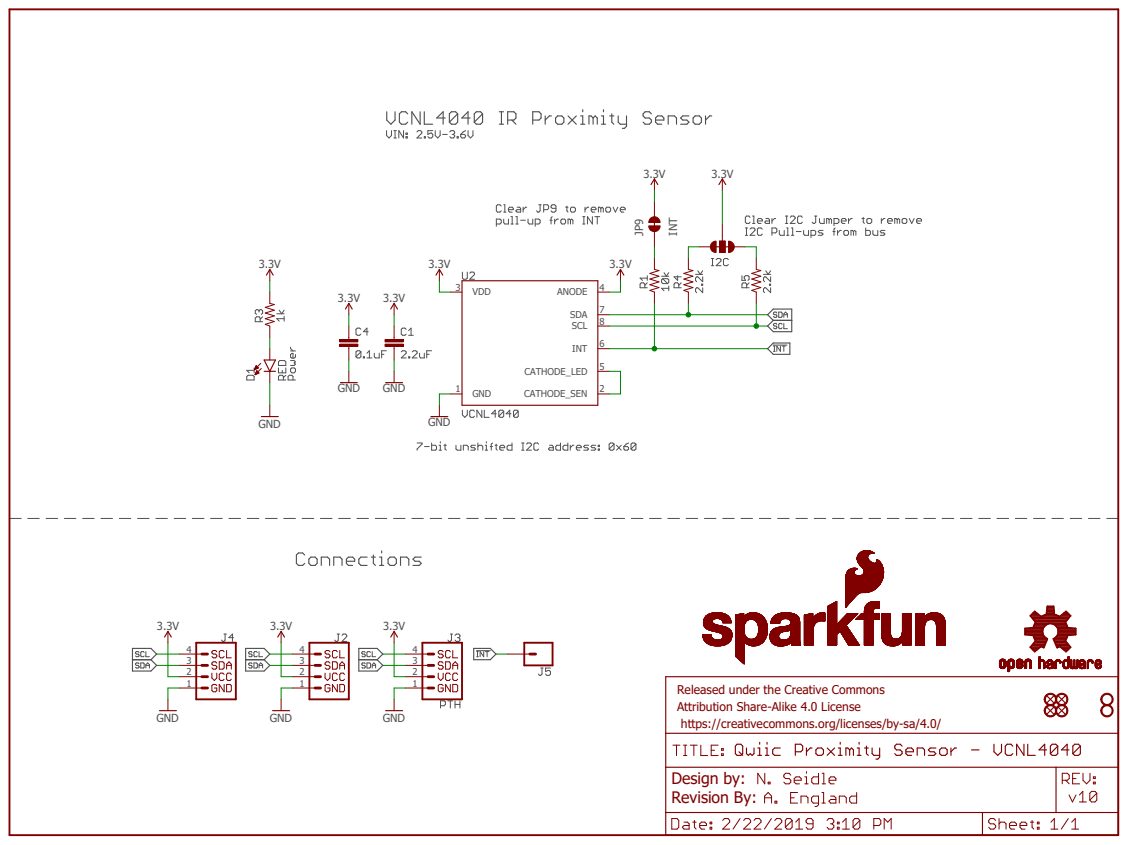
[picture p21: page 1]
GND; 3.3V INT; ANODE 4 CATHODE_LED 5; CATHODE_SEN 2 GND 1; INT 6; Design by: Revision By:

SCL 8 SDA 7 VDD 3

Released under the Creative Commons
Attribution Share-Alike 4.0 License
https://creativecommons.org/licenses/by-sa/4.0/

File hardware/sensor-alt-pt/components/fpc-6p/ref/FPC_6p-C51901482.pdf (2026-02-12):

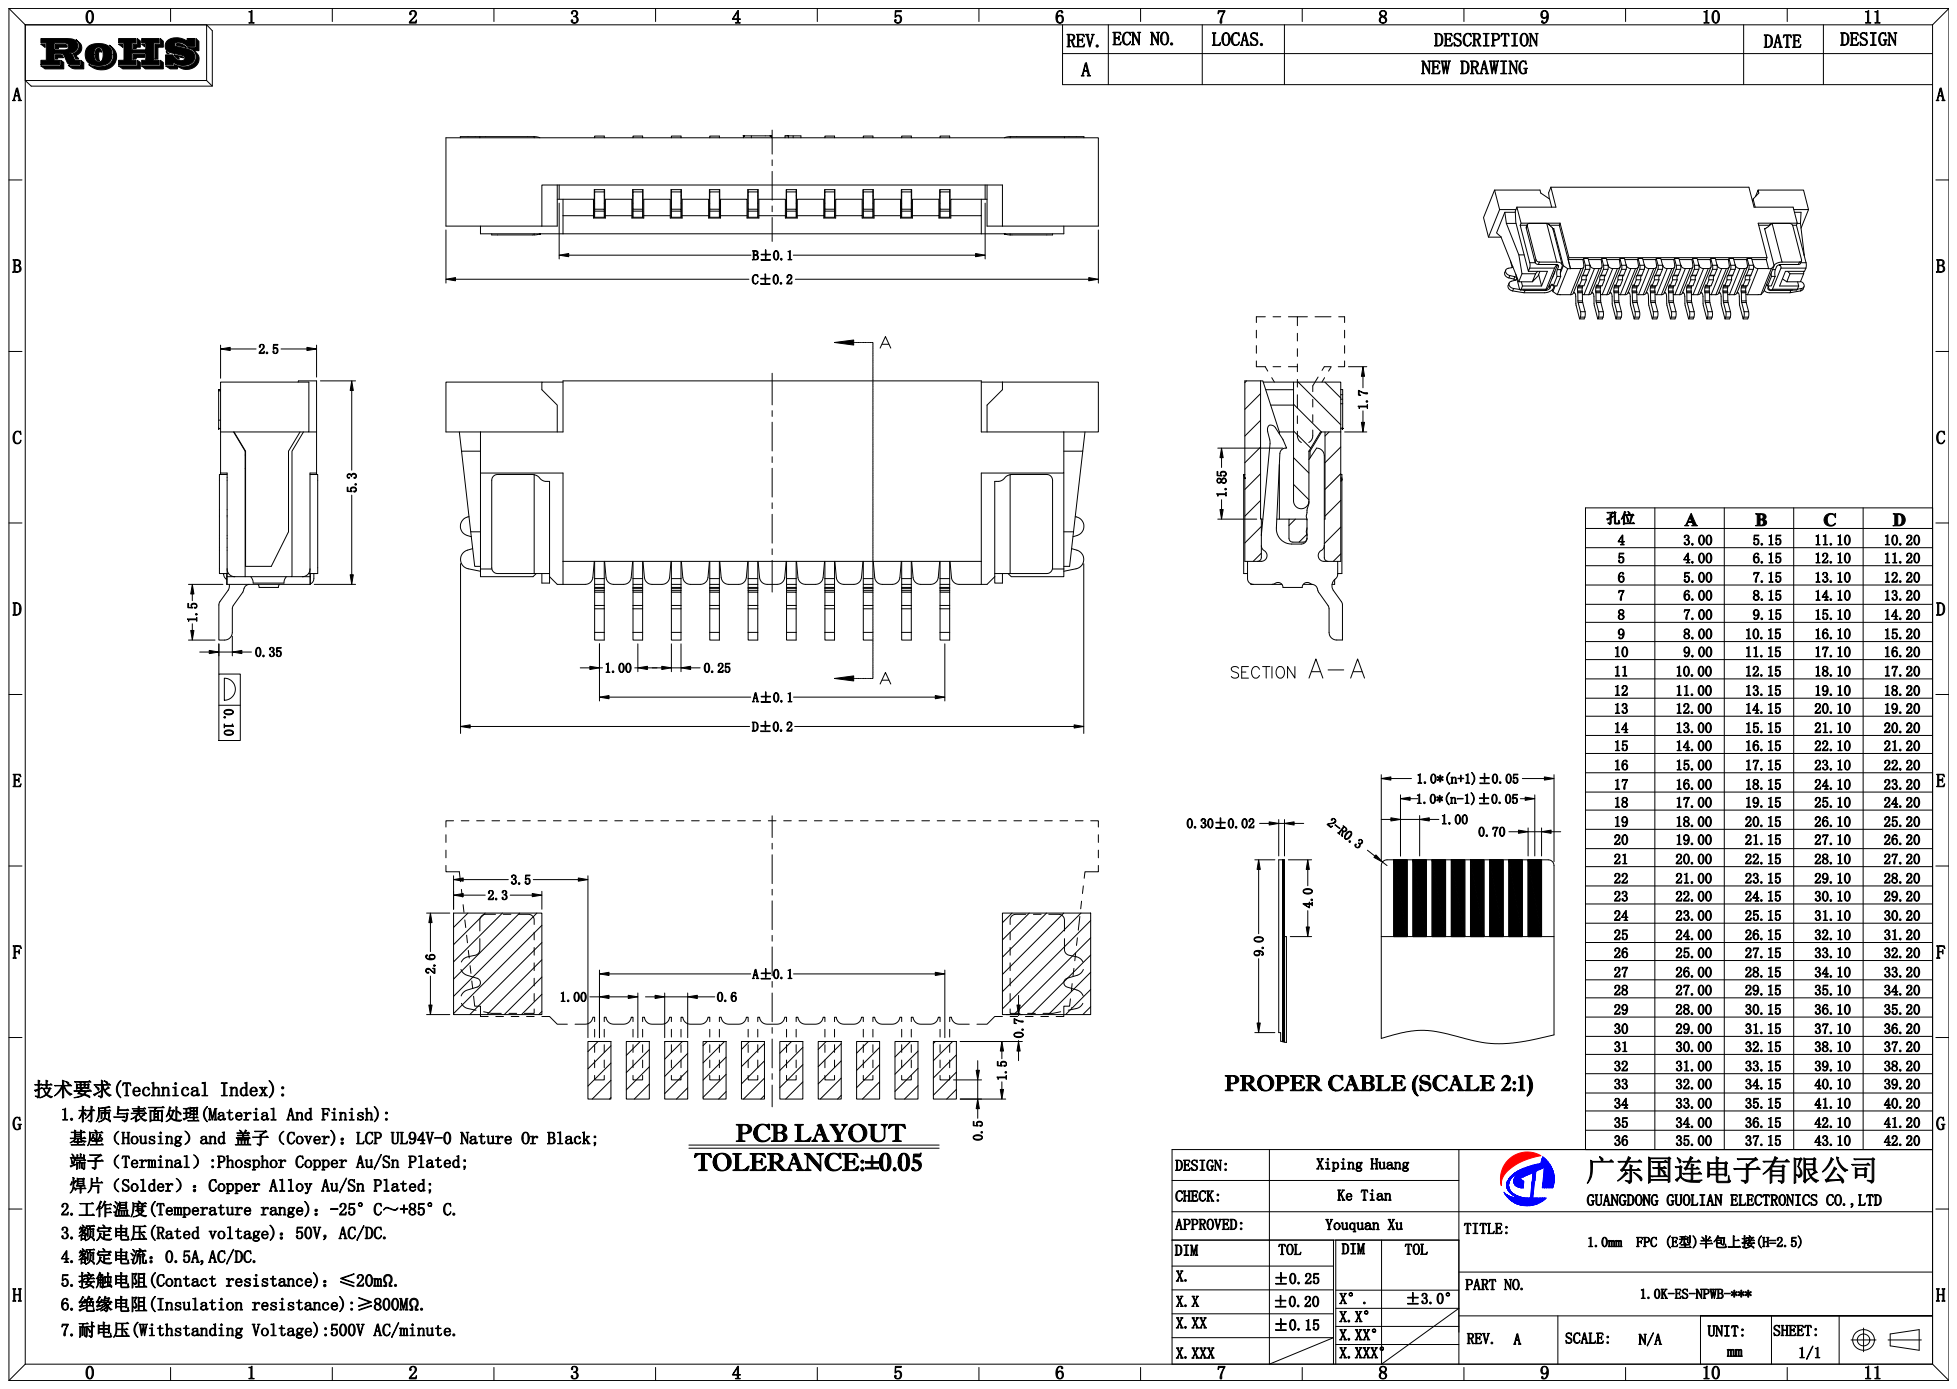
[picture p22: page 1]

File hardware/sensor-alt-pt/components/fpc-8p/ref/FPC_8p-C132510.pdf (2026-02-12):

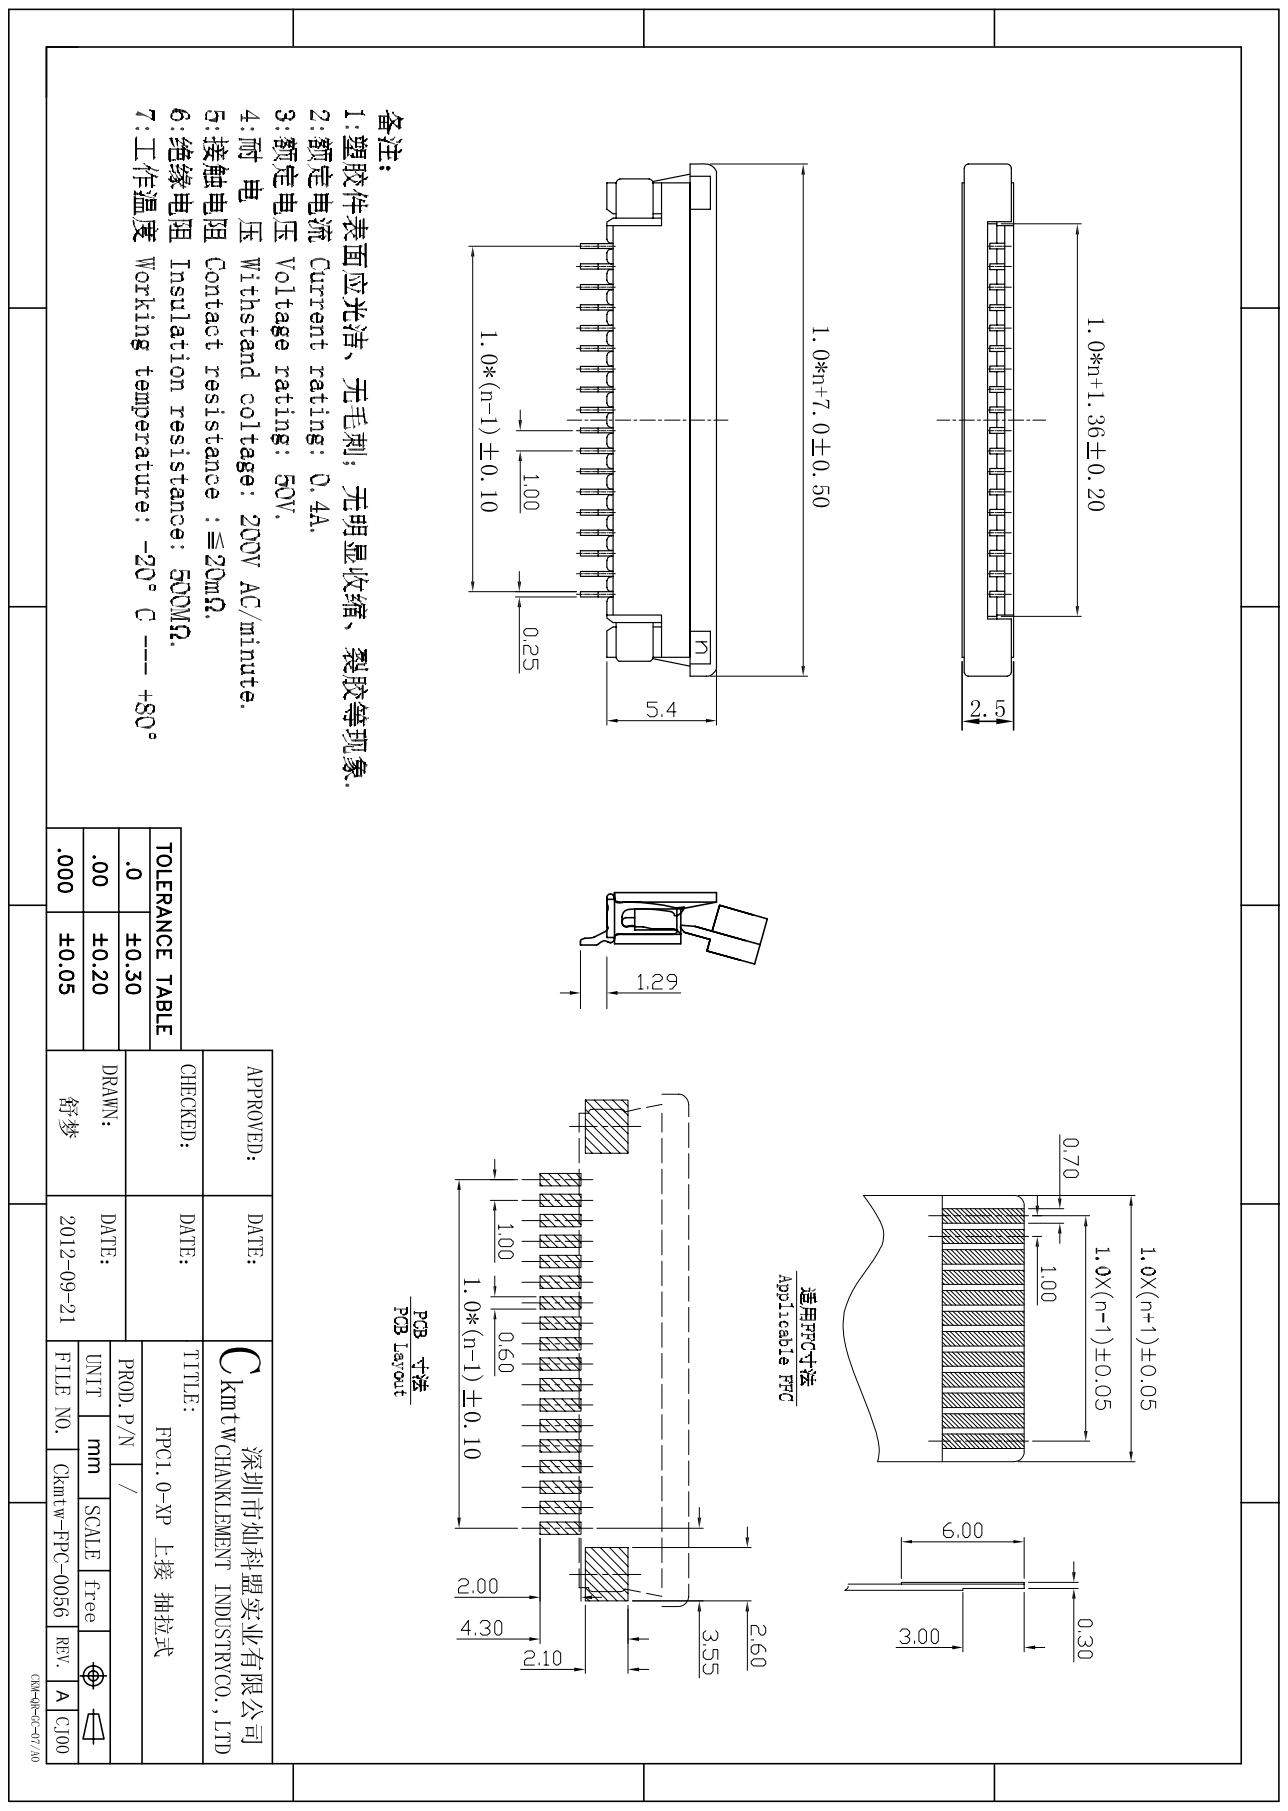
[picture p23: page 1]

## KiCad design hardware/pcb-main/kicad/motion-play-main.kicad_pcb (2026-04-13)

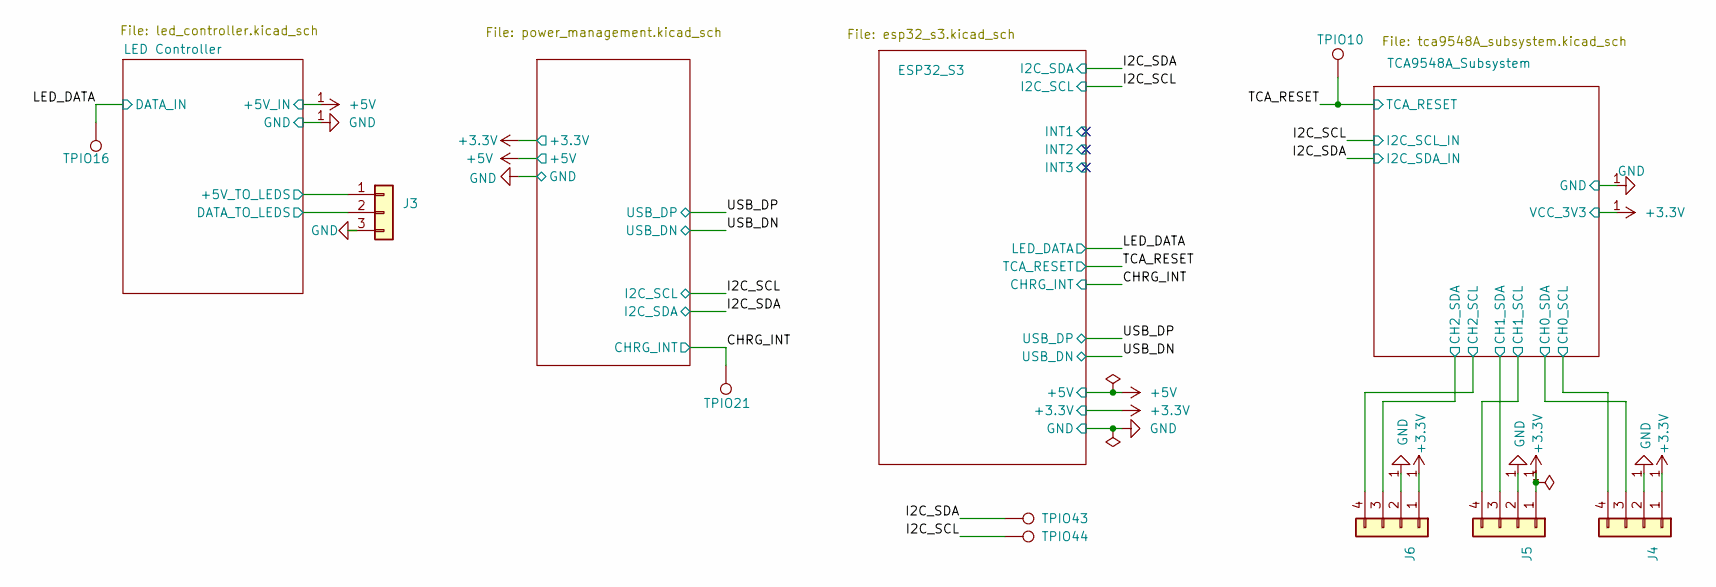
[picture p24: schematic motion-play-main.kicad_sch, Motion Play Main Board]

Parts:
J3: LED_Strip; JST_PH_S3B-PH-SM4-TB_1x03-1MP_P2.00mm_Horizontal; LCSC Part C265101
J4, J5, J6: Conn_01x04; JST_SH_SM04B-SRSS-TB_1x04-1MP_P1.00mm_Horizontal; LCSC Part No C160404
TPIO10, TPIO16, TPIO21, TPIO43, TPIO44: TestPoint; TestPoint_Pad_D2.0mm

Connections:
+3.3V: J4.1, J5.1, J6.1; also elsewhere on the board
/CHRG_INT: TPIO21.1; also elsewhere on the board
/I2C_SCL: TPIO44.1; also elsewhere on the board
/I2C_SDA: TPIO43.1; also elsewhere on the board
/LED Controller/+5V_TO_LEDS: J3.1; also elsewhere on the board
/LED Controller/DATA_TO_LEDS: J3.2; also elsewhere on the board
/LED_DATA: TPIO16.1; also elsewhere on the board
/TCA9548A_Subsystem/CH0_SCL: J4.4; also elsewhere on the board
/TCA9548A_Subsystem/CH0_SDA: J4.3; also elsewhere on the board
/TCA9548A_Subsystem/CH1_SCL: J5.4; also elsewhere on the board
/TCA9548A_Subsystem/CH1_SDA: J5.3; also elsewhere on the board
/TCA9548A_Subsystem/CH2_SCL: J6.4; also elsewhere on the board
/TCA9548A_Subsystem/CH2_SDA: J6.3; also elsewhere on the board
/TCA_RESET: TPIO10.1; also elsewhere on the board
GND: J3.3, J4.2, J5.2, J6.2; also elsewhere on the board

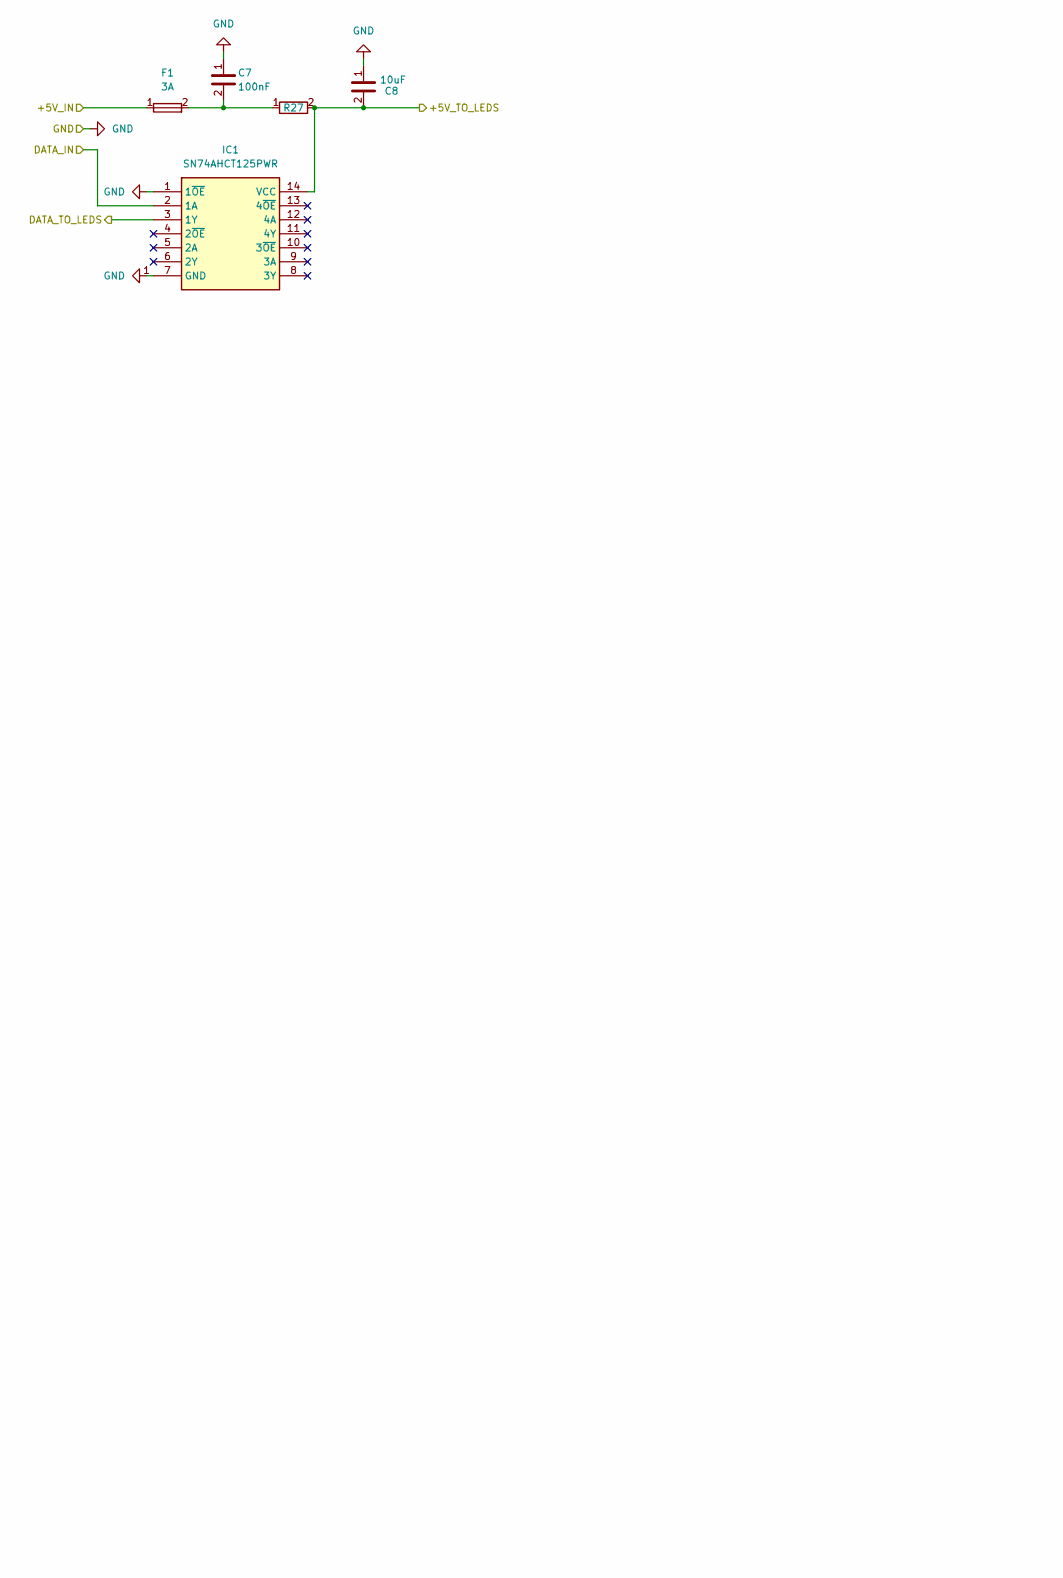
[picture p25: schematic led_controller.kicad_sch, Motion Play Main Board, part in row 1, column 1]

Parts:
C7: 100nF; C_0603_1608Metric; LCSC Part No C14663
C8: 10uF; C_0603_1608Metric; LCSC Part No C19702
F1: 3A; Fuse_1206_3216Metric; LCSC Part No C354897
IC1: SN74AHCT125PWR; SOP65P640X120-14N; Mouser Part Number 595-SN74AHCT125PWR
R27: 0.1R; R_2512_6332Metric; LCSC Part No C2903476

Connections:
+5V: F1.1; also elsewhere on the board
/LED Controller/+5V_TO_LEDS: C8.2, IC1.14 (VCC), R27.2; also elsewhere on the board
/LED Controller/DATA_TO_LEDS: IC1.3 (1Y); also elsewhere on the board
/LED_DATA: IC1.2 (1A); also elsewhere on the board
GND: C7.1, C8.1, IC1.1 (1~OE), IC1.7 (GND); also elsewhere on the board
unnamed: C7.2, F1.2, R27.1

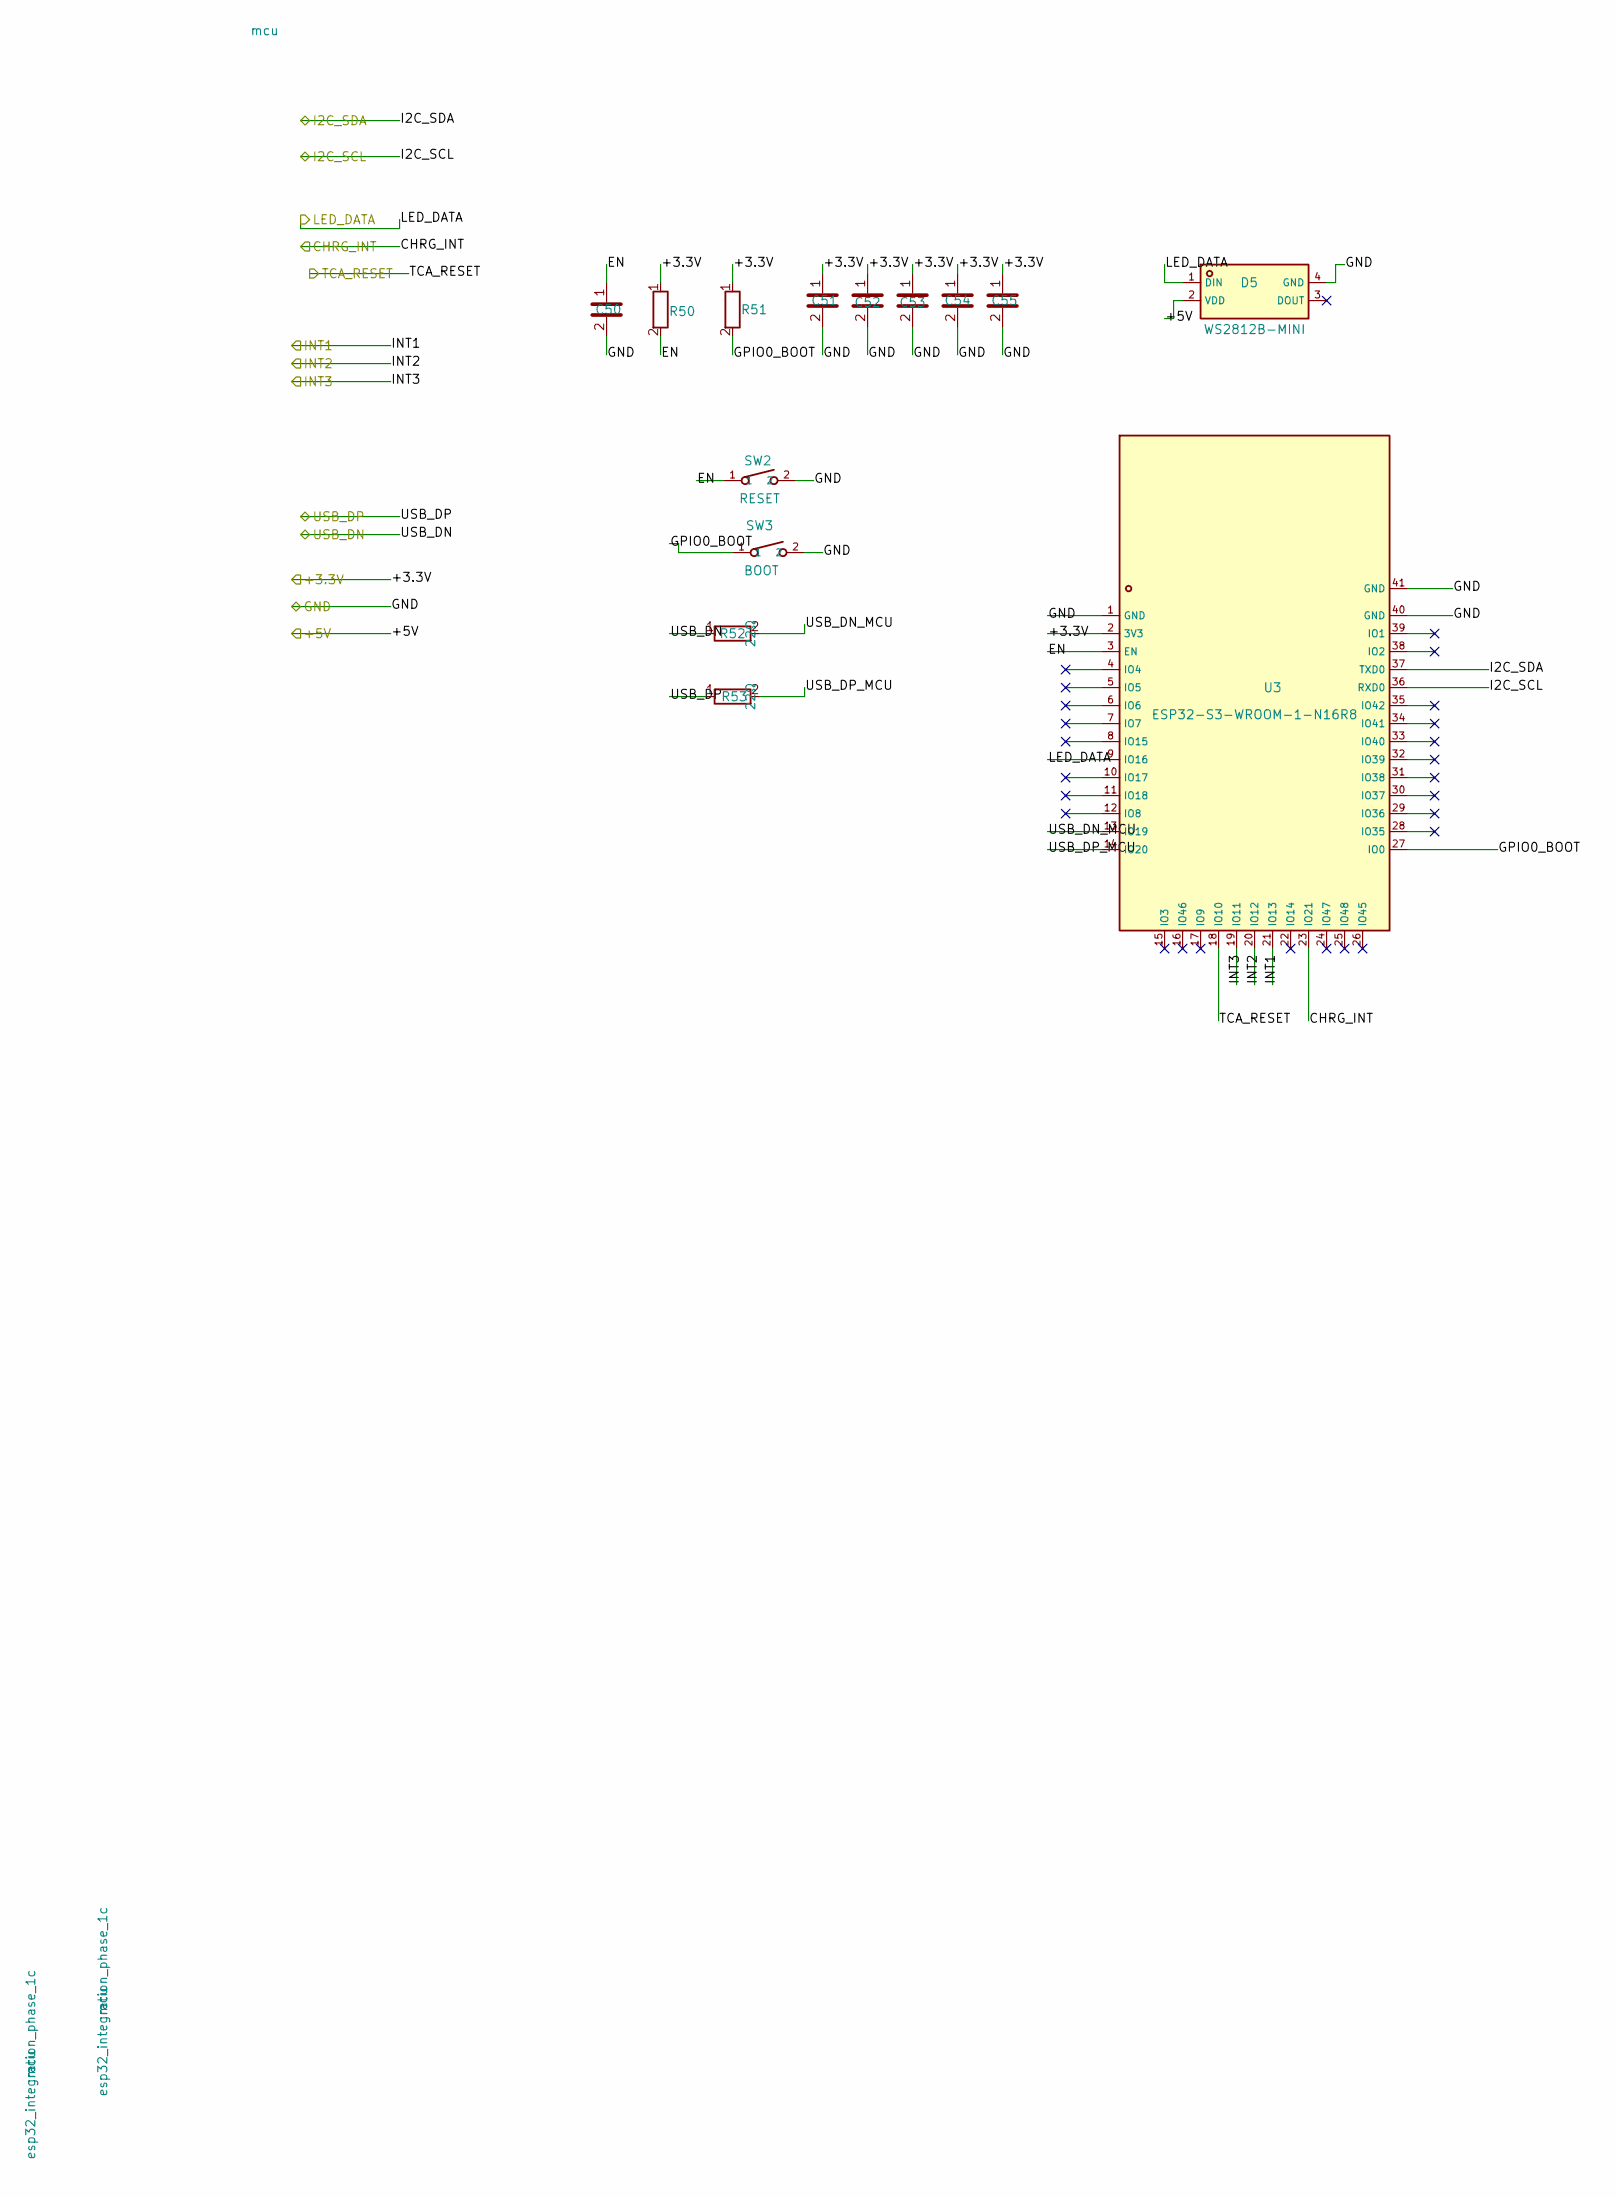
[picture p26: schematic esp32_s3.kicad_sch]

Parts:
C50, C55: 1µF; C_0603_1608Metric; LCSC Part C15849
C51: 10µF; C_0603_1608Metric; LCSC Part C96446
C52, C53, C54: 100nF; C_0603_1608Metric; LCSC Part C14663
D5: WS2812B-MINI; LED-SMD_4P-L3.5-W3.5-TL_WS2812B-1; LCSC Part C4154873
R50, R51: 10kΩ; R_0603_1608Metric; LCSC Part C25804
R52, R53: 22Ω; R_0603_1608Metric; LCSC Part C23345
SW2: RESET; KEY-SMD_L4.0-W3.0-LS4.9-1; LCSC Part C49234124
SW3: BOOT; KEY-SMD_L4.0-W3.0-LS4.9-1; LCSC Part C49234124
U3: ESP32-S3-WROOM-1-N16R8; WIRELM-SMD_ESP32-S3-WROOM-1; LCSC Part C2913202

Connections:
+3.3V: C51.1, C52.1, C53.1, C54.1, C55.1, R50.1, R51.1, U3.2 (3V3); also elsewhere on the board
+5V: D5.2 (VDD); also elsewhere on the board
/CHRG_INT: U3.23 (IO21); also elsewhere on the board
/ESP32_S3/EN: C50.1, R50.2, SW2.1, U3.3 (EN)
/ESP32_S3/GPIO0_BOOT: R51.2, SW3.1, U3.27 (IO0)
/ESP32_S3/INT1: U3.21 (IO13)
/ESP32_S3/INT2: U3.20 (IO12)
/ESP32_S3/INT3: U3.19 (IO11)
/ESP32_S3/USB_DN_MCU: R52.2, U3.13 (IO19)
/ESP32_S3/USB_DP_MCU: R53.2, U3.14 (IO20)
/I2C_SCL: U3.36 (RXD0); also elsewhere on the board
/I2C_SDA: U3.37 (TXD0); also elsewhere on the board
/LED_DATA: D5.1 (DIN), U3.9 (IO16); also elsewhere on the board
/TCA_RESET: U3.18 (IO10); also elsewhere on the board
/USB_DN: R52.1; also elsewhere on the board
/USB_DP: R53.1; also elsewhere on the board
GND: C50.2, C51.2, C52.2, C53.2, C54.2, C55.2, D5.4 (GND), SW2.2, SW3.2, U3.1 (GND), U3.40 (GND), U3.41 (GND); also elsewhere on the board

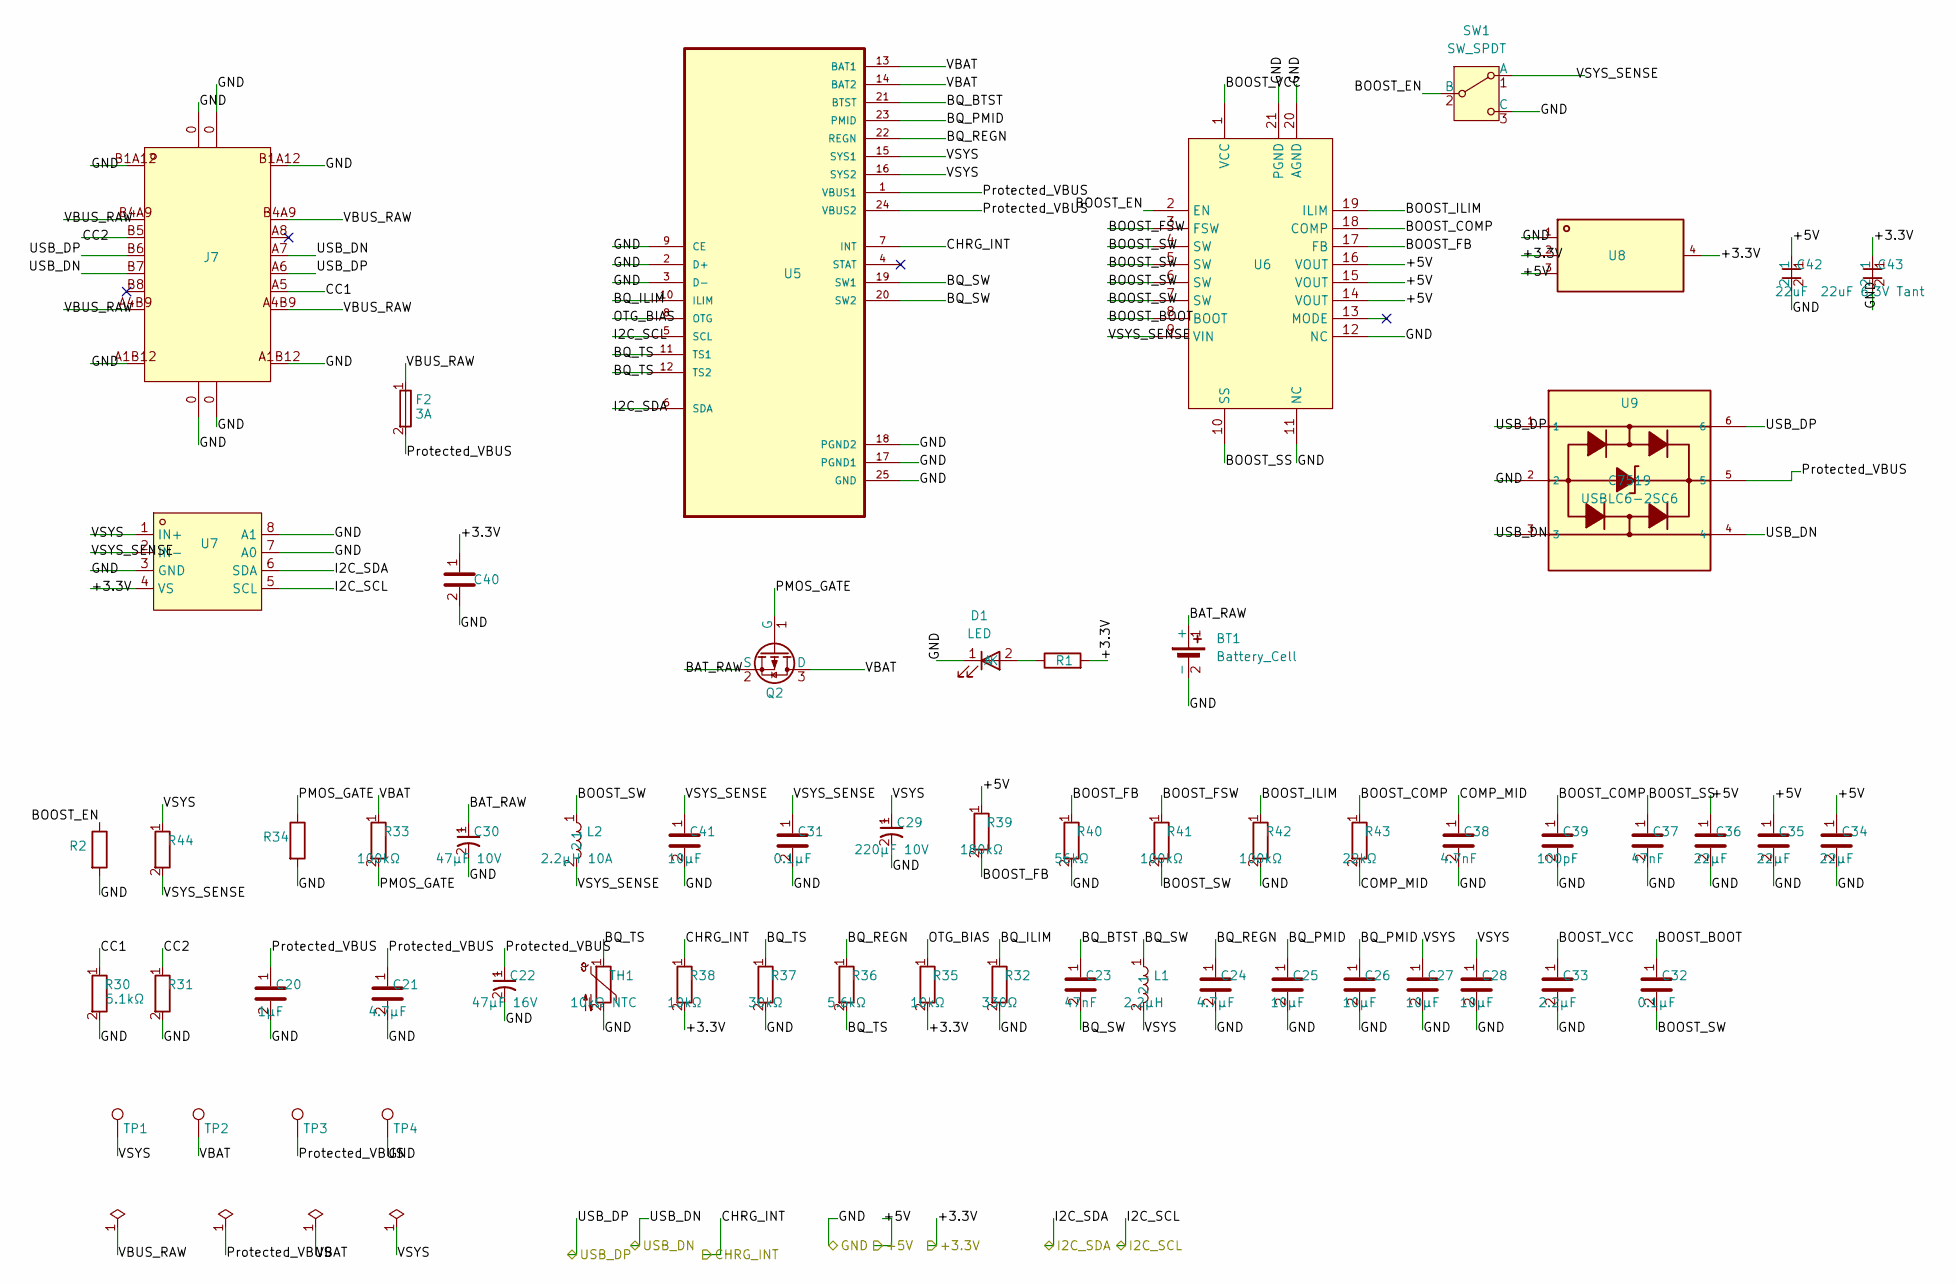
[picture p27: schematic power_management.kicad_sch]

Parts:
BT1: Battery_Cell; BatteryHolder_Keystone_1042_1x18650
C20: 1µF; C_0603_1608Metric; LCSC Part C15849
C21, C24: 4.7µF; C_0603_1608Metric; LCSC Part C19666
C22: 47µF 16V; C_Elec_6.3x5.4; LCSC Part C7469958
C23, C37: 47nF; C_0603_1608Metric; LCSC Part C107093
C25, C26, C27, C28: 10µF; C_0603_1608Metric; LCSC Part C96446
C29: 220µF 10V; CP_Elec_6.3x7.7; LCSC Part C3342
C30: 47µF 10V; C_Elec_6.3x5.4; LCSC Part C7469958
C31, C32, C40: 0.1µF; C_0603_1608Metric; LCSC Part C14663
C33: 2.2µF; C_0603_1608Metric; LCSC Part C23630
C34, C35, C36: 22µF; C_0805_2012Metric; LCSC Part C109314
C38: 4.7nF; C_0603_1608Metric; LCSC Part C1621
C39: 100pF; C_0603_1608Metric; LCSC Part C14858
C41: 10µF; C_0805_2012Metric; LCSC Part C15850
C42: 22uF; C0805; LCSC Part C109314
C43: 22uF 6.3V Tant; CASE-A_3216; LCSC Part C129288
D1: LED; LED_0603_1608Metric; LCSC Part C19171301
F2: 3A; Fuse_1206_3216Metric; LCSC Part C2897466
J7: TYPE-C-31-M-12; USB-C_SMD-TYPE-C-31-M-12_1; LCSC Part C165948
L1: 2.2µH; L_Changjiang_FNR6028S; LCSC Part C266426
L2: 2.2µH 10A; IND-SMD_L7.0-W6.6; LCSC Part C167218
Q2: PMOS; SOT-23; LCSC Part C15127
R1: 1kΩ; R_0603_1608Metric; LCSC Part C22548
R2, R33, R34, R41, R42: 100kΩ; R_0603_1608Metric; LCSC Part C14675
R30, R31: 5.1kΩ; R_0603_1608Metric; LCSC Part C23186
R32: 330Ω; R_0603_1608Metric; LCSC Part C23138
R35, R38: 10kΩ; R_0603_1608Metric; LCSC Part C25804
R36: 5.6kΩ; R_0603_1608Metric; LCSC Part C23189
R37: 30kΩ; R_0603_1608Metric; LCSC Part C22984
R39: 180kΩ; R_0603_1608Metric; LCSC Part C22827
R40: 56kΩ; R_0603_1608Metric; LCSC Part C23206
R43: 22kΩ; R_0603_1608Metric; LCSC Part C31850
R44: 10mΩ; R_2512_6332Metric; LCSC Part C1322424
SW1: SW_SPDT; MK-12C02-G020_GSW; LCSC Part C431540
TH1: 10kΩ NTC; R_0603_1608Metric; LCSC Part C13564
TP1: VSYS; TestPoint_Pad_D1.5mm
TP2: VBAT; TestPoint_Pad_D1.5mm
TP3: PVBUS; TestPoint_Pad_D1.5mm
TP4: PGND; TestPoint_Pad_D1.5mm
U5: BQ24195RGER; VQFN-24_L4.0-W4.0-P0.50-TL-EP2.8; LCSC Part C90862
U6: TPS61088RHLR; VQFN-20_L4.6-W3.6-P0.50-BL; LCSC Part C87357
U7: INA219AIDCNR; SOT-23-8_L3.0-W1.7-P0.65-LS2.8-BR; LCSC Part C87469
U8: AMS1117-3.3; SOT-223-3_L6.5-W3.4-P2.30-LS7.0-BR; LCSC Part C6186
U9: USBLC6-2SC6; SOT-23-6_L2.9-W1.6-P0.95-LS2.8-BL; LCSC Part C7519

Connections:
+3.3V: C40.1, C43.1, R1.2, R35.2, R38.2, U7.4 (VS), U8.2 (VOUT), U8.4 (VOUT); also elsewhere on the board
+5V: C34.1, C35.1, C36.1, C42.1, R39.1, U6.14 (VOUT), U6.15 (VOUT), U6.16 (VOUT), U8.3 (VIN); also elsewhere on the board
/CHRG_INT: R38.1, U5.7 (INT); also elsewhere on the board
/I2C_SCL: U5.5 (SCL), U7.5 (SCL); also elsewhere on the board
/I2C_SDA: U5.6 (SDA), U7.6 (SDA); also elsewhere on the board
/Power Management/BAT_RAW: BT1.1 (+), C30.1, Q2.2 (S)
/Power Management/BOOST_BOOT: C32.1, U6.8 (BOOT)
/Power Management/BOOST_COMP: C39.1, R43.1, U6.18 (COMP)
/Power Management/BOOST_EN: R2.1, SW1.2 (B), U6.2 (EN)
/Power Management/BOOST_FB: R39.2, R40.1, U6.17 (FB)
/Power Management/BOOST_FSW: R41.1, U6.3 (FSW)
/Power Management/BOOST_ILIM: R42.1, U6.19 (ILIM)
/Power Management/BOOST_SS: C37.1, U6.10 (SS)
/Power Management/BOOST_SW: C32.2, L2.1, R41.2, U6.4 (SW), U6.5 (SW), U6.6 (SW), U6.7 (SW)
/Power Management/BOOST_VCC: C33.1, U6.1 (VCC)
/Power Management/BQ_BTST: C23.1, U5.21 (BTST)
/Power Management/BQ_ILIM: R32.1, U5.10 (ILIM)
/Power Management/BQ_PMID: C25.1, C26.1, U5.23 (PMID)
/Power Management/BQ_REGN: C24.1, R36.1, U5.22 (REGN)
/Power Management/BQ_SW: C23.2, L1.1, U5.19 (SW1), U5.20 (SW2)
/Power Management/BQ_TS: R36.2, R37.1, TH1.1, U5.11 (TS1), U5.12 (TS2)
/Power Management/CC1: J7.A5 (CC1), R30.1
/Power Management/CC2: J7.B5 (CC2), R31.1
/Power Management/COMP_MID: C38.1, R43.2
/Power Management/OTG_BIAS: R35.1, U5.8 (OTG)
/Power Management/PMOS_GATE: Q2.1 (G), R33.2, R34.1
/Power Management/Protected_VBUS: C20.1, C21.1, C22.1, F2.2, TP3.1, U5.1 (VBUS1), U5.24 (VBUS2), U9.5
/Power Management/VBAT: Q2.3 (D), R33.1, TP2.1, U5.13 (BAT1), U5.14 (BAT2)
/Power Management/VBUS_RAW: F2.1, J7.A4B9 (VBUS), J7.B4A9 (VBUS)
/Power Management/VSYS: C27.1, C28.1, C29.1, L1.2, R44.1, TP1.1, U5.15 (SYS1), U5.16 (SYS2), U7.1 (IN+)
/Power Management/VSYS_SENSE: C31.1, C41.1, L2.2, R44.2, SW1.1 (A), U6.9 (VIN), U7.2 (IN-)
/USB_DN: J7.A7 (DN1), J7.B7 (DN2), U9.3, U9.4; also elsewhere on the board
/USB_DP: J7.A6 (DP1), J7.B6 (DP2), U9.1, U9.6; also elsewhere on the board
GND: BT1.2 (-), C20.2, C21.2, C22.2, C24.2, C25.2, C26.2, C27.2, C28.2, C29.2, C30.2, C31.2, C33.2, C34.2, C35.2, C36.2, C37.2, C38.2, C39.2, C40.2, C41.2, C42.2, C43.2, D1.1 (K), J7.0 (SH), J7.A1B12 (GND), J7.B1A12 (GND), R2.2, R30.2, R31.2, R32.2, R34.2, R37.2, R40.2, R42.2, SW1.3 (C), TH1.2, TP4.1, U5.2 (D+), U5.3 (D-), U5.9 (CE), U5.17 (PGND1), U5.18 (PGND2), U5.25 (GND), U6.11 (NC), U6.12 (NC), U6.20 (AGND), U6.21 (PGND), U7.3 (GND), U7.7 (A0), U7.8 (A1), U8.1 (GND), U9.2; also elsewhere on the board
unnamed: D1.2 (A), R1.1

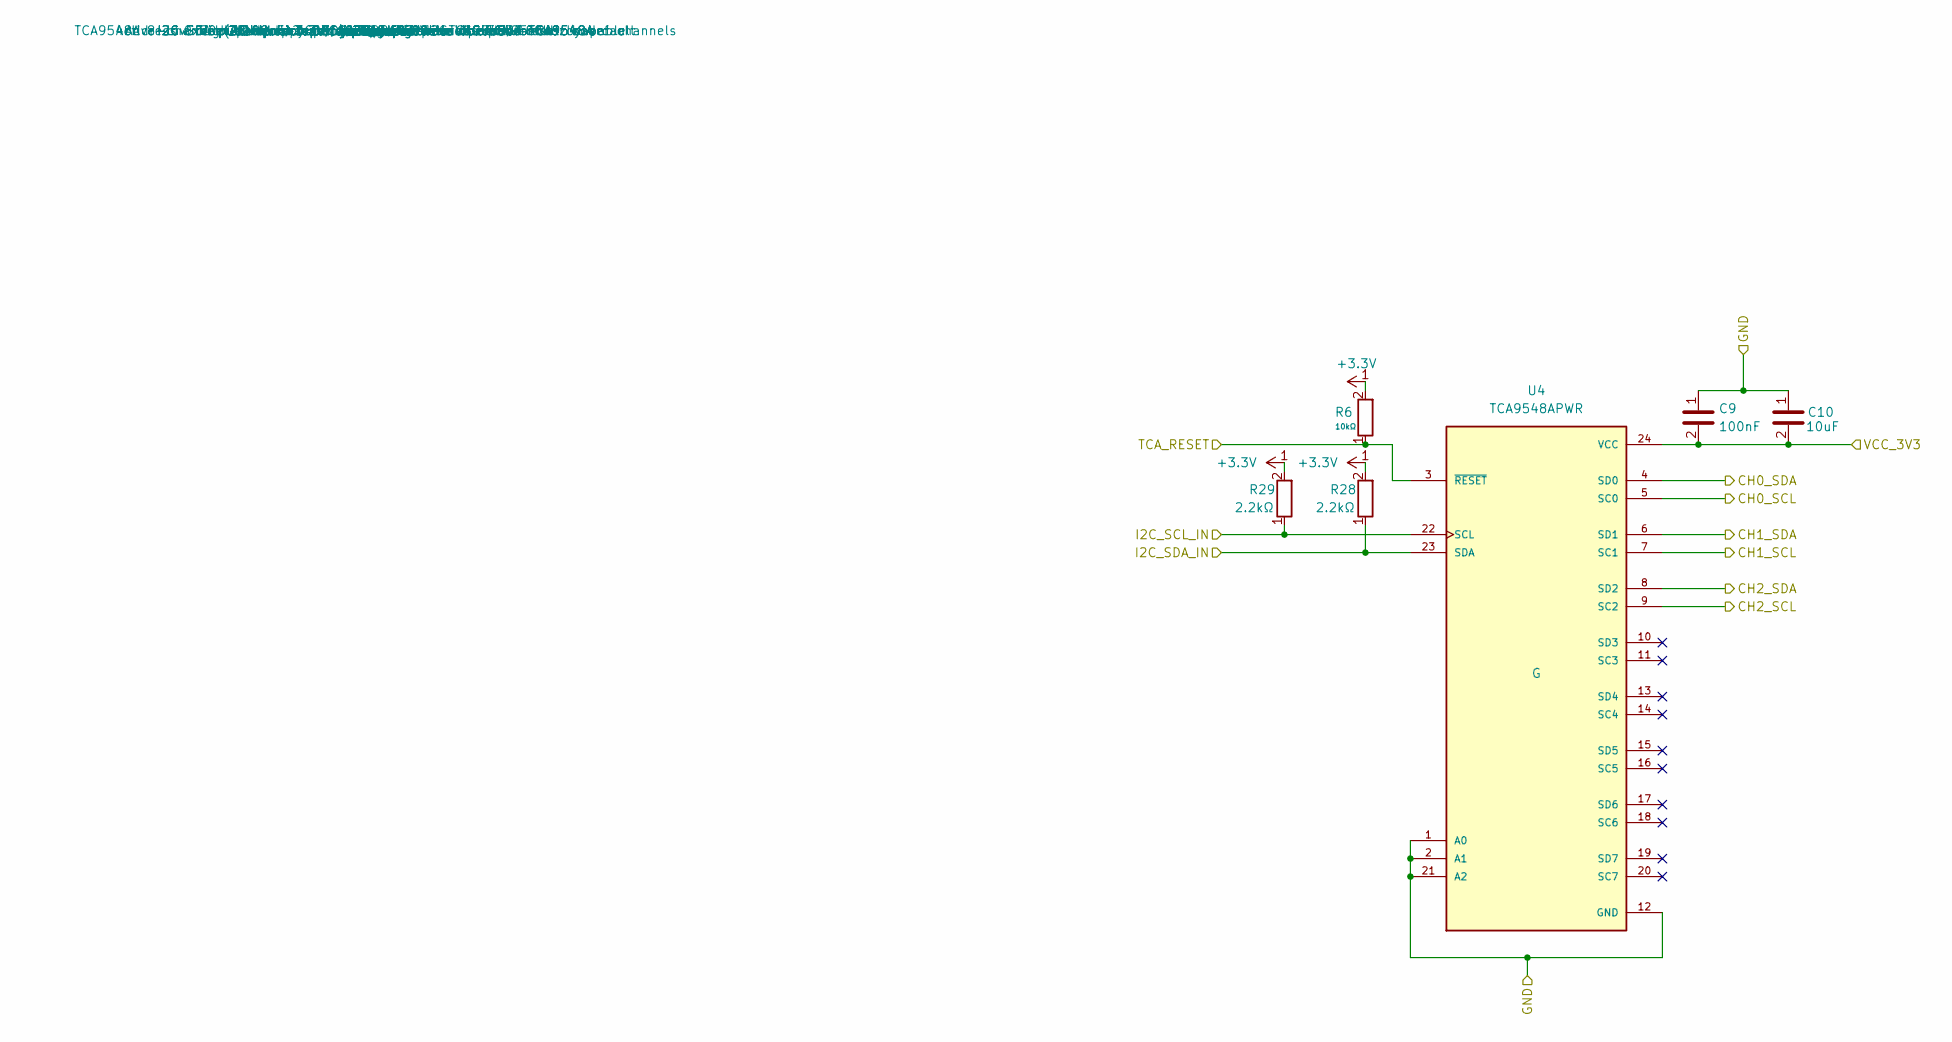
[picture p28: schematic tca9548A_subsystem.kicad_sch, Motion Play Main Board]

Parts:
C9: 100nF; C_0603_1608Metric; LCSC Part No C14663
C10: 10uF; C_0603_1608Metric; LCSC Part No C19702
R6: 10kΩ; R_0603_1608Metric; LCSC Part C25804
R28, R29: 2.2kΩ; R_0603_1608Metric; LCSC Part No C114662
U4: TCA9548APWR; SOP65P640X120-24N; PARTREV G; LCSC Part C130026

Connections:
+3.3V: C9.2, C10.2, R6.2, R28.2, R29.2, U4.24 (VCC); also elsewhere on the board
/I2C_SCL: R29.1, U4.22 (SCL); also elsewhere on the board
/I2C_SDA: R28.1, U4.23 (SDA); also elsewhere on the board
/TCA9548A_Subsystem/CH0_SCL: U4.5 (SC0); also elsewhere on the board
/TCA9548A_Subsystem/CH0_SDA: U4.4 (SD0); also elsewhere on the board
/TCA9548A_Subsystem/CH1_SCL: U4.7 (SC1); also elsewhere on the board
/TCA9548A_Subsystem/CH1_SDA: U4.6 (SD1); also elsewhere on the board
/TCA9548A_Subsystem/CH2_SCL: U4.9 (SC2); also elsewhere on the board
/TCA9548A_Subsystem/CH2_SDA: U4.8 (SD2); also elsewhere on the board
/TCA_RESET: R6.1, U4.3 (~RESET); also elsewhere on the board
GND: C9.1, C10.1, U4.1 (A0), U4.2 (A1), U4.12 (GND), U4.21 (A2); also elsewhere on the board

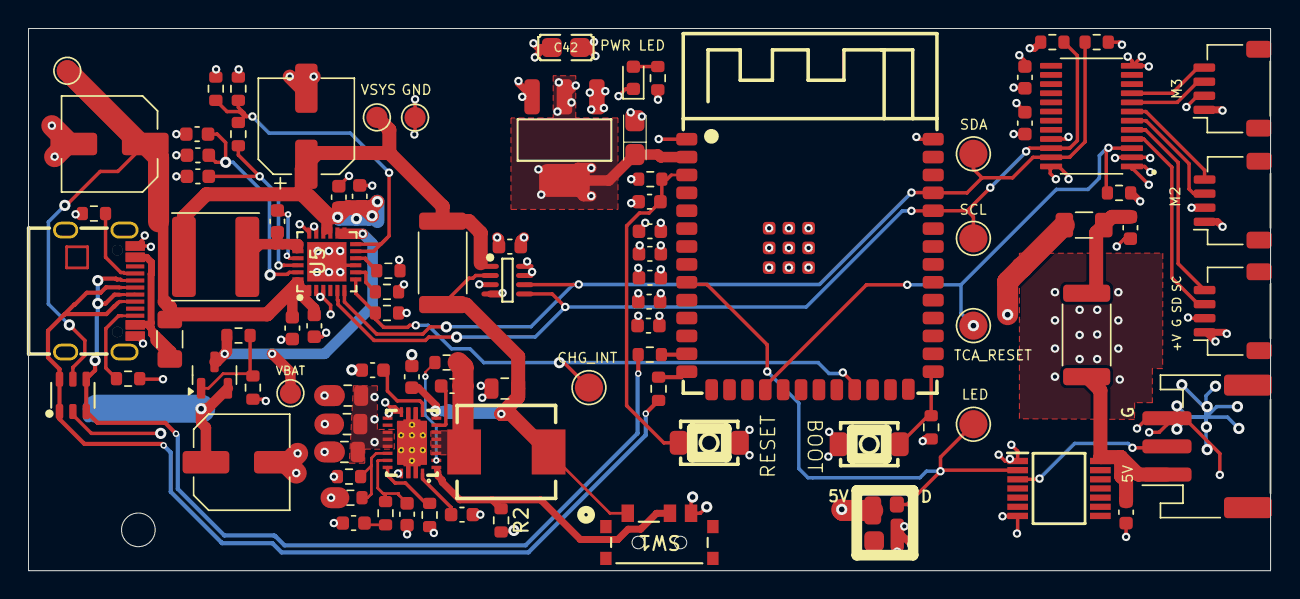
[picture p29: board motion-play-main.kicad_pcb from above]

Board: 4 copper layers, 88.2 x 38.5 mm, 93 parts (1 on the bottom side), 50 nets.

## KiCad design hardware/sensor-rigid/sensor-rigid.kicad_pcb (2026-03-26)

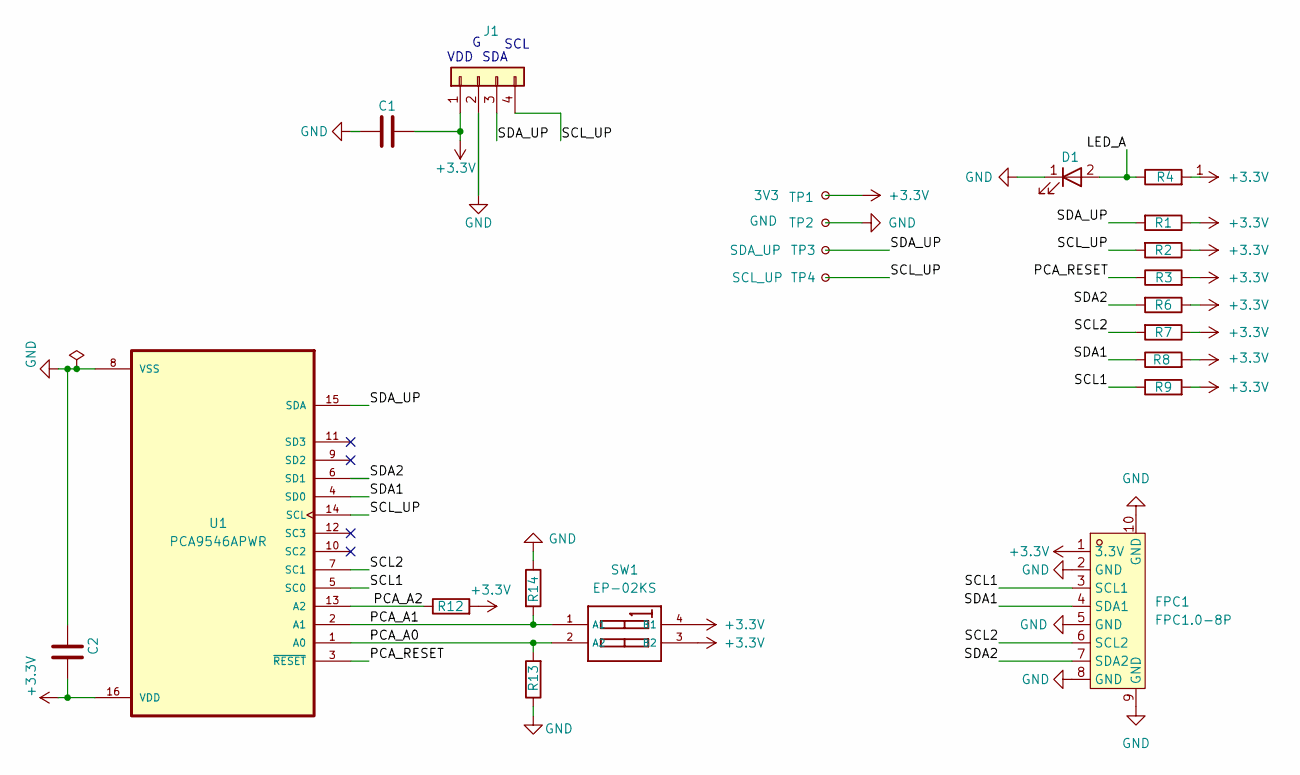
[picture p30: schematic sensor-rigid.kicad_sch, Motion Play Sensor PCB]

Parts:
C1: 2.2µF; C_0603_1608Metric; LCSC Part C23630
C2: 0.1µF; C_0603_1608Metric; LCSC Part C14663
D1: LED; LED_0603_1608Metric; LCSC Part C19171301
FPC1: FPC1.0-8P; FPC-SMD_8P-P1.00_FPC1.0-8P-SJ; LCSC Part C132510
J1: Conn_01x04; JST_SH_SM04B-SRSS-TB_1x04-1MP_P1.00mm_Horizontal; LCSC Part C160404
R1, R2, R6, R7, R8, R9: 4.7kΩ; R_0603_1608Metric; LCSC Part C99782
R3, R12, R13, R14: 10kΩ; R_0603_1608Metric; LCSC Part C25804
R4: 1kΩ; R_0603_1608Metric; LCSC Part C22548
SW1: EP-02KS; SW-SMD_EP-02KS; Voltage Rating 24V; Current Rating 25mA; Part EP-02KS; LCSC Part C129087
TP1: 3V3; TestPoint_Pad_D1.5mm
TP2: GND; TestPoint_Pad_D1.5mm
TP3: SDA_UP; TestPoint_Pad_D1.5mm
TP4: SCL_UP; TestPoint_Pad_D1.5mm
U1: PCA9546APWR; SOP65P640X120-16N; LCSC Part C400705

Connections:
+3.3V: C1.2, C2.2, FPC1.1 (3.3V), J1.1, R1.1, R2.1, R3.2, R4.2, R6.1, R7.1, R8.2, R9.2, R12.2, SW1.3 (B2), SW1.4 (B1), TP1.1, U1.16 (VDD)
/LED_A: D1.2 (A), R4.1
/PCA_A0: R13.2, SW1.2 (A2), U1.1 (A0)
/PCA_A1: R14.2, SW1.1 (A1), U1.2 (A1)
/PCA_A2: R12.1, U1.13 (A2)
/PCA_RESET: R3.1, U1.3 (~RESET)
/SCL1: FPC1.3 (SCL1), R9.1, U1.5 (SC0)
/SCL2: FPC1.6 (SCL2), R7.2, U1.7 (SC1)
/SCL_UP: J1.4, R2.2, TP4.1, U1.14 (SCL)
/SDA1: FPC1.4 (SDA1), R8.1, U1.4 (SD0)
/SDA2: FPC1.7 (SDA2), R6.2, U1.6 (SD1)
/SDA_UP: J1.3, R1.2, TP3.1, U1.15 (SDA)
GND: C1.1, C2.1, D1.1 (K), FPC1.2 (GND), FPC1.5 (GND), FPC1.8 (GND), FPC1.9 (GND), FPC1.10 (GND), J1.2, R13.1, R14.1, TP2.1, U1.8 (VSS)

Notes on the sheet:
SDA
SCL
VDD

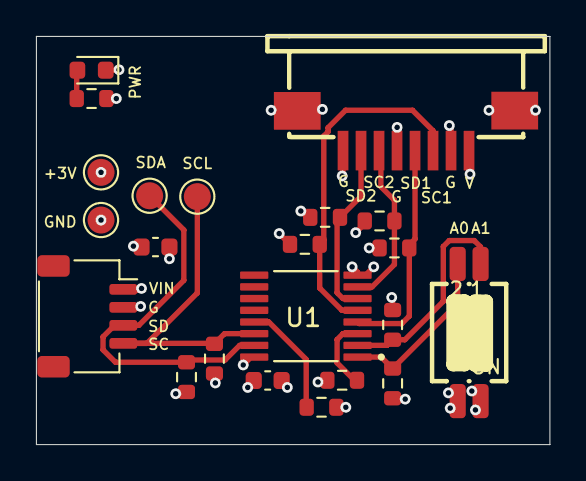
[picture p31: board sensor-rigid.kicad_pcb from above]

Board: 4 copper layers, 28.5 x 22.7 mm, 22 parts (0 on the bottom side), 13 nets.

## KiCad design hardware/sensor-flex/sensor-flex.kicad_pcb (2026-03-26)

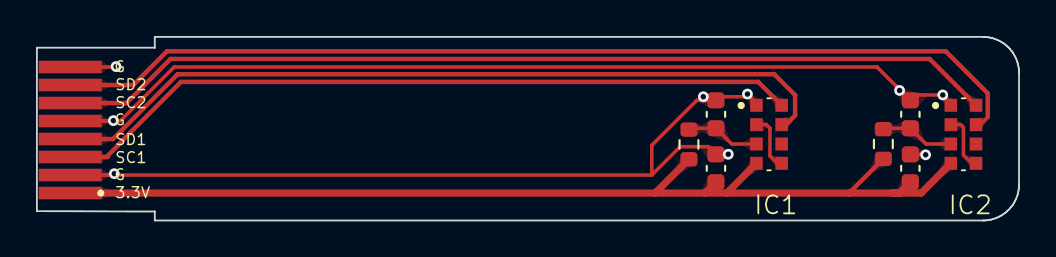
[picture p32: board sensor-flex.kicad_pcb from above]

Board: 2 copper layers, 54.6 x 10.2 mm, 9 parts (0 on the bottom side), 10 nets.

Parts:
C4, C8: 2.2µF; C_0603_1608Metric
C6, C7: 0.1µF; C_0603_1608Metric
FPC1: FPC_Tail_10P; FPC_Tail_10P_1.0mm_TopContact
IC1, IC2: VCNL4040M3OE
R10, R11: 22Ω; R_0603_1608Metric

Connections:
+3.3V: C4.2, C8.2, FPC1.1 (3.3V), IC1.4 (A), IC2.4 (A), R10.2, R11.1
/LED_K1: IC1.2 (K(SENSOR)), IC1.5 (K(LED))
/LED_K2: IC2.2 (K(SENSOR)), IC2.5 (K(LED))
/SCL1: FPC1.3 (SCL1), IC1.8 (SCLK)
/SCL2: FPC1.6 (SCL2), IC2.8 (SCLK)
/SDA1: FPC1.4 (SCL2), IC1.7 (SDAT)
/SDA2: FPC1.7 (SDA2), IC2.7 (SDAT)
/VDD_S1: C7.1, IC1.3 (VDD), R11.2
/VDD_S2: C6.1, IC2.3 (VDD), R10.1
GND: C4.1, C6.2, C7.2, C8.1, FPC1.2 (GND), FPC1.5 (GND), FPC1.8 (GND), IC1.1 (GND), IC2.1 (GND)

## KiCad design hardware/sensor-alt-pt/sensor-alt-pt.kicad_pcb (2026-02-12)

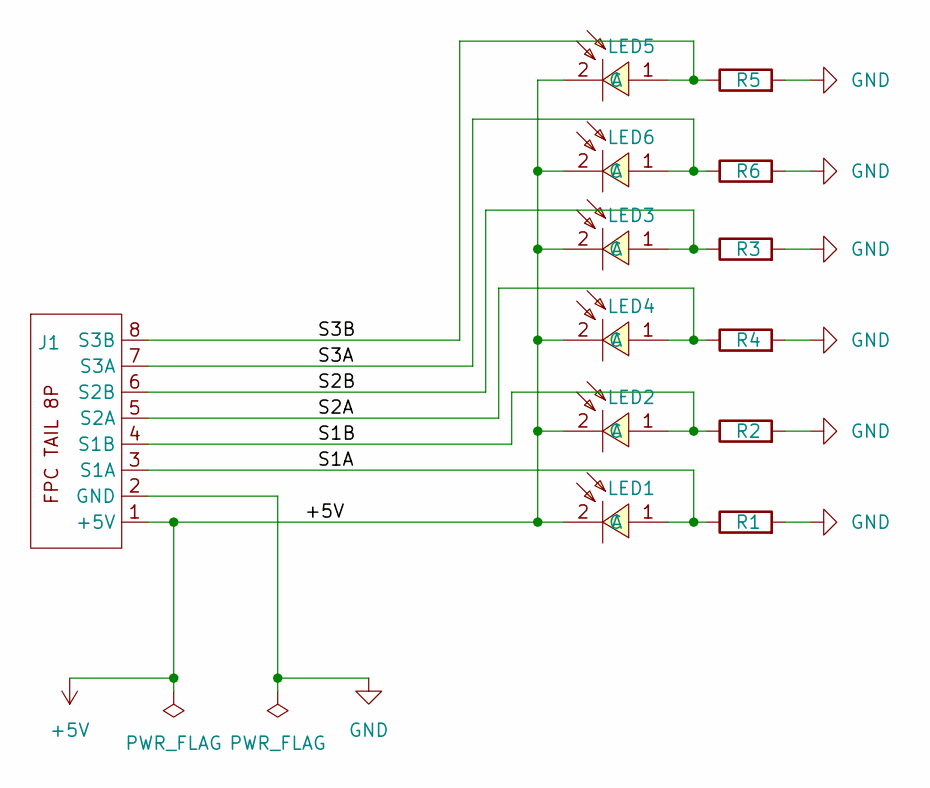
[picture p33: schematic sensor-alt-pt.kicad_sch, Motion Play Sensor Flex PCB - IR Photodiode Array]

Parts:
J1: FPC_Tail_8P_1.0mm_TopContact
LED1, LED2, LED3, LED4, LED5, LED6: VEMD2020X01; LED-SMD_L2.3-W2.3_VEMD2020X01; LCSC Part C3210968
R1, R2, R3, R4, R5, R6: 10kΩ; R_0603_1608Metric; LCSC Part C98220

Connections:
+5V: J1.1 (+5V), LED1.2 (C), LED2.2 (C), LED3.2 (C), LED4.2 (C), LED5.2 (C), LED6.2 (C)
/S1A: J1.3 (S1A), LED1.1 (A), R1.1
/S1B: J1.4 (S1B), LED2.1 (A), R2.1
/S2A: J1.5 (S2A), LED4.1 (A), R4.1
/S2B: J1.6 (S2B), LED3.1 (A), R3.1
/S3A: J1.7 (S3A), LED6.1 (A), R6.1
/S3B: J1.8 (S3B), LED5.1 (A), R5.1
GND: J1.2 (GND), R1.2, R2.2, R3.2, R4.2, R5.2, R6.2

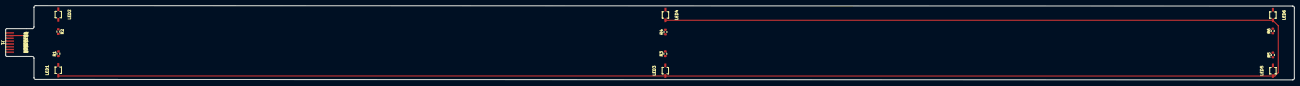
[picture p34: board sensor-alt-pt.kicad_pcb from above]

Board: 2 copper layers, 462.7 x 26.7 mm, 13 parts (0 on the bottom side), 8 nets.

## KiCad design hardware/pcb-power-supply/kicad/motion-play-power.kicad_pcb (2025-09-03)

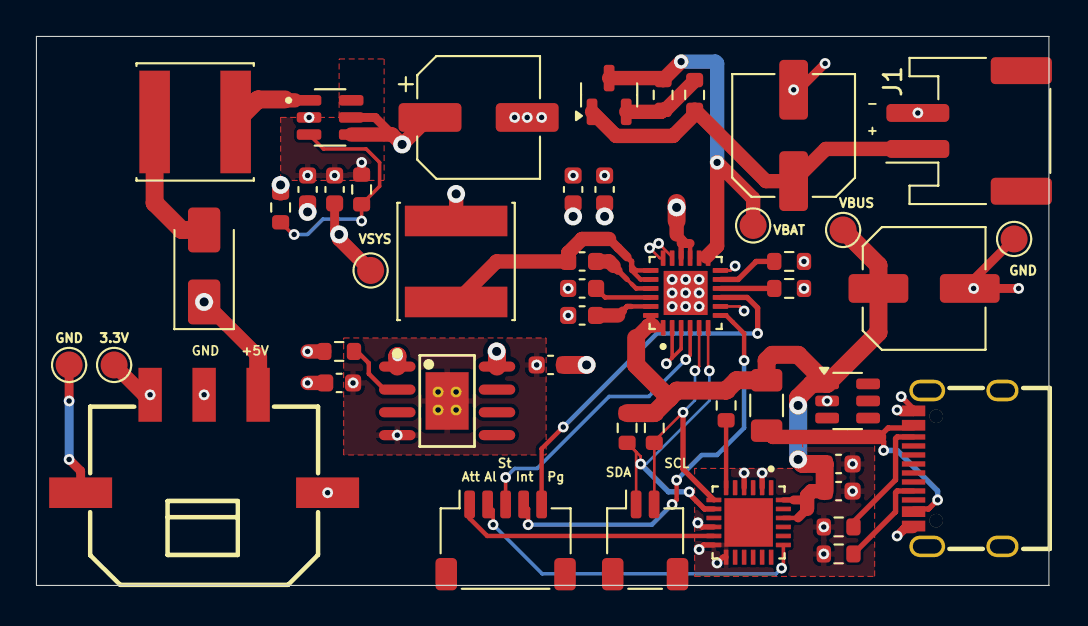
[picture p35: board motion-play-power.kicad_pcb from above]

Board: 4 copper layers, 56.2 x 30.5 mm, 47 parts (0 on the bottom side), 29 nets.

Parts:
3.3V: +3.3V TP; TestPoint_Pad_D1.5mm
C1: 0.1µF; C_0603_1608Metric
C2: 4.7µF; C_0603_1608Metric
C3: 100nF; C_0603_1608Metric
C4, C6, C7: 10uF; C_0603_1608Metric
C5: 4.7uF; C_0603_1608Metric
C8: 220µF; CP_Elec_6.3x7.7
C9, C10: 22µF; C_0603_1608Metric
C11, C12: 2.2uF; C_0603_1608Metric
C13, C14: C_Polarized_Small_US; C_Elec_6.3x5.4
CN1: X3025WRS-03D-LPSW; CONN-SMD_3P-H-P3.00-R_X3025WRS-03D-LPSW
D1: 40V Independent Type 550mV@5A 5A SMA(DO-214AC) Sc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; D_SMA
F1: Fuse; Fuse_1206_3216Metric
GND: GND TP; TestPoint_Pad_D1.5mm
GND#2: GND PD TP; TestPoint_Pad_D1.5mm
J1: Conn_01x02; JST_PH_S2B-PH-SM4-TB_1x02-1MP_P2.00mm_Horizontal
J3: Conn_01x02; JST_SH_SM02B-SRSS-TB_1x02-1MP_P1.00mm_Horizontal
J4: Conn_01x05; JST_SH_SM05B-SRSS-TB_1x05-1MP_P1.00mm_Horizontal
L1: 2.2uH; L_Changjiang_FNR6028S
L2: 4.7uH; L_Changjiang_FNR6028S
Q1: PMOS; SOT-23
R1, R2: 5.1kΩ; R_0603_1608Metric
R3, R4, R5, R9, R11: 10kΩ; R_0603_1608Metric
R6: 2.7k; R_0603_1608Metric
R7, R8: 100k; R_0603_1608Metric
R10: 47kΩ; R_0603_1608Metric
TH1: Thermistor_NTC; R_0603_1608Metric
TP3: VBUS TP; TestPoint_Pad_D1.5mm
U1: STUSB4500LQTR; QFN50P400X400X100-25N
U2: USBLC6-2SC6; SOT-23-6
U3: BQ24195RGET; QFN50P400X400X100-25N
U4: MT3608; SOT95P280X145-6N
U5: LR1801G-33-SH2-R; HSOP-8_L5.0-W4.0-P1.27-LS6.2-BL-EP
USBC1: TYPE-C-31-M-12; USB-C_SMD-TYPE-C-31-M-12
VBAT: VBAT TP; TestPoint_Pad_D1.5mm
VSYS: VSYS TP; TestPoint_Pad_D1.5mm

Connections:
+3.3V: 3.3V.1, C12.1, CN1.3, R11.2, U5.1 (VOUT)
+5V: C10.1, CN1.1, D1.1 (K), R10.2
/Battery Management/CHRG_INT: J4.4, U3.7 (INT)
/Battery Management/CHRG_PG: J4.5, U3.9 (CE)
/Battery Management/CHRG_STAT: J4.3, U3.4 (STAT)
/Battery Management/VSYS: C6.2, C7.2, C8.1, C9.1, C11.1, L1.2, U3.15 (SYS1), U3.16 (SYS2), U4.4 (EN), U4.5 (IN), U5.8 (VIN), VSYS.1
/Connectors/USB_ALERT: J4.2, U1.19 (ALERT)
/Connectors/USB_ATTACH: J4.1, U1.11 (ATTACH)
GND: C1.2, C2.2, C4.2, C5.2, C6.1, C7.1, C8.2, C9.2, C10.2, C11.2, C12.2, C13.2, C14.2, CN1.2, CN1.4, CN1.5, GND.1, GND#2.1, J1.2, R1.2, R2.2, R6.1, R9.1, TH1.1, U1.2 (CC1), U1.4 (CC2), U1.10 (GND), U1.12 (ADDR0), U1.13 (ADDR1), U1.25 (EXP), U2.2 (GND), U3.2 (D+), U3.3 (D-), U3.8 (OTG), U3.12 (TS2), U3.17 (PGND1), U3.18 (PGND2), U3.25 (GND), U4.2 (GND), U5.4 (GND), U5.9 (EP), USBC1.0 (SH), USBC1.A1 (GND), USBC1.A12 (GND), USBC1.B1 (GND), USBC1.B12 (GND)
I2C_SCL: J3.2, R4.1, U1.7 (SCL), U3.5 (SCL)
I2C_SDA: J3.1, R3.1, U1.8 (SDA), U3.6 (SDA)
unnamed: D1.2 (A), L2.2
unnamed: F1.1, USBC1.A4 (VBUS), USBC1.A9 (VBUS), USBC1.B4 (VBUS), USBC1.B9 (VBUS)
unnamed: C13.1, J1.1, Q1.1 (D), R8.2
unnamed: Q1.2 (G), R7.2, R8.1
unnamed: R5.1, U1.6 (RESET)
unnamed: C3.1, U3.21 (BTST)
unnamed: R6.2, U3.10 (ILIM)
unnamed: C4.1, U3.23 (PMID)
unnamed: C5.1, U3.22 (REGN)
unnamed: C3.2, L1.1, U3.19 (SW1), U3.20 (SW2)
unnamed: TH1.2, U3.11 (TS1)
unnamed: R9.2, R10.1, U4.3 (FB)
unnamed: L2.1, U4.1 (SW)
unnamed: R11.1, U5.2 (ON/~OFF)
unnamed: R1.1, USBC1.A5 (CC1)
unnamed: R2.1, USBC1.B5 (CC2)
Protected_VBUS: C1.1, C2.1, C14.1, F1.2, R3.2, R4.2, R5.2, TP3.1, U1.22 (VSYS), U1.24 (VDD), U2.1 (I/O1), U3.1 (VBUS1), U3.24 (VBUS2)
VBAT: Q1.3 (S), R7.1, U3.13 (BAT1), U3.14 (BAT2), VBAT.1

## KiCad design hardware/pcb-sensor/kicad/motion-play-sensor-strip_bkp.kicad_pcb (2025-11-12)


Board: 4 copper layers, 32.5 x 20.2 mm, 29 parts (0 on the bottom side), 17 nets.

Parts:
C1, C3, C4: 2.2µF; C_0603_1608Metric
C2, C5, C6: 0.1µF; C_0603_1608Metric
D1: LED; LED_0603_1608Metric
D2, D3: BAT54S; SOT-23
J1: Conn_01x05; JST_SH_SM05B-SRSS-TB_1x05-1MP_P1.00mm_Horizontal
JP3, JP4: SolderJumper_2_Open; SolderJumper-2_P1.3mm_Open_RoundedPad1.0x1.5mm
R1, R2, R6, R7, R8, R9: 4.7kΩ; R_0603_1608Metric
R3, R5: 10kΩ; R_0603_1608Metric
R4: 1kΩ; R_0603_1608Metric
TP1, TP2, TP3, TP4, TP5: TestPoint_Small; TestPoint_Pad_D1.5mm
U1: PCA9546APWR; SOP65P640X120-16N
U2, U3: VCNL4040M3OE-H3; VISHAY_VCNL4040

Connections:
+3.3V: C1.2, C2.2, C5.1, C6.1, J1.1, R1.1, R2.1, R3.2, R4.2, R5.1, R6.1, R7.1, R8.2, R9.2, TP1.1, U1.16 (VDD), U2.3, U3.3
GND: C1.1, C2.1, C3.1, C4.1, C5.2, C6.2, D1.1 (K), J1.2, JP3.2 (B), JP4.2 (B), TP2.1, U1.8 (VSS), U1.13 (A2), U2.1, U2.2, U2.8, U3.1, U3.2, U3.8
unnamed: C3.2, U2.4
unnamed: C4.2, U3.4
unnamed: D1.2 (A), R4.1
unnamed: D2.1 (A), D3.1 (A), J1.5, R5.2, TP5.1
unnamed: D2.3 (COM), U2.7
unnamed: D3.3 (COM), U3.7
unnamed: J1.3, R1.2, TP3.1, U1.15 (SDA)
unnamed: J1.4, R2.2, TP4.1, U1.14 (SCL)
unnamed: JP3.1 (A), U1.2 (A1)
unnamed: JP4.1 (A), U1.1 (A0)
unnamed: R9.1, U1.5 (SC0), U2.5
unnamed: R7.2, U1.7 (SC1), U3.5
unnamed: R8.1, U1.4 (SD0), U2.6
unnamed: R6.2, U1.6 (SD1), U3.6
unnamed: R3.1, U1.3 (~RESET)

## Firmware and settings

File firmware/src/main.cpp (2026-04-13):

#include <Arduino.h>
#include <Wire.h>
#include <Adafruit_VCNL4040.h>
#include <HTTPClient.h>
#include <ArduinoJson.h>
#include "components/network/NetworkManager.h"
#include "components/mqtt/MQTTManager.h"
#include "components/display/DisplayManager.h"
#include "components/sensor/SensorManager.h"
#include "components/sensor/SensorConfiguration.h"
#include "components/session/SessionManager.h"
#include "components/data/DataTransmitter.h"
#include "components/diagnostics/MemoryMonitor.h"
#include "components/detection/DirectionDetector.h"
#include "components/detection/MLDetector.h"
#include "components/led/LEDController.h"
#include "components/power/PowerMonitor.h"
#include "components/interrupt/InterruptManager.h"
#include "components/calibration/CalibrationManager.h"
#include "components/serialstudio/SerialStudioOutput.h"

// Button pins for T-Display-S3
#define BUTTON_1 0  // Left button (BOOT)
#define BUTTON_2 14 // Right button

// Device modes (what the device is doing)
// Note: HOW we sense (polling vs interrupt) is determined by currentConfig.sensor_mode
enum class DeviceMode
{
    IDLE,      // Standby mode
    DEBUG,     // Data collection for algorithm development
    PLAY,      // Active game mode with direction detection
    LIVE_DEBUG // Live detection with event capture (hybrid of Play + Debug)
};

// Managers
NetworkManager networkManager;
MQTTManager *mqttManager;
DisplayManager display;
SensorManager sensorManager;
SessionManager sessionManager;
DataTransmitter *dataTransmitter;
DirectionDetector directionDetector;
MLDetector mlDetector;
LEDController ledController;
PowerMonitor powerMonitor;
SerialStudioOutput serialStudioOutput;

// Detection mode: false = heuristic (DirectionDetector), true = ML (MLDetector)
bool useMLDetection = false;

// Detection algorithm config (runtime-configurable via cloud config)
DetectorConfig detectorConfig;

// Serial Studio output: compile-time default from build flags, overridable via cloud config
bool serialStudioEnabled = SERIAL_STUDIO_DEFAULT;
InterruptManager interruptManager;

// Current device mode
DeviceMode currentMode = DeviceMode::DEBUG; // Default to debug for backwards compatibility

// Play mode state
bool playModeActive = false;
unsigned long lastDetectionTime = 0;
const unsigned long DETECTION_COOLDOWN = 500; // 500ms - prevents double-trigger, allows quick successive throws

// Live Debug mode state
bool liveDebugActive = false;

// Live Debug capture window constants
const size_t LIVE_DEBUG_BUFFER_CAP = 18000;        // ~3 seconds buffer cap
const unsigned long DETECTION_WINDOW_MS = 500;     // 0.5s of pre-detection data to capture
const unsigned long POST_DETECTION_DELAY_MS = 250; // 0.25s of post-detection data (sensor task keeps collecting)
const unsigned long MISSED_EVENT_WINDOW_MS = 3000; // 3s of pre-button data to capture

// Timing
unsigned long lastStatusUpdate = 0;
const unsigned long STATUS_UPDATE_INTERVAL = 30000; // 30 seconds

bool systemInitialized = false;

// Global sensor configuration instance
SensorConfiguration currentConfig;

// Forward declarations
void initializeSystem();
void handleCommand(const String &command, JsonDocument *doc = nullptr);
bool fetchConfigFromCloud();
void configureBQ24195();

// BQ24195 battery charger / power-path manager (main PCB v6+)
// On v6 the D+/D- pins are tied to GND, so the BQ falls back to its default
// register IINLIM (~500 mA) and clamps VSYS as soon as the ESP32 + display
// pull more than that. Symptom: VSYS thrashes 4.2 V -> 2.6 V, +5 V/+3.3 V
// brown out, T-Display resets in a loop. Fix: lift IINLIM via I2C and
// disable the 40 s I2C watchdog so the setting sticks. Must run *before*
// display.init() because the display draws enough to trigger the brownout.
#define BQ24195_I2C_ADDR    0x6B
#define BQ24195_REG00       0x00 // Input Source Control
#define BQ24195_REG05       0x05 // Charge Term / Timer Control
// REG00: EN_HIZ=0, VINDPM=0110 (4.36 V default), IINLIM=110 (2 A) -> 0x36
#define BQ24195_REG00_VAL   0x36
// REG05: EN_TERM=1, WATCHDOG=00 (disabled), EN_TIMER=1, CHG_TIMER=01 (8 h) -> 0x8A
#define BQ24195_REG05_VAL   0x8A

void setup()
{
    Serial.begin(115200);
    delay(500);

    Serial.println("\n\n=================================");
    Serial.println("Motion Play Device - BOOT");
    Serial.println("=================================");
    Serial.println("Press RIGHT button (GPIO 14) to restart anytime");
    Serial.println("=================================\n");

    pinMode(BUTTON_1, INPUT_PULLUP);
    pinMode(BUTTON_2, INPUT_PULLUP);

    // Reconfigure the BQ24195 input current limit BEFORE anything that draws
    // significant current (display init, WiFi). Without this the v6 board
    // browns out under load. See note above the #defines for full context.
    configureBQ24195();

    display.init();
    display.showInitScreen();
    Serial.println("Display initialized");

    initializeSystem();

    Serial.println("\n=== Setup Complete - Entering Loop ===\n");
}

void configureBQ24195()
{
    Serial.println("=== Configuring BQ24195 (input current limit) ===");

    // Bring the I2C bus up early. SensorManager will call Wire.begin() again
    // later with the same pins, which is harmless.
    Wire.begin(43, 44); // SDA=43, SCL=44 on T-Display-S3

    // Probe for the chip first so we don't spam errors on boards that don't
    // have it (e.g., bench testing on a bare T-Display).
    Wire.beginTransmission(BQ24195_I2C_ADDR);
    if (Wire.endTransmission() != 0)
    {
        Serial.println("BQ24195 not found at 0x6B - skipping (bare T-Display?)");
        return;
    }

    // REG00: raise IINLIM to 2 A and clear EN_HIZ.
    Wire.beginTransmission(BQ24195_I2C_ADDR);
    Wire.write(BQ24195_REG00);
    Wire.write(BQ24195_REG00_VAL);
    uint8_t r0 = Wire.endTransmission();

    // REG05: disable the 40 s I2C watchdog so REG00 stays put.
    Wire.beginTransmission(BQ24195_I2C_ADDR);
    Wire.write(BQ24195_REG05);
    Wire.write(BQ24195_REG05_VAL);
    uint8_t r5 = Wire.endTransmission();

    if (r0 == 0 && r5 == 0)
    {
        Serial.println("BQ24195 configured: IINLIM=2A, watchdog disabled");
    }
    else
    {
        Serial.printf("BQ24195 write error (REG00=%u, REG05=%u)\n", r0, r5);
    }
}

bool fetchConfigFromCloud()
{
    Serial.println("\n=== Fetching Config from Cloud ===");

    // Get device ID and API endpoint from NetworkManager
    String deviceId = networkManager.getDeviceId();
    String apiEndpoint = networkManager.getApiEndpoint();

    if (apiEndpoint.isEmpty())
    {
        Serial.println("WARNING: No API endpoint configured, using defaults");
        return false;
    }

    // Construct URL
    String url = apiEndpoint + "/device/" + deviceId + "/config";
    Serial.printf("Fetching config from: %s\n", url.c_str());

    HTTPClient http;
    http.begin(url);
    http.setTimeout(5000);

    int httpCode = http.GET();

    if (httpCode == HTTP_CODE_OK)
    {
        String payload = http.getString();
        Serial.println("Config received:");
        Serial.println(payload);

        // Parse JSON response
        DynamicJsonDocument doc(2048);
        DeserializationError error = deserializeJson(doc, payload);

        if (error)
        {
            Serial.print("JSON parse error: ");
            Serial.println(error.c_str());
            http.end();
            return false;
        }

        // Extract sensor_config
        if (doc.containsKey("sensor_config"))
        {
            JsonObject config = doc["sensor_config"];

            // Update current configuration
            // Handle both sample_rate and sample_rate_hz for compatibility
            if (config.containsKey("sample_rate_hz"))
            {
                currentConfig.sample_rate_hz = config["sample_rate_hz"];
            }
            else if (config.containsKey("sample_rate"))
            {
                currentConfig.sample_rate_hz = config["sample_rate"];
            }

            currentConfig.led_current = config["led_current"] | "200mA";
            currentConfig.integration_time = config["integration_time"] | "1T";
            currentConfig.high_resolution = config["high_resolution"] | true;
            currentConfig.read_ambient = config["read_ambient"] | true;

            // New field: I2C clock speed
            if (config.containsKey("i2c_clock_khz"))
            {
                currentConfig.i2c_clock_khz = config["i2c_clock_khz"];
            }

            // New field: Multi-pulse mode
            if (config.containsKey("multi_pulse"))
            {
                currentConfig.multi_pulse = config["multi_pulse"].as<String>();
            }
            else
            {
                currentConfig.multi_pulse = "1"; // Default: 1 pulse
            }

            // Physical geometry for transit speed estimation
            if (config.containsKey("ball_diameter_mm"))
                currentConfig.ball_diameter_mm = config["ball_diameter_mm"];
            if (config.containsKey("hoop_inner_diameter_mm"))
                currentConfig.hoop_inner_diameter_mm = config["hoop_inner_diameter_mm"];

            // Sensor mode (polling vs interrupt)
            if (config.containsKey("sensor_mode"))
            {
                String modeStr = config["sensor_mode"].as<String>();
                currentConfig.sensor_mode = (modeStr == "interrupt")
                                                ? SensorMode::INTERRUPT_MODE
                                                : SensorMode::POLLING_MODE;
            }

            // Interrupt settings (calibration-based approach)
            if (config.containsKey("interrupt_threshold_margin"))
            {
                currentConfig.interrupt_threshold_margin = config["interrupt_threshold_margin"];
            }
            if (config.containsKey("interrupt_hysteresis"))
            {
                currentConfig.interrupt_hysteresis = config["interrupt_hysteresis"];
            }
            if (config.containsKey("interrupt_integration_time"))
            {
                currentConfig.interrupt_integration_time = config["interrupt_integration_time"];
            }
            if (config.containsKey("interrupt_multi_pulse"))
            {
                currentConfig.interrupt_multi_pulse = config["interrupt_multi_pulse"];
            }
            if (config.containsKey("interrupt_persistence"))
            {
                currentConfig.interrupt_persistence = config["interrupt_persistence"];
            }
            if (config.containsKey("interrupt_smart_persistence"))
            {
                currentConfig.interrupt_smart_persistence = config["interrupt_smart_persistence"];
            }
            if (config.containsKey("interrupt_mode"))
            {
                currentConfig.interrupt_mode = config["interrupt_mode"].as<String>();
            }

            Serial.println("\nConfig loaded from cloud:");
            Serial.printf("  Sensor Mode: %s\n", currentConfig.sensor_mode == SensorMode::INTERRUPT_MODE ? "INTERRUPT" : "POLLING");
            Serial.printf("  Sample Rate: %d Hz\n", currentConfig.sample_rate_hz);
            Serial.printf("  LED Current: %s\n", currentConfig.led_current.c_str());
            Serial.printf("  Integration Time: %s\n", currentConfig.integration_time.c_str());
            Serial.printf("  Multi-Pulse: %s pulses\n", currentConfig.multi_pulse.c_str());
            Serial.printf("  High Resolution: %s\n", currentConfig.high_resolution ? "enabled" : "disabled");
            Serial.printf("  Read Ambient: %s\n", currentConfig.read_ambient ? "enabled" : "disabled");
            Serial.printf("  I2C Clock: %d kHz\n", currentConfig.i2c_clock_khz);
            if (currentConfig.sensor_mode == SensorMode::INTERRUPT_MODE)
            {
                Serial.printf("  INT Threshold Margin: %d\n", currentConfig.interrupt_threshold_margin);
                Serial.printf("  INT Hysteresis: %d\n", currentConfig.interrupt_hysteresis);
                Serial.printf("  INT Integration Time: %dT\n", currentConfig.interrupt_integration_time);
                Serial.printf("  INT Multi-Pulse: %d\n", currentConfig.interrupt_multi_pulse);
            }

            // Check for detection_mode in sensor config
            if (config.containsKey("detection_mode"))
            {
                String detMode = config["detection_mode"].as<String>();
                useMLDetection = (detMode == "ml");
                Serial.printf("  Detection Mode: %s (raw value: '%s')\n", useMLDetection ? "ML" : "heuristic", detMode.c_str());
            }
            else
            {
                Serial.println("  Detection Mode: not present in cloud config (defaulting to heuristic)");
            }

            if (config.containsKey("serial_studio_enabled"))
            {
                serialStudioEnabled = config["serial_studio_enabled"].as<bool>();
                serialStudioOutput.setEnabled(serialStudioEnabled);
                Serial.printf("  Serial Studio: %s\n", serialStudioEnabled ? "enabled" : "disabled");
            }
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
void loop()
{
    static int buttonState2 = HIGH;
    static unsigned long lastSampleUpdate = 0;
    static unsigned long button1HoldStart = 0;
    static bool button1WasPressed = false;

    int currentButton1 = digitalRead(BUTTON_1);
    int currentButton2 = digitalRead(BUTTON_2);

    // If calibration is active, handle it exclusively
    if (calibrationManager.isActive())
    {
        calibrationManager.update();

        // After calibration completes, restore normal display
        if (!calibrationManager.isActive())
        {
            display.showSessionScreen();
            display.setSensorConfig(&currentConfig);

            // Set sensor config in calibration manager for next time
            uint8_t mp = currentConfig.multi_pulse.toInt();
            if (mp == 0)
                mp = 1;
            uint8_t it = currentConfig.integration_time.substring(0, 1).toInt();
            if (it == 0)
                it = 1;
            uint8_t led = currentConfig.led_current.toInt();
            if (led == 0)
                led = 200;
            calibrationManager.setSensorConfig(mp, it, led);
        }

        delay(10);
        return; // Skip normal loop during calibration
    }

    // Check for LEFT button (BOOT) long-press to start calibration
    if (currentButton1 == LOW)
    {
        if (!button1WasPressed)
        {
            button1WasPressed = true;
            button1HoldStart = millis();
        }
        else if (millis() - button1HoldStart >= 3000)
        {
            // 3 second hold - trigger calibration
            Serial.println("Button 1 held 3s - Starting calibration...");

            // Only start if not collecting
            if (sessionManager.getState() == IDLE)
            {
                // Set sensor config before starting
                uint8_t mp = currentConfig.multi_pulse.toInt();
                if (mp == 0)
                    mp = 1;
                uint8_t it = currentConfig.integration_time.substring(0, 1).toInt();
                if (it == 0)
                    it = 1;
                uint8_t led = currentConfig.led_current.toInt();
                if (led == 0)
                    led = 200;
                calibrationManager.setSensorConfig(mp, it, led);

                calibrationManager.startCalibration();
            }
            else
            {
                display.showMessage("Stop collection first!", TFT_RED);
                delay(1500);
                display.setDisplayState(DISPLAY_IDLE);
            }

            button1WasPressed = false; // Reset to prevent re-trigger
            button1HoldStart = 0;
        }
    }
    else
    {
        button1WasPressed = false;
        button1HoldStart = 0;
    }

    // Check for RIGHT button press to restart anytime
    if (currentButton2 == LOW && buttonState2 == HIGH)
    {
        Serial.println("RIGHT BUTTON - Restarting...");
        display.showMessage("Restarting...", TFT_YELLOW);
        delay(500);
        ESP.restart();
    }
    buttonState2 = currentButton2;

    // Check network connection
    networkManager.checkConnection();

    // Handle MQTT
    mqttManager->loop();

    // Process sensor data queue if collecting
    if (sessionManager.getState() == COLLECTING)
    {
        // Check session type to determine processing method
        bool isInterruptSession = (sessionManager.getSessionType() == SessionType::INTERRUPT_BASED);

        if (isInterruptSession)
        {
            // INTERRUPT MODE: Drain events from InterruptManager
            while (interruptManager.hasEvents())
            {
                InterruptEvent evt;
                if (interruptManager.getNextEvent(evt))
                {
                    sessionManager.addInterruptEvent(evt);
                }
            }

            // Update display periodically
            static unsigned long lastIntUpdate = 0;
            if (millis() - lastIntUpdate > 500)
            {
                lastIntUpdate = millis();
                size_t eventCount = sessionManager.getInterruptEventCount();

                // Log event count
                Serial.printf("[INT] Events: %d\n", eventCount);
            }

            // Check for maximum session duration (30 seconds for interrupt too)
            if (sessionManager.getDuration() >= 30000)
            {
                Serial.println("WARNING: Maximum interrupt session duration reached (30s), auto-stopping...");
                display.showMessage("Max duration!", TFT_ORANGE);
                delay(1000);

                // Auto-stop
                interruptManager.stopMonitoring();
                sessionManager.stopSession();
                display.setDisplayState(DISPLAY_UPLOADING);

                if (dataTransmitter->transmitSession(sessionManager, &currentConfig))
                {
                    mqttManager->publishStatus("upload_complete_auto_stopped");
                    display.setDisplayState(DISPLAY_SUCCESS);
                    delay(2000);
                    sessionManager.clearBuffer();
                    display.setDisplayState(DISPLAY_IDLE);
                }
                else
                {
                    mqttManager->publishStatus("upload_failed");
                    display.setDisplayState(DISPLAY_ERROR);
                    delay(2000);
                    sessionManager.clearBuffer();
                    display.setDisplayState(DISPLAY_IDLE);
                }
            }
        }
        else
        {
            // POLLING MODE: Regular proximity processing
            sessionManager.processQueue();

            // Serial Studio: emit CSV frames for new readings
            serialStudioOutput.update();
        }

        // PLAY MODE: Run direction detection on collected data
        if (playModeActive && currentMode == DeviceMode::PLAY)
        {
            // Update LED animation (handles fade-out after detection)
            bool animating = ledController.update();

            // Debug: log buffer status periodically (suppressed when Serial Studio active)
            static unsigned long lastPlayDebug = 0;
            if (!serialStudioEnabled && millis() - lastPlayDebug > 2000)
            {
                lastPlayDebug = millis();
                bool detectorReady = useMLDetection ? mlDetector.isReady() : directionDetector.isReady();
                Serial.printf("[PLAY] Buffer: %d samples, Detector(%s): %s\n",
                              sessionManager.getDataCount(),
                              useMLDetection ? "ML" : "heuristic",
                              detectorReady ? "READY" : "establishing baseline...");
            }

            // Check cooldown between detections
            unsigned long now = millis();
            bool inCooldown = (lastDetectionTime > 0) && (now - lastDetectionTime < DETECTION_COOLDOWN);

            if (!inCooldown)
            {
                // Feed new readings to the detector
                auto &buffer = sessionManager.getDataBuffer();
                static size_t lastProcessedIndex = 0;

                // Add new readings since last check
                size_t bufferSize = buffer.size();
                for (size_t i = lastProcessedIndex; i < bufferSize; i++)
                {
                    if (useMLDetection)
                        mlDetector.addReading(buffer[i]);
                    else
                        directionDetector.addReading(buffer[i]);
                }
                // Flush the last reading to ensure it's processed
                if (useMLDetection)
                    mlDetector.flushReading();
                else
                    directionDetector.flushReading();
                lastProcessedIndex = bufferSize;

                // Check for detection
                bool detected = useMLDetection ? mlDetector.hasDetection() : directionDetector.hasDetection();
                if (detected)
                {
                    DetectionResult result = useMLDetection ? mlDetector.getResult() : directionDetector.getResult();
                    serialStudioOutput.cacheDetection(result);

                    // Detection successful!
                    if (!serialStudioEnabled)
                        Serial.printf("DETECTION [%s]: %s (confidence: %.2f)\n",
                                      useMLDetection ? "ML" : "heuristic",
                                      DirectionDetector::directionToString(result.direction),
                                      result.confidence);

                    // Show on LEDs
                    ledController.showDirection(result.direction, 3000);
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

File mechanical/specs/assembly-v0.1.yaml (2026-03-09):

# Soccer Hoop Sensor Assembly — Design Spec v0.1

# ──────────────────────────────────────────────
# PURPOSE
# ──────────────────────────────────────────────
# The current prototype enclosures are fragile, hard to install,
# and offer no impact protection. This blocks a key milestone:
# taking Motion Play outside the workshop for portable, battery-powered
# playtesting where balls will be kicked at the hoop at up to 20 mph.
#
# This spec captures the physical constraints and requirements so we
# can design 3D-printable enclosures that:
#   1. Protect all electronics (rigid PCB, flex PCB, bend zone) from ball impact
#   2. Are easy to install and remove for development iteration
#   3. Make the system portable — survivable in a bag or car
#   4. Can be iterated toward production-quality enclosures over time
#
# See .context/PROJECT.md "Vision & Goals" for broader project direction.

# ──────────────────────────────────────────────
# PHYSICAL DIMENSIONS (measured / confirmed)
# ──────────────────────────────────────────────

hoop:
  inner_diameter_mm: 505
  inner_radius_mm: 252.5
  bar_width_mm: 25.25       # the "flat" face — what PCBs sit on
  bar_thickness_mm: 4.0     # the "thin" edge — what the flex PCB wraps around
  material: steel_flat_bar
  bar_count: 1              # closed ring

sensor_pcb:  # "rigid" PCB, sits on outer face of hoop
  width_mm: 28.5            # E–W axis (runs along hoop circumference)
  height_mm: 22.6           # N–S axis (runs across hoop bar width)
  thickness_mm: 1.6         # FR4 board only, no components on underside
  tallest_component: JST-SH # right-angle female connector
  tallest_component_height_mm: 3.0  # above PCB surface
  total_pcb_height_mm: 4.6  # board (1.6) + tallest component (3.0)
  connectors:
    - type: JST-SH
      pin_count: 5
      style: right-angle female
      edge: south
      height_mm: 3.0        # above PCB surface
      notes: "wire exits toward hoop circumference; needs to be pluggable post-install"
    - type: FPC
      edge: west
      notes: "flex strip exits here, wraps 180° around the 4mm thin edge to the inside"

flex_pcb:
  length_mm: 56
  width_mm: 10
  thickness_mm: 0.08        # effectively negligible
  wrap_peak_from_edge_mm: 10 # how far the flex bows out at the apex of the 180° bend
  connector_insertion_depth_mm: 3   # how far it inserts into rigid PCB FPC connector
  inside_seating_length_mm: ~22     # estimated (56 - 3 insertion - ~31 for 180° arc)
  sensors_on: inside_face    # optical sensors face into hoop interior
  sensor_height_mm: 1.4      # VCNL4040 — tallest component on flex strip
  attachment_inside: double_sided_tape
  bend_geometry:
    exit_angle: parallel     # exits FPC connector parallel to rigid PCB plane
    straight_run_mm: 1-2     # parallel run before curve begins
    bend_arc_diameter_mm: 14-15  # if the 180° bend described a full circle
    bend_arc_radius_mm: 7-7.5
    after_bend: "lies flat on interior piece, stuck with double-sided tape"

sensor_pcb_underside:
  components: none           # bare — no components protrude from hoop-facing surface
  orientation: "component-side-up (away from hoop), bare side faces enclosure base"

cable_routing:
  jst_sh_cable:
    path: "runs along hoop to main PCB enclosure"
    destination: "main PCB enclosure (MCU, screen, power — separate design concern)"

# ──────────────────────────────────────────────
# CURRENT PROTOTYPE (what exists today)
# ──────────────────────────────────────────────
# This section describes the existing 3D-printed prototype.
# The piece count, shape, and fastening method are NOT constraints
# for the next design — they are just what was built first.
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

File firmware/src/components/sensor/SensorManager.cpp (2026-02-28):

#include "SensorManager.h"
#include "../session/SessionManager.h" // For SessionSummary full definition

extern bool serialStudioEnabled;

SensorManager::SensorManager() : mux(0x70)
{
    // Constructor
}

void SensorManager::cleanupI2CBus()
{
    // Disable all multiplexer channels to release the I2C bus
    // IMPORTANT: Must select each TCA channel before disabling its PCA!
    for (int i = 0; i < 3; i++)
    {
        mux.selectChannel(i);
        delay(2);
        pca_instances[i].disableAllChannels();
    }
    mux.disableAllChannels();

    // Small delay to ensure bus is stable
    delayMicroseconds(100);
}

// ============================================================================
// PS_CANC Baseline Calibration
// The VCNL4040 has a built-in cancellation register (PS_CANC at 0x05) that
// automatically subtracts an offset from all proximity readings. This is
// designed to compensate for cover window reflections and other constant
// sources of IR reflection that would otherwise cause elevated baselines.
//
// See: Vishay Application Note "Designing the VCNL4040 Into an Application"
// and SENSOR_SPACING_AND_COVERS.md in docs/references/vcnl4040/
// ============================================================================

bool SensorManager::calibrateSensorBaseline(uint8_t sensorIndex)
{
    if (sensorIndex >= NUM_SENSORS || !sensorsActive[sensorIndex])
        return false;

    uint8_t tca_ch = sensorMapping[sensorIndex].tca_channel;
    uint8_t pca_ch = sensorMapping[sensorIndex].pca_channel;

    // Select TCA channel for this sensor board
    if (!mux.selectChannel(tca_ch))
    {
        Serial.printf("  Calibration: Failed to select TCA channel %d\n", tca_ch);
        return false;
    }
    delay(5);

    // Select PCA channel on the sensor board
    if (!pca_instances[tca_ch].selectChannel(pca_ch))
    {
        Serial.printf("  Calibration: Failed to select PCA channel %d\n", pca_ch);
        return false;
    }
    delay(5);

    // Take multiple readings to calculate average baseline
    const int NUM_SAMPLES = 50;
    const int SAMPLE_DELAY_MS = 10; // 10ms between samples
    uint32_t sum = 0;
    int validSamples = 0;

    for (int i = 0; i < NUM_SAMPLES; i++)
    {
        // Read proximity directly via I2C
        Wire.beginTransmission(0x60);
        Wire.write(0x08); // PS_DATA register
        if (Wire.endTransmission(false) != 0)
            continue;

        Wire.requestFrom((uint8_t)0x60, (uint8_t)2);
        if (Wire.available() >= 2)
        {
            uint8_t prox_low = Wire.read();
            uint8_t prox_high = Wire.read();
            uint16_t proximity = (prox_high << 8) | prox_low;
            sum += proximity;
            validSamples++;
        }
        delay(SAMPLE_DELAY_MS);
    }

    if (validSamples < NUM_SAMPLES / 2)
    {
        Serial.printf("  Calibration: Too few valid samples (%d/%d)\n", validSamples, NUM_SAMPLES);
        return false;
    }

    // Calculate average baseline
    uint16_t baseline = sum / validSamples;
    baselineValues[sensorIndex] = baseline;

    // Write to PS_CANC register (0x05) - this value is subtracted from all readings
    Wire.beginTransmission(0x60);
    Wire.write(0x05);                   // PS_CANC register
    Wire.write(baseline & 0xFF);        // Low byte
    Wire.write((baseline >> 8) & 0xFF); // High byte
    uint8_t err = Wire.endTransmission();

    if (err != 0)
    {
        Serial.printf("  Calibration: Failed to write PS_CANC (I2C error %d)\n", err);
        return false;
    }

    // Verify by reading back
    delay(5);
    Wire.beginTransmission(0x60);
    Wire.write(0x05);
    Wire.endTransmission(false);
    Wire.requestFrom((uint8_t)0x60, (uint8_t)2);
    uint8_t verify_low = Wire.available() ? Wire.read() : 0xFF;
    uint8_t verify_high = Wire.available() ? Wire.read() : 0xFF;
    uint16_t verify_value = (verify_high << 8) | verify_low;

    if (verify_value != baseline)
    {
        Serial.printf("  Calibration: PS_CANC verify failed (wrote %d, read %d)\n", baseline, verify_value);
        return false;
    }

    return true;
}

bool SensorManager::calibrateProximityCancellation()
{
    Serial.println("\n");
    Serial.println("╔══════════════════════════════════════════════════════════════════════════════╗");
    Serial.println("║              PS_CANC BASELINE CALIBRATION (Cover Offset Removal)             ║");
    Serial.println("╠══════════════════════════════════════════════════════════════════════════════╣");
    Serial.println("║ This calibrates each sensor to cancel the constant offset caused by the      ║");
    Serial.println("║ acrylic cover windows. Ensure NO objects are near the sensors during this!   ║");
    Serial.println("╠══════════════════════════════════════════════════════════════════════════════╣");

    int calibratedCount = 0;
    int failedCount = 0;

    for (int i = 0; i < NUM_SENSORS; i++)
    {
        if (!sensorsActive[i])
        {
            Serial.printf("║ Sensor %d (P%dS%d): SKIPPED (not active)                                       ║\n",
                          i, sensorMapping[i].tca_channel + 1, sensorMapping[i].pca_channel + 1);
            continue;
        }

        char sensorName[8];
        snprintf(sensorName, sizeof(sensorName), "P%dS%d",
                 sensorMapping[i].tca_channel + 1, sensorMapping[i].pca_channel + 1);

        Serial.printf("║ Sensor %d (%-4s): Calibrating...                                              ║\n", i, sensorName);

        if (calibrateSensorBaseline(i))
        {
            Serial.printf("║ Sensor %d (%-4s): ✓ Baseline = %5d (written to PS_CANC)                     ║\n",
                          i, sensorName, baselineValues[i]);
            calibratedCount++;
        }
        else
        {
            Serial.printf("║ Sensor %d (%-4s): ✗ CALIBRATION FAILED                                        ║\n",
                          i, sensorName);
            failedCount++;
        }

        // Feed watchdog between sensors
        taskYIELD();
    }

    // Clean up multiplexer channels
    for (int i = 0; i < 3; i++)
    {
        mux.selectChannel(i);
        delay(2);
        pca_instances[i].disableAllChannels();
    }
    mux.disableAllChannels();
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

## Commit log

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2025-10-06 Finished sensor redesign
    [PCA9546APWR.step, bom.csv, designators.csv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]
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2025-12-08 Dynamic floor to algo, and LED strip bug fixed
    [DirectionDetector.cpp, LEDController.cpp, SensorManager.cpp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]
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2025-12-11 Created two new Kicad projects for sensors, splitting into rigid and flex parts
    [sensor-flex.kicad_pcb, sensor-flex.kicad_sch, sensor-rigid.kicad_pcb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]
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2025-12-15 Interrupts and new flex design
    [bom.csv, designators.csv, positions.csv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]
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2026-01-02 Fixed calibration button on the frontend, now it shows
    [sensor-rigid.kicad_pcb]
2026-02-20 Fix TFT_eSPI display config and add Serial Studio docs
    TFT_eSPI v2.5.43 stopped picking up the project's custom User_Setup.h,
    falling back to the default ILI9341 SPI driver instead of ST7789 parallel
    8-bit — causing a persistent black screen. Force the correct config via
    build flags (-DUSER_SETUP_LOADED, -include). Also disable TOUCH_CS which
    is incompatible with parallel mode in newer TFT_eSPI versions.
    Adds Serial Studio usage guide to PROJECT.md and updates the outdated
    dependencies list.
    [User_Setup.h]
2026-02-22 Fix Serial Studio frame corruption caused by USB CDC packetization
    Root cause: ESP32-S3 HWCDC packetizes serial data into USB transfers.
    Serial Studio's /*...*/ start+end delimiter parser misaligned when
    frame boundaries fell mid-chunk, merging ~10-12% of frames.
    Additional bug: snprintf char buf[64] was too small for 21-field
    telemetry frames (~76+ chars), silently dropping all telemetry output.
    Fix:
    - Switch to newline-only frame detection (frameDetection: 0) with JS
    parser that validates /*...*/ markers — robust against USB chunking
    - Revert to Serial.printf() (no buffer size limit)
    - Restore full timestamp (μs) and float precision (%.1f)
    - Remove 50 FPS output throttle (no longer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
    [DirectionDetector.cpp, LEDController.cpp, SensorManager.cpp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]
2026-02-23 Add dual rate display, transit speed estimation, and sensor docs
    Replace the flawed single "effective rate" metric with two accurate
    rate displays: a calculated Sensor Rate (from IT × duty cycle) and a
    measured Poll Rate (I2C throughput). Add transit speed estimation
    derived from wave duration and configurable ball diameter. Include
    comprehensive VCNL4040 documentation: sensor reading pipeline timing
    analysis, rewritten configuration guide with confidence levels, and
    transit calculator tool.
    [DirectionDetector.cpp, SensorConfiguration.h, SerialStudioOutput.cpp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]
2026-02-24 Rewrite detection algorithm with per-sensor adaptive thresholds
    Replace side-level signal aggregation with independent per-sensor
    tracking. Each of the 6 sensors now maintains its own rolling baseline
    (updated only during IDLE to exclude transit waves), adaptive threshold,
    and wave state machine. Detection works in three layers: per-sensor wave
    tracking, per-module pairing, and multi-module consensus for confidence.
    This fixes the A/B naming swap (side 2 was incorrectly mapped to side A)
    and makes the system robust to individual noisy sensors like P3S1, since
    each sensor's threshold adapts independently.
    Also adds v9/v10 Serial Studio dashboards with per-sensor threshold
    overlays on module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
    [DirectionDetector.cpp, SerialStudioOutput.cpp, SerialStudioOutput.h]
2026-02-24 Fix Direction::UNKNOWN handling and add runtime detection config
    UNKNOWN detections were silently treated as B_TO_A throughout the
    codebase due to if/else instead of three-way checks. Now properly
    handled: red LED flash, "Unknown" on display, "unknown" direction
    label in live_debug captures, and correct MQTT status publishing.
    Detection algorithm parameters (peakMultiplier, minRise,
    minWaveDurationMs, smoothingWindow) are now configurable at runtime
    via cloud config (MQTT), following the existing sensor config pattern.
    Values display on the T-Display config panel.
    [DisplayManager.cpp, DisplayManager.h, LEDController.cpp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]
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2026-02-24 Condense session detail UI and fix multi_pulse config bug
    Reorganize the session detail page to reduce scrolling:
    - Remove frontend direction detection panel (stale algorithm)
    - Collapse Data Processing and Sensor Statistics by default
    - Condense stats + chart legend into a single compact line
    - Compact session header with export button opening a modal
    - Condense SessionConfig from colored boxes to inline summary
    - Show auto-detected label inline, collapse editing by default
    - Move labels near chart for better context
    Fix firmware not sending duty_cycle and multi_pulse in
    vcnl4040_config payload, causing frontend to show wrong values.
    Add 'unknown' to detection_direction type for Task 1 sup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
    [DataTransmitter.cpp]
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2026-03-01 Add pipeline latency reduction initiative from exploration analysis
    Decide on the pipeline-latency exploration: binary payload packing +
    quick wins (faster polling, smart settle) to reduce live debug
    end-to-end latency from ~20s to ~5s. Corrects reading count estimate
    (4,500 with 6 sensors, not 1,500) and creates initiative with BRIEF,
    PLAN, and TASKS.
    Made-with: Cursor
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2026-03-01 Fix binary publish: use streaming API instead of large buffer
    PubSubClient's setBufferSize(61440) was failing silently — malloc
    couldn't allocate 61KB contiguously, leaving the MQTT client with a
    NULL buffer and breaking all publishes.
    Fix: keep the 32KB buffer for normal JSON batches and add a streaming
    publish path (beginPublish/serializeJson/endPublish) for the binary
    captures. The streaming API writes directly to the TLS socket in
    chunks, bypassing the internal buffer entirely.
    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
    [DataTransmitter.cpp, MQTTManager.cpp]
2026-03-01 Fix streaming publish: serialize to PSRAM, send in 4KB chunks
    The previous approach let ArduinoJson write the ~54KB base64 string
    directly to the TLS socket in one write() call, which hung on ESP32.
    Now the JSON is serialized into a ps_malloc'd PSRAM buffer first,
    then sent through the streaming API in 4KB chunks that the WiFi/TLS
    stack can handle reliably.
    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
    [MQTTManager.cpp]
2026-03-02 Add mechanical design folder with sensor assembly spec
    Introduces mechanical/ as a new top-level project facet alongside
    hardware/ (electronics) for physical enclosures and mounting parts.
    Includes detailed assembly spec (v0.1) documenting hoop dimensions,
    PCB geometry, current prototype problems, and design requirements
    for the next iteration.
    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
    [assembly-v0.1.yaml, manifest.yaml]
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2026-03-04 Fix inner shell alignment and add viewer launch script
    - Mirror flex channel to Y=-6.75 to align with outer shell FPC position
    - Fix V-ridge construction (was invisible due to Plane.XZ offset bug)
    - Extend sensor well to X=+13 so flex PCB can insert fully
    - Preserve base plate under sensor well for solid ridge attachment
    - Add mechanical/view.sh for interactive model viewing in OCP CAD Viewer
    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
2026-03-04 Add wrap-around tray concept and update mechanical README
    Outer shell redesigned as a C-shaped tray that wraps around the bar's
    thin edges, integrating the bend channel and M2 screw boss mounting
    points. Inner shell updated with wider base plate to fit inside the
    tray opening and M2 clearance holes for assembly. Assembly viewer
    script added for evaluating the concept in OCP CAD Viewer.
    Mechanical README updated to reflect active enclosure work, tooling
    setup, and option-based folder organization.
    This is a concept model for visual evaluation — not yet refined for
    printing. The flat-shell baseline remains on main.
    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
2026-03-05 Upgrade option-a enclosure fasteners and fix assembly collisions
    Enclosure changes based on test-print findings:
    - Upgrade M2 to 3× M2.5 in triangular pattern (anti-rotation)
    - Offset -X boss to clear FPC passthrough channel
    - Add reinforcement pads at inner shell screw positions (solid stock
    instead of tapered ramp material)
    - Add end walls on -Y/+Y faces with bar notches to close flex channel
    - Terminate bosses and end walls at bar inner face to avoid collision
    with inner shell base plate
    - Add bar clearance subtraction to D-trim bosses (0.3mm gap to bar edge)
    - Size screw pads to stay within inner shell footprint
    - Increase V-ridge angle from 3° to 5° for printability (0.65mm to 1.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
2026-03-05 Add bend guard and screw-fastened lid to option-a outer tray
    Thicken the -X wrap wall (+3mm) to fully enclose the flex PCB's 180°
    bend zone from impact. Add a cavity-sized lid (29×31mm) secured by two
    diagonal M2 heat-set insert screws on the X wall tops, replacing the
    original full-coverage slab. Update assembly view with lid positioning.
    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
2026-03-06 Audit sensor pipeline for firmware refactor initiative (Batch 2)
    Analyze SensorManager, MuxController, VCNL4040 driver, and
    SensorConfiguration from senior C/C++ engineer perspective. Key finding:
    two parallel implementations of mux layer and VCNL4040 driver exist —
    SensorManager uses legacy raw I2C while InterruptManager uses the newer
    clean abstractions. Document concurrency hazards on Core 0 hot path,
    silent I2C error handling, dead Adafruit dependency, and decomposition
    recommendations prioritized by impact.
    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
2026-03-06 Audit detection & ML layer for firmware refactor initiative (Batch 3)
    Analyze DirectionDetector, MLDetector, CalibrationManager, and
    CalibrationData from a senior C/C++ engineering perspective. Document
    findings covering: missing shared detector interface, StatsAccumulator
    integer overflow bug, blocking delay() calls in CalibrationManager,
    signal processing concerns, and decomposition recommendations.
    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
2026-03-09 Add schematic context system initiative and exploration doc
    Exploration doc captures the original proposal for AI-assisted KiCad
    schematic annotation. Initiative docs (BRIEF/PLAN/TASKS) define the
    approach validated by spike testing: kicad-cli for netlist connectivity
    + kiutils for property read/write, producing an AI-optimized
    circuit-context.json per PCB project. Replaces the existing netlist
    JSON + YAML annotation system that never gained adoption.
    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
2026-03-09 Complete Phase 1b: kiutils integration, sheet interfaces, and merge logic
    - Add kiutils integration to read ai_ properties from .kicad_sch files
    (root + children discovered via sch.sheets)
    - Build sheet_interfaces section from hierarchical sheet pins with
    net resolution heuristics (16/16 pins resolved for main PCB)
    - Add --previous merge to carry forward net annotations, block
    definitions, and description across re-extractions
    - Updated circuit-context.json now includes sheet_interfaces for both
    LED Controller (5 pins) and TCA9548A Subsystem (11 pins)
    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
2026-03-10 Complete Phase 4: documentation and cleanup — schematic context initiative done
    Replace annotated netlist spec in hardware/CONTEXT.md with circuit-context.json
    guidance, add tools/schematic-context/README.md, deprecate old netlist files,
    and update PROJECT.md to reference the new system.
    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
2026-03-10 Generate circuit-context.json for sensor-rigid and sensor-flex PCBs
    Run the existing schematic context extraction and annotation tooling on
    both sensor board schematics. Sensor-rigid: 27 components, 16 nets,
    6 functional blocks (i2c_mux, connectors, i2c_pull_ups, interrupts,
    power, test_points). Sensor-flex: 9 components, 12 nets, 4 blocks
    (sensor_1, sensor_2, power, connector). All ai_ properties written to
    .kicad_sch files for persistence. Initiative docs and status updates
    included.
    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
    [sensor-flex.kicad_sch, sensor-rigid.kicad_sch]
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2026-03-10 Archive unused PCB folders
    Move pcb-sensor and sensor-alt-pt into hardware/archive/.
    These were superseded by sensor-rigid and sensor-flex.
    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
    [bom.csv, designators.csv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]
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2026-03-11 Generate power management schematic and install component libraries (Phase 3.3-3.5)
    - Install TPS61088 and INA219 symbols/footprints via easyeda2kicad
    - Install footprints for BQ24195, USB-C, FXL0630, FNR6028
    - Register custom libraries in sym-lib-table and fp-lib-table
    - Resolve 7 TBD LCSC part numbers for passive components
    - Build generate_power_sheet.py: reads spec.json, places 51 components
    with wire stubs, net labels, no-connect flags, and hierarchical labels
    - Generate power_management.kicad_sch (passes kicad-cli ERC, 0 shorts)
    - Fix lib_id mismatch for easyeda2kicad symbols (was crashing KiCad 9)
    - Fix wire stub direction (away from body) and component spacing
    - Hide ai_* annotatio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
    [motion-play-main.kicad_sch, power_management.kicad_sch]
2026-03-11 Integrate power management sub-sheet into root schematic (Phase 3.6)
    - Delete J2 (DWEII USB-C module) and D1 (Schottky) from root sheet
    - Add hierarchical sheet reference to power_management.kicad_sch
    - Wire 6 sheet pins: +5V, GND, +3.3V, I2C_SDA, I2C_SCL, CHRG_INT
    - Connect CHRG_INT to GPIO 21 (U2 pin 19)
    - Hide non-essential property labels (Description, Datasheet, etc.)
    across all original schematic sheets — only Reference and Value visible
    - ERC: 0 errors on root/LED/TCA9548A sheets, 4 expected power_pin
    warnings on power management sheet (net labels vs PWR_FLAG)
    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
    [3v3_Power_Supply.kicad_sch, led_controller.kicad_sch, motion-play-main.kicad_sch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]
2026-03-11 Fix ERC power_pin_not_driven errors with PWR_FLAG symbols (Phase 3.7)
    Add 4 PWR_FLAG symbols (#FLG05-08) to resolve power_pin_not_driven ERC
    errors on VBUS_RAW, Protected_VBUS, VBAT, and VSYS nets. Fix instance
    path format to use /{root_uuid}/{sheet_ref_uuid} matching KiCad 9's
    hierarchical sheet convention. ERC now reports 0 errors, 31 warnings
    (all cosmetic pin_to_pin type mismatches from easyeda2kicad symbols).
    Also checks off Phase 3 tasks 3.3-3.7 in TASKS.md with completion notes.
    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
    [power_management.kicad_sch]
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2026-03-13 Phase 3 validation: run placement pipeline, fix kiutils KiCad 9 writer, verify distances
    - Run full extract→place pipeline: 46 components placed (0 failures, 4 relaxed)
    - Fix place_power.py writer: replace kiutils Board.to_file (converts uuid→tstamp,
    breaks KiCad 9 format) with text-based regex replacement that preserves formatting
    - Validate critical distances: L2 edge↔U6 SW 0.8mm, C32↔U6 BOOT 2.5mm,
    C34-C36↔U6 +5V 2.5-3.5mm. C23↔U5 BTST 4.5mm (relaxed, L1 blocks ideal spot)
    - PCB updated with all 86 footprints (49 power components from schematic import)
    - Update initiative docs: integrated-power and pcb-auto-placement TASKS/PLAN
    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
    [motion-play-main.kicad_pcb]
2026-03-13 Phase 3 complete: shift L1 up 2mm, re-place C23 to 3mm from BTST, run DRC
    L1 moved from y=116.35 to y=114.35, opening a 2.1mm gap between L1 and U5.
    C23 BTST bridging cap improved from 4.5mm (relaxed) to 3.0mm (within Tier 1).
    Relaxation count reduced from 4 to 2 (only L2 and C41 remain relaxed).
    DRC: 84 violations total — 56 from J7/U6 footprint imports (pre-existing),
    17 silkscreen overlaps (cosmetic), 9 dangling tracks (pre-existing),
    2 R42 edge clearance (only placement-caused issue). 137 unconnected items
    expected pre-routing. No component overlap violations.
    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
    [motion-play-main.kicad_pcb]
2026-03-16 Fix L2 bbox, re-place power components, complete full board routing
    - Fix extract.py inductor bbox heuristic: parse L{X}-W{Y} from footprint
    name when pad-based bbox height < width/2 (L2: 8.4×3.2 → 8.4×6.6mm)
    - Add L2 to placement anchors, re-run placement pushing C32/R41/R42/R43/TP4
    out of L2's physical footprint
    - Fix J7 USB-C schematic pin-to-footprint mapping (A4→A4B9, etc.)
    - Complete all trace routing: power switching loops (BOOST_SW pour, BQ_SW),
    VSYS/VBAT/Protected_VBUS power paths, INA219 Kelvin sense, +5V distribution
    via In2.Cu zone, I2C bus, all U5/U6 support passives
    - Board setup: net classes, design rules, zone fills
    - DRC: 0 unconnected pads, remaining violation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
    [motion-play-main.kicad_pcb, motion-play-main.kicad_sch, power_management.kicad_sch]
2026-03-16 Add routing verification tool and complete board routing
    Build verify-routing.py that programmatically checks the routed PCB against
    ROUTING_GUIDE.md specs using kiutils. Runs 20 checks across 7 categories:
    trace widths, zone existence, critical path connectivity, I2C length matching,
    I2C isolation from switching nodes, INA219 Kelvin sense paths, and FB/COMP
    routing side verification. Produces Markdown + JSON reports.
    Initial run: 16 PASS, 4 FAIL (trace widths on 15 Default-class segments,
    missing B.Cu GND zone, I2C main trunk 11mm length mismatch, missing VSYS
    Kelvin sense path from R44.1→U7.1).
    Also includes: regenerated pcb-layout-context.json with pad data, ERC/DRC
    reports, routing-v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
    [motion-play-main.kicad_pcb]
2026-03-16 Fix routing verification, add B.Cu GND zone, install power switch footprint
    Verification script improvements:
    - Fix Kelvin sense check to use threshold (< half power width) instead of
    exact 0.25mm match, correctly identifying 0.30mm dedicated sense traces
    - Fix connectivity graph to use distance-based merging instead of grid
    quantization, resolving false disconnection on Protected_VBUS path
    - Downgrade minor trace width deviations (<=0.1mm) to warnings
    - Exempt GND from trace width checks (uses planes, widths vary by design)
    Board updates:
    - Add B.Cu GND zone (bottom ground fill)
    - Tweak BOOST_FSW/VCC/SS/CC2 trace widths, I2C trunk length balancing
    Verification now passes: 19 PASS, 0 F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
    [motion-play-main.kicad_pcb]
2026-03-16 JLCPCB pre-flight review: fix 3 LCSC part numbers, add fabrication files
    Pre-flight review for JLCPCB fabrication + SMT assembly submission.
    LCSC part fixes (data-only, no schematic/PCB design changes):
    - J4/J5/J6: C160403 (3-pin JST-SH) → C136657 (5-pin SM05B-SRSS-TB)
    - R27: C500724 (0.1Ω 2W, out of stock) → C2903476 (0.1Ω 3W, 94k stock)
    - Q2: C3040193 (VBZ3401, 3 units) → C15127 (AO3401A, 1.45M stock, Basic)
    Adds fabrication exports (Fabrication Toolkit plugin):
    - BOM, CPL/positions, designators, netlist
    - DRC and ERC reports
    - Pre-flight review report (preflight-review.md)
    Remaining advisory: BQ24195RGER (C90862) has only 22 units — order soon.
    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
    [bom.csv, designators.csv, led_controller.kicad_sch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]
2026-03-16 Update LCSC part numbers for JLCPCB assembly and finalize manufacturing files
    Resolve JLCPCB assembly stock issues by substituting unavailable parts:
    - C2836440 → C7469958 (47µF FOSAN, D6.3×5.4mm, Economic PCBA compatible)
    - C59461 → C109314 (22µF YAGEO 0805, fixes package mismatch)
    - C14663 restored (100nF, restocked in JLCPCB assembly)
    - J4-J6, Q2, R27 LCSC corrections from prior commit synced to PCB
    Re-extracted circuit-context.json and pcb-layout-context.json.
    Added cursor rule documenting hardware file conventions.
    Cleaned up stale KiCad backup files.
    Order placed on JLCPCB 2026-03-16.
    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
    [3v3_Power_Supply.kicad_sch, bom.csv, motion-play-main.kicad_pcb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]
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2026-03-18 Add door-latch-spring experiment and restructure mechanical/ folder
    Iterative 3D-printable replacement spring for a broken mortise latch
    mechanism. Six design versions exploring sleeve fit, flex bars, and
    spiral spring approaches (V1 serpentine → V6 spiral with under-arm
    routing). Work in progress — current best candidate is V6.
    Also restructures mechanical/ folder: models now live under
    mechanical/models/ (enclosures moved there, plus new project folders).
    Updated view.sh with recursive project discovery and OCP CAD Viewer
    auto-start. Updated docs and gitignore to match.
    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
    [manifest.yaml, v5_spiral_spring.py]
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2026-03-18 Generate ESP32-S3 schematic sheet and apply integration modifications
    Phase 1c: created esp32_spec.json and generate_esp32_sheet.py to produce
    esp32_s3.kicad_sch with WROOM-1 module, EN/boot circuits, USB series
    resistors, decoupling caps, and status LED. All components annotated via
    centralized annotate.py.
    Phase 1d partial: esp32_integration.py placed AMS1117, USBLC6, power
    switch, USB hierarchical labels on power_management sheet; added ESP32
    sheet reference and removed U2/U1/unused test points from root sheet.
    Fixed modify.py annotate.py path resolution bug. Fixed generator UUID
    mismatch that caused kiutils to reset reference designators to '?'.
    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
    [esp32_s3.kicad_sch, led_controller.kicad_sch, motion-play-main.kicad_sch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]
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2026-03-18 Fix Phase 1d schematic issues: SW1, USB pins, +5V, +3.3V direction
    - Fix SW1 power switch: pin 3 was wired to VSYS (same as pin 1),
    making the switch always-on. Changed to no-connect so the SPDT
    switch can actually disconnect VSYS from the boost input.
    - Add USB_DP/USB_DN sheet pins to power_management reference on root
    so USB data signals can flow between power and root sheets.
    - Add +5V hierarchical label to ESP32_S3 sheet and matching sheet pin
    on root, connecting status LED D5 to the global +5V rail.
    - Change +3.3V hlabel/pin direction from input to output on power
    management sheet since AMS1117 now produces +3.3V there.
    - Add reusable helpers to modify.py: find_sheet_ref, add_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
    [esp32_s3.kicad_sch, led_controller.kicad_sch, motion-play-main.kicad_sch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]
2026-03-18 Complete Phase 1d/1e: manual wiring, ERC clean (0 errors)
    Root sheet:
    - Wire ESP32_S3 sheet pins to system nets via labels (I2C_SDA,
    I2C_SCL, TCA_RESET, LED_DATA, CHRG_INT, USB_DP, USB_DN)
    - Connect power pins with +3.3V, +5V, GND power symbols
    - Add PWR_FLAG symbols to resolve power-not-driven ERC errors
    - NC flags on INT1/2/3 (design decision to drop interrupt lines)
    - Remove TPIO11/12/13 (INT test points, no longer needed)
    - Clean up dangling wires from old U2/U1 area
    - Remove stray I2C_SCL hierarchical label
    Power management sheet:
    - Wire J7 D+/D- pads (A6/B6 tied to USB_DP, A7/B7 tied to USB_DN)
    - Insert VSYS_SW into power path: R44 and INA219 IN+ now on
    VSYS_SW net so SW1 actually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
    [esp32_s3.kicad_sch, led_controller.kicad_sch, motion-play-main.kicad_sch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]
2026-03-20 Phase 2 PCB layout: component placement, footprint libs, routing/placement guides
    All 20 new ESP32 integration components placed on the board. Added
    missing JLC-MCP footprints to project library. Created placement and
    routing guide documents. Configured USB net class (0.1mm clearance),
    antenna keepout zone, and U8 thermal copper pour.
    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
    [motion-play-main.kicad_pcb]
2026-03-26 Hardware revision: remove interrupts, update connectors, add DIP switch
    Remove INT lines from all three PCBs (main, rigid, flex). Replace 5-pin
    JST-SH connectors with 4-pin SM04B-SRSS-TB on main and rigid boards.
    Replace solder jumpers with EP-02KS DIP switch for I2C address config
    on rigid board. Update FPC connector pinout to remove INT signals and
    add GND fills. Update stiffener specs (PI 0.25mm tail, SS 0.2mm IC
    areas). Regenerate production files (BOM, CPL) for both sensor boards.
    Update hardware CONTEXT.md with corrected addresses (0x74-0x76),
    component tables, and pinouts.
    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
    [bom.csv, designators.csv, motion-play-main.kicad_pcb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]
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2026-04-03 Fixed polarity protection on the power circuit
    [motion-play-main.kicad_pcb, pb_back_router_template.dxf, pb_back_router_template_clean.dxf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]
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
